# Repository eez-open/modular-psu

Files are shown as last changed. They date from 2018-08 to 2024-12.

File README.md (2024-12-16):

  

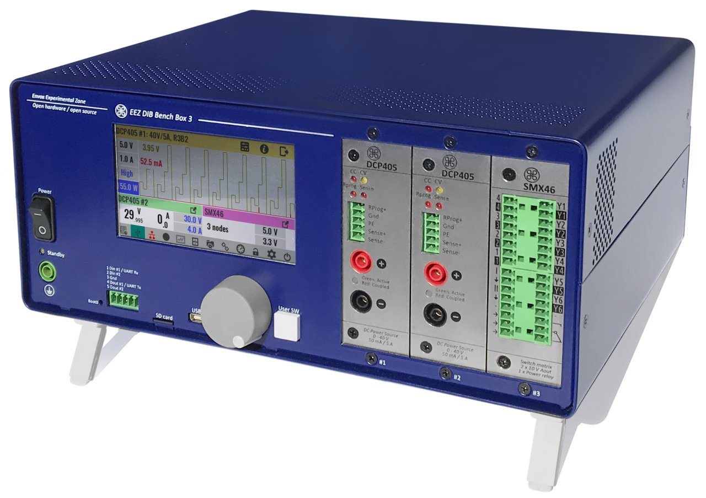
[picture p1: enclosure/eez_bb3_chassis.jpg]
Enclosure 3D model


### Ownership and License
The contributors are listed in CONTRIB.TXT. 

Licenses | OSHWA UID
--|--
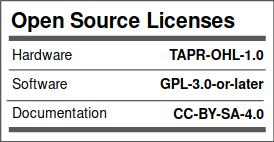
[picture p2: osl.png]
osl
 | OSHW-HR000002 (https://certification.oshwa.org/hr000002.html)

### Introduction

EEZ Bench Box 3 (BB3) represents a new category of *modular* Test and Measurement (T&M) equipment. It provides a complete open-source hardware and software framework that bridges the gap between – and combines the best features of – DIY hobbyist tools and professional benchtop equipment. 
BB3 was inspired by the [EEZ H24005](https://github.com/eez-open/psu-hw) power supply project ([OSHWA UID HR000001](https://certification.oshwa.org/hr000001.html)), which attracted many enthusiasts with its broad feature-set, rich user interface, DIY-friendliness, and fully open-source design. 
It initially comes with two DC power modules (hence the name of repository *modular-psu*) and will be expanded with new T&M modules (e.g. multi-channel power source, 2/4-quadrant power module, multi-channel temperature sensor module, data logger, switch matrix, digital I/O expander, function generator, data acquisition module, etc.). 
BB3 is made up of the following components:

* _[BP3C](https://github.com/eez-open/modular-psu/tree/master/bp3c)_ EEZ DIB backplane with power output coupling capability of first two modules
* _[AUX power supply](https://github.com/eez-open/modular-psu/tree/master/aux-ps)_ board with AC input protection, soft-start/power-up control, DC fan controller and +5 V / +12 V power outputs
* _[MCU](https://github.com/eez-open/modular-psu/tree/master/mcu)_ board based on STM32F769IIT6 32-bit ARM Cortex-M7
* _[DCP405](https://github.com/eez-open/modular-psu/tree/master/dcp405)_, 0 - 40 V / 50 mA / 5 A DC power source module
* _[DCM224](https://github.com/eez-open/dib-dcm224)_, dual sync buck 1 - 24 V / max. 4.9 A module (**retired**)
* _[Metal enclosure](https://github.com/eez-open/modular-psu/tree/master/enclosure)_ for housing up to 3 modules with 4.3" TFT LCD. Dimensions: 290 (W) x 123 (H) x 240 (D) mm

### Supported technologies

* _EEZ Flow_ (Visual programming tool for test and measurement automation)
* SCPI (Reference Guide in [PDF](https://github.com/eez-open/modular-psu-firmware/blob/master/docs/SCPI%20reference%20guide/EEZ%20BB3%20SCPI%20reference%20guide.pdf))
* MicroPython (script [examples](https://github.com/eez-open/modular-psu-firmware/tree/master/scripts), an example [video](https://www.youtube.com/watch?v=I0y6fgv8G00))
* MQTT (an intro [video](https://www.youtube.com/watch?v=THyfLSSAhrI))
* Node-RED integration (an intro [video](https://www.youtube.com/watch?v=0xQ6Xuq53fA))

### Other DIB modules

* [MIO168](https://github.com/eez-open/dib-mio168) Mixed I/O module
* [PREL6](https://github.com/eez-open/dib-prel6) power relays module
* [SMX46](https://github.com/eez-open/dib-smx46) programmable switch matrix module
* [MUX14D](https://github.com/eez-open/dib-mux14d) dual 7:1 reed relay 2-wire multiplexer

### Related topics and links

* EEZ BB3 [firmware](https://github.com/eez-open/modular-psu-firmware)
* [EEZ Studio](https://www.envox.eu/studio/studio-introduction)
* EEZ [DIB v1.2](https://github.com/eez-open/modular-psu/tree/master/DIB) specification
* EEZ DIB peripheral modules [KiCad 8.x project template](https://github.com/eez-open/dib-kicad-template)
* [Discord](https://discord.gg/dhYMnCB) server
* [X](https://x.com/envox) (ex Twitter)
* [YouTube](https://www.youtube.com/c/eezopen) channel
* [EEVblog forum](https://www.eevblog.com/forum/projects/eez-h25005-a-possible-successor-of-eez-h24005-programmable-power-supply/) discussion
* [Crowd Supply](https://www.crowdsupply.com/envox/eez-bb3) crowdfunding landing page
* [EMC certificate](https://www.envox.eu/?smd_process_download=1&download_id=2806), [LVD cerificate](https://www.envox.eu/?smd_process_download=1&download_id=2808)
* [Sigrok](https://sigrok.org/wiki/Envox_EEZ_Bench_Box_3)
* [Liberpay](https://liberapay.com/eez-open/donate) donations 

### Where to buy?

* [EEZ Web store](https://www.envox.eu/store) (out of stock)
* [Mouser](https://www.mouser.com/Search/Refine?Keyword=cs-bb3-) (kit only, excl. EU/UK)
* [Crowd supply](https://www.crowdsupply.com/envox/eez-bb3) (kit only, excl. EU/UK)
---
Please note that some previous board types and revisions that could be still usable in some cases can be found under *[previous design](https://github.com/eez-open/modular-psu/tree/master/previous%20designs)* folder.

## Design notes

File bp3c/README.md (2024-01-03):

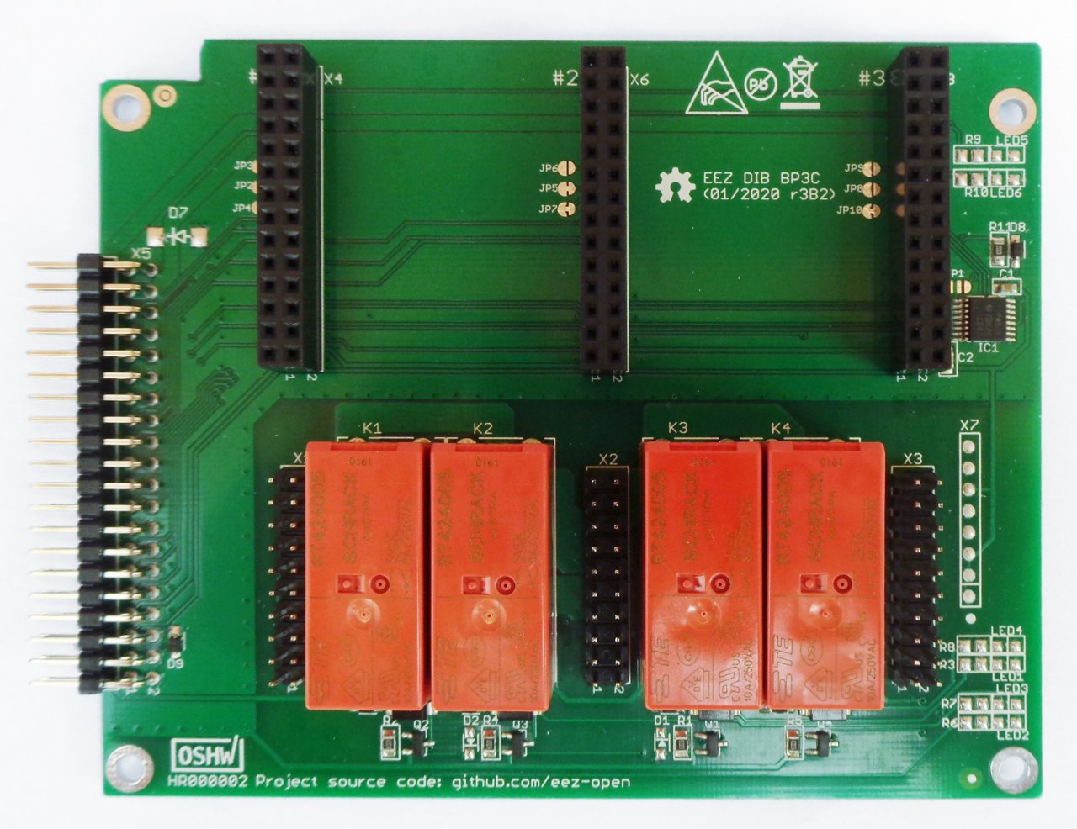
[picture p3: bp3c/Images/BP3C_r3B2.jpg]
module


EEZ DIB BP3C is backplane for connecting up to three EEZ DIB peripheral modules. When power modules (e.g. [DCP405](https://github.com/eez-open/modular-psu/tree/master/dcp405)) are plugged into slot #1 and #2, their outputs can be combined under firmware control in one of the following way:

- Serial coupling to double max. output voltage 
- Parallel coupling to double max. output current
- Ch#1 `Out-` and Ch#2 `Out+` coupling for split rail output

Additionaly, it is possible to couple `Out-` terminals of all installed power modules (common GND).

The BP3C backplane provides dedicated BOOT output for each peripheral module that comes with on-board MCU and which firmware could be uploaded via SPI or UART. Programmable reset output is also featured that firmware upload procedure can be initiated without power recycling.

Dimensions: 110 x 90 mm, 2-layer PCB

### KiCad project (v7 or newer)

* [BP3C r3B3](https://github.com/eez-open/modular-psu/tree/master/bp3c/EDA%20files/KiCad)

All symbols, footprints and 3D models used in the project can be found in the [EEZ-DIB Library](https://github.com/eez-open/eez-kicad-libraries) plugin for KiCad.

### Bill of materials

* [Download](https://github.com/eez-open/modular-psu/blob/master/bp3c/EDA%20files/KiCad/bom/ibom.html) as raw file _Interactive BOM_ (ibom.html) and open it locally in your browser.

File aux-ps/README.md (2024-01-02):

### Overview

_IMPORTANT: A crowdfunded version of the AUX-PS (r3B3) can be found [here](https://github.com/eez-open/modular-psu/tree/master/previous%20designs/aux-ps%20r3B3%20(Crowd%20Supply%20edition))._

AUX Power supply board for powering MCU board and backplane. It includes fan controller and AC power control with softstart (inrush current limiter) for power modules like DCP405 and DCM224.

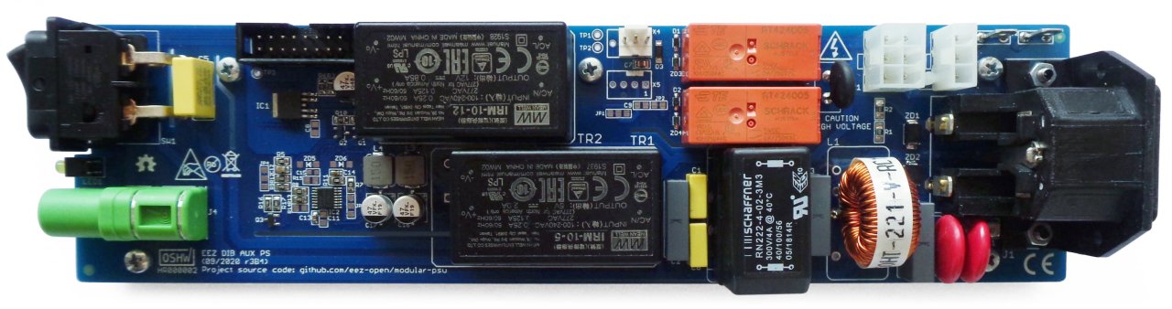
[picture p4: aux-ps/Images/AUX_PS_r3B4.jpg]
module


### Feature list

* On-board IEC C14 AC inlet with dual 20 x 5 mm fuses
* On-board AC power switch
* AC input protection (SAR, MOV)
* AC input filter for EMI compliance
* 3 x AC power outputs
* Soft-start/standby relay control
* +5 V, 10 W (optional 20 W)
* +12 V, 10 W
* I2C DC fan controller with temperature sensor and speed control
* Two 3-wire or 4-wire 12V DC fans (standard PC fan pinout)
* Standby LED indictor
* On-board PE 4 mm terminal
* AC mains frequency detection (optional)
* Dimensions: 230.5 x 60 mm, 2-layer PCB
* **CE certified design**

### KiCad project (v7 or newer)

* [AUX-PS r3B7](https://github.com/eez-open/modular-psu/tree/master/aux-ps/EDA%20files/KiCad)

All symbols, footprints and 3D models used in the project can be found in the [EEZ-DIB Library](https://github.com/eez-open/eez-kicad-libraries) plugin for KiCad.

### Bill of materials

* [Download](https://github.com/eez-open/modular-psu/blob/master/aux-ps/EDA%20files/KiCad/bom/ibom.html) as raw file _Interactive BOM_ (ibom.html) and open it locally in your browser.

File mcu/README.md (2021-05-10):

### Overview

_IMPORTANT: A crowdfunded version of the MCU module (r2B4) can be found [here](https://github.com/eez-open/modular-psu/tree/master/previous%20designs/mcu%20r2B4%20(Crowd%20Supply%20edition))._

STM32F7 MCU board for controlling up to 3 SPI peripheral modules, I2C fan controller, power soft-start/standby, TFT LCD with resistive touch controller, USB OTG, 10/100 Mbit/s Ethernet, SDRAM, EEPROM, rotary encoder, user switch, speaker and 2+2 digital I/O.

### r3B3 prototype

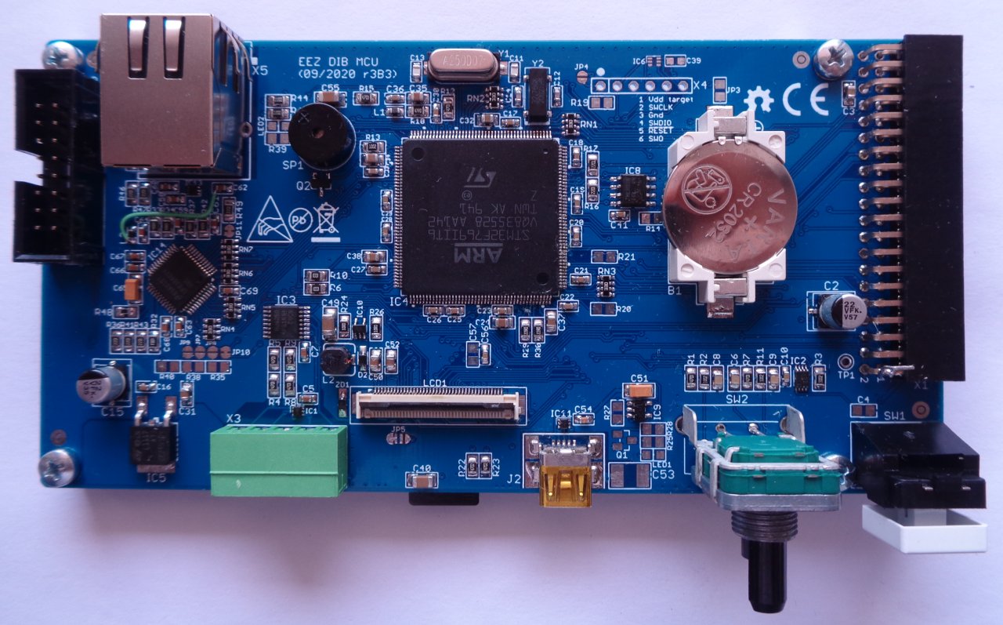
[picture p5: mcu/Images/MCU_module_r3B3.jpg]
module


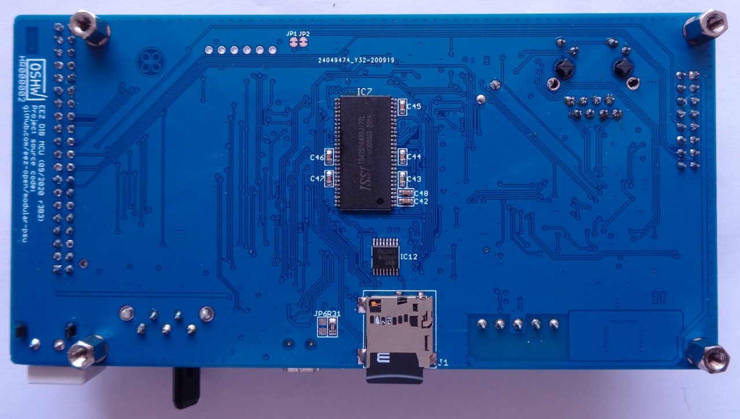
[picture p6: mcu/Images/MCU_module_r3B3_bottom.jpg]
module bottom


### Feature list

* [STM32F769IIT6](https://www.st.com/content/st_com/en/products/microcontrollers-microprocessors/stm32-32-bit-arm-cortex-mcus/stm32-high-performance-mcus/stm32f7-series/stm32f7x9/stm3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) 32-bit ARM Cortex®-M7 MCU, 216 MHz, 2 MiB Flash, 512 KiB SRAM,  LQFP176 package
* Digital I/O: 2 x buffered inputs and 2 x buffered outputs. Alternative functions: UART, 1 x PWM
* Rotary encoder with switch
* 1 x user switch (use as BOOT0 for firmware loader on power up)
* 3 x SPI channels (2 x Chip selects per channel), 40-pin IDC connector (DIB v1.0)
* Battery backup (CR2032 button cell type)
* AC frequency (50/60 Hz) RTC reference (optional)
* External supervisor with watchdog (optional)
* USB FS, OTG
* Micro SD card
* [DP83848C](https://www.ti.com/product/DP83848C) Ethernet PHY (10/100 Mbit/s)
* 32 KiB I2C EEPROM
* SWG/JTAG connector (optional)
* 8 MiB SDRAM (e.g. [IS42S16400J](https://www.tme.eu/en/details/is42s16400j-7tli/dram-memories-integrated-circuits/issi/)) upgradeable to 32 MiB
* 0.5 mm FFC 40-pin connector for 4.3" TFT LCD 480 x 272 px display
* TFT backlight brightness control
* Resistive touch controller (I2C)
* Soft-start/stand-by control lines for [AUX PS board](https://github.com/eez-open/modular-psu/tree/master/aux-ps)
* Small on-board speaker
* Input power: +5 V (+12 V pass-thru to peripheral modules)
* On board +3.3 V LDO
* Dimensions: 139.5 x 70 mm, 4-layer PCB
* **CE certified design**

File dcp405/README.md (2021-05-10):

### Overview

_IMPORTANT: A crowdfunded version of the DCP405 module (r2B11) can be found [here](https://github.com/eez-open/modular-psu/tree/master/previous%20designs/dcp405%20r2B11%20(Crowd%20Supply%20edition))._

The EEZ DIB DCP405 Power module is modified EEZ H24005 [Power board](https://github.com/eez-open/psu-hw/tree/master/Power%20board) that can be housed in EEZ DIB chasis (e.g. _Bench Box 3_). It comes with PNP "pass" element, OVP with triac crowbar, SPI temperature sensor and redesigned down-programmer new power pre-regulator and bias power supply.

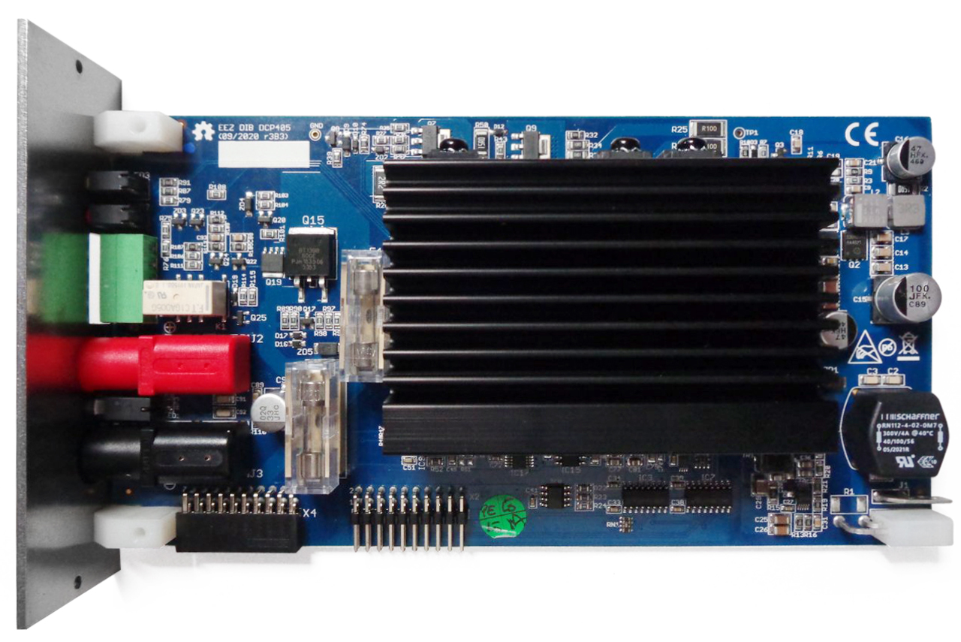
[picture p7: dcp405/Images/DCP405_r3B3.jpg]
module


### Feature list
- Power input: 48 Vdc (e.g. Mean Well LRS-150F-48 or EPP-150-48)
- Max. output power: 155 W (as limited with Mean Well AC/DC module capacity) 
- Voltage regulation (CV), 0 – 40 V. Voltage set resolution (_U_SET_): 16-bit, read resolution (_U_MON_): 15-bit
- Current regulation (CC) with 2-range (50 mA, 5 A). Current set resolution (_I_SET_): 16-bit, Current read resolution (_I_MON_): 15-bit for each range
- On-board low EMI switching power pre-regulator and bias power supply
- On-board OVP with full range dual crowbar (triac/MOSFET) and two fuses
- Down-programmer
- Output enable (OE) circuit with LED indicator combined with coupling indication
- On-board Ø4 mm safety sockets (19 mm/0.75” pitch) 
- Pass-thru connector for power output coupling with other power boards for e.g. doubling output voltage (up to 80 V) or current (up to 10 A)
- Remote voltage sense with LED indicator and inverse polarity protection
- Remote voltage programming with LED indicator (+2.5 V for full range)
- Galvanically isolated SPI bus for communication with [MCU board](https://github.com/eez-open/modular-psu/tree/master/mcu)
- I2C EEPROM for storing board specific configuration and calibration parameters
- SPI Temperature sensor
- Dimensions: 180 x 95 mm, 4-layer PCB
- **CE certified design**

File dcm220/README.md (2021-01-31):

### Overview
---
**RETIRED - Left as a reference for Crowd Supply [campaign](https://www.crowdsupply.com/envox/eez-bb3) backers. For the current version please visit the [DCM224](https://github.com/eez-open/dib-dcm224) repository.**
---
The EEZ DIB DCM220 Power module features dual sync buck converters based on [LT3763](https://www.analog.com/en/products/lt3763.html) with programmable output voltage and current limit.

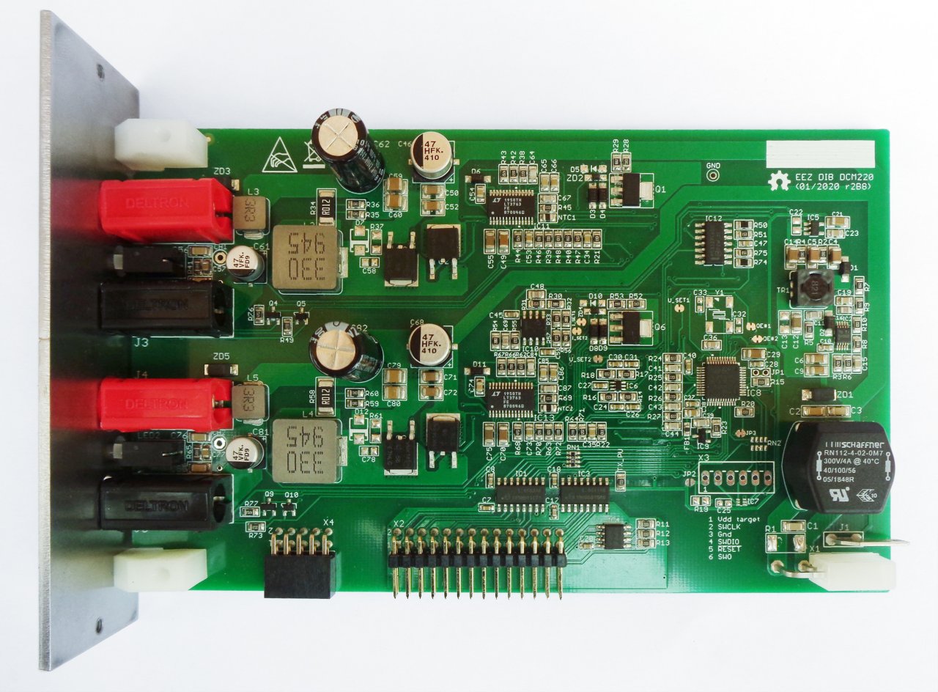
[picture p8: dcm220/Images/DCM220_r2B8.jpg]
module


### Feature list
- On-board STM32F373 MCU
Power input: 48 Vdc (e.g. Mean Well LRS-150F-48)
- Max. output power: up to 2 x 80 W
- Voltage regulation (CV), 1 – 20 V. Voltage set resolution (_U_SET_): 12-bit, read resolution (_U_MON_): 15-bit
- Current regulation (CC), 0.3 – 4 A. Current set resolution (_I_SET_): 12-bit, Current read resolution (_I_MON_): 15-bit
- On-board power pre-regulator and bias power supply
- Output Enable (_OE_) and Constant Current mode (_CC_) LED indications
- Output LC filter for improved ripple and noise
- On-board 4 mm power output terminals with standard (19.05 mm) pitch
- Pass-thru connector for Vout- coupling with other DIB power modules
- Galvanically isolated SPI bus for communication with [MCU board](https://github.com/eez-open/modular-psu/tree/master/mcu)
- I2C EEPROM for storing board specific configuration and calibration parameters
- Dimensions: 155 x 95 mm, 2-layer PCB

### Firmware repository

https://github.com/eez-open/dib-dcm220-fw
The firmware download procedure is described in the User Manual in [Chapter 13](https://github.com/eez-open/modular-psu/blob/master/docs/user%20manual/EEZ%20BB3%20user%20manual.pdf).

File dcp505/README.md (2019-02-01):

### Overview

The core of the EEZ DIB DCP505 Power board still represents adopted Leonid Ivanovitch design that is used in [EEZ H24005 Power board](https://github.com/eez-open/psu-hw/tree/master/Power%20board). The major improvements on this board include new form factor for housing in the EEZ DIB enclosure, 3-range autoranging circuit, OVP with triac and local EEPROM storage. 

### Feature list
- Power input: [EEZ CF-DIC]((https://github.com/eez-open/CF-DIC)_) power pre-regulator and bias power supply
- Power output: 250 W (max. 5 A)
- Voltage regulation (CV), 0 – 50 V. Voltage set (_U_SET_) resolution: 16-bit, read resolution (_U_MON_): 15-bit
- Current regulation (CC) with 3-range (50 mA, 500 mA, 5 A) **on-board auto-ranging circuit**. Current set resolution (_I_SET_): 16-bit, Current read resolution (_I_MON_): 15-bit for each range (i.e. 1.5 uA / 15 uA / 0.15 mA)
- **On-board OVP** with triac and two fuses
- Down-programmer
- Temperature sensor (SPI)
- Output enable (OE) circuit with LED indicator
- Fault/Powergood LED indicator
- On-board output terminals
- Pass-thru connector for serial and parallel coupling with other Power board
- Remote voltage sense with LED indicator and inverse polarity protection
- Remote voltage programming with LED indicator
- External digital trigger (3.3 or 5 V logic level)
- Galvanically isolated SPI bus for communication with [MCU board](https://github.com/eez-open/modular-psu/tree/master/mcu)
- I2C EEPROM for storing board specific configuration and calibration parameters
- Dimensions: 160 x 95 mm, 2-layer PCB

### Spice simulations

- [Current auto-ranging](https://github.com/eez-open/modular-psu/tree/master/dcp505/Spice/Auto-ranging) (LTspice)
- [OVP simulations](https://github.com/eez-open/modular-psu/tree/master/dcp505/Spice/OVP) (LTspice)

### r1B2 prototype (without OVP)

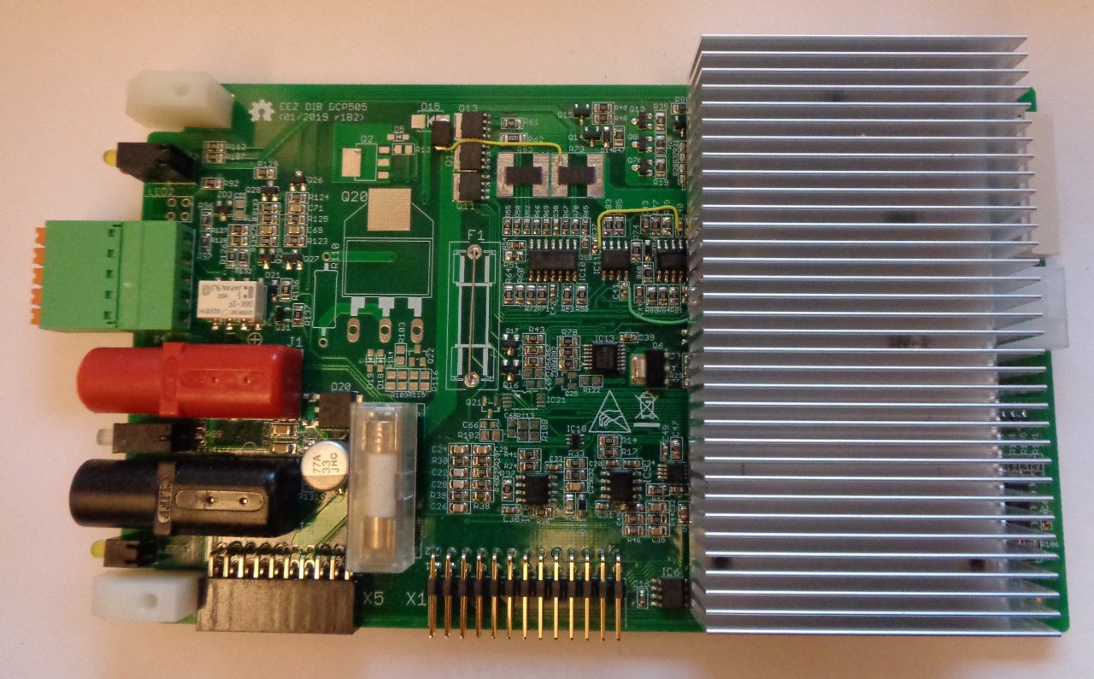
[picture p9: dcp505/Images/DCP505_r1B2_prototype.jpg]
Top side


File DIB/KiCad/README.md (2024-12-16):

Visit [https://github.com/eez-open/dib-kicad-template](https://github.com/eez-open/dib-kicad-template) for the KiCad 8.x EEZ DIB peripheral modules template.

### About KiCad

KiCad is a Cross-Platform free and Open Source Electronics Design Automation Suite. See [KiCad EDA](https://kicad.org/) for more information.

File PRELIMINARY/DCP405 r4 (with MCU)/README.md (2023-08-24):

### Preliminary design

A new version of the [EEZ DIB DCP405](https://www.envox.eu/dc-power-modules/dcp405-power-module/) power module that has its own MCU and improved external/remote programming (now for both CV and CC modes). This is a preliminary design that has been tested, but for which firmware needs to be developed. Once the design is complete, it will be moved to the [main](https://github.com/eez-open/modular-psu/tree/master/dcp405) folder of this module.

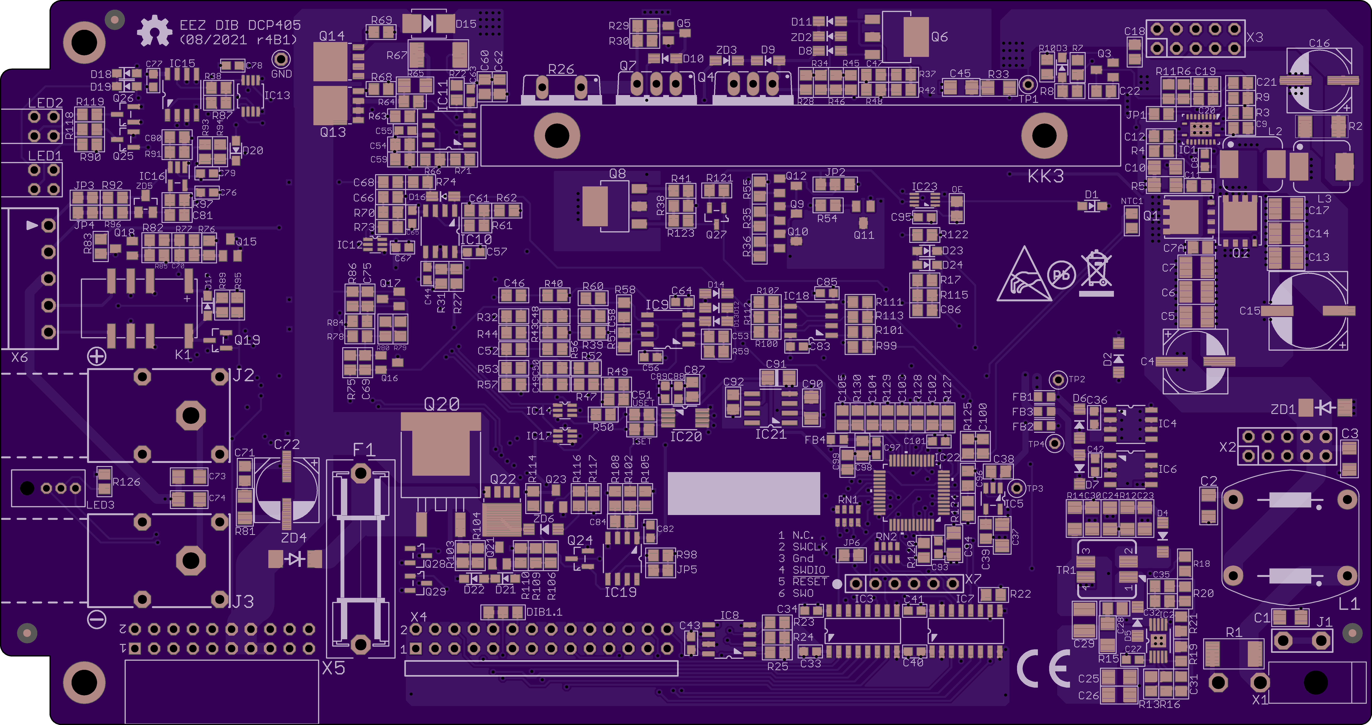
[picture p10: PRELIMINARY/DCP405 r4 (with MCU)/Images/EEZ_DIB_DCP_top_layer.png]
module


### TODO

* BOM list
* Firmware for on-board STM32F373
* Add support into the main (MCU module) firmware
* Front panel layout update (if necessary)

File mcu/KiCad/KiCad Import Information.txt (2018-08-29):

03:12:31: Unsupported Eagle layer 'Measures' (47), converted to Dwgs.User layer
03:12:31: Unsupported Eagle layer 'Measures' (47), converted to Dwgs.User layer
03:12:31: Unsupported Eagle layer 'Measures' (47), converted to Dwgs.User layer
03:12:31: Unsupported Eagle layer 'Measures' (47), converted to Dwgs.User layer
03:12:31: Unsupported Eagle layer 'Measures' (47), converted to Dwgs.User layer
03:12:31: Unsupported Eagle layer 'Measures' (47), converted to Dwgs.User layer
03:12:31: Unsupported Eagle layer 'Measures' (47), converted to Dwgs.User layer
03:12:31: Unsupported Eagle layer 'Measures' (47), converted to Dwgs.User layer
03:12:31: Unsupported Eagle layer 'Measures' (47), converted to Dwgs.User layer
03:12:31: Unsupported Eagle layer 'Measures' (47), converted to Dwgs.User layer
03:12:31: Unsupported Eagle layer 'Measures' (47), converted to Dwgs.User layer
03:12:31: Unsupported Eagle layer 'Measures' (47), converted to Dwgs.User layer
03:12:31: Unsupported Eagle layer 'Measures' (47), converted to Dwgs.User layer
03:12:31: Unsupported Eagle layer 'Measures' (47), converted to Dwgs.User layer
03:12:31: Unsupported Eagle layer 'Measures' (47), converted to Dwgs.User layer
03:12:31: Unsupported Eagle layer 'Measures' (47), converted to Dwgs.User layer
03:12:31: Unsupported Eagle layer 'Measures' (47), converted to Dwgs.User layer
03:12:31: Unsupported Eagle layer 'Measures' (47), converted to Dwgs.User layer
03:12:31: Unsupported Eagle layer 'Measures' (47), converted to Dwgs.User layer
03:12:31: Unsupported Eagle layer 'Measures' (47), converted to Dwgs.User layer
03:12:31: Unsupported Eagle layer 'Measures' (47), converted to Dwgs.User layer
03:12:31: Unsupported Eagle layer 'Measures' (47), converted to Dwgs.User layer
03:12:31: Unsupported Eagle layer 'Measures' (47), converted to Dwgs.User layer
03:12:31: Unsupported Eagle layer 'Measures' (47), converted to Dwgs.User layer
03:12:31: Unsupported Eagle layer 'Unrouted' (19), converted to Dwgs.User layer
03:12:31: Unsupported Eagle layer 'Unrouted' (19), converted to Dwgs.User layer
03:12:31: Unsupported circle on copper layer in package SIGNATURE_5MM.
Moving to Dwgs.User layer.
03:12:31: Line on copper layer in package SIGNATURE_5MM (-1.050000 mm, 0.200000 mm) (-0.250000 mm, 1.000000 mm).
Moving to Dwgs.User layer
03:12:31: Line on copper layer in package SIGNATURE_5MM (0.250000 mm, 1.000000 mm) (1.050000 mm, 0.200000 mm).
Moving to Dwgs.User layer
03:12:31: Line on copper layer in package SIGNATURE_5MM (1.050000 mm, -0.200000 mm) (0.250000 mm, -1.000000 mm).
Moving to Dwgs.User layer
03:12:31: Line on copper layer in package SIGNATURE_5MM (-0.250000 mm, -1.000000 mm) (-1.050000 mm, -0.200000 mm).
Moving to Dwgs.User layer
03:12:31: Line on copper layer in package SIGNATURE_5MM (-0.250000 mm, 1.000000 mm) (-0.250000 mm, -1.000000 mm).
Moving to Dwgs.User layer
03:12:31: Line on copper layer in package SIGNATURE_5MM (0.250000 mm, 1.000000 mm) (0.250000 mm, -1.000000 mm).
Moving to Dwgs.User layer
03:12:31: Line on copper layer in package SIGNATURE_5MM (-1.050000 mm, 0.200000 mm) (1.050000 mm, 0.200000 mm).
Moving to Dwgs.User layer
03:12:31: Line on copper layer in package SIGNATURE_5MM (-1.050000 mm, -0.200000 mm) (1.050000 mm, -0.200000 mm).
Moving to Dwgs.User layer
03:12:31: Unsupported Eagle layer 'tKeepout' (39), converted to Dwgs.User layer
03:12:31: Unsupported Eagle layer 'tKeepout' (39), converted to Dwgs.User layer
03:12:31: Unsupported Eagle layer 'tKeepout' (39), converted to Dwgs.User layer
03:12:31: Unsupported Eagle layer 'tKeepout' (39), converted to Dwgs.User layer
03:12:31: Unsupported Eagle layer 'tKeepout' (39), converted to Dwgs.User layer
03:12:31: Unsupported Eagle layer 'tKeepout' (39), converted to Dwgs.User layer
03:12:31: Unsupported Eagle layer 'tKeepout' (39), converted to Dwgs.User layer
03:12:31: Unsupported Eagle layer 'tKeepout' (39), converted to Dwgs.User layer
03:12:31: Unsupported Eagle layer 'tKeepout' (39), converted to Dwgs.User layer
03:12:31: Unsupported Eagle layer 'tKeepout' (39), converted to Dwgs.User layer
03:12:31: Unsupported Eagle layer 'tKeepout' (39), converted to Dwgs.User layer
03:12:31: Unsupported Eagle layer 'tKeepout' (39), converted to Dwgs.User layer
03:12:31: Unsupported Eagle layer 'tKeepout' (39), converted to Dwgs.User layer
03:12:31: Unsupported Eagle layer 'tKeepout' (39), converted to Dwgs.User layer
03:12:31: Unsupported polygon on copper layer in package JP3-CUT.
Moving to Dwgs.User layer.
03:12:31: Unsupported polygon on copper layer in package JP3-CUT.
Moving to Dwgs.User layer.
03:12:31: Unsupported polygon on copper layer in package JP2-NOCUT.
Moving to Dwgs.User layer.
03:12:31: Unsupported polygon on copper layer in package JP2-NOCUT.
Moving to Dwgs.User layer.
03:12:31: Unsupported polygon on copper layer in package JP2-CUT.
Moving to Dwgs.User layer.
03:12:31: Unsupported polygon on copper layer in package JP2-CUT.
Moving to Dwgs.User layer.
03:12:31: Unsupported Eagle layer 'tKeepout' (39), converted to Dwgs.User layer
03:12:31: Unsupported Eagle layer 'tKeepout' (39), converted to Dwgs.User layer
03:12:31: Unsupported Eagle layer 'tKeepout' (39), converted to Dwgs.User layer
03:12:31: Unsupported Eagle layer 'tKeepout' (39), converted to Dwgs.User layer
03:12:31: Unsupported Eagle layer 'tKeepout' (39), converted to Dwgs.User layer
03:12:31: Unsupported Eagle layer 'tKeepout' (39), converted to Dwgs.User layer
03:12:31: Unsupported Eagle layer 'tKeepout' (39), converted to Dwgs.User layer
03:12:31: Unsupported Eagle layer 'tKeepout' (39), converted to Dwgs.User layer
03:12:31: Unsupported Eagle layer 'tKeepout' (39), converted to Dwgs.User layer
03:12:31: Unsupported Eagle layer 'tKeepout' (39), converted to Dwgs.User layer
03:12:31: Unsupported Eagle layer 'tKeepout' (39), converted to Dwgs.User layer
03:12:31: Unsupported Eagle layer 'tKeepout' (39), converted to Dwgs.User layer
03:12:31: Unsupported Eagle layer 'tKeepout' (39), converted to Dwgs.User layer
03:12:31: Unsupported Eagle layer 'tKeepout' (39), converted to Dwgs.User layer
03:12:31: Unsupported Eagle layer 'tKeepout' (39), converted to Dwgs.User layer
03:12:31: Unsupported Eagle layer 'tKeepout' (39), converted to Dwgs.User layer
03:12:31: Unsupported Eagle layer 'tKeepout' (39), converted to Dwgs.User layer
03:12:31: Unsupported Eagle layer 'tKeepout' (39), converted to Dwgs.User layer
03:12:31: Unsupported Eagle layer 'tKeepout' (39), converted to Dwgs.User layer
03:12:31: Unsupported Eagle layer 'tKeepout' (39), converted to Dwgs.User layer
03:12:31: Unsupported Eagle layer 'tKeepout' (39), converted to Dwgs.User layer
03:12:31: Unsupported Eagle layer 'tKeepout' (39), converted to Dwgs.User layer
03:12:31: Unsupported Eagle layer 'tKeepout' (39), converted to Dwgs.User layer
03:12:31: Unsupported Eagle layer 'tKeepout' (39), converted to Dwgs.User layer
03:12:31: Unsupported Eagle layer 'tKeepout' (39), converted to Dwgs.User layer
03:12:31: Unsupported Eagle layer 'tKeepout' (39), converted to Dwgs.User layer
03:12:31: Unsupported Eagle layer 'tKeepout' (39), converted to Dwgs.User layer
03:12:31: Unsupported Eagle layer 'tKeepout' (39), converted to Dwgs.User layer

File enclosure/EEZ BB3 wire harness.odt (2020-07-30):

# EEZ BB3 wire harness

- Cooling fan cable
- MCU board power cable
- Dual AC/DC power module AC input
- Single AC/DC power module AC input
- Power module DC input
- Power module Protective Earth
- Ethernet patch cable

## Cooling fan cable

Total length | 300 (± 5) mm
Type | 3 wire, already mounted on the cooling fan
Fan: | TME: MF80251V3-1000U-G99 (https://www.tme.eu/hr/en/details/mf80251v3-g99-a/dc12v-fans/sunon/mf80251v3-1000u-g99/) Mouser: N/A

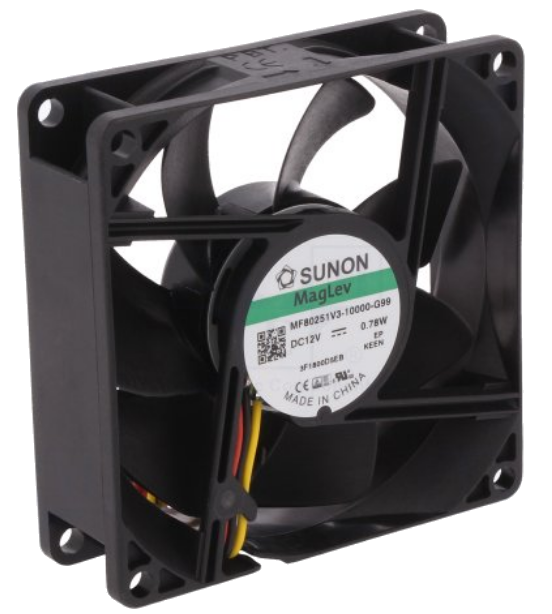
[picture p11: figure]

Connectors
Side A | X4, X5 | Side B | N/A
Housing type | Receptacle, 0.1” | Housing type | N/A
TME | MX-22-01-3037 (https://www.tme.eu/hr/en/details/mx-22-01-3037/raster-signal-connectors-2-54mm/molex/22-01-3037/) | TME | N/A
Mouser | 538-22-01-3037 (https://hr.mouser.com/ProductDetail/Molex/22-01-3037?qs=/ha2pyFadujVoN8fcIRqZmOPBvO4F4R9vpoQ8aL6w9c=) | Mouser | N/A

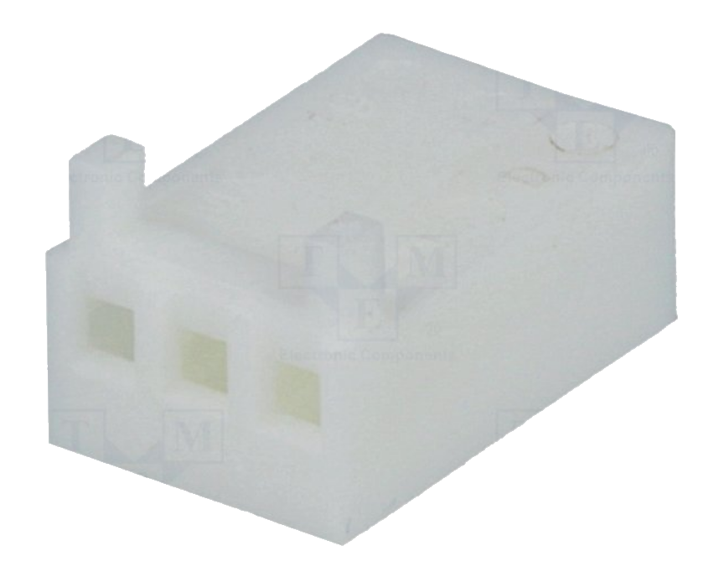
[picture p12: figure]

Pin | Female | Pin | N/A
Pin quantity | 3 | Pin quantity | 0
TME | MX-0850-0114 (http://www.tme.eu/en/details/mx-0850-0114/raster-signal-connectors-254mm/molex/008500114-08-50-0114-2759-p909l/) | TME | N/A
Mouser | 538-08-50-0114 (https://hr.mouser.com/ProductDetail/Molex/08-50-0114?qs=/ha2pyFadugl2J0uCqIVxCumaUM56ck7yQZdnWI8Pos=) | Mouser | N/A

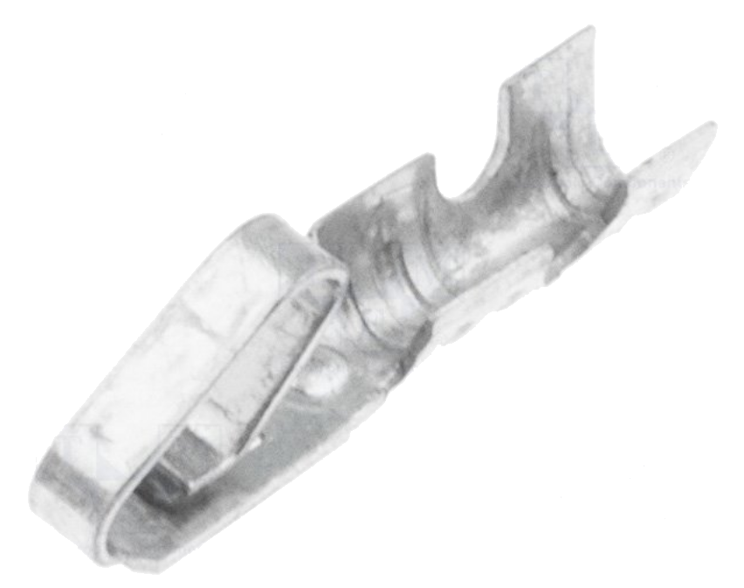
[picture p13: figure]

Additional info
Fan is already equipped with cable. Therefore it only has to be terminated with the connector.

Wiring

Name | Position | Color / description
GND | 1 | Black
+12 Vdc | 2 | Red
Sense | 3 | Yellow

Picture

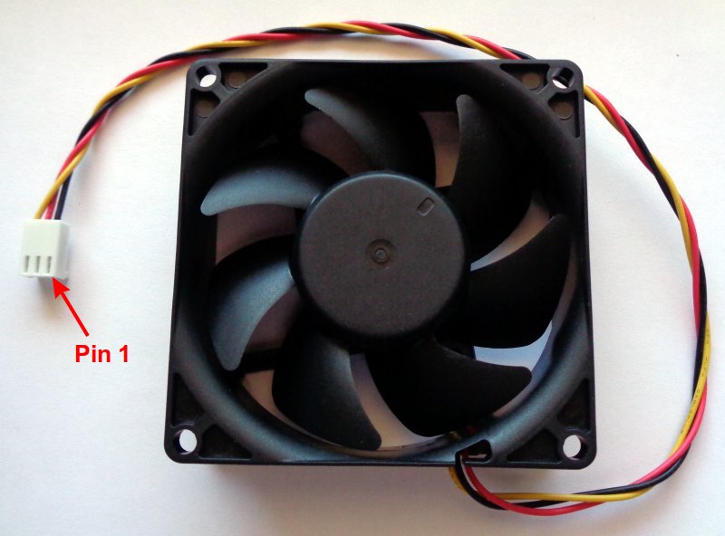
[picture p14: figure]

## (https://www.envox.hr/eez/images/wh_80mm_fan.jpg)MCU board power cable

Length | 75 or 150 mm assembled or 100 mm custom made
Type | Assembled ribbon cable with IDC connectors; 16x28AWG
TME | FC16150-S (https://www.tme.eu/hr/en/details/fc16150-s/ribbon-cables-with-idc-connectors/amphenol/)
Mouser | N/A
Custom made alternative
IDC female plug; 16 pin for ribbon cable | | TME | AWP-16 (https://www.tme.eu/hr/en/details/awp-16/idc-connectors/ninigi/)
Ribbon cable; 1.27mm; stranded; Cu; 16x28AWG; unshielded; PVC; grey | | TME | DS1057-16A282R-30.5 (https://www.tme.eu/hr/en/details/ds1057-16a282r/ribbon-cables-single-color/connfly/ds1057-16a282r-30-5/)
IDC connector crimping tool | | TME | HT-214 (https://www.tme.eu/hr/en/details/ht-214/crimping-tools-others/)

Picture

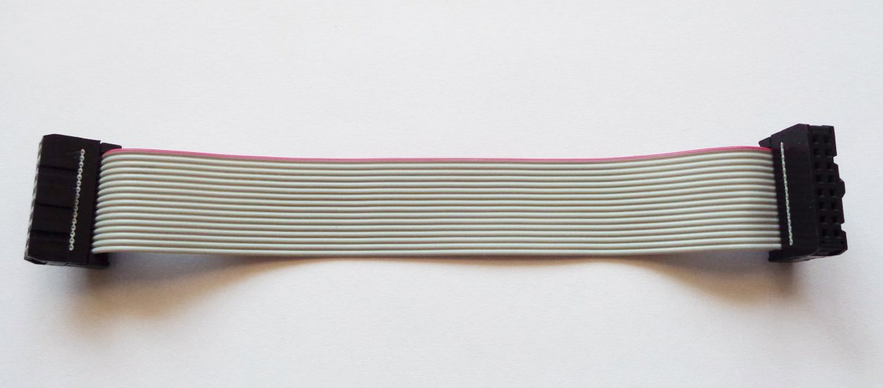
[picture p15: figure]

(https://www.envox.hr/eez/images/wh_16-pin_idc_cable.jpg)

Pinout

Name | Position | Description
PE | 1 | Protective Earth
Reserved | 2
+12 V | 3 | Regulated +12 V output
+12 V | 4 | Regulated +12 V output
+5 V | 5 | Regulated +5 V output
+5 V | 6 | Regulated +5 V output
Gnd | 7
Gnd | 8
Gnd | 9
Reserved | 10 | (+Vaux)
PWR_SSTART | 11 | Triac control (soft-start)
PWR_DIRECT | 12 | Triac control (continuous power)
SSCL | 13 | I2C clock
SSDA | 14 | I2C data
NFAULT | 15 | Fault
+3V3 | 16 | MCU board LDO output

## Dual AC/DC power module AC input

Length | 230 (± 5) mm + 250 (± 5) mm
Type | 0.75 mm² (18 AWG) single wire, stranded, min. 250 VAC
TME | Brown: H05VK075BR (https://www.tme.eu/hr/en/details/h05vk075br/single-core-cable-strand/helukabel/29100/), Blue: H05VK075BL (https://www.tme.eu/hr/en/details/h05vk075bl/single-core-cable-strand/helukabel/29099/), Green-Yellow: H05VK075GN/GE (https://www.tme.eu/hr/en/details/h05vk075gn_ge/single-core-cable-strand/helukabel/29098/)
Mouser | Brown: 602-3055-100-07 (https://hr.mouser.com/ProductDetail/Alpha-Wire/3055-BR005?qs=sGAEpiMZZMtW9UaYX5J1tBS%2BNDU2HbgacAbeBVe4gNs=), Blue: 602-3055-100-06 (https://hr.mouser.com/ProductDetail/Alpha-Wire/3055-BL005?qs=sGAEpiMZZMtW9UaYX5J1tM4kpfBO860LLDhrd7zLkZo=), Green-yellow: 602-3055-100-28 (https://hr.mouser.com/ProductDetail/Alpha-Wire/3055-GY005?qs=sGAEpiMZZMtW9UaYX5J1tM4kpfBO860LzuBrPZdk9B0=)
Connectors
Side A | AUX PS (X1) | Side B | AC/DC module power output
Housing type | Male, Mini-Fit Jr. | Housing type | Ferrule, single wire
TME | MX-39-01-2065 (https://www.tme.eu/hr/en/details/mx-39-01-2065/raster-signal-connectors-4-20mm/molex/39-01-2065/) | TME | H0.75/14D/GY (http://www.tme.eu/en/details/h0.75_14d_gy/bootlace-ferrules/weidmuller/9019040000-h07514d-gr/)
Mouser | 538-39-01-2065 (https://hr.mouser.com/ProductDetail/Molex/39-01-2065?qs=/ha2pyFaduj5y/QTDpr6iAdH6tpQVIZsh/cCCrtYWE0=) | Mouser | 845-FID1806GRM (https://hr.mouser.com/ProductDetail/Altech/FID1806GRM)

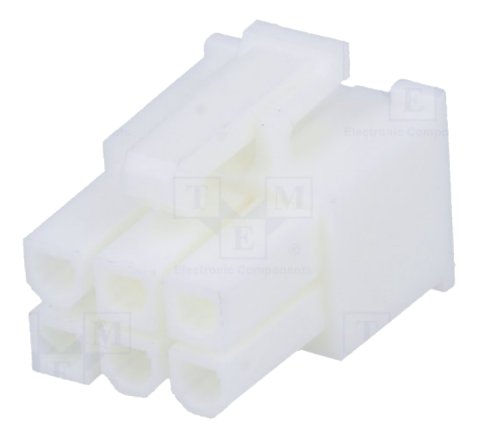
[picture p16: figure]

Pin | Female | Quantity | 6
Pin quantity | 6
TME | MX-5556-T3L (http://www.tme.eu/en/details/mx-5556-t3l/raster-signal-connectors-420mm/molex/039000078-39-00-0078-5556t3l/)
Mouser | 538-39-00-0078 (https://hr.mouser.com/ProductDetail/Molex/39-00-0078)

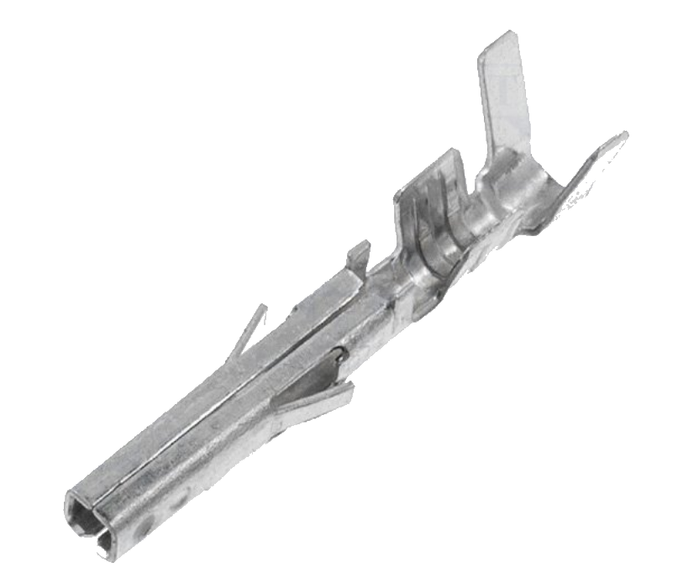
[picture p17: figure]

Picture

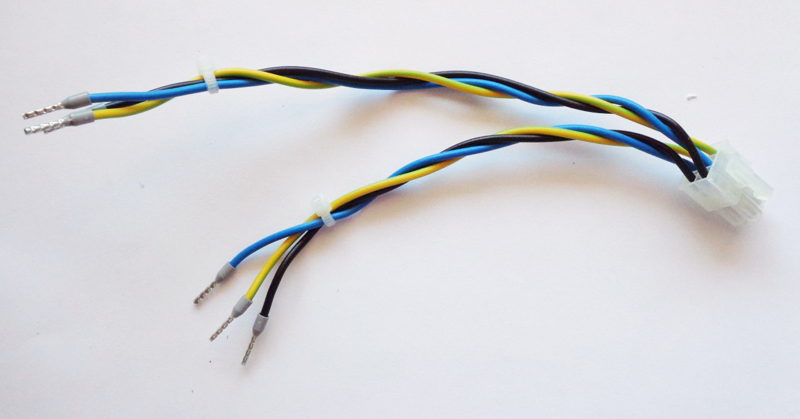
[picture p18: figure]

## (https://www.envox.hr/eez/images/wh_ac_input_dual.jpg)Single AC/DC power module AC input

Length | 250 (± 5) mm
Type | 0.75 mm² (18 AWG) single wire, stranded, min. 250 VAC
TME | Brown: H05VK075BR (https://www.tme.eu/hr/en/details/h05vk075br/single-core-cable-strand/helukabel/29100/), Blue: H05VK075BL (https://www.tme.eu/hr/en/details/h05vk075bl/single-core-cable-strand/helukabel/29099/), Green-Yellow: H05VK075GN/GE (https://www.tme.eu/hr/en/details/h05vk075gn_ge/single-core-cable-strand/helukabel/29098/)
Mouser | Brown: 602-3055-100-07 (https://hr.mouser.com/ProductDetail/Alpha-Wire/3055-BR005?qs=sGAEpiMZZMtW9UaYX5J1tBS%2BNDU2HbgacAbeBVe4gNs=), Blue: 602-3055-100-06 (https://hr.mouser.com/ProductDetail/Alpha-Wire/3055-BL005?qs=sGAEpiMZZMtW9UaYX5J1tM4kpfBO860LLDhrd7zLkZo=), Green-yellow: 602-3055-100-28 (https://hr.mouser.com/ProductDetail/Alpha-Wire/3055-GY005?qs=sGAEpiMZZMtW9UaYX5J1tM4kpfBO860LzuBrPZdk9B0=)
Connectors
Side A | AUX PS (X2) | Side B | AC/DC module power output
Housing type | Male, Mini-Fit Jr. | Housing type | Ferrule, single wire
TME | MX-5557-03R2 (http://www.tme.eu/en/details/mx-5557-03r2/raster-signal-connectors-420mm/molex/039014030-39-01-4030-5557-03r2/) | TME | H0.75/14D/GY (http://www.tme.eu/en/details/h0.75_14d_gy/bootlace-ferrules/weidmuller/9019040000-h07514d-gr/)
Mouser | 538-39-01-4030 (https://hr.mouser.com/ProductDetail/Molex/39-01-4030?qs=/ha2pyFaduioIz0aYpwyJdcWsu0165L4Gmhvd91sG7w=) | Mouser | 845-FID1806GRM (https://hr.mouser.com/ProductDetail/Altech/FID1806GRM)

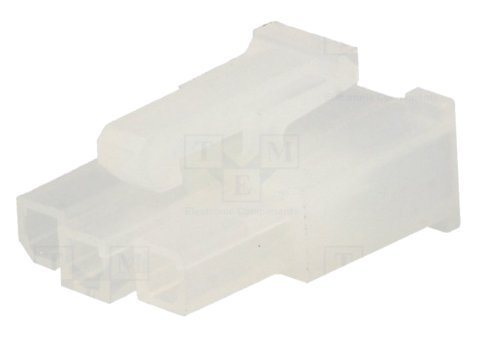
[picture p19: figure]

Pin | Female | Quantity | 3
Pin quantity | 3
TME | MX-5556-T3L (http://www.tme.eu/en/details/mx-5556-t3l/raster-signal-connectors-420mm/molex/039000078-39-00-0078-5556t3l/)
Mouser | 538-39-00-0078 (https://hr.mouser.com/ProductDetail/Molex/39-00-0078)

Picture

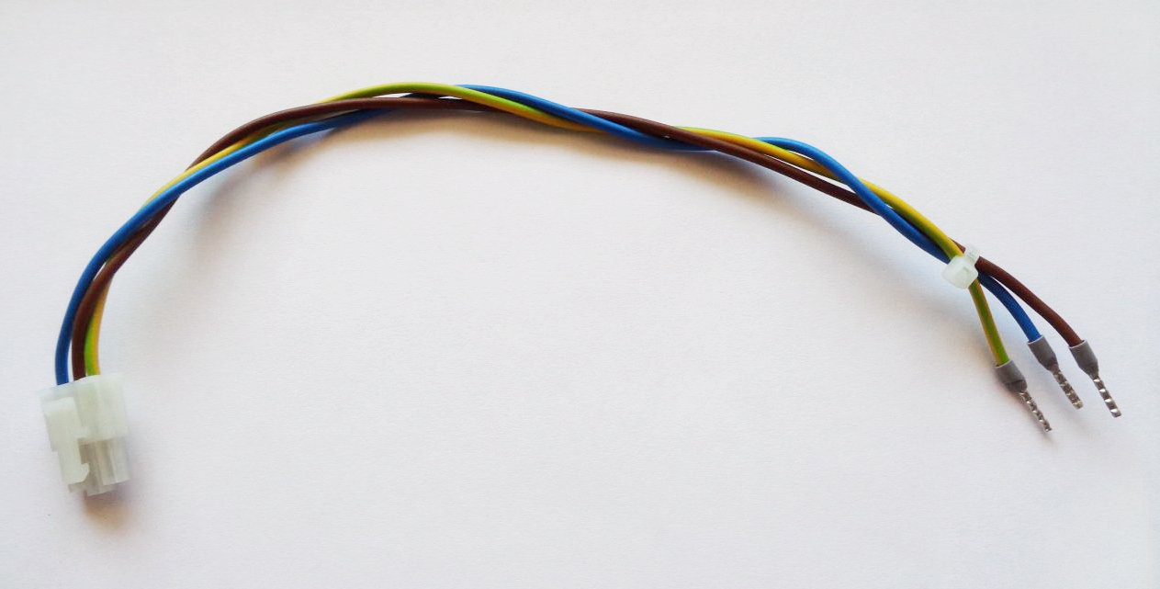
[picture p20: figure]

## (https://www.envox.hr/eez/images/wh_ac_input_single.jpg)Power module DC input

Length | 350 (± 5) mm
Type | 0.75 mm² (18 AWG) single wire, stranded, min. 250 VAC
TME | Red: H05VK075RT (https://www.tme.eu/hr/en/details/h05vk075rt/single-core-cable-strand/helukabel/29101/), Black: H05VK075SW (https://www.tme.eu/hr/en/details/h05vk075sw/single-core-cable-strand/helukabel/29097/)
Mouser | Red: 602-3055-100-03 (https://hr.mouser.com/ProductDetail/Alpha-Wire/3055-RD005?qs=sGAEpiMZZMtW9UaYX5J1tBS%2BNDU2Hbga6NcsU3D3rxE=) , Black: 602-3055-100-02 (https://hr.mouser.com/ProductDetail/Alpha-Wire/3055-BK005?qs=sGAEpiMZZMtW9UaYX5J1tM4kpfBO860LsFLdgiBBgik=)
Connectors
Side A | Power module (X1) | Side B | AC/DC module power output
Housing type | Male, Mini-Fit Jr. | Housing type | Ferrule, single wire
TME | MX-39-01-3022 (https://www.tme.eu/hr/en/details/mx-39-01-3022/raster-signal-connectors-4-20mm/molex/39-01-3022/) | TME | H0.75/14D/GY (http://www.tme.eu/en/details/h0.75_14d_gy/bootlace-ferrules/weidmuller/9019040000-h07514d-gr/)
Mouser | 538-39-01-3022 (https://hr.mouser.com/ProductDetail/Molex/39-01-3022) | Mouser | 845-FID1806GRM (https://hr.mouser.com/ProductDetail/Altech/FID1806GRM)

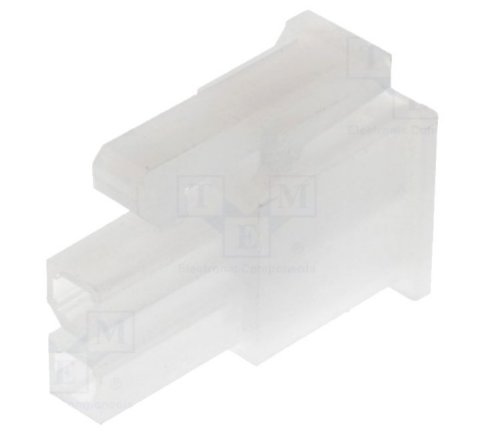
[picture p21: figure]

Pin | Female | Quantity | 2
Pin quantity | 2
TME | MX-5556-T3L (http://www.tme.eu/en/details/mx-5556-t3l/raster-signal-connectors-420mm/molex/039000078-39-00-0078-5556t3l/)
Mouser | 538-39-00-0078 (https://hr.mouser.com/ProductDetail/Molex/39-00-0078)

Picture

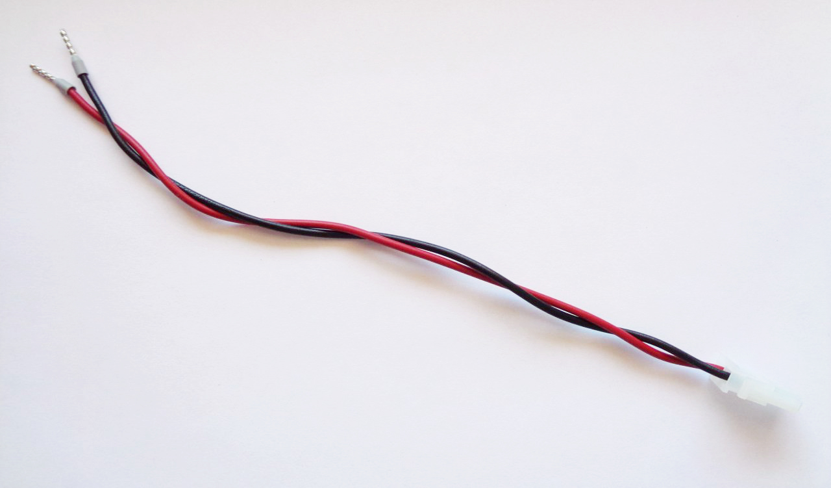
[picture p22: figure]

## (https://www.envox.hr/eez/images/wh_power_module_dc_input.jpg)Power module Protective Earth

Length: | Single: 300 (± 5) mm Dual: 230 + 270 (± 5) mm
Type: | 0.75 mm² (18 AWG) single wire, stranded, min. 250 VAC
TME | Green-Yellow: H05VK075GN/GE (https://www.tme.eu/hr/en/details/h05vk075gn_ge/single-core-cable-strand/helukabel/29098/)
Mouser | Green-yellow: 602-3055-100-28 (https://hr.mouser.com/ProductDetail/Alpha-Wire/3055-GY005?qs=sGAEpiMZZMtW9UaYX5J1tM4kpfBO860LzuBrPZdk9B0=)
Connectors
Side A | AUX-PS J2, J3 or J4 | Side B | Power module PE input (J1)
Housing type | Female quick disconnect | Housing type | Female quick disconnect
TME | ST-004/2 (https://www.tme.eu/hr/en/details/st-004_2/non-insulated-terminals/) or BM01148 (http://www.tme.eu/en/details/bm01148/non-insulated-terminals/bm-group/bm-01148/) | TME | ST-004/2 (https://www.tme.eu/hr/en/details/st-004_2/non-insulated-terminals/) or BM01148 (http://www.tme.eu/en/details/bm01148/non-insulated-terminals/bm-group/bm-01148/)
Mouser | 571-60196-3 (https://hr.mouser.com/ProductDetail/TE-Connectivity-AMP/60196-3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) | Mouser | 571-60196-3 (https://hr.mouser.com/ProductDetail/TE-Connectivity-AMP/60196-3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)

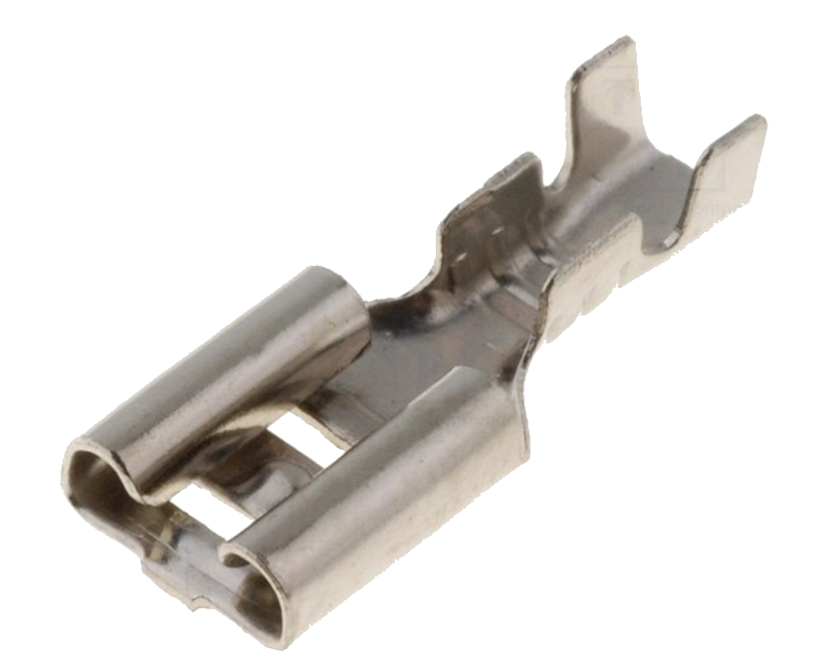
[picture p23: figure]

Picture

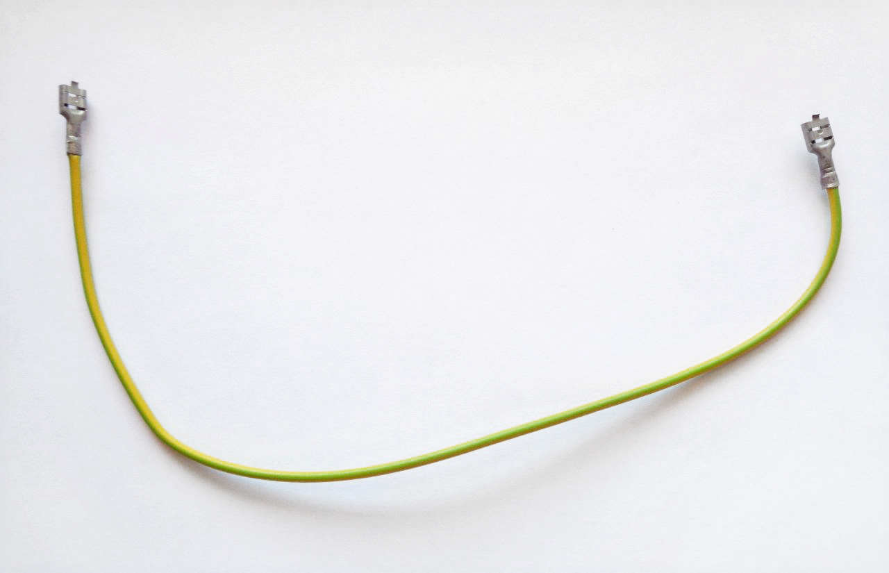
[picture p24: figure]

(https://www.envox.hr/eez/images/wh_power_module_pe.jpg)

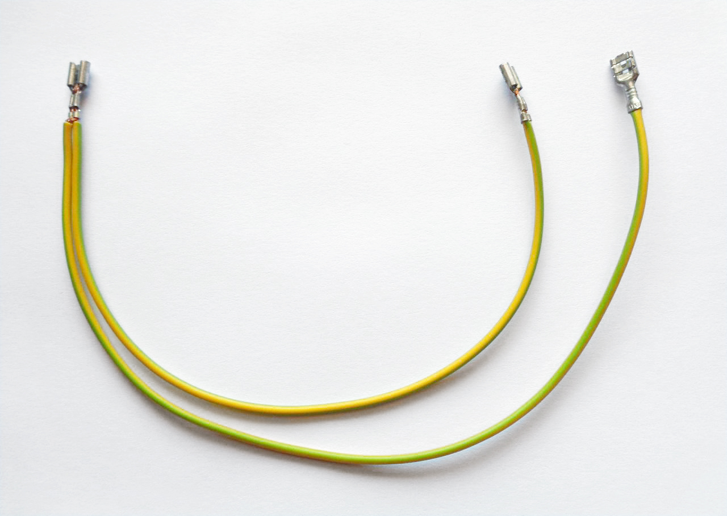
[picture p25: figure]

(https://www.envox.hr/eez/images/wh_power_module_dual_pe.jpg)

## Ethernet patch cable

Length | 300 mm
Type | RJ45 male to 90-degree female panel mount Ethernet extension cable
Alibaba | e.g. https://www.alibaba.com/product-detail/90-degree-right-angle-RJ45-Male_60817134790.html or search for 90 degree right angle RJ45 Male to 90-Degree Female Screw Panel Mount Ethernet LAN Network Extension Cable
TME | N/A
Mouser | N/A

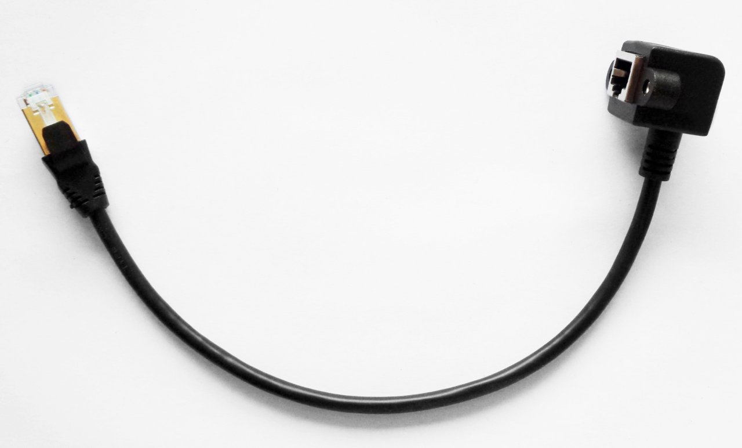
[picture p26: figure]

(https://www.envox.hr/eez/images/wh_ethernet_patch.jpg)

## BOM

The following BOM includes items for connecting three power modules.

Type | Part (Mouser) | Part (TME) | Total
3-pin 0.1” receptacle | 538-22-01-3037 (https://hr.mouser.com/ProductDetail/Molex/22-01-3037?qs=/ha2pyFadujVoN8fcIRqZmOPBvO4F4R9vpoQ8aL6w9c=) | MX-22-01-3037 (https://www.tme.eu/hr/en/details/mx-22-01-3037/raster-signal-connectors-2-54mm/molex/22-01-3037/) | 1


6-pin receptacle Mini-Fit Jr. | 538-39-01-2065 (https://hr.mouser.com/ProductDetail/Molex/39-01-2065?qs=/ha2pyFaduj5y/QTDpr6iAdH6tpQVIZsh/cCCrtYWE0=) | MX-39-01-2065 (https://www.tme.eu/hr/en/details/mx-39-01-2065/raster-signal-connectors-4-20mm/molex/39-01-2065/) | 1


3-pin receptacle Mini-Fit Jr. | 538-39-01-4030 (https://hr.mouser.com/ProductDetail/Molex/39-01-4030?qs=/ha2pyFaduioIz0aYpwyJdcWsu0165L4Gmhvd91sG7w=) | MX-5557-03R2 (http://www.tme.eu/en/details/mx-5557-03r2/raster-signal-connectors-420mm/molex/039014030-39-01-4030-5557-03r2/) | 1


2-pin receptacle Mini-Fit Jr. | 538-39-01-3022 (https://hr.mouser.com/ProductDetail/Molex/39-01-3022) | MX-39-01-3022 (https://www.tme.eu/hr/en/details/mx-39-01-3022/raster-signal-connectors-4-20mm/molex/39-01-3022/) | 3
0.1” pin | 538-08-50-0114 (https://hr.mouser.com/ProductDetail/Molex/08-50-0114?qs=/ha2pyFadugl2J0uCqIVxCumaUM56ck7yQZdnWI8Pos=) | MX-0850-0114 (http://www.tme.eu/en/details/mx-0850-0114/raster-signal-connectors-254mm/molex/008500114-08-50-0114-2759-p909l/) | 3
Mini-Fit Jr. pin | 538-39-00-0078 (https://hr.mouser.com/ProductDetail/Molex/39-00-0078) | MX-5556-T3L (http://www.tme.eu/en/details/mx-5556-t3l/raster-signal-connectors-420mm/molex/039000078-39-00-0078-5556t3l/) | 15
Female quick disconnect | 571-60196-3 (https://hr.mouser.com/ProductDetail/TE-Connectivity-AMP/60196-3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) | ST-004/2 (https://www.tme.eu/hr/en/details/st-004_2/non-insulated-terminals/) or BM01148 (http://www.tme.eu/en/details/bm01148/non-insulated-terminals/bm-group/bm-01148/) | 6
0.75 cm² ferrule | 845-FID1806GRM (https://hr.mouser.com/ProductDetail/Altech/FID1806GRM) | H0.75/14D/GY (http://www.tme.eu/en/details/h0.75_14d_gy/bootlace-ferrules/weidmuller/9019040000-h07514d-gr/) | 15
0.75 cm² cable (Brown) | 602-3055-100-07 (https://hr.mouser.com/ProductDetail/Alpha-Wire/3055-BR005?qs=sGAEpiMZZMtW9UaYX5J1tBS%2BNDU2HbgacAbeBVe4gNs=) | H05VK075BR (https://www.tme.eu/hr/en/details/h05vk075br/single-core-cable-strand/helukabel/29100/) | 0.73 m
0.75 cm² cable (Blue) | 602-3055-100-06 (https://hr.mouser.com/ProductDetail/Alpha-Wire/3055-BL005?qs=sGAEpiMZZMtW9UaYX5J1tM4kpfBO860LLDhrd7zLkZo=) | H05VK075BL (https://www.tme.eu/hr/en/details/h05vk075bl/single-core-cable-strand/helukabel/29099/) | 0.73 m
0.75 cm² cable (Red) | 602-3055-100-03 (https://hr.mouser.com/ProductDetail/Alpha-Wire/3055-RD005?qs=sGAEpiMZZMtW9UaYX5J1tBS%2BNDU2Hbga6NcsU3D3rxE=) | H05VK075RT (https://www.tme.eu/hr/en/details/h05vk075rt/single-core-cable-strand/helukabel/29101/) | 1.05 m
0.75 cm² cable (Black) | 602-3055-100-02 (https://hr.mouser.com/ProductDetail/Alpha-Wire/3055-BK005?qs=sGAEpiMZZMtW9UaYX5J1tM4kpfBO860LsFLdgiBBgik=) | H05VK075SW (https://www.tme.eu/hr/en/details/h05vk075sw/single-core-cable-strand/helukabel/29097/) | 1.05 m
0.75 cm² cable (Yellow-Green) | 602-3055-100-28 (https://hr.mouser.com/ProductDetail/Alpha-Wire/3055-GY005?qs=sGAEpiMZZMtW9UaYX5J1tM4kpfBO860LzuBrPZdk9B0=) | H05VK075GN/GE (https://www.tme.eu/hr/en/details/h05vk075gn_ge/single-core-cable-strand/helukabel/29098/) | 1.49 m
12 Vdc cooling fan | N/A | MF80251V3-1000U-G99 (https://www.tme.eu/hr/en/details/mf80251v3-g99-a/dc12v-fans/sunon/mf80251v3-1000u-g99/) | 1
IDC ribbon cable | N/A | FC16150-S (https://www.tme.eu/hr/en/details/fc16150-s/ribbon-cables-with-idc-connectors/amphenol/) | 0.15 m
Polyamide cable tie; L: 100 mm; W: 2.5 mm | N/A | BMB1025 (https://www.tme.eu/hr/en/details/bmb1025/cable-ties/bm-group/) | 6
Ethernet patch cable | N/A | N/A | 0.3 m

Revision: 1.1 1 (of 9) Last modified: 2020-07-30

DRAFT – EEZ BB3 wire harness

Last modified: 2020-07-30 8 (of 9) Doc. version: 1.1

Revision: 1.1 9 (of 9) Last modified: 2020-07-30

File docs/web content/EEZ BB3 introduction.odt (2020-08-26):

# Introduction


(https://www.envox.hr/eez/images/eez_bb3_enclosure_prototype.jpg)Fig. 1: BB3 prototype with various power modules


(https://certification.oshwa.org/hr000002.html)The EEZ Bench Box 3 (BB3) is the first product based on the EEZ DIB (https://www.envox.hr/eez/eez-dib/introduction.html) concept. Its aim is to provide a complete software and hardware framework for making a new category of modular test and measurement (T&M) equipment positioned between entry-level/hobbyist/DIY and professional solutions combining their best features. The EEZ DIB was inspired by EEZ H24005 (https://www.envox.hr/eez/bench-power-supply/psu-introduction.html) programmable power supply project that already attracted many enthusiasts with its feature set, rich user interface, DIY friendliness and fully open source software (https://github.com/eez-open/psu-firmware) and hardware (https://github.com/eez-open/psu-hw) design. Therefore, the first version of the EEZ BB3 is equipped with modules that provide EEZ H24005 functionalities in the first place and offer increased modularity, capacity and processing powers.

The EEZ BB3 continue the practice of design in a manner that it can be easily build by DIYers/makers with intermediate skills in soldering, assembling, testing and have basic understanding of software and firmware installations and uploading. Although it includes custom made enclosure, builder has a freedom to make his/her own enclosure or adopt some general purpose enclosure of similar dimensions.

Additionally, when custom enclosure is selected, one can choose to increase the number of peripheral modules by extending its backplane to some higher number.

Thanks to modular design, the EEZ BB3 based solution can be build gradually in accordance with ones needs and budget. Peripheral modules can have their own processing resources or can be controlled from master MCU that keeps costs low. The EEZ BB3 can be controlled locally (TFT touchscreen, encoder) or remotely (USB, Ethernet).

## Quick facts

- Fully open source (https://github.com/eez-open/modular-psu)
- Modular design
- Full range autoswitch AC input (115 / 230 Vac)
- Minimalist wire harness for simplified assembling and servicing
- Up to 3 peripheral modules
- STM32F7 ARM 32-bit MCU
- 4.3” TFT touchscreen display
- Front panel AC power switch
- Front panel bootloader switch for main MCU (firmware upload via USB DFU)
- Incremental encoder and user-defined switch
- USB FS and 10/100 Mbit/s Ethernet connectivity
- Four power relays for various power outputs coupling
- Dedicated full-duplex SPI for each module
- Dedicated bootloader control for each module (firmware upload via UART, SPI or I2C)
- Low noise Ø80 mm cooling fan with speed control
- Remotely controlled by 300+ SCPI commands using the EEZ Studio (https://www.envox.hr/eez/studio/studio-introduction.html) of similar SCPI controllers, Node-RED (https://nodered.org/), etc.
- MicroPython (https://micropython.org/) support
- MQTT (https://mqtt.org/) support
- Compact size: 290 (W) x 123 (H) x 240 (D) mm
- Weight (populated with 2 x DCP405 and 1 x DCM220): 4.05 kg

## Building blocks


(https://www.envox.hr/eez/images/eez_bb3_block_diagram.png)Fig. 2: EEZ BB3 block diagram

The EEZ BB3 chassis can accept different type of modules regardless of their functionalities (processing, auxiliary power, programmable power source, backplane, etc.). The number of modules is expecting to grow over time, and the initial version consists of the following modules:

- BP3C backplane (https://www.envox.hr/eez/eez-bench-box-3/eez-dib-bp3c-backplane.html)
- AUX Power supply (https://www.envox.hr/eez/eez-bench-box-3/eez-dib-aux-power-supply.html)
- STM32F7 MCU board (https://www.envox.hr/eez/eez-bench-box-3/eez-dib-stm32f7-mcu-board.html) with 4.3” TFT touchscreen display
- DCP405 (https://www.envox.hr/eez/eez-bench-box-3/eez-dib-dcp405-power-module.html) power module (requires +48 Vdc “off-the-shelf” AC/DC power module)
- DCM220 (https://www.envox.hr/eez/eez-bench-box-3/eez-dib-dcm220-dual-power-module.html) dual output power module (requires +48 Vdc “off-the-shelf” AC/DC power module)

Technical specification of EEZ BB3 that includes above mentioned modules and its comparison with the EEZ H24005 is presented here (https://www.envox.hr/eez/eez-bench-box-3/specification-and-comparison-with-the-eez-h24005.html).

Revision: 1 (of 3) Last modified:

DRAFT – EEZ BB3 introduction

Last modified: 2 (of 3) Doc. version:

Revision: 3 (of 3) Last modified:

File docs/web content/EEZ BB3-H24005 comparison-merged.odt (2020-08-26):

# EEZ BB3 specification and comparison with the EEZ H24005

# | Feature | EEZ BB3 | EEZ H24005

1 | Max. number of modules / power outputs (channels) | 3 / 6 | 2 / 2
2 | MCU module | STM32F7 MCU board (https://www.envox.hr/eez/eez-bench-box-3/eez-dib-stm32f7-mcu-board.html) | Arduino Shield r5B12 (https://www.envox.hr/eez/bench-power-supply/psu-digital-control.html)
3 | Power module | DCP405 power module (https://www.envox.hr/eez/eez-bench-box-3/eez-dib-dcp405-power-module.html) or DCM220 dual power module (https://www.envox.hr/eez/eez-bench-box-3/eez-dib-dcm220-dual-power-module.html) | Power board r5B12 (https://www.envox.hr/eez/bench-power-supply/power-board.html)
4 | Power module topology | Series hybrid (SMPS pre-regulator, linear post-regulator)
5 | Floating (isolated) power outputs | Yes
6 | Max. output power per channel | 155 W
7 | Output voltage | 0 to 40 V / 80 V (coupled in series)
8 | Output current | 0 to 5 A / 10 A (coupled in parallel)
9 | Current ranges | 50 mA / 5 A | 500 mA / 5 A
10 | Voltage programming resolution | 5 mV | | 10 mV
11 | Current programming resolution | 5 μA / 0.5 mA | 1 mA
12 | Voltage readback resolution | 5 mV | | 10 mV
13 | Current readback resolution | 5 μA / 0.5 mA | 1 mA
14 | Current ranges switching | Manual / SW auto-ranging
15 | Remote sensing / relay switchable | Yes / Yes
16 | Remote sensing reverse polarity protection | Yes
17 | Remote programming | Yes
18 | OVP (Over-voltage protection) | HW, fused / SW | SW
19 | OCP (Over-current protection) | SW
20 | OPP (Over-power protection) | SW
21 | OTP (Over-temperature protection) | SW
22 | Reverse power output protection | High power diode, fused | TVS, not fused
23 | No. of power relays for output couplings | 4 (first two modules outputs in series and parallel, split rail, and ground coupling of all modules) | 2 (Outputs in series and parallel)
24 | Coupled outputs programming and readback values adjustment (e.g. display up to 80 V instead of two 40 V separately) | Yes
25 | Load balancing when outputs are coupled in series or parallel | SW
26 | Soft-start/Power-up control | Yes
27 | Down-programmer | Yes
28 | Output capacitor | 33 uF + 470 nF | 22 uF + 18 uF + 470 nF
29 | Digital/Trigger inputs | 2 | 1
30 | Digital outputs | 2 | 1
31 | Relay outputs | No | 1
32 | MCU | STM32F769IIT6 | Arduino Due
31 | Flash memory | 2 MiB | 512 KiB
34 | System EEPROM | Yes
35 | Power module EEPROM | Yes | No
36 | TFT Display | 4.3” (480 x 272) | 3.2” (320 x 240)
37 | Touchscreen controller | Resistive
38 | Rotary encoder | Yes (Ø31 mm knob) | | Yes (Ø19 mm knob)
39 | User defined switch | Yes | No
40 | Power module communication | Dedicated SPI | Shared SPI
41 | Ethernet | 10/100 Mbit/s | 10/100 Mbit/s
42 | USB | FS (full-speed)
43 | USB isolation | No | Yes
44 | RTC with backup | Yes (replaceable coin battery) | Yes (1 F supercap)
45 | Memory card | MicroSD (accessible from front panel) | SD (installed on the TFT display back)
46 | Sound | Yes
47 | PE terminal | Yes
48 | Dedicated Fan controller | Yes, up to 2 fans | No
49 | Fan | Ø80 mm, 3- or 4-wire | Ø60 mm, 3-wire
50 | Open source firmware | Yes
51 | Multi-thread firmware | Yes | No
52 | SCPI support | Yes
53 | Scripting language | Micro Python | No
54 | Programmable output lists | Yes, low jitter | Yes
55 | Synchronized OE | Yes | No
56 | AC input range | Full range (115 / 230 V) | 115 / 230 V (manually switchable)
57 | AC input protection | TVS, MOV, SAR
58 | Dimensions | 290 (W) x 123 (H) x 240 (D) mm | 290 (W) x 84 (H) x 238 (D) mm
59 | Weight | 3.5 kg (with two DCP405 modules) | TBA

Revision: 1 (of 2) Last modified:

DRAFT – EEZ BB3-H24005 comparison-merged

Last modified: 2 (of 2) Doc. version:

Revision: (of 2) Last modified:

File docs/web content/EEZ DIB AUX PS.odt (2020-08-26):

# EEZ DIB AUX Power Supply

Current version | r3B3
Status | Completed, ready for production
PCB manufactured | Yes (r3B3)
PCB assembled | Yes (r3B3)
BOM | Yes (TME, Mouser, Digikey, Farnell, RS)
File repository | https://github.com/eez-open/modular-psu/tree/master/aux-ps (include Eagle, Gerber and BOM files)
License | TAPR v1.0 (http://www.tapr.org/TAPR_Open_Hardware_License_v1.0.txt)
Contributions | C4.1 (Collective Code Construction Contract) (https://rfc.zeromq.org/spec:22/C4/)


(https://www.envox.hr/eez/images/aux_ps_r3b3.jpg)Fig. 1: AUX power supply prototype r3B3

The AUX power supply is used for powering MCU board and peripheral modules inserted into DIB backplane. It consists of the following sections:

- AC IEC C14 (https://en.wikipedia.org/wiki/IEC_60320#C13/C14_coupler) inlet with two 20 x 5 mm fuse
- AC power switch
- AC power input protection (TVS, MOV, SAR)
- Standby LED indicator
- In-rush current (https://en.wikipedia.org/wiki/Inrush_current) limitation and standby circuit for AC/DC power modules,
- DC fan controller with I2C interface
- +5 V, +12 V AC/DC modules
- BOOT0 switch


(https://www.envox.hr/eez/images/aux_ps_r3b3_block.png)Fig. 2: AUX power module block diagram

## AC input and soft-start/standby

The AUX power module has on-board AC power input, AC switch and AC power distribution to reduce wiring and is the only part that is in direct connection with AC mains voltage.

WARNING: special caution is required when this module is operating.

The AC input line protection includes two bidirectional TVS (https://en.wikipedia.org/wiki/Transient-voltage-suppression_diode)es (ZD1, ZD2), two MOV (https://en.wikipedia.org/wiki/Varistor)s (MOV1, MOV2) and a SAR (https://en.wikipedia.org/wiki/Surge_arrester) (see Fig. 3). That improves immunity against various spikes and disturbances that can appear on AC mains input. They are specified for 230 VAC and could be modified for better sensitivity if the EEZ BB3 is connected to 115 VAC. The AC IEC inlet contains two replaceable fuses (for both N and L inputs) against overload that could be caused by activation of a line protection item in the first place. Fuse voltage and current ratings have to be selected in accordance with AC mains voltage and number of installed AC/DC power (Mean Well LRS-150F-48 (https://www.tme.eu/en/details/lrs-150f-48/built-in-power-supplies/mean-well/)) modules for powering peripheral DC power modules (e.g. DCP405, DCM220).


(https://www.envox.hr/eez/images/eez_dib_aux_ps_r3b3_sheet1of2.png)Fig. 3: AC input with soft-start/standby and fan controller

The in-rush current limiter provides soft-start of the AC mains power delivered to up to three AC/DC power modules. It consists of 20 Ω NTC1 that limits in-rush current below 11.5 A for 230 Vac or 5.75 A for 115 Vac when connected in series with load via triac (Q1) controlled from MCU (PWR_SSTART) by opto-triac (OK2). Shortly after the input current settles down, the NTC1 and Q1 are bypassed with another triac (Q2) controlled by PWR_DIRECT signal (via OK1). The load (AC/DC power modules) will stay connected until the EEZ BB3 enters standby mode (initiated by user or fault condition). Therefore, this circuit also provides power-on/standby functionality without need to use the AC mains switch (SW1) on the front panel. The LED1 indicates standby mode.

Note that Q1 and Q2 are controlled with two different type of opto-triac: the OK2 is of a Zero-crossing type and the OK1 is a nonzero-crossing (or random) device. That means that power-up and power-down sequence can only start when the mains voltage is minimal (zero); NTC1 bypassing can happen at any time after the programmed soft-start time passed.

Q1 and Q2 that come in insulated TOP-3 package are mounted on to shared heatsink (KK1) for improved cooling. AC power output has the RC snubber (https://en.wikipedia.org/wiki/Snubber#RC_snubbers) (C1, R7+R8). Connectors X1 (dual) and X2 (single) are used for connecting AC/DC power modules.

## DC fan speed control

The DC fan controller (IC2) is used to drive up to two Ø80 mm 12 V DC fans depending of the number of installed power source boards and accompanied AC/DC power modules. Selected MAX31760 (https://www.maximintegrated.com/en/products/sensors/MAX31760.html) is an I2C controller that features precise fan speed control based on the temperature reading as an index to a 48-byte lookup table (LUT) containing user-programmed PWM values. The flexible LUT-based architecture enables the user to program a smooth nonlinear fan speed vs. temperature transfer function to minimize acoustic fan noise. Two tachometer inputs allow measuring the speeds of two fans independently and is used to notify MCU about failure.

The PWM output requires pull-up (R16) and is further filtered (R18, C8) to provide analog signal that define output voltage of the LDO (IC1) that drives the DC fan or two. The voltage difference between input voltage (12 V) and set voltage has to be dissipated on the IC1, but for lower voltage (required for lower fan speed) selected fan draws little current. Therefore it can be efficiently cooled just with the PCB cooper plate as a heatsink.

Information about peripheral modules temperature that will be used to control fans MCU is collecting via I2C from module's temperature sensors and instruct IC2 about needed fan speed. Since its power consumption is low, it is powered from the MCU board.

## AC/DC power modules

Two “off-the-shelf” AC/DC PCB mounted power converters (TR1, TR2) are used to provide +5 V (10 or 20 W) or +12 V (10 W) for powering MCU module, and peripheral modules inserted into DIB backplane. Additional output filtering (L1, C12, and L2, C13) are added to reduce switching noise.


(https://www.envox.hr/eez/images/eez_dib_aux_ps_r3b3_sheet2of2.png)Fig. 4: AC/DC power converters, Standby and BOOT0

## PCB layout

The auxiliary power module is assembled on the 230.5 x 60 mm two-layer PCB. That board dimension is selected intentionally to be in line with EEZ BB3 chassis depth. Therefore, AC inlet can be directly fixed on the chassis rear panel. On the other side, AC switch, standby LED, and PE terminal (J4), can be exposed on the front panel to reduce required wiring.

There are a few places on the PCB that deserve special mention:

- proper spacing between the opto-triac’s low and high-voltage sections,
- adequate (and sufficiently adequate to be safe!) AC power traces width and spacing
- no trace routed on the top side in the KK1 heatsink area.


(https://www.envox.hr/eez/images/aux-ps_pcb_r3b3_top-bottom.png)Fig. 5: PCB Top (cyan) and bottom (blue) layer

Revision: 1 (of 4) Last modified:

DRAFT – EEZ DIB AUX PS

Last modified: 2 (of 4) Doc. version:

Revision: 3 (of 4) Last modified:

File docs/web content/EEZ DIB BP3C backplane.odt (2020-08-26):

# EEZ DIB BP3C backplane

Current version | r3B3
Status | Completed, ready for production
PCB manufactured | Yes (r3B2)
PCB assembled | Yes (r3B2)
BOM | Yes (TME, Mouser, Digikey, Farnell, RS)
File repository | https://github.com/eez-open/modular-psu/tree/master/bp3c (include Eagle, Gerber and BOM files)
License | TAPR v1.0 (http://www.tapr.org/TAPR_Open_Hardware_License_v1.0.txt)
Contributions | C4.1 (Collective Code Construction Contract) (https://rfc.zeromq.org/spec:22/C4/)


(https://www.envox.hr/eez/images/bp3c_r3b2.jpg)Fig. 1: DIB backplane BP3C r3B2

The BP3C backplane follows the DIB v1.0 specification (https://www.envox.hr/eez/eez-dib/dib-v1-0-specification.html) and accepts up to three DIB peripheral modules that could be of power sourcing types such as DCP405 power module (https://www.envox.hr/eez/eez-bench-box-3/eez-dib-dcp405-power-module.html) hence it also provides 20-pin power sourcing 0.1” pin headers. The MCU board 40-pin connector is located on side for mounting the MCU board horizontally in the same line with the backplane.


(https://www.envox.hr/eez/images/bp3c_r3b2_block.png)Fig. 2: BP3C backplane block diagram

## Power sourcing outputs coupling

Four different types of power sourcing module outputs is possible with this backplane thanks to four on-board power relays that are controlled with I2C 8-port I/O expander (IC1) as shown on Fig. 3. Coupling of power outputs under MCU control has the following benefits:

- External wiring and lousy and inadequate connections are avoided. Therefore additional voltage drop is not introduced and that lowers the chance of damaging the load by wrong wiring.
- Coupling is performed under controlled and safe conditions, i.e. when coupling is initiated, the affected channel outputs are disabled first and set output voltages and currents are reset to zero values.
- When coupling is affecting voltage or current ranges as in case of coupling in series or parallel, control of the coupled boards can be unified to decrease possibility for user mistakes due to output values misreading e.g. single value output voltage of +62.8 V will be displayed instead of two separated +31.4 V values, that one do not need to guess actual value. The same is valid for setting output value (voltage, current or power).
- Power boards which outputs are coupled in series or parallel are utilized equally, e.g. when current is set to 8 A, each channel will be set to 4 A. Likewise when output voltage is set to +70 V, each channel will be set to +35 V. Additionally, balancing algorithm deployed in firmware takes care about output voltage and current when operating mode is changed due to change in load. Check this (https://www.youtube.com/watch?v=Ukn1K1G0pJU) video for more information about coupled outputs balancing.


(https://www.envox.hr/eez/images/eez_dib_bp3c_r3b3_sheet1of2.png)Fig. 3: Power sourcing modules output coupling control

The power sourcing modules outputs can be coupled in one of the following way (see Fig. 4.):

- Coupling in series outputs of the first two channels to double voltage range. The active output become Ch#1. Ch#3 output remains unaffected
- Coupling outputs of the first two channels in parallel to double current range. The active output become Ch#1. Ch#3 output remains unaffected
- Common GND, when all channel Out- terminals are connected together
- Split rails when Ch#1 Out- and Ch#2 Out+ are connected. The Ch#1 Out+ become positive rail, and Ch#2 Out- negative rail.


(https://www.envox.hr/eez/images/bp3c_couplings.png)Fig. 4: Power output coupling types

The MCU 40-pin right angled 0.1” pin header and three peripheral module 28-pin 0.1” receptacles wiring is shown on Fig. 5. All three peripheral modules share the same I2C bus (SSDA, SSCL) and async UART, but have a dedicated SPI buses, together with two device select inputs (CSA, CSB) and interrupt outputs (IRQ).

Note that A0-A2 module identification pull-up inputs are assigned to addresses 1 (001), 2 (010) and 3 (011) respectively by selective grounding (for “zero” value).

NRESET, NFAULT and SYNC signaling are also shared among all peripheral module connectors. The same is true for power inputs: +5V, +12V, +3.3V (low-power, max. 20 mA) and +VAUX.


(https://www.envox.hr/eez/images/eez_dib_bp3c_r3b3_sheet2of2.png)Fig. 5: MCU and peripheral modules connections

## Bootloader control

Peripheral module could comes with on-board MCU. Therefore its firmware has to be uploaded from time to time with new releases and that require some sort of connection (i.e. JTAG, USB, UART) with a programmer. Other possibility is to use master MCU from the MCU board (https://www.envox.hr/eez/eez-bench-box-3/eez-dib-stm32f7-mcu-board.html) to perform firmware upload of the on-board (slave) MCU using one of the buses (UART, I2C or SPI) available on the backplane.

To initiate firmware upload slave MCU could require on startup to enter specific mode of operation when built-in bootloader will be activated and take care about firmware code writing into internal flash memory. The BP3C provides dedicated BOOT signal for each module that master MCU can select which module is going to be programmed. Additionally, since MCU's BOOT input has to be set on the power up or reset, an I/O expander output (PROG_RST) is “OR”-ed (D7, D8) with master reset (MRESET) that master MCU can reset peripheral modules after set BOOT output of the target module without need for input power recycling.

## PCB layout

The BP3C backplane is assembled on the 110 x 90 mm 2-layer PCB. Coupling relays are located between 20-pin power sourcing pin headers with proper distance that their height does not interfere with components on the power sourcing module such as DCP405 or DCM220. Although peripheral module connector's A0-A2 inputs are keyed on the PCB to provide addresses 1, 2 and 3 that default addressing could be changed by modifying PCB jumpers (JP2-JP10).


(https://www.envox.hr/eez/images/bp3c_pcb_r3b2_top-bottom.png)Fig. 6: PCB Top (cyan) and bottom (blue) layer

Revision: 1 (of 5) Last modified:

DRAFT – EEZ DIB BP3C backplane

Last modified: 2 (of 5) Doc. version:

Revision: 3 (of 5) Last modified:

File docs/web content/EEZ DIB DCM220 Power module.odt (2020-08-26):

# EEZ DIB DCM220 Dual output power module

Current version | r2B8
Status | Completed, ready for production
PCB manufactured | Yes (r2B8)
PCB assembled | Yes (r2B8)
BOM | Yes (TME, Mouser, Digikey, Farnell, RS)
File repository | https://github.com/eez-open/modular-psu/tree/master/dcm220 (include Eagle, Gerber and BOM files)
License | TAPR v1.0 (http://www.tapr.org/TAPR_Open_Hardware_License_v1.0.txt)
Contributions | C4.1 (Collective Code Construction Contract) (https://rfc.zeromq.org/spec:22/C4/)


(https://www.envox.hr/eez/images/dcm220_r2b8.jpg)Fig. 1: DCM220 r2B8

Output power terminals coupling capability (require BP3C backplane (https://www.envox.hr/eez/eez-bench-box-3/eez-dib-bp3c-backplane.html)) | Series | Parallel | Split rails | Common ground
| No | No | No | Yes

## Feature list

- Power input: 48 Vdc (e.g. Mean Well LRS-150F-48)
- Max. output power: 80 W per channel
- Voltage regulation (CV), 1 – 20 V. Voltage set resolution (U_SET): 12-bit, read resolution (U_MON): 15-bit
- Current regulation (CC), 0.3 – 4 A. Current set resolution (I_SET): 12-bit, Current read resolution (I_MON): 15-bit. Min. measured current: 100 mA
- Output enable (OE) with LED indicator
- CC mode LED indicator
- On-board power output terminals (Ø4 mm, 19 mm/0.75” pitch)
- 10-pin connector for Vout- coupling with other Power boards
- Galvanically isolated SPI bus for communication with the MCU board (https://www.envox.hr/eez/eez-bench-box-3/eez-dib-stm32f7-mcu-board.html)
- I2C EEPROM for storing board specific configuration and calibration parameters
- On-board STM32F373C8T6 (https://www.st.com/content/st_com/en/products/microcontrollers-microprocessors/stm32-32-bit-arm-cortex-mcus/stm32-mainstream-mcus/stm32f3-series/stm32f373/stm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) 32-bit ARM Cortex®-M4 MCU, 64 KiB Flash, 32 KiB SRAM, LQFP-48 package
- Upgradeable firmware via DIB v1.0 UART lines
- SWG/JTAG connector (optional)
- Two temperature sensors
- Dimensions: 155 x 95 mm, 2-layer PCB


(https://www.envox.hr/eez/images/dcm220_r2b3_block.png)Fig. 2: DCM220 power module block diagram

## Bias power supply

The bias power supply is built around low power buck step-down converter (IC2), and thanks to coupled inductor (TR1) it provides both positive and negative rails of about +8 V for analog section. Digital section is powered with +3.3 V that is derived from LDO (IC5).

The IC2 also provides POWERGOOD signal that indicates MCU what is module's power condition. It is related to UVLO (under-voltage lockout) functionality that is controlled with voltage divider consists of R3, R6. Therefore the step-down converter will cut-off power when input voltage drops below +26.5 V, and starts again when it rises above +27.5 V.

## EEZ DIB interface

The DCP220 module interface with the MCU module is accomplished over the 28-pin 0.1” right angled header (X2). Since its power output has to be isolated (“floated”) all digital control lines has to be isolated. Therefore two digital isolators (IC1, IC3) are used.

Onboard I2C EEPROM (IC4) provides storage for module-specific information such as its ID, calibration data, working hours counters, etc. Please note that it is on the “A-side” of the isolation barrier, because the same I2C bus is shared among all modules (that includes AUX PS module, too). It address is defined by R11, R12 and R13 pull-up resistors and ground connections on the backplane.

The MCU (IC9) on Fig. 6. is a SPI “slave” that communicates with the “master” MCU on the MCU module.

Power channel outputs can be synchronized with power outputs on the other modules thanks to OE_SYNC signal that is also controlled by “master” MCU.


(https://www.envox.hr/eez/images/eez_dcm220_r2b8_sheet1of4.png)Fig. 3: Bias power supply, DIB interface

## Digital control

The DCM220 comes with STM32F373C8T6 (IC8), a mainstream mixed signals MCUs ARM Cortex-M4 core with DSP and FPU with 64 KiB Flash, 72 MHz CPU and MPU. It's also featuring 12-bit DACs and 16-bit Sigma-delta ADCs (with inputs multiplexer). Its pin assignment and clock settings are shown in Fig. 4 and Fig. 5.


(https://www.envox.hr/eez/images/eez_dib_dcm220_mcu_r2b8.png)Fig. 4: MCU pin assignment (CubeMX) for r2B8 version


(https://www.envox.hr/eez/images/eez_dib_dcm220_r2b8_cubemx.png)Fig. 5: STM32F373C8T6 Clock settings

Controlling DCM220 power channels require two DAC channels (one for programming voltage and current) that gives four channels in total. Since selected MCU comes only with three DAC outputs, two are used for set output voltage (U_SET_OUT#1, U_SET_OUT#2) and remaining two required to set output currents are generated using MCU's PWM outputs.

16-bit ADCs are used for monitoring output voltage and current. Power output voltage value is derived with simple voltage dividers (R40, R47 on Fig. 7., and R64, R71 on Fig. 8.) that are set to provide +2.5 V for full scale. ADC voltage reference (+VREF) is provided by IC9.

Power output current value is measured by DC/DC controller (IC11, IC13) and available on its ISMON pin. Since its output range is from zero to only +1.5 V, a gain of x2 is selected in firmware on ADC's current inputs (I_MON#1, I_MON#2).

## Output voltage programming

The output voltage is programmed by affecting FB pin voltage that is set by voltage divider R39, R46 on channel 1 and R63, R70 on channel 2 (the DAC outputs are brought via R48 and R72). The output voltage on the channel 1 can be calculated taking into account the following equations:

| Vout = VFB + IR41 * R41 | (Eq. 1)
| IR41 = IR48 + IR50 | (Eq. 2)
| IR48 = VFB / R48 | (Eq. 3)
| IR50 = (VFB - VDAC) / R50 | (Eq. 4)

The VFB voltage for selected DC/DC controller is 1.2 V, while VDAC voltage range is from 0 to +2.5 V. Substituting Equations 2 through 4 into Equation 1 yields:

| VOUT = VFB * (1 + (R41 / R48)) + (VFB - VDAC) * (R41 / R50) | (Eq. 5)

From Equation 5, it can be seen that the maximum output voltage occurs for the minimum DAC voltage, and vice versa. We can calculate what is a max. output voltage by applying VDAC = 0 V:

| VOUT = 1.2 * (1 + (30 kΩ / 3.9 kΩ)) + (1.2 - 0) * (30 kΩ / 3.6 kΩ) = 20.43 V

## Output current programming

Conversion of PWM to analog signals for current programming is accomplished with DC filtering and additional ripple cancellation (IC6) as proposed by Stephen Woodward (see EDN article Cancel PWM DAC ripple with analog subtraction (https://www.edn.com/design/analog/4459116/Cancel-PWM-DAC-ripple-with-analog-subtraction), November 28, 2017).

The output current programming value comes to CTRL1 input of the DC/DC controller and it has to be in range from 0 to +1.5 V. Therefore an op-amp (IC10B, IC10A) is used to attenuate current programming signal by 0.45 since its range is from 0 to +3.3 V.


(https://www.envox.hr/eez/images/eez_dcm220_r2b8_sheet2of4.png)Fig. 6: Digital control and temperature sensors

Temperature is measured by two NTCs (NTC1, NTC2) that make voltage dividers with R21 and R22. NTC's are positioned near DC-DC controllers (IC11, IC13). Voltage dividers outputs vary with temperature and they are brought to ADC inputs TEMP#1 and TEMP#2.

The MCU firmware could be uploaded by set BOOT0 input to +3.3 V during the power-up or reset and use UART for communication with programmer (that could be “master” MCU on the MCU module). Additionally, for development purposes it is possible to solder X3 connector and used ST-LINK compatible in-circuit debugger/programmer.

If an STlink debugger is to be used, resistor array RN2 (22 – 47 Ω) will also need to be installed.

## Power channels

The DCM220 module comes with two identical power channels based on 60 V high current step-down synchronous LED driver controller (IC11, IC13) as shown on Fig. 7 and Fig. 8. They are sharing the same power input of +48 Vdc and consequently share the same ground.

The LT3763 comes current programming and monitoring that can be used for digital control and can work in CV (Constant Voltage) or CC (Constant Current) mode.

Unfortunately, it does not provides an indication of the mode of operation. Therefore the CC mode indication is accomplished on presumption that it currently does not works in CV mode and that is when voltage on the FB pin is below +1.4 V. Comparators (IC12B, IC12A) are used to check voltage level on the FB1 and FB2 pins that are buffered with IC12C, IC12D to minimize interference with the CV control loop.

Comparator's outputs are brought to MCU's digital inputs CC#1, CC#2 that can be used by firmware to indicate that on the TFT display or by activating red LEDs of bicolor LED1, LED2 (via Q5, Q10). Activation of that LEDs depend also of channel output state, and its disabled by when channel's output is disabled.

Power outputs state are directly controlled by MCU digital outputs OE#1, OE#2 brought to DC/DC controller's EV/ULVO input and that signals are used to drive green LEDs of bicolor LED1, LED2 (Q4, Q9).


(https://www.envox.hr/eez/images/eez_dcm220_r2b8_sheet3of4.png)Fig. 7: Sync buck for power channel #1

The DC/DC converter is equipped with internal regulator with Vin as a power input and provides +5 V on its output that is used for powering internal logic and to some extent external circuit if total consumption does not exceeds 60 mA. Measured internal consumption is about 22 mA that with voltage drop of 43 V requires that almost 1 W is dissipated. It comes in package with thermal pad, but that is not enough if huge underlying PCB cooling plane cannot be provided. That usually asks for at least 4-layer PCB that could increase production costs.

The usage of 4-layer PCB is avoided by adding simple voltage regulator (Q1, Q6) on the Vin pin. It is tracking power output voltage and insure difference of at least +7 V (defined by ZD2, ZD4 and Vgs(th) that is 1.8 V max. for the selected MOSFET) that is required for normal operation. Therefore the internal regulator will be supplied with about +7 to +27 V instead of continuous +48 V that reduces its dissipation significantly, or better to say, move it to the voltage regulator's MOSFET that comes in bigger package and can be cooled down much easier.

When DC/DC converter is disabled, voltage on the Vin rises to the power input value (+48 V). To avoid damage of the MOSFET (Q1, Q6) in that case, diodes D3, D4, and D8, D9 as protection are added.


(https://www.envox.hr/eez/images/eez_dcm220_r2b8_sheet4of4.png)Fig. 8: Sync buck for power channel #2

Power outputs are equipped with LC filters (L3, C61 and L5, C81) to reduce ripple and noise and protected against over-voltage and reverse polarity with TVS diodes ZD3, ZD5.

## PCB layout


(https://www.envox.hr/eez/images/dcm220_pcb_r2b8_top-bottom.png)Fig. 9: PCB Top (cyan) and bottom (blue) layer

Revision: 1 (of 9) Last modified:

DRAFT – EEZ DIB DCM220 Power module

Last modified: 6 (of 9) Doc. version:

Revision: 9 (of 9) Last modified:

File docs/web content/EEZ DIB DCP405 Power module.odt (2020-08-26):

# EEZ DIB DCP405 Power module

Current version | r2B11
Status | Completed, ready for production
PCB manufactured | Yes (r2B11)
PCB assembled | Yes (r2B11)
BOM | Yes (TME, Mouser, Digikey, Farnell, RS)
File repository | https://github.com/eez-open/modular-psu/tree/master/dcp405 (include Eagle, Gerber and BOM files)
License | TAPR v1.0 (http://www.tapr.org/TAPR_Open_Hardware_License_v1.0.txt)
Contributions | C4.1 (Collective Code Construction Contract) (https://rfc.zeromq.org/spec:22/C4/)


(https://www.envox.hr/eez/images/dcp405_r2b11.jpg)Fig. 1: DCP405 r2B11

Output power terminals coupling capability (require BP3C backplane (https://www.envox.hr/eez/eez-bench-box-3/eez-dib-bp3c-backplane.html)) | Series | Parallel | Split rails | Common ground
| Yes | Yes | Yes | Yes

The DCP405 power module is programmable DC source that can deliver up to 40 V and 5 A using the hybrid topology of switching pre-regulator and linear (series) post-regulator. It is upgraded version of the Power board (https://www.envox.hr/eez/bench-power-supply/power-board.html) used in the H24005 project. Couple with another module it is possible to provide up to 80 V (in series) or up to 10 A (in parallel). The coupling is accomplished under firmware control thanks to power relays located on the BP3C (https://www.envox.hr/eez/eez-bench-box-3/eez-dib-bp3c-backplane.html) backplane. Table above shows module's all coupling possibilities. When uncoupled its output is isolated (“floating”).

## Feature list

- Power input: 48 Vdc (e.g. Mean Well LRS-150F-48)
- Max. output power: 200 W (limited to 155 W due to Mean Well AC/DC module)
- Voltage regulation (CV), 0 – 40 V. Voltage set resolution (U_SET): 16-bit, read resolution (U_MON): 15-bit
- Current regulation (CC) with 2-range (50 mA, 5 A) software auto-ranging function. Current set resolution (I_SET): 16-bit, Current read resolution (I_MON): 15-bit for each range
- On-board power pre-regulator and bias power supply
- On-board OVP with triac crowbar and two fuses
- Down-programmer
- Output enable (OE) circuit with LED indicator combined with coupling indication
- On-board Ø4 mm safety sockets (19 mm/0.75” pitch)
- 20-pin pass-thru connector for output terminals coupling with other Power boards
- Remote voltage sense with LED indicator and inverse polarity protection
- Remote voltage programming with LED indicator
- Galvanically isolated SPI bus for communication with the MCU board (https://www.envox.hr/eez/eez-bench-box-3/eez-dib-stm32f7-mcu-board.html)
- I2C EEPROM for storing board specific configuration and calibration parameters
- I2C Temperature sensor
- Dimensions: 185 x 95 mm, 2-layer PCB


(https://www.envox.hr/eez/images/dcp405_r2b11_block.png)Fig. 2: DCP405 power module block diagram

## Power pre-regulator

The power pre-regulator section in essence is the same as one used in H24005 Power board (https://www.envox.hr/eez/bench-power-supply/power-board.html#power_preregulator), but with few details omitted such as synchronization of switching frequency with an external source, reduced ripple mode of operation when pre-regulator is bypassed, and optional AC power input, i.e. only +48 Vdc power input is accepted on 2-pin power connector (X1). The PE (protective earth) connection is provided separately (J1) and ZD1 guards against over-voltage and reverse voltage faults.


(https://www.envox.hr/eez/images/eez_dcp405_r2b11_sheet1of6.png)Fig. 3: Power pre-regulator

## Bias power supply

The bias power supply is built around low power buck step-down converter (IC2), and thanks to coupled inductor (TR1) it provides both positive and negative rails that are further regulated with simple linear regulators (IC5, IC6) to power all analog and digital logic with +/-5 V. For better separation between analog and digital power, +5 V is split with two ferrite beads (FB1, FB2) right on the IC5 output.

The IC2 also provides POWERGOOD signal that indicates MCU what is module's power condition. It is related to UVLO (under-voltage lockout) functionality that is controlled with voltage divider consists of R13, R16. Therefore the step-down converter will cut-off power when input voltage drops below +26.5 V, and starts again when it rises above +27.5 V.


(https://www.envox.hr/eez/images/eez_dcp405_r2b11_sheet2of6.png)Fig. 4: Bias power supply, DIB interface

## EEZ DIB interface

The DCP405 module interface with the MCU module is accomplished over the 28-pin (only 20-pin are used) 0.1” right angled header (X2). Since its power output has to be isolated (“floated”) all digital control lines has to be isolated. Therefore two high speed digital isolators (IC3, IC7) are used. Additionally, 2-to-4-line decoder (IC4) is also deployed because EEZ DIB v1.0 specification (https://www.envox.hr/eez/eez-dib/dib-v1-0-specification.html) offers only two SPI CS (Chip Select) lines while DCP405 comes with four SPI devices.

Onboard I2C EEPROM (IC8) provides storage for module-specific information such as its ID, calibration data, working hours counters, etc. Please note that it is on the A-side of the isolation barrier, because the same I2C bus is shared among all modules (that includes AUX PS module (https://www.envox.hr/eez/eez-bench-box-3/eez-dib-aux-power-supply.html), too).

## Power post-regulator

The post-regulator regulation (“pass”) element is PNP BJT, actually two of them (Q3, Q4) connected in parallel with current balancing power resistors (R25, R26). Their thermal coupling is also good since they are sharing the same heatsink and are mounted close to each other as shown on Fig. 5. The output voltage is controlled by two control loops: constant voltage (by IC9A, IC9B), and constant current (by using IC10A and IC11). In general, only one can be active at a time. Diodes D12 and D13 ensure that the output signal from one of the control loops does not affect the other loop.


(https://www.envox.hr/eez/images/eez_dcp405_heatskink_side.jpg)Fig. 5: Heatsink side view


(https://www.envox.hr/eez/images/eez_dcp405_r2b11_sheet3of6.png)Fig. 6: Post-regulator with down-programmer

The precision +2.5 V voltage reference (IC14, Fig. 7) is used for both control loops in supervising output voltage and current. Therefore, the gain in both control loops must be adjusted so the output range returns a positive value between zero and +2.5 V. That is done by selecting the feedback loop resistors for IC9B and IC11 which are connected as differential ampl (https://en.wikipedia.org/wiki/Differential_amplifier#Operational_amplifier_as_differential_amplifier)ifiers (https://en.wikipedia.org/wiki/Differential_amplifier#Operational_amplifier_as_differential_amplifier). For example, if we’d like to have the output voltage in the range from zero to 40 V, IC9B's gain must be 2.5 / 40 = 0.0625 (in effect, the output signal measurement must be attenuated by a factor of 16).

In practice, due to component tolerances, it is likely the highest values (e.g. 40 V) will not be reached, and a few tens of mV below maximum voltage will be the actual limit when the maximum DAC voltage is applied to the non-inverting input of IC9A.

The same problem can be expected on the other end of the voltage range; the minimum DAC voltage will not get the output voltage down to zero, but to only a few tens of mV above zero. This issue is more important, because it requires a negative DAC voltage – not possible with the DAC chip used (IC16, Fig. 7) without adding an additional operational amplifier. Fortunately such “shrinking of range” can be easily overridden with two simple changes:

- at the high end, we need to change the gain factor, and
- at the low end, move the reference ground potential from zero to, say, +50 mV (applied on IC9B and IC11 non-inverting inputs)

The voltage loop gain (for IC9B) is set to ~0.061 with a combination of 7.5 kΩ (for R41, R50) and 124 kΩ (for R45, R46). For the current loop (IC11), the gain is reduced from an “ideal” of 50 (i.e., 5 A across a 10 mΩ sense resistor gives 50 mV and 2.5 V / 0.05 V = 50) to 47.56 by using combination of 39 kΩ (R58, R64) and 820 Ω (R59, R68).

A new reference ground potential of about +50 mV is derived from a +2.5 V reference (IC14) by using the voltage divider R31, R37, and buffering it via IC10B. The offset on the lower programmed output value must be taken into account in firmware, however.

## Current sensing and ranges

The output current is measured by the voltage drop across a current sense resistor (R61 or R67) for two ranges: LOW (up to 50 mA) and HIGH (up to 5 A). It is important to take into account any heating of the high range current sense resistor, since it decreases accuracy because its resistance is temperature dependent. Choosing a resistor with a low TCR (https://en.wikipedia.org/wiki/Temperature_coefficient#Electrical_resistance) even while keeping dissipation low will be best. Using the 10 mΩ the dissipated power will be 250 mW. The resistor chosen for R67 has a TCR of 20 ppm/oC (declared for 20 to 60 oC).

Selecting the current range is done by switching between two current sense resistors using MOSFETs Q10 and Q11 with low Rds(on) that is important when high range is selected to reduce the heating which might affect measurement precision regardless of the current sense resistor temperature stability (TCR).

## Digital control

The post-regulator is an analog circuit controlled by analog control loops. Any control function done digitally (e.g., via MCU firmware) requires signal conversion. Four SPI devices are added to support this requirement (Fig. 7):

- Dual channel 16-bit Digital to Analog Converter,
- Four channel (multiplexed) 15-bit delta-sigma (https://en.wikipedia.org/wiki/Delta-sigma_modulation) (ΔΣ) Analog to Digital Converter,
- 16-bit I/O expander
- Temperature sensor

## Down-programmer

The down-programmer can be thought of as an internal load across the power supply's output terminals that helps bring the output voltage down quickly. The primary function of the down-programmer is to discharge the output capacitor (C91+C92) but in some cases this feature may be used as a load to the connected device.

It's sinking capability can be calculated using the following equation:

| Isink, max = (VZD2 – Vth[Q5]) / R29.

Therefore for the current setup, and if we use as average Q5's Vth of 3 V it is (9.1 - 3) / 2.2 = 2.78 A. This is a huge current, but it last in milliseconds. Nevertheless that has to be taken into account when repetitive output voltage programming sequence is required with short step duration (i.e. in tens of milliseconds) with step difference of 5 V or more to avoid overheating of Q5 that has to dissipate voltage difference between programmed steps. That is especially important if huge capacitive load (e.g 470 μF and more) is connected to the module power output.


(https://www.envox.hr/eez/images/eez_dcp405_r2b11_sheet4of6.png)Fig. 7: Digital control, temperature sensor, voltage reference and remote programming

## Digital to analog converter (DAC)

The DAC (IC16) is used to control the voltage and current for the power supply. Using a SPI bus, the MCU communicates with the DAC to program a new voltage at the DAC's outputs (U_SET and I_SET). This chip also includes a power-on reset circuit which ensures that the DAC outputs power up at zero, and remains there until an explicit command from the MCU firmware takes place.

The range of voltage the DAC can manage is determined by the voltage at its reference pin (Vref) which is connected to the precision voltage reference of +2.5 V (IC14).

## Analog to digital converter (ADC)

The ADC (IC18) is equipped with a four channel input multiplexer, and can manage up to 2 000 samples per second. It's used to measure voltage and current control loops levels (U_MON, I_MON), but also the DAC outputs (U_SET, I_SET). The ADC used is a 16-bit bipolar device which gives 15-bit resolution (positive half) of the full scale (the negative half is partially used; it monitors to some extent down-programmer sinking).

## 16-bit I/O expander

An SPI I/O expander (IC13) is used to collect various digital signal inputs and to enable/disable various functions as shown in table below.

# | Direction | I/O name | Active | Description

0 | Input | SENSE_ERR | Low | Reverse remote sense polarity detected
1 | Input | CC_ACTIVE | Low | CC (constant current) mode of operation is active
2 | Input | CV_ACTIVE | High | CV (constant voltage) mode of operation is active
3 | Input | PWRGOOD | High | Power good has been received (i.e. bias power is operational)
4 | Input | ADC_DRDY | Low | New A/D conversion data are ready
5 | Input | OVP_FAULT | High | HW OVP circuit is tripped
6 | Output | CURR_50MA | High | Set the low current range resistor
7 | Output | CURR_5A | High | Set the high current range resistor
8 | Output | SET_DP | High | Enable (or disable) the down-programmer circuit
9 | Output | OE | High | Enable or disable power output
10 | Output | RSENSE | High | Voltage remote sensing selection (internal / remote)
11 | Output | AUX_USET_SW | High | Voltage programming source selection (DAC / external)
12 | Output | OVP_EN | High | Enable HW OVP circuit
13 | – | – | – | Not used
14 | Output | OE_GREEN | High | Power output enabled (uncoupled)
15 | Output | OE_RED | High | Power output enabled (coupled)

## Temperature sensor

On-board temperature measurement is used for determining fan speed and for software based OTP (over-temperature protection) and it is achieved using the dedicated SPI temperature sensor (IC15) that is positioned close to heatsink, and for better temperature transfer, its ground pin is coupled with the heatsink. It provides temperature with ±2 °C (max.) accuracy from -40 °C to +85 °C.

## Remote programming

It is already stated that output voltage is regulated with CV control loop that is consists of IC9A and IC9B that is programmed using the DAC's U_SET output. Additionally, the DCP405 offers voltage programming by supplying a positive analog signal (+2.5 V for the full scale) on the push-in terminal input X3-1 (and X3-2 as return). Only one reference signal can be used at a time which is managed with an analog multiplexer/switch (IC17). The default setting is internal (i.e. DAC output). Analog programming is faster, but additional care must be taken to stay within the safe working range even though there is protective TVS diode ZD3.

## Mode of operation detection and indications

When its output is enabled, the DCP405 can work in one of the following operational modes:

- CV (constant voltage): the voltage control loop circuit (IC9) is setting the output voltage, and CV LED is active
- CC (constant current): the current control loop (IC10A, IC11) is setting output voltages, and thereby limiting output current, and CC LED is active,
- UR (unregulated, i.e. not regulated): neither the output voltage nor output current are controlling the DCP405's output, and both LEDs are active. In normal operation this mode is entered for a very short time while regulation is changed from CV to CC mode or vice versa. However, if DCP405 stuck in this mode that is indication that regulation is not possible, i.e. the output cannot be set to programmed voltage or current.

The CC and CV circuits use comparators (IC19A, IC19B) that compare control loop outputs (U_SERVO, I_SERVO) against LOOP_CTRL signal, or simply the voltage difference on diodes D12, D13 that separates CV and CC control outputs. The signals produced are level shifted for TTL inputs (using the R84, R88 and R98, R100 voltage dividers).


(https://www.envox.hr/eez/images/eez_dcp405_r2b11_sheet5of6.png)Fig. 8: CV/CC detection and indication, OVP with triac crowbar

## OVP crowbar

The OVP (over-voltage protection) circuit is added to act as a very fast protection in situations when output voltage erroneously rise above set value. It purpose is to protect DCP405 when e.g. battery or other power source is connected to the output terminals with voltage higher the programmed. It also protects connected load in case that something badly wrong is happened with the post-regulator that it voltage uncontrollably rises. The OVP circuit is consists of two main parts: fast comparator (IC20) and “crowbar” circuit where triac Q13 acts as crowbar driven by Q14. Voltage divider R83, R89 connected to the output voltage sets comparator threshold that is set to about 5 % above set voltage.

Note that in series with triac a high current resistor (R93) and PCB inductor (Fig. 10) are added to smooth possible current rising edge which can be in case of large capacitor discharge very high. For example, a capacitor of 10 000 μF charged to 50 V can provide up to 220 A when it is attenuated with 0.22 Ω and 1.1 μH as shown simulation on Fig. 9. Such current peak is still below ITSM (Non repetitive surge peak on-state current) value of the selected triac, therefore the OVP should survive such type of event.

A triac based OVP can cover voltages of approximately +1.5 V and above. For this reason, a parallel MOSFET based OVP (Q18) was added. However it is not suitable for a higher voltage so its upper activity limit is set with Q19 biased with voltage divider that includes ZD4 (about +5 V).


(https://www.envox.hr/eez/images/eez_dcp405_cap_discharge.jpg)Fig. 9: 10 000 μF capacitor discharge current simulation


(https://www.envox.hr/eez/images/eez_dcp405_pcb_inductor.jpg)Fig. 10: PCB inductor

## Voltage sensing

Output voltage can be “sensed” locally or remotely. In the first case the sense inputs is connected to the power output (OUTF+, POST_OUT-). In the second case, the connection is done via the load’s input terminals using a separate cable connected directly to the load's terminals. The firmware manages this through the signal relay (K1). The remote sensing cable can be shielded, but the cable shield must be connected to an PE terminal (X3-3) only on one end to avoid ground loop (https://en.wikipedia.org/wiki/Ground_loop_(electricity)) problems.


(https://www.envox.hr/eez/images/eez_dcp405_r2b11_sheet6of6.png)Fig. 11: Remote sensing reverse polarity protection, output terminals, remote sense relay

Remote voltage sensing is necessary to insure precise output voltage programming regardless of output current. It is essentially impossible to deliver power to a load with 1 mV precision without remotely sensing the voltage at the load's input terminal, perhaps at the end of a cable just half a meter away from the output terminals. Output currents of a few amperes through insufficiently robust connection cables, or to load terminals with a resistance in miliohms, could easily produce a voltage drop across the cable from a few milivolts to even a few hundred milivolts. When using remote sensing, the output voltage actually supplied to the load is not measured at the power outputs but at the connected load terminals. The CV control loop (IC9B, Fig. 6) can compare that voltage against the programmed one, and all the voltage drops along the cable will have no effect. The technique is generally referred to as “Kelvin sensing”, or 4-wire measurement technique.

## Remote sense reverse polarity detection and protection

Exposing the voltage sensing inputs to some external connection has disadvantages, however. The major one, not always obviously so, is that any or both of the sense cables can be mistakenly connected in a reverse polarity fashion that can ends up with unexpected results for the connected load. Internally, local sensing will be correct because the signal relay (K1) will insure the correct connection to the voltage control circuitry.

When remote inputs are disconnected from the load input power connectors, the DCP405 can still work safely because they will still be properly polarized thanks to R104, R105 and R110, R112. There will be only a small deviation in output voltage because of the addition of about 2 x 1 kΩ to the input voltage divider of IC9B.

However, if a sense wire is connected to the opposite polarity power output, there will be a serious fault condition for the input signal will have no relation to the channel attempting to ensure correct voltage and current to the load. There will be a maximum error bias within the CV control loop; it will try to compensate, and the end result will be the maximum possible voltage on the output (i.e. +40 V). This could easily result in irreparable damage to the connected load, especially if the set output current is high.

To avoid some of these unfortunate events, a reverse polarity detection circuit (Q20, Q22) has been added in parallel with the remote sensing inputs. It has two purposes: first, to immediately decrease output voltage, and to generate a SENSE_ERR signal (Q21) that will notify MCU to immediately disable output.

## Reverse polarity power output protection

Mistakenly connected load such as battery to the power terminals could results with damage of one or more sections. Therefore the TVS (ZD5) is connected to the outputs. Replaceable fuse (F2) connected in series limits stress applied on diode.

## PCB layout


(https://www.envox.hr/eez/images/dcp405_pcb_r2b11_top-bottom.png)Fig. 12: PCB Top (cyan) and bottom (blue) layer

Revision: 1 (of 12) Last modified:

DRAFT – EEZ DIB DCP405 Power module

Last modified: 12 (of 12) Doc. version:

Revision: 11 (of 12) Last modified:

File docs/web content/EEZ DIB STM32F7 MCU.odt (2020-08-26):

# EEZ DIB STM32F7 MCU module

Current version | r2B4
Status | Ready for production
PCB manufactured | Yes (r2B4)
PCB assembled | Yes (r2B4)
BOM | Yes (TME, Mouser, Digikey, Farnell, RS)
File repository | https://github.com/eez-open/modular-psu/tree/master/mcu (include Eagle, Gerber and BOM files)
License | TAPR v1.0 (http://www.tapr.org/TAPR_Open_Hardware_License_v1.0.txt)
Contributions | C4.1 (Collective Code Construction Contract) (https://rfc.zeromq.org/spec:22/C4/)


(https://www.envox.hr/eez/images/eez_dib_mcu_stm3f7_r2b4.jpg)Fig. 1: MCU module r2B4

The MCU board provides main processing powers that can be shared between peripheral modules inserted into DIB backplane. Its also in charge for connectivity with PC using USB FS and 10/100 Mbit/s Ethernet. Finally, it provides HMI that include 4.3” TFT LCD with resistive touchscreen, rotary encoder and an user switch with programmable function.

## Feature list

- STM32F769IIT6 (https://www.st.com/content/st_com/en/products/microcontrollers-microprocessors/stm32-32-bit-arm-cortex-mcus/stm32-high-performance-mcus/stm32f7-series/stm32f7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) 32-bit ARM Cortex®-M7 MCU, 216 MHz, 2 MiB Flash, 512 KiB SRAM, LQFP-176 package
- Digital I/O: 2 x buffered inputs and 2 x buffered outputs (alternative functions: UART, PWM out)
- Rotary encoder with switch
- 1 x user switch
- 3 x SPI channels (2 x Chip selects per channel), 40-pin IDC connector (DIB v1.0)
- Battery backup (CR2032 button cell type)
- USB FS OTG
- Micro SD card
- DP83848C (https://www.ti.com/product/DP83848C) Ethernet PHY (10/100 Mbit/s)
- 32 KiB I2C EEPROM
- SWG/JTAG connector (optional)
- 8 MiB SDRAM (e.g. IS42S16400J (https://www.tme.eu/en/details/is42s16400j-7tli/dram-memories-integrated-circuits/issi/))
- TFT LCD 0.5 mm FFC 40-pin connector (e.g. 4.3” RFE43BH-AIW-DNS (https://www.tme.eu/en/details/rfe43bh-aiw-dns/tft-displays/raystar-optronics/) or RFE430Y-AIW-DNS (https://www.tme.eu/en/details/rfe430y-aiw-dns/tft-displays/raystar-optronics/))
- TFT backlight brightness control
- Resistive touch controller
- Soft-start/stand-by control lines for AUX power supply (https://www.envox.hr/eez/eez-bench-box-3/eez-dib-aux-power-supply.html)
- Small on-board speaker
- Input power: +5 V (+12 V pass-thru to peripheral modules)
- On board +3.3 V LDO
- Bootloader input (BOOT0) and jumper (optional)
- Dimensions: 139 x 70 mm, 4-layer PCB


(https://www.envox.hr/eez/images/mcu_r2b4_block.png)Fig. 2: MCU module block diagram

Selected STM32F769IIT6 is a high performance 32-bit RISC core MCU operating at up to 216 MHz frequency. The Cortex®-M7 core features a floating point unit (FPU) which supports Arm® double-precision and single-precision data-processing instructions and data types. It also implements a full set of DSP instructions and a memory protection unit (MPU) which enhances the application security. It comes in various size and packages, and LQFP176 package is chosen since it offers enough pins for above listed features and it can be soldered manually on the PCB.


(https://www.envox.hr/eez/images/eez_dib_mcu_stm3f7_r2b4.png)Fig. 3: MCU pin assignment (CubeMX) for r2B4 version

The pin assignment is shown on Fig. 3. generated with CubeMX (https://www.st.com/en/development-tools/stm32cubemx.html) tool. The latest revision can be found on the GitHub (https://github.com/eez-open/modular-psu/tree/master/mcu/CubeMX). As it is visible from pin assignment, the MCU directly provides the most of the functionalities mentioned above. The MCU (IC3) wiring is shown on Fig. 4. and only four pins (PI8, PA10, PC10, PD6) and bus for a DSI (https://en.wikipedia.org/wiki/Display_Serial_Interface) type of display left unassigned.


(https://www.envox.hr/eez/images/eez_dib_mcu_r2b4_sheet2of5.png)Fig. 4: STM32F769IIT6 MCU

On-board LDO (IC4) is deployed to step-down from +5 V to its working voltage of +3.3 V. A bank of decoupling capacitors (C16-C21 and C26-C31) are located as close as possible to VDD input pins. The main clock (HSE) frequency is set with 25 MHz XTAL (Y1). Another 32.768 KHz XTAL (Y2) is required for internal RTC (real time clock) so it can remain functional when power is switched off and backup power (coin batter in B1 holder) is used. The MCU clock settings is shown on Fig. 5. Relatively high main clock frequency of 25 MHz is intentionally selected to drive directly Ethernet PHY (IC14 on Fig. 9.) using the MCLK_25 output (PC9 pin). Frequency prescalers are set to provide max. allowed MCU frequency of 216 MHz.


(https://www.envox.hr/eez/images/eez_dib_stm32f7_r2b4_cubemx.png)Fig. 5: STM32F769IIT6 Clock settings

## Connectors, Digital I/O rotary encoder and user switch

The MCU board uses two connectors (see Fig. 6.) in accordance with DIB v1.0 (https://www.envox.hr/eez/eez-dib/dib-v1-0-specification.html) specification: 40-bit angled 0.1” receptacle (X1) is intended for direct connection with the BP3C backplane (https://www.envox.hr/eez/eez-bench-box-3/eez-dib-bp3c-backplane.html), while 16-pin angled IDC (X2) is used for flat cable connection with AUX power supply (https://www.envox.hr/eez/eez-bench-box-3/eez-dib-aux-power-supply.html).

Two protected digital inputs and outputs lines are provided for MCU's communication with external devices. Input lines are protected with resistors (R3+R4, R7+R8) connected in series with digital buffers (IC2), which outputs are additionally dampened with resistors (R5, R9) to reduce possibility of MCU damage. IC2 inputs accept voltages up to +5.5 V. Therefore, it acts as level translator if inputs are driven with TTL levels. Digital outputs are boosted with two pair of buffers wired in parallel to provide higher current capacity. Finally, all inputs and outputs are clamped for additional safety with low capacitance 4-channel ESD-protection device (IC1).

On-board rotary encoder (SW2) is equipped with push-button and is supplemented with tactile switch (SW1) which can be assigned to various functions to provide more flexibility in interactions with user.


(https://www.envox.hr/eez/images/eez_dib_mcu_r2b4_sheet1of5.png)Fig. 6: Connectors, User switch, encoder and digital I/O

## On-board memory and SWD interface

The MCU board has three different memory devices (Fig. 7.):

- SD-RAM (IC6) managed by FMC (Flexible Memory Controller) with 12-bit address bus and 16-bit data bus,
- EEPROM (IC7) connected to shared I2C bus
- Micro SD card inserted into “push-push” card holder (J1) managed by three lines SDMMC (SD Memory Management Controller). Additional input (SD_DETECT) is used for detecting presence of the micro SD card.


(https://www.envox.hr/eez/images/eez_dib_mcu_r2b4_sheet3of5.png)Fig. 7: SDRAM, EEPROM, micro SD card and SWD

Optional SWD interface for programming and debugging purposes is provided by ESD protected (IC5) 6-pin 0.1” pin header (X4). Its pinout is compatible with STlink debugger that can be found on evaluation boards and kits such as Nucleo (https://www.st.com/en/evaluation-tools/stm32-nucleo-boards.html) and Discovery (https://www.st.com/en/evaluation-tools/stm32-discovery-kits.html).

If an STlink debugger is to be used, resistors R19 and R20 (22 – 47 Ω) will also need to be installed.

## TFT display, touchscreen, USB, speaker and BOOT0 switch

The MCU is capable of driving directly a TFT display with RGB interface generating all required signals and pixel data up to 24-bit format. However, only 16-bit RGB interface is used due to pin limitations of selected package and pin demands by other activated features. First two bits of all color channels can be set to 0 (default) or 1 using PCB jumper (JP6). A standard 40-pin 0.5 mm FFC ZIF connector (LCD1) is used for interfacing TFT display and resistive touchscreen. The MCU board is tested with EastRising ER-TFT043-8-3023 and Raystar RFE43BH-AIW-DNS (https://www.tme.eu/en/details/rfe43bh-aiw-dns/tft-displays/raystar-optronics/), 4.3” 480 x 272 pixel displays.

TFT LED backlight requires high voltage (~30 V) power supply with constant current output. TPS61169 (https://www.ti.com/product/TPS61169) (IC9) WLED driver (boost type) serves this purpose. It comes with built-in protection against open circuits to prevent the output voltage from exceeding the absolute maximum voltage ratings of the device. Additionally, a Zener diode (ZD1) is mounted to protect TFT LED array, by keeping the output voltage within safe limit. Output current is programmed with R25 and CTRL input is used for brightness control that is connected to PWM output (TFT_BRIGHTNESS).


(https://www.envox.hr/eez/images/eez_dib_mcu_r2b4_sheet4of5.png)Fig. 8: USB, TFT, Touchscreen, Audio amplifier

Touchscreen functionality is accomplished with TSC2007 (https://www.ti.com/product/TSC2007), a 4-wire controller with I2C interface (IC12) and belongs to one of the few models that comes in package with exposed pads (for simple manual soldering) and is still in production. It includes 12-bit SAR ADC (can be downsized to 8-bit for shorter conversion time) and drivers and the control logic to measure touch pressure. Since TSC2007 has built-in ESD protection, IC11 is not mounted, and marked as optional.

The USB interface is also directly provided by MCU that can be programmed to act as USB device or host with OTG (https://en.wikipedia.org/wiki/USB_On-The-Go) capability over 5-pin USB AB mini socket (J2). USB power distribution (max. 500 mA) in host mode is controlled with IC8 and all data lines that is protected against ESD with IC10. Optional LED (VBUS) indicates USB VBUS voltage.

A sound generated by DAC (DAC_OUT1) is simply buffered with Q2 which drives PCB mounted small 8 Ω loudspeaker (SP1). Speaker power supply can be set with PCB jumper (JP8) to +3.3 V (default) or +5 V.

The BOOT0 switch (SW3) is used to enable MCU's embedded bootloader that is stored in the internal boot ROM memory (system memory) of STM32 devices during the power up. Bootloader main task is to download the application program to the internal Flash memory through one of the available serial peripherals such as USB when DFU (https://en.wikipedia.org/wiki/USB#Device_Firmware_Upgrade) protocol can be used.

## Ethernet PHY

The MCU provides 10/100 Mbit MAC (https://en.wikipedia.org/wiki/Medium_access_control) with dedicated DMA and can work with IEEE 1588v2 (https://en.wikipedia.org/wiki/Precision_Time_Protocol) hardware. Yet, it does not offer physical layer (PHY) interface, thus an external PHY transceiver, DP83848C (https://www.ti.com/product/DP83848C) (IC14) is incorporated. The DP83848 can be interfaced with both MII (https://en.wikipedia.org/wiki/Media-independent_interface) and RMII, and MII is chosen because of lower reference clock frequency (25 MHz for 100 Mbit/s, instead of 50 MHz for RMII) despite the higher pin count. It has Auto MDIX (https://en.wikipedia.org/wiki/Medium-dependent_interface) capability to select MDI or MDIX automatically and supports Auto-Negotiation for selecting the highest performance mode of operation. Connection with Ethernet network infrastructure is accomplished using RJ-45 socket (X5) with integrated magnetics (i.e. impedance/isolation transformers). Its interface lines can be additionally protected with optional IC13.

The Ethernet socket is connected by a short patch cable (https://www.envox.hr/eez/eez-bench-box-3/eez-bb3-wire-harness.html#ethernet_patch) to the enclosure rear panel.

## PCB layout


(https://www.envox.hr/eez/images/eez_dib_mcu_r2b4_sheet5of5.png)Fig. 9: Ethernet PHY

The MCU board is assembled on the 139 x 70 mm 4-layer PCB. The PCB is designed in such a way that all connectors and devices which require interaction with user: i.e. BOOT0 switch, Digital I/O, TFT, MicroSD card socket, USB, rotary encoder and user switch are positioned to the same PCB edge. Therefore, when properly mounted, they can be easily accessed from the EEZ BB3 enclosure’s front panel. Only the TFT display will require additional mounting frame or it can be fixed with the mounting tape.

PCB's top and bottom layers are used for signal routing, while two internal layers are used as ground and voltage planes. A special attention was needed to route SDRAM and Ethernet PHY with MCU. The same is valid for the USB data lines that should be routed as differential pair with matched impedance to 90 Ω.


(https://www.envox.hr/eez/images/mcu_pcb_r2b4_top-bottom.png)Fig. 10: PCB Top (cyan) and bottom (blue) layer


(https://www.envox.hr/eez/images/mcu_pcb_r2b4_l2.png)Fig. 11: PCB L2 layer (ground plane)


(https://www.envox.hr/eez/images/mcu_pcb_r2b4_l3.png)Fig. 12: PCB L3-layer (voltage plane)

Revision: 1 (of 10) Last modified:

DRAFT – EEZ DIB STM32F7 MCU

Last modified: 10 (of 10) Doc. version:

Revision: 9 (of 10) Last modified:

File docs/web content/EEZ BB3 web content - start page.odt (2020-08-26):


| Ver. 1.02 – 08/2020 www.envox.hr – github.com/eez-open

EEZ BB3 web content - start page

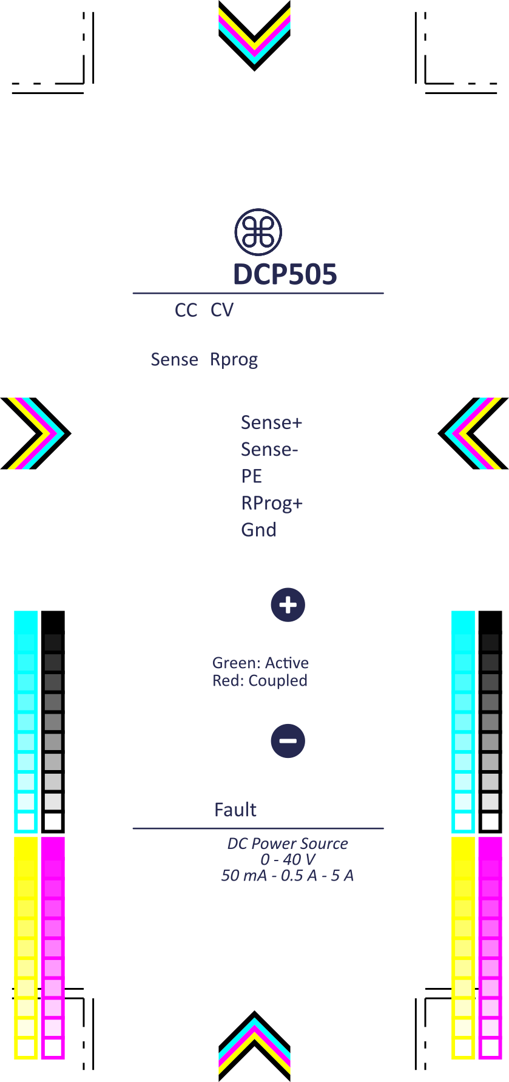
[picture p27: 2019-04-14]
dcp505/Front panel/DIB chassis DCP505 panel.png

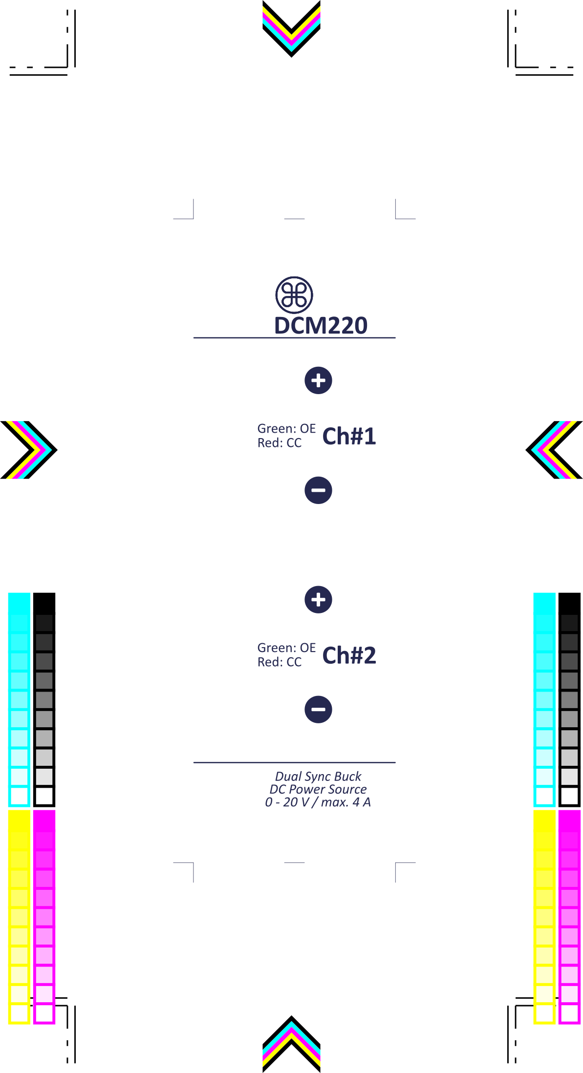
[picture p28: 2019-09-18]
dcm220/Front panel/DIB chassis DCM220 panel.png

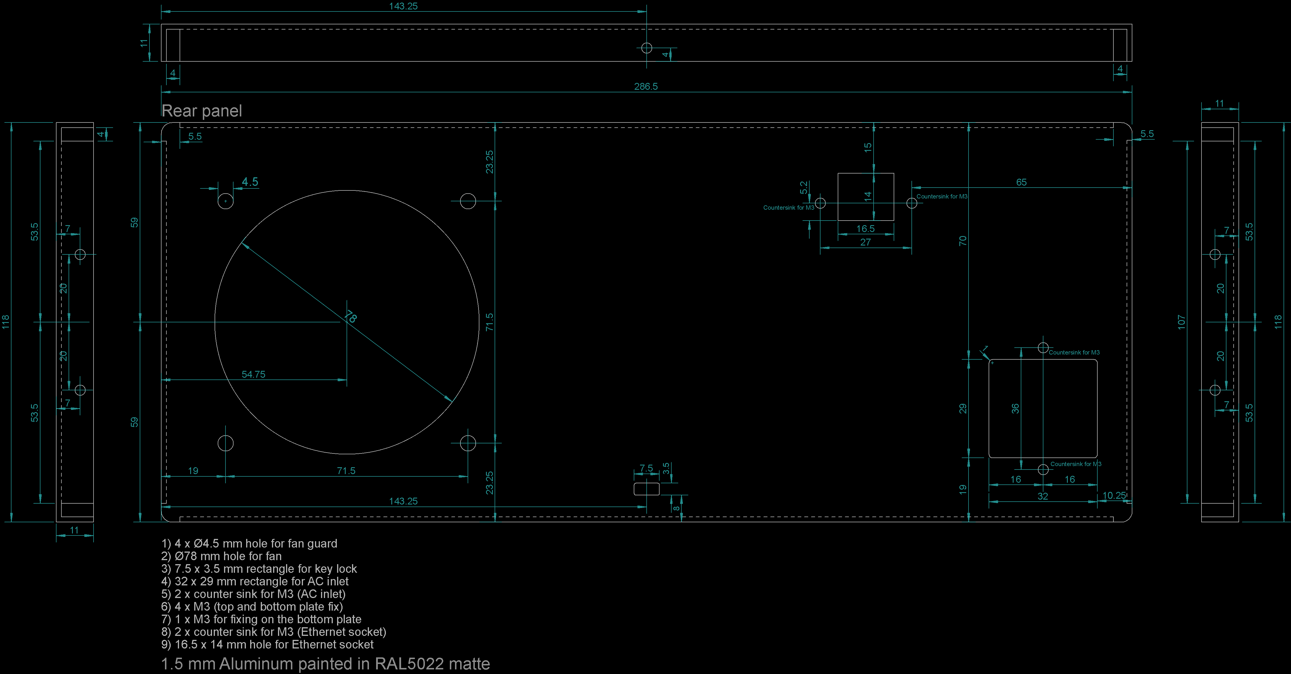
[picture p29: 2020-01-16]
enclosure/EEZ BB3 chassis rear panel.png

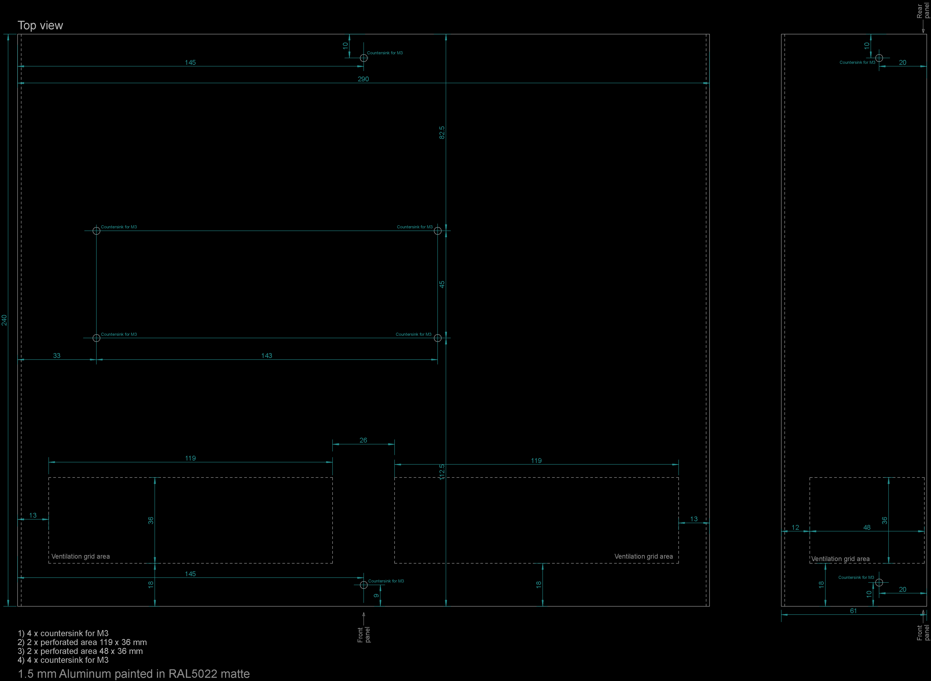
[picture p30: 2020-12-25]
enclosure/EEZ BB3 chassis top plate r2B1.png

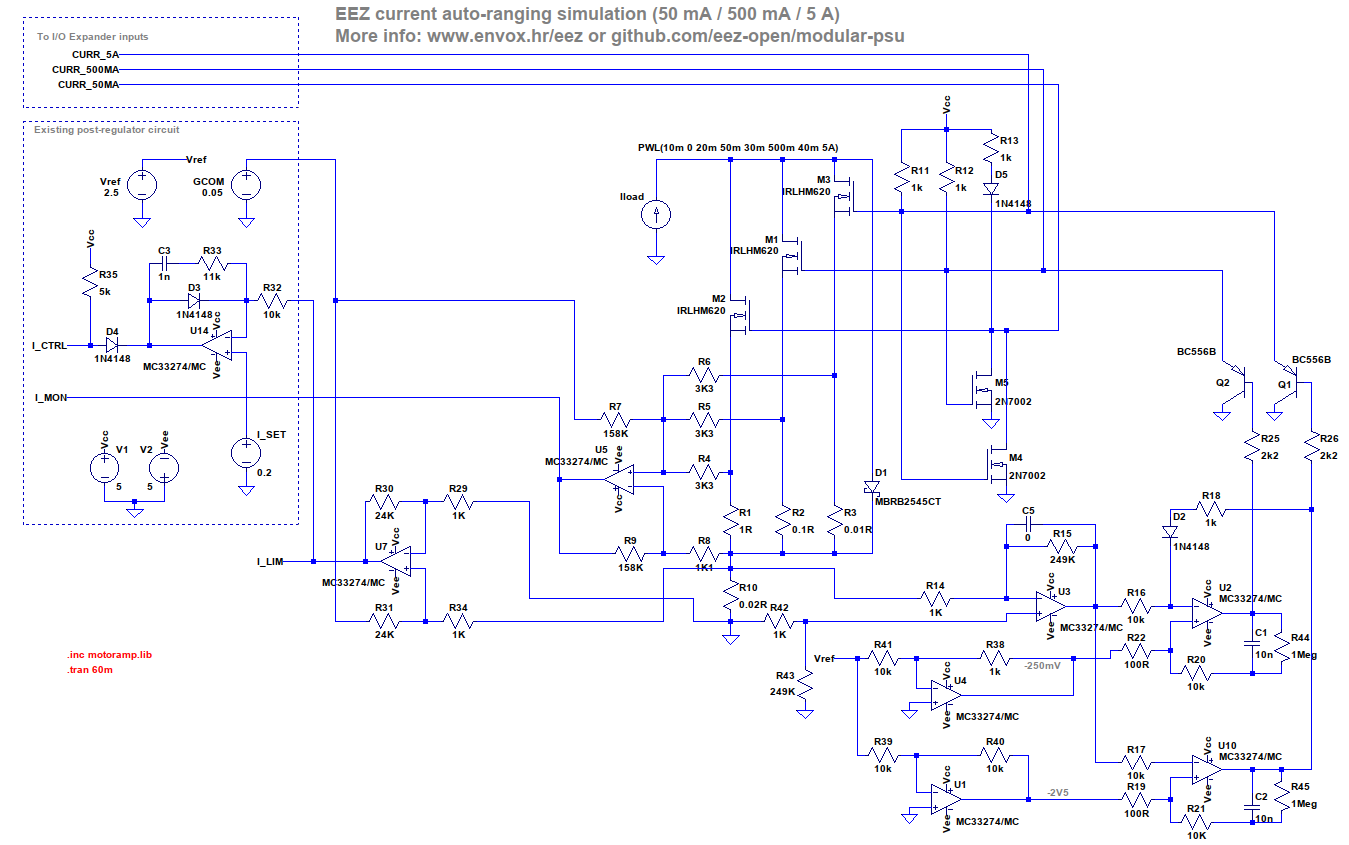
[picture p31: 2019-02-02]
dcp505/Spice/Auto-ranging/EEZ 3-level current auto-ranging schematic.png

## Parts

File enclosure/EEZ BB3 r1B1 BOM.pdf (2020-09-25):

EEZ DIB BB3 wire harness and enclosure (r1B1, 2020-09-25) Project source code at https://github.com/eez-open/modular-psu Mouser
| | | | | | MOQ | | | MOQ | | | MOQ
1 | 1 | 22-01-3037 | 1462838 | 22-01-3037 | 0,175 | 1 | WM2001-ND | 0,170 | 1 | 538-22-01-3037 | 0,166 | 1
2 | 1 | 39-01-2065 | 1697119 | 39-01-2065 | 0,515 | 1 | WM23702-ND | 0,530 | 1 | 538-39-01-2065 | 0,515 | 1
3 | 1 | 39-01-4030 | 9963480 | 39-01-4030 | 0,288 | 1 | WM18434-ND | 0,290 | 1 | 538-39-01-4030 | 0,288 | 1
4 | 3 | 39-01-3022 | 1704304 | 39-01-3022 | 0,288 | 1 | WM1021-ND | 0,280 | 1 | 538-39-01-3022 | 0,279 | 1
5 | 3 | 08-50-0114 | 1462641 | 08-50-0114 | 0,084 100 | WM1114-ND | 0,106 | 25 | 538-08-50-0114 | 0,075 100
6 | 15 | 39-00-0078 | 2725176 | 39-00-0078 | 0,111 50 | WM9154-ND | 0,125 | 25 | 538-39-00-0078 | 0,090 100
7 | 6 | 60196-3 | - | A122464-ND | 0,135 | 10 | 571-60196-3 | 0,135 10
8 | 15 | 9019040000 | - | 281-5091-ND | 0,070 500 | 0,029 25
9 | 0,7 | H05VK075BR | 2290831 | 3055 BR005 | 0,540 31 | A3055N-100-ND | 1,669 | 31 | 602-3055-100-07 | 1,516 31
10 | 0,7 | H05VK075BL | 2290833 | 3055 BL005 | 0,540 31 | 1,669 | 31 | 602-3055-100-06 | 1,586 31
11 | 1,05 H05VK075RT | 2290829 | 3055 RD005 | 0,540 31 | A2064R-100-ND | 2,014 | 31 | 602-3055-100-03 | 1,586 31
12 | 1,05 H05VK075SW | 2290834 | 3055 BK005 | 0,540 31 | 1,669 | 31 | 602-3055-100-02 | 1,586 31
13 | 1,55 H05VK075GN/GE | 2290830 | 3055 GY005 | 0,498 31 | A2064E-100-ND | 2,014 | 31 | 602-3055-100-28 | 1,586 31
14 | 1 | MF80251V3-1000U-G99 80x80x25mm, 12Vdc fan | - | | | | 259-2066-ND | 16,140 | 1 | -
| 0 | | - | | | | - | | | -
15 | 1 | | - | | | | - | | | -
16 | 4 | FSP-2
17 | 1 | FG-08
18 | 13 | M3X4/D7985
19 | 40 | M3X5/D965B
20 | 13 | TFF-M3X6/DR113
21 | 2 | B3/BN117
22 | 4 | B3/BN860
23 | 2 | M3X8/D965B
24 | 6 | 644-S4-18-M | 0,011 100
25 | 2 | A-951-A-0-G-0
1 | BB3-ENC-KIT
Farnell / Element14 | Digi-Key
Qty | Part name | Package / Note | Reference designator | Code | Part Number | Unit price €
Part Number | Unit price
€

Part Number Unit price
€
| | 3-pin 0.1” receptacle 6-pin receptacle Mini-Fit Jr. 3-pin receptacle Mini-Fit Jr. 2-pin receptacle Mini-Fit Jr. 0.1” pin for 22-01-3037 Mini-Fit Jr. pin Female quick disconnect, 4.8mm; 0.8mm
0.75 cm2 Ferrule | 845-
FID1806GRM
| | 0.75 cm2 cable (Brown)
0.75 cm2 cable (Blue) | A30551B-100-
ND
| | 0.75 cm2 cable (Red)
0.75 cm2 cable (Black) | 3055/1BK005-ND
| | 0.75 cm2 cable (Yellow-

Option: EE80251B1-
000U-G99

80x80x25mm, 12Vdc fan, ball bearing
D89116-0131HK-3365/16-D-3

16-pin IDC cable 10 to 15cm

Fastener for fans and
protections
Finger guard; 80x80mm
Screw; M3x4; cheese head;
Phillips

Module's studs mounting
(bottom), AC/DC mounting
frame (top), 3 x AC/DC
modules mounting
Screw; M3x5; countersunk;
Phillips; black finish

Module's studs mounting
(top), front and rear panel fixing, modules mounting on the front panel
Screwed spacer sleeve;
Int.thread: M3; 6mm;
hexagonal

For mounting AUX-PS, MCU
and BP3C to the bottom plate

Nut; hexagonal; M3; H: 2.4mm AC inlet fixing on the rear panel
Nut with flange; hexagonal;
M3

TFT display fixing on the front panel
Screw; M3x8; countersunk;
Phillips; black finish

AC inlet fixing on the rear panel
Cable tie 100mm | Cable tie; L: 100mm; W:
2.5mm; polyamide

For AC, DC and PE cables

Adjustable feet (pack of 2) Altinkaya, Turkey

Custom made components
BB3 enclosure kit (top and bottom plate, front and rear panel, AC/DC module mounting frame, TFT mounting frame)

# Qty Part name | RS Components | TME | Price calculation for 1 set

Code Part Number Unit price MOQ € | Code / Part Number Unit price MOQ € | THT SMD
1 | 1 | 22-01-3037
2 | 1 | 39-01-2065
3 | 1 | 39-01-4030
4 | 3 | 39-01-3022
5 | 3 | 08-50-0114
6 | 15 | 39-00-0078
7 | 6 | 60196-3
8 | 15 | 9019040000
9 | 0,7 | H05VK075BR
10 | 0,7 | H05VK075BL
11 1,05 H05VK075RT
12 1,05 H05VK075SW
13 1,55 H05VK075GN/GE
14 | 1 | MF80251V3-1000U-G99
| 0

15 1

16 | 4 | FSP-2
17 | 1 | FG-08
18 | 13 | M3X4/D7985
19 | 40 | M3X5/D965B
20 | 13 | TFF-M3X6/DR113
21 | 2 | B3/BN117
22 | 4 | B3/BN860
23 | 2 | M3X8/D965B

24 6

25 | 2 | A-951-A-0-G-0
1 | BB3-ENC-KIT

Option: EE80251B1-
000U-G99
D89116-0131HK-3365/16-D-3

Cable tie 100mm

Custom made components

679-5375 22-01-3037 | 0,098 10 | MX-22-01-3037 | 0,080 10 | TME | 0,080 € | 1 | 0,080
679-5773 39-01-2065 | 0,520 | 5 | MX-39-01-2065 | 0,130 10 | TME | 0,130 € | 1 | 0,130
510-9685 39-01-4030 | 0,238 | 5 | MX-5557-03R2 | 0,169 | 5 | TME | 0,169 € | 1 | 0,169
670-4569 39-01-3022 | 0,193 10 | MX-39-01-3022 | 0,143 10 | TME | 0,143 € | 3 | 0,430
172-9178 08-50-0114 | 0,075 100 | MX-0850-0114 | 0,058 10 | TME | 0,058 € | 3 | 0,173
215-5887 39-00-0078 | 0,154 100 | MX-5556-T3L | 0,087 10 | TME | 0,087 € 15 | 1,298
719-6987 60196-3 | 0,098 100 | ST-004/2 | 0,062 20 | TME | 0,062 € | 6 | 0,372
H0.75/14D/GY | 0,024 20 | TME | 0,024 € 15 | 0,357
H05VK075BR | 0,104 100 | TME | 0,104 € | 1 | 0,072
H05VK075BL.D | 0,104 100 | TME | 0,104 € | 1 | 0,072
H05VK075RT | 0,104 100 | TME | 0,104 € | 1 | 0,109
H05VK075SW | 0,104 100 | TME | 0,104 € | 1 | 0,109
H05VK075GN/GE | 0,104 100 | TME | 0,104 € | 2 | 0,160
- | | | | 2,040 | 1 | TME | 2,040 € | 1 | 2,040
- | | | EE80251B1-G99 | 4,500 | 1 | TME | 4,500 € | 0 | 0,000
- | | | FC16150-S | 1,310 | 1 | TME | 1,310 € | 1 | 1,310
| | | FSP-2 | 0,142 | 5 | TME | 0,142 € | 4 | 0,566
| | | FG-08 | 0,524 | 1 | TME | 0,524 € | 1 | 0,524
M3X4/D7985 | 0,012 100 | TME | 0,012 € 13 | 0,152
M3X5/D965B | 0,012 100 | TME | 0,012 € 40 | 0,500
TFF-M3X6/DR11 | 0,110 10 | TME | 0,110 € 13 | 1,434
B3/BN117 | 0,005 100 | TME | 0,005 € | 2 | 0,010
B3/BN860 | 0,017 100 | TME | 0,017 € | 4 | 0,066
M3X8/D965B | 0,015 100 | TME | 0,015 € | 2 | 0,029
BMB1025 | 0,010 100 | TME | 0,010 € | 6 | 0,058
| | | 2,000 € | 2 | 4,000
| | | | | 14,22 €
1 | 0,000

Best
Supplier

Lowest
unit price
€

Order
Qty Line Cost €

MF80251V3-1000U-G99

Altinkaya

Varisom, Portugal

Mouser
MOQ | MOQ | MOQ
Farnell / Element14 | Digi-Key
Qty | Part name | Package / Note | Reference designator | Code | Part Number | Unit price €
Part Number | Unit price
€

Part Number Unit price
€
1 | BB3-CP-MFP
1 | BB3-DCP405-MFP
1 | BB3-DCP405B-MFP
1 | BB3-DCM220-MFP | Empty module front cover plate
| | DCP405 front panel
| | DCP405B front panel
| | DCM220 front panel

All prices are net prices (without VAT)

Please note that BOM does not contain ordering number for parts on reels or that which includes re-reeling fee (e.g. Farnell). Take also into account that total cost is higher because min. quantity (MOQ) for many parts is larger then what is needed for single unit.

# Qty Part name | RS Components | TME | Price calculation for 1 set

Code Part Number Unit price MOQ € | Code / Part Number Unit price MOQ € | THT SMD

1 BB3-CP-MFP
1 | BB3-DCP405-MFP
1 | BB3-DCP405B-MFP
1 | BB3-DCM220-MFP

Best
Supplier

Lowest
unit price
€

Order
Qty | Line Cost €
1 | 0,000
1 | 0,000
1 | 0,000
1 | 0,000
0,00 €

14,22 €

Varisom, Portugal
Varisom, Portugal
Varisom, Portugal

Total

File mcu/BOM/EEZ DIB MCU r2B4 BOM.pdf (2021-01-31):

EEZ DIB MCU BOM (r2B4, 2020-10-27) Project source code at https://github.com/eez-open/modular-psu
| | | | Farnell / Element14 | | | Digi-Key | | | Mouser
Qty | Part name | Package

Reference designator
| | | Code | Part Number | | MOQ | Part Number | | MOQ | Part Number | | MOQ
1 | 1 | B1 | 2115304 | S8401-46 | 2,190 | 1 | 952-1743-1-ND | 1,230 | 1 | 855-S8401-46 | 1,220 | 1
2 | 2 4p7 | 0603, C0G | C10, C12 | 2627469 | 0,329 10 | 311-1740-1-ND | 0,054 | 10 | 0,072 10
3 | 1 EEEFK1V470P | Ø6.3 x 5.8 mm | C13 | 9695850 | EEEFK1V470P | 0,364 | 1 | PCE3842CT-ND | 0,302 | 10 | 0,238 10
4 | 3 4u7/6.3V | 1206, Tant. | 2321209 | T491A475K006AT | 0,421 | 5 | 399-9717-1-ND | 0,259 | 10 | 0,184 10
5 | 5 1u | 2495193 | 885012207078 | 0,139 | 5 | 1276-1066-1-ND | 0,070 | 10 | 0,050 10
6 | 4 10n | 0805 | 2896555 | 0,065 10 | 490-7194-1-ND | 0,017 | 10 | 0,036 10
7 | 3 2u2 | 0805 | C36, C37, C50 | 1828829 | 0,198 | 5 | 1276-2954-1-ND | 0,085 | 10 | 0,078 10
8 | 3 4u7 | 1206 | C39, C47, C53 | 1907356 | 0,282 | 5 | 1276-2970-1-ND | 0,199 | 10 | 0,129 10
9 | 36 100n | 0603 | 2522597 | 0,073 10 | 490-4774-1-ND | 0,090 100 | 0,085 100
10 | 1 10u | 1206, Tant. | C64 | 1457412 | T491A106K006AT | 0,259 | 5 | 399-3683-1-ND | 0,238 | 10 | 0,173 10
11 | 2 18p | 0603, C0G | C9, C11 | 2896373 | 0,016 10 | 1276-1089-1-ND | 0,048 | 10 | 0,023 10
12 | 1 SMBJ5.0A-TR | DO-214AA | D1 | 2353654 | SMBJ5.0ATR | 0,232 | 5 | 497-3144-1-ND | 0,263 | 10 | 511-SMBJ5.0A | 0,306 | 1
13 | 1 RB751V40T1G | D2 | 1459171 | RB751V40T1G | 0,143 | 5 | 0,192 | 10 | 0,146 10
14 | 2 BLM18AG102SH1D | FB1, FB2 | 1669708 | MMZ1608Y102B | 0,072 10 | 490-7809-1-ND | 0,052 | 50 | 0,063 10
15 | 2 TPD4E001DRLR | SOT-5X3 (SOT-563) | IC1, IC10 | 1611469 | TPD4E001DRLR | 0,453 | 5 | 296-21887-1-ND | 0,590 | 1 | | 0,536 | 1
16 | 1 TSC2007IPW | TSSOP-16 | IC12 | 2769429 | TSC2007IPWR | 1,700 | 1 | 296-27124-1-ND | 2,110 | 1 | | 2,040 | 1
17 | 1 DP83848CVV/NOPB | LQFP-48 | IC14 | 1685784 | | 4,850 | 1 | | 4,280 | 1 | | 4,260 | 1
18 | 1 CD74HC4050PWR | TSSOP-16 | IC2 | 1753505 | CD74HC4050PW | 0,436 | 5 | 296-9215-1-ND | 0,400 | 1 | | 0,376 | 1
19 | 1 STM32F769IIT6 | LQFP-176 | IC3 | 2849930 | STM32F769IIT6 | 15,100 | 1 | 497-16649-ND | 14,800 | 1 | | 14,510 | 1

Unit price
€

Unit price
€

Unit price
€

S8401-46 or DS1092-02-
B6P

THT; CR2032 cell battery
holder; vertical
MC0603N4R7C500 CT | 710-885012006049
| 667-EEE-FK1V470P
C15, C22, C49 | 80-T491A475K006A T
| TMK212B7105K G-T
C3, C4, C6, C7 VJ0805Y103JXXP W1BC | 710-885012207122
| 80-C0805C225M4R ECLR
C3216X7R1E475K 160AC | 963-EMK316B7475M L-T
| 80-C0603C104M4R
C68 | 80-T491A106K0067 280
| 80-C0603C180J5G7 867

0805, C48 must be 25 V or
more
C24, C33, C34, C48, C56 | 963-

GRM21BR71C225
KA12L

C5, C14, C16, C17, C18,
C19, C20, C21, C23, C26,
C27, C28, C29, C30, C31,
C32, C35, C40, C41, C42,
C43, C44, C45, C46, C52,
C55, C58, C59, C60, C61,
C62, C63, C65, C66, C67,

C0603C104K4RAC
7081

VJ0603A180JXAC
W1BC

SOD-323, low capacitance
switching diode
RB751V40T1GO SCT-ND | 863-RB751V40T1G
0603 ferrite bead; 60R; 100MHz | | 81-BLM18AG102SH 1D
| | 595-TPD4E001DRLR
| | 595-TSC2007IPWR
| DP83848CVV/ NOPB-ND | 926-DP83848CVV/ NOPB
| | 595-CD74HC4050PW R

DP83848CVV/
NOPB

511-
STM32F769IIT6

# Qty Part name | RS Components | TME | Price calculation for 1 set

Unit price Code Part Number MOQ € | Unit price Code / Part Number MOQ € | THT SMD | | Line Cost €

1 1

2 2 4p7

3 1 EEEFK1V470P

4 3 4u7/6.3V

5 5 1u

6 4 10n

7 3 2u2

8 3 4u7

9 36 100n

10 1 10u

11 2 18p

12 1 SMBJ5.0A-TR
13 1 RB751V40T1G

14 2 BLM18AG102SH1D

15 2 TPD4E001DRLR

16 1 TSC2007IPW

17 1 DP83848CVV/NOPB

18 1 CD74HC4050PWR

19 1 STM32F769IIT6

S8401-46 or DS1092-02-
B6P
161-3709 S8401-46 | 1,454 | 5 | DS1092-02-B6P | 0,224 | 1 | 1 | TME | 0,224 € | 1 | 0,224
298-9315 | 0,024 25 | CL10C4R7CB8NNNC | 0,024 100 | 2 | RS | 0,024 € | 2 | 0,048
537-0657 EEEFK1V470P | 0,394 | 5 | EEEFK1V470P | 0,130 | 5 | 1 | TME | 0,130 € | 1 | 0,130
538-2335 | 0,337 10 | T491A475K006AT | 0,094 10 | 3 | TME | 0,094 € | 3 | 0,281
691-1167 | 0,049 25 | 0,014 100 | 5 | TME | 0,014 € | 5 | 0,072
464-6672 | 0,026 50 | CC0805KRX7R9103 | 0,027 100 | 4 | Digikey | 0,017 € | 4 | 0,068
766-1031 | 0,069 100 | CL21B225KOFNNNG | 0,071 100 | 3 | RS | 0,069 € | 3 | 0,207
691-1221 | 0,232 25 | 0,381 10 | 3 | Mouser | 0,129 € | 3 | 0,387
264-4630 | 0,035 25 | CL10B104KA8NNNC | 0,098 100 | 36 | RS | 0,035 € 36 | 1,260
136-2614 | F930J106MA | 0,182 25 | T491A106K006AT | 0,069 25 | 1 | TME | 0,069 € | 1 | 0,069
147-415 | 0,032 50 | CL10C180JB8NNNC | 0,015 100 | 2 | TME | 0,015 € | 2 | 0,030
714-7210 SMBJ5.0A-TR | 0,268 25 | SMBJ5.0A-TR | 0,114 | 5 | 1 | TME | 0,114 € | 1 | 0,114
690-0022 | RB751V40T1G | 0,137 25 | RB751V40T1G | 0,036 25 | 1 | TME | 0,036 € | 1 | 0,036
839-0803 | 0,043 100 | BLM18AG102SH1D | 0,016 50 | 2 | TME | 0,016 € | 2 | 0,031
709-9066 | 0,552 | 5 | - | | | 2 | Farnell | 0,453 € | 3 | 1,359
661-3545 TSC2007IPW | 2,340 | 1 | - | | 1 | 1 | Farnell | 1,700 € | 1 | 1,700
651-5738 | 4,310 | 1 | DP83848CVV/NOPB | 3,000 | 1 | 1 | TME | 3,000 € | 1 | 3,000
662-7131 | 0,309 10 | - | 1 | RS | 0,309 € | 1 | 0,309
- | STM32F769IIT6 | 13,010 400 | 1 | TME | 13,010 € | 1 | 13,010

Best
Supplier

Lowest
unit price
€

Order
Qty

C0603C479C5G
ACTU

T491A475K006A T

| VJ0805Y105KXXTW1 BC

08055C103KAT 2A

C0805C105K3R
ACTU

CL21B225KAFN
NNF

C1206C475K3R
ACTU

GCM31CR71E475KA5
5L

C0603C104K4R
ACTU

C0603C180J5G
ACTU

BLM18AG102S
H1D

TPD4E001DRLR

DP83848CVV/
NOPB

CD74HC4050P
WR

# Reference designator Code Part Number MOQ Qty Part name Package € | Part Number Unit price MOQ € | Part Number Unit price MOQ Unit price €

| | 511-LD1117ADT33-TR
| IS42S16400J-7TLI | 870-IS42S16400J-7TL
AT24C256C-SSHL-B | AT24C256C-SSHL-B-ND | 556-AT24C256C-SSHL-B
| | 595-TPS2051BDBVR
| | 595-TPS61169DCKR
| WM11190CT-ND | 538-503398-1892
20 | 1 LD1117ADT33TR | TO-252 (DPAK) | IC4 | 2849768 | LD1117ADT33TR | 0,419 | 1 | 497-3455-1-ND | 0,420 | 1 | | 0,408 | 1
21 | 1 IS42S16400J-7TL | TSOP-II | IC6 | - | | | | | 2,050 | 1 | | 1,410 | 1
22 | 1 AT24C256C-SSHL-B | SOIC-8 | IC7 | 1972001 | | 0,685 | 1 | | 0,540 | 1 | | 0,541 | 1
23 | 1 TPS2051BDBVR | SOT-23-5 | IC8 | 2296067 | TPS2051BDBVR | 1,080 | 1 | 296-21265-1-ND | 1,280 | 1 | | 1,220 | 1
24 | 1 TPS61169DCKR | SC-70-5 | IC9 | 2542731 | TPS61169DCKR | 0,661 | 1 | 296-40821-1-ND | 0,790 | 1 | | 0,770 | 1
25 | 1 503398-1892 | Micro SD, push-push, 8-pin | J1 | 2358234 | 503398-1892 | 1,980 | 1 | | 2,160 | 1 | | 1,960 | 1
26 | 1 67803-8020 | USB mini AB, OTG, 5-pin | J2 | 1355761 | 67803-8020 | 1,470 | 1 | WM17148CT-ND | 1,790 | 1 | 538-67803-8020 | 1,790 | 1
27 | 1 DLG-0403-4R7 | 0403 power inductor | L1 | 1827980 | SDR0403-4R7ML | 0,406 | 5 | 0,424 | 10 | 0,272 10
28 | 1 505110-4091 | LCD1 | 2500025 | 505110-4091 | - | WM11292CT-ND | 1,250 | 1 | 1,150 | 1
29 | 1 2N27002 | SOT-23 | Q2 | 1713823 | 2N7002-7-F | 0,118 | 5 | | 0,150 | 1 | | 0,128 | 1
30 | 8 4K7 | 0805 | 2861530 | CRGCQ0805F4K7 | 0,009 10 | 0,090 | 1 | 0,026 10
31 | 1 47R | 0805 | R17 | 2861899 | CRGCQ0805J47R | 0,007 10 | P47.0CCT-ND | 0,069 | 10 | 0,028 10
32 | 5 10K | 0805 | R2, R10, R12, R13, R30 | 9237755 | 0,022 10 | 0,039 | 10 | 0,014 10
33 | 2 47K | 0805 | R21, R22 | 2447664 | 0,010 10 | RHM47KKCT-ND | 0,074 | 10 | 0,026 10
34 | 2 10R | 0805 | R23, R25 | 2447556 | 0,007 10 | 0,064 | 10 | 0,047 10
35 | 2 22R | 0805 | R28, R29 | 2447609 | 0,008 10 | 0,036 | 10 | 0,053 10
36 | 1 1K5 | 0805 | R31 | 2861908 | CRGCQ0805J1K5 | 0,007 10 | 541-4161-1-ND | 0,041 | 10 | 0,085 10
37 | 4 49R9 | 0805 | R32, R33, R36, R41 | 2447669 | 0,009 10 | 0,039 | 10 | 0,026 10
38 | 11 2K2 | 0805 | 9237534 | 0,037 10 | 0,039 | 10 | 0,026 10
39 | 2 220R | 0805 | R43, R44 | 1099795 | WCR0805-220RFI | 0,019 10 | 0,020 | 10 | 0,020 10
40 | 1 4K87 | 0805 | R47 | 1469925 | 0,016 10 | 0,039 | 10 | 0,037 10
41 | 2 1K | 0805 | R5, R9 | 1099800 | WCR0805-1K0FI | 0,019 10 | 0,039 | 10 | 0,015 10
SDR0403-4R7MLCT-ND | 652-SDR0403-4R7ML
SMD; FFC/FPC 40-pin lower side entry | | 538-505110-4091
| 2N7002LT1GOS CT-ND | 863-2N7002LT1G
R1, R3, R4, R6, R7, R8, R11, R14 | 311-4.70KCRCT-ND | 603-RC0805FR-074K7L
| | 279-CRGCQ0805F47 R
RC0805FR-0710KL | 311-10.0KCRCT-ND | 603-RC0805FR-0710KL
| | 603-RC0805FR-0747KL
MCWR08X10R0FT L | 311-10.0CRCT-ND | 71-CRCW080510R0 FKEAC
| 311-22.0CRCT-ND | 71-CRCW080522R0 FKEAC
| | 279-CRGCQ0805F1K 5
| 311-49.9CRCT-ND | 603-RC0805FR-0749R9L
R15, R16, R34, R35, R37, RC0805FR-072K2L R39, R40, R42, R45, R46, R48 | 311-2.20KCRCT-ND | 603-RC0805FR-072K2L
| RMCF0805FT22 0RCT-ND | 603-RC0805FR-13220RL
CRCW08054K87F KEA | 311-4.87KCRCT-ND | 652-CR0805FX-4871ELF

MCWR08X4702FT
L

MCWR08X22R0FT
L

MCWR08X49R9FT
L

RC0805FR-071KL

603-RC0805FR-071KL

# Qty Part name

20 1 LD1117ADT33TR

21 1 IS42S16400J-7TL

22 1 AT24C256C-SSHL-B

23 1 TPS2051BDBVR

24 1 TPS61169DCKR

25 1 503398-1892
26 1 67803-8020
27 1 DLG-0403-4R7

28 1 505110-4091

29 1 2N27002

30 8 4K7

31 1 47R

32 5 10K

33 2 47K

34 2 10R

35 2 22R

36 1 1K5

37 4 49R9

38 11 2K2

39 2 220R

40 1 4K87

41 2 1K

Code Part Number MOQ € | Code / Part Number Unit price MOQ € | THT SMD | Line Cost € Unit price
| LD1117ADT33T R

Best
Supplier

Lowest
unit price
€

Order
Qty
686-9123 | 0,499 10 | LD1117ADT33 | 0,521 | 3 | 1 | Mouser | 0,408 € | 1 | 0,408
811-5125 | 2,565 | 2 | IS42S16400J-7TL | 2,050 | 1 | 1 | Mouser | 1,410 € | 1 | 1,410
738-0041 | 0,488 | 5 | AT24C256C-SSHL-B | 0,470 | 3 | 1 | TME | 0,470 € | 1 | 0,470
662-2384 TPS2051BDBVT | 1,284 | 5 | - | | | 1 | Farnell | 1,080 € | 1 | 1,080
- | | | - | | | 1 | Farnell | 0,661 € | 1 | 0,661
880-1277 503398-1892 | 2,600 | 1 | MX-503398-1892 | 0,860 | 2 | 1 | TME | 0,860 € | 1 | 0,860
720-6618 67803-8020 | 1,540 | 5 | MX-67803-8020 | 0,590 | 1 | 1 | TME | 0,590 € | 1 | 0,590
- | DLG-0403-4R7 | 0,129 10 | 1 | TME | 0,129 € | 1 | 0,129
178-9542 505110-4091 | 1,020 | 5 | - | | | 1 | RS | 1,020 € | 1 | 1,020
545-0012 2N7002LT1G | 0,126 50 | 2N7002LT1G | 0,025 25 | 1 | TME | 0,025 € | 1 | 0,025
223-0528 CRG0805F4K7 | 0,010 50 | SMD0805-4K7-1% | 0,022 100 | 8 | Farnell | 0,009 € | 8 | 0,069
223-0253 CRG0805F47R | 0,016 50 | SMD0805-47R-1% | 0,022 100 | 1 | Farnell | 0,007 € | 1 | 0,007
125-1189 CRG0805F10K | 0,002 100 | RC0805FR-0710K | 0,022 100 | 5 | RS | 0,002 € | 2 | 0,004
679-1434 | 0,046 50 | SMD0805-47K-1% | 0,022 100 | 2 | Farnell | 0,010 € | 2 | 0,019
223-0152 CRG0805F10R | 0,019 50 | 0805S8F100JT5E | 0,015 100 | 2 | Farnell | 0,007 € | 2 | 0,013
223-0203 CRG0805F22R | 0,006 50 | 0805S8F220JT5E | 0,016 100 | 2 | RS | 0,006 € | 2 | 0,012
223-0449 CRG0805F1K5 | 0,036 50 | SMD0805-1K5-1% | 0,022 100 | 1 | Farnell | 0,007 € | 1 | 0,007
679-1462 | 0,036 50 | RC0805FR-0749R9 | 0,035 100 | 4 | Farnell | 0,009 € | 2 | 0,019
679-1207 | 0,039 50 | SMD0805-2K2-1% | 0,022 100 | 11 | TME | 0,022 € | 2 | 0,045
223-0332 CRG0805F220R | 0,018 50 | 0805S8F2200T5E | 0,022 100 | 2 | RS | 0,018 € | 2 | 0,036
- | RC0805FR-074K87 | 0,035 100 | 1 | Farnell | 0,016 € | 1 | 0,016
223-0427 CRG0805F1K0 | 0,017 50 | SMD0805-1K-1% | 0,022 100 | 2 | Mouser | 0,015 € | 2 | 0,030

IS42S16400J-7TLI

AT24C256C-SSHL-B

CRCW080547K
0FKEA

CRCW080549R
9FKEA
CRCW08052K2
0FKEA

# Reference designator Code Part Number MOQ Qty Part name Package € | Part Number Unit price MOQ € | Part Number Unit price MOQ Unit price €

| CAY16-330J4LFCT-ND | 652-CAY16-330J4LF
42 | 4 DR1206-33R-4/8 | 1206; resistor array | RN1, RN2, RN3, RN4 | 1770128 | CAY16-330J4LF | 0,069 10 | 0,090 | 1 | 0,085 | 1
43 | 1 LD-BZEN 0903 | | SP1 | - | | | | - | | | -
44 | 1 PEC16-2215F-S0024 | | SW1 | - | | | | | 1,340 | 1 | | 1,220 | 1
45 | 1 TL1100CF160Q | | SW2 | 2830627 | TL1100CF160Q | 0,474 | 1 | EG1822-ND | 0,380 | 1 | 612-TL1100C | 0,442 | 1
46 | 1 EVQP7A01P | Tactile micro switch | SW3 | 2860916 | EVQP7A01P | 0,268 | 5 | P16763CT-ND | 0,270 | 1 | 667-EVQP7A01P | 0,252 | 1
47 | 1 DS1024-2*20R0 | | X1 | 1805895 | | 4,920 | 1 | SAM11958-ND | 3,060 | 1 | | 3,050 | 1
48 | 1 DS1013-16SSIB1 | | X2 | 2843530 | | 0,220 | 1 | ED10523-ND | 0,350 | 1 | | 0,540 | 1
49 | 1 | 691322110005 | X3 | 2493680 | CTB932HD/5 | 0,373 10 | 732-2772-ND | 1,010 | 1 | 1,000 | 1
50 | 1 | | X5 | - | | | | -
51 | 1 25 MHz | SMD; HC-49/US; XTAL | Y1 | 2832034 | LFXTAL033342 | 0,227 | 1 | 1923-1536-1-ND | 0,360 | 1 | | 0,298 | 1
52 | 1 XTAL016178-85SMX | SMD; 8.7mm x 3.7mm; XTAL Y2 | 1652572 | 0,440 | 1 | 1923-1021-1-ND | 0,520 | 1 | 0,393 | 1
53 | 1 BZX384-B24.115 | SOD-323 | ZD1 | 2844814 | MM3Z24VST1G | 0,130 | 5 | 1727-3645-1-ND | 0,210 | 10 | 0,141 10

Not installed / optional
1 M22-2510246 | BOOT1 | 2289776 | M22-2510205 | 0,096 100 | 952-2280-ND | 0,150 | 1 | 0,148 | 1
5 N.C. | 0603 | C2, C25, C38, C54, C57
1 1n 0805 C8 2896470 VJ0805A102JXAC 0,044 10 W1BC | 732-7858-1-ND 0,055 10 | 710-0,052 10 885012007040
| | 595-TPD4E001DRLR
1 MMBT5551 SOT-23 Q1 1459109 MMBT5551LT1G 0,154 5 | MMBT5551LT1G 0,180 1 OSCT-ND | 863-0,170 1 MMBT5551LT1G
| ND | 603-RC0805FR-0710KL
2 22R 0805 R19, R20 1099795 WCR0805-220RFI 0,019 10 | RMCF0805FT22 0,020 10 R0CT-ND | RC0805FR-0,026 10 07220RL
3 TPD4E001DRLR | SOT-6 | IC5, IC11, IC13 | 1611469 | TPD4E001DRLR | 0,453 | 5 | 296-21887-1-ND | 0,590 | 1 | 0,536 | 1
2 10K | 0805 | R18, R26 | 9237755 | 0,022 10 | 0,039 | 10 | 0,014 10
1 330R | 0805 | R24
1 47K 0805 R27 2447664 MCWR08X4702FT 0,010 10 L | RHM47KKCT-ND 0,074 10 | 603-RC0805FR-0,026 10 0747KL
| RMCF0805FT22 0RCT-ND | 603-RC0805FR-13220RL
1 LTST-C170YKT 0805 LED; Yellow SPEED 2062217 SML-LX0805YC-0,180 5 TR | 160-1175-1-ND 0,229 10 | 859-LTST-0,153 10 C170YKT
1 220R | 0805 | R38 | 1099795 | WCR0805-220RFI | 0,019 10 | 0,020 | 10 | 0,020 10

THT; buzzer Ø9 or Ø12 mm
THT; encoder with switch | PEC16-2215F- S0024-ND

652-PEC16-
2215FS0024
THT; tactile switch, without
cap

THT; 40-pin socket; female; angled 90°

SSW-120-02-T-D-RA

| 200-SSW12002TDRA
THT; 16-pin IDC socket; male MC-254-16-00-ST-DIP | | 710-61201621621
| | 710-691322110005
LMJTAB881243M-L or THT; RJ45 socket with LMJ30288115CNL magnetics and LEDs; shielded | | Non-Stocked, Call for Quote
| | 815-ABLS-25.0M-F-T
XTAL016178-85SMX | | 449-LFXTAL016178R EEL

THT; Pluggable Terminal
Blocks; 3.5mm; 5-pin

771-BZX384-
B24115

THT; Connector Header; 2
position; 2.00mm
| 855-M22-2510246
2 2n2/1kV 0805 C1, C51 1855965 MC1210B222K102 0,496 5 CT | 490-12018-1-ND 0,502 10 | 710-0,121 10 885342208019
RC0805FR-0710KL | 311-10.0KCRCT-

# Qty Part name

42 4 DR1206-33R-4/8

43 1 LD-BZEN 0903
44 1 PEC16-2215F-S0024

45 1 TL1100CF160Q

46 1 EVQP7A01P
47 1 DS1024-2*20R0

48 1 DS1013-16SSIB1

49 | 1 | 691322110005

50 1

51 1 25 MHz

52 1 XTAL016178-85SMX

53 1 BZX384-B24.115

Not installed / optional
1 M22-2510246

2 2n2/1kV

5 N.C.
1 1n

3 TPD4E001DRLR

1 MMBT5551

2 10K

2 22R

1 330R
1 47K

1 220R

1 LTST-C170YKT

LMJTAB881243M-L or
LMJ30288115CNL
Code Part Number MOQ € | Code / Part Number Unit price MOQ € | THT SMD | Line Cost € Unit price

Best
Supplier

Lowest
unit price
€

Order
Qty
522-5670 CAY16-330J4LF | 0,004 50 | DR1206-33R-4/8 | 0,009 100 | 4 | RS | 0,004 € | 4 | 0,016
- | LD-BZEN-0903 | 0,498 | 1 | 1 | TME | 0,498 € | 1 | 0,498
- | - | 1 | Mouser | 1,220 € | 1 | 1,220
- | - | 1 | Digikey | 0,380 € | 1 | 0,380
178-9272 EVQP7A01P | 0,495 20 | EVQP7A01P | 0,143 | 5 | 1 | TME | 0,143 € | 1 | 0,143
154-8342 | 4,320 | 1 | DS1024-2*20R0 | 0,680 | 1 | 1 | TME | 0,680 € | 1 | 0,680
771-8357 61201621621 | 0,540 | 1 | DS1013-16SSIB1 | 0,130 | 5 | 1 | TME | 0,130 € | 1 | 0,130
824-6642 691322110005 | 0,960 | 1 | - | 1 | Farnell | 0,373 € | 1 | 0,373
- | LMJTAB881243M-L | 1,890 | 1 | 1 | TME | 1,890 € | 1 | 1,890
478-9628 | LFXTAL010595 | 0,764 | 1 | 25.00M-SMDHC49R | 0,443 | 2 | 1 | Farnell | 0,227 € | 1 | 0,227
148-4350 | LFXTAL016178 | 0,252 20 | 32.768K-85SMXR | 0,569 | 2 | 1 | RS | 0,252 € | 1 | 0,252
822-2217 BZT52C24S-7-F | 0,067 50 | BZX384-B24.115 | 0,035 20 | 1 | TME | 0,035 € | 1 | 0,035
8 | 129 | 35,11 €
681-3287 M22-2010205 | 0,215 10 | ZL303-02P | 0,012 50 | 1 | TME | 0,012 € | 1 | 0,012
723-6492 | 0,246 25 | 1206B222K102CT | 0,030 50 | 2 | TME | 0,030 € | 2 | 0,059
5 | Farnell | 0,000 € | 5 | 0,000
723-6408 | 0,031 100 | CL21C102JBCNNNC | 0,026 100 | 1 | TME | 0,026 € | 1 | 0,026
709-9066 | 0,552 | 5 | - | 3 | Farnell | 0,453 € | 3 | 1,359
545-0400 | 0,146 10 | MMBT5551 | 0,024 25 | 1 | TME | 0,024 € | 1 | 0,024
125-1189 CRG0805F10K | 0,002 100 | RC0805FR-0710K | 0,022 100 | 2 | RS | 0,002 € | 2 | 0,004
223-0332 CRG0805F220R | 0,024 50 | SMD0805-220R-1% | 0,022 100 | 2 | Farnell | 0,019 € | 2 | 0,038
1 | Farnell | 0,000 € | 3 | 0,000
679-1434 | 0,046 50 | SMD0805-47K-1% | 0,022 100 | 1 | Farnell | 0,010 € | 1 | 0,010
223-0332 CRG0805F220R | 0,018 50 | SMD0805-220R-1% | 0,022 100 | 1 | RS | 0,018 € | 2 | 0,036
692-0925 LTST-C170YKT | 0,206 50 | LTST-C170YKT | 0,055 10 | 1 | TME | 0,055 € | 1 | 0,055

SSW-120-02-F-D-RA

GRM31BR73A2
22KW01L

GRM2195C1H1
02JA01D
TPD4E001DRLR

MMBT5551LT1
G

CRCW080547K
0FKEA

# Reference designator Code Part Number MOQ Qty Part name Package € | Part Number Unit price MOQ € | Part Number Unit price MOQ Unit price €

| | 859-LTST-C170GKT
1 22-23-2061 THT; 6-pin, 0.1” socket; wire-X4 1462922 22-23-2061 0,229 100 board; male | WM4204-ND 0,341 10 | 538-22-23-2061 0,275 10
1 LTST-C170GKT | 0805 LED; Green | VBUS | 2322081 | 150080VS75000 | 0,171 | 5 | 160-1179-1-ND | 0,201 | 10 | 0,136 10

Related parts and accessories
1 4JWHT | SW2 button cap; red | - | - | 612-4J-WH | 0,126 | 1
1 A1031648 | | - | - | -
1 A1101007 | SW1 knob pointer; grey | - | - | -
1
1 15EDGKN-3.5-05P-14-Pluggable terminal block; 1792972 FMC 1,5/ 5-ST-3,5 3,360 1 1000AH 3.5mm; push-in, 5-pin | 277-6248-ND 5,060 1 | 651-1952296 5,060 1
| SQF-MSDM1-4G-21C-ND
1 CR2032 Battery; lithium; 3V; -Ø20x3.2mm | - | -
1 Micro SD card | 4 GB or 8 GB without adapter | - | 8,560 | 1 | 619-32328 | 6,980 | 1

Custom made components
1 | ALLPCB.com (Qty of 5) | -

All prices are net prices (without VAT)

All resistors are 1% 0805 and all capacitors are X7R 0805 if not otherwise specified.

SW1 knob with pointer;
Ø31x16mm; grey

ER-TFT043-8-3023,
resistive touchscreen

Buydisplay.com:
https://www.buydisplay.com/default/low-cost-4-3-inch-480x272-tft-lcd-display-w-optl-capacitive-touch-screen Display option:
RFE43BH-AIW-DNS

TFT LCD 4.3”; 480x272;
resistive

PCB 4-layer 139 x 70
mm

Please note that BOM does not contain ordering number for parts on reels or that which includes re-reeling fee (e.g. Farnell). Take also into account that total cost is higher because min. quantity (MOQ) for many parts is larger then what is needed for single unit.

# Qty Part name

1 LTST-C170GKT

1 22-23-2061

Related parts and accessories 1 4JWHT
1 A1031648

1 A1101007
1

1

1 Micro SD card

1 CR2032

Custom made components
1

ER-TFT043-8-3023,
resistive touchscreen
Display option:
RFE43BH-AIW-DNS
15EDGKN-3.5-05P-14-
1000AH

PCB 4-layer 139 x 70
mm
Code Part Number MOQ € | Code / Part Number Unit price MOQ € | THT SMD | Line Cost € Unit price

Best
Supplier

Lowest
unit price
€

Order
Qty
692-0900 LTST-C170GKT | 0,211 50 | LTST-C170GKT | 0,055 10 | 1 | TME | 0,055 € | 1 | 0,055
679-5593 22-23-2061 | 0,221 10 | MX-22-23-2061 | 0,124 | 5 | 1 | TME | 0,124 € | 1 | 0,124
- | | | - | | | Mouser | 0,126 € | 1 | 0,126
- | | | A1031648 | 1,963 | 1 | TME | 1,963 € | 1 | 1,963
- | | | A1101007 | 0,520 | 1 | TME | 0,520 € | 1 | 0,520
| | | | | | | 13,700 € | 1 | 13,700
- | | | RFE43BH-AIW-DNS | 21,140 | 1 | Farnell | | 0 | 0,000
176-1456 1952296 | 5,056 | 1 | | 1,271 | 1 | TME | 1,271 € | 1 | 1,271
124-1042 MS-C6-8G | 12,350 | 1 | M400-0080R11 | 3,810 | 1 | TME | 3,810 € | 1 | 3,810
186-3376 97384022 | 0,680 | 1 | BAT-CR2032/EG-B1 | 0,680 | 1 | RS | 0,680 € | 1 | 0,680
| | | | | | | | | 22,07 €
ALLPCB | 12,800 € | 1 | 12,800
| | | 12,80 €
| | Total | 69,98 €

Buydispla
y.com

15EDGKN-3.5-05P-14-
1000AH

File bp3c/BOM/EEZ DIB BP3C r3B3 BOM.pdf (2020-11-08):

EEZ DIB BP3C BOM (r3B3, 2020-11-08)
Project source code at https://github.com/eez-open/modular-psu
Farnell / Element14 # Qty Part name Package Reference designator Code Part Number Unit price MOQ € | Digi-Key Part Number Unit price MOQ € | Mouser Part Number Unit price MOQ €
| | 80-C0603C104M4R
VJ0805A102JXAC W1BC | | 710-885012007040
1 | 1 100n | 0603 | C1 | 2522597 | 0,073 10 | 490-4774-1-ND | 0,090 100 | 0,085 100
2 | 1 1n | 0805 | C2 | 2896470 | 0,044 10 | 732-7858-1-ND | 0,055 | 10 | 0,052 10
3 | 6 BAS316 | SOD-323 | D1, D2, D5, D6, D7, D8 | 8734275 | BAS316,115 | 0,193 | 5 | 1727-7370-1-ND | 0,120 | 1 | 771-BAS316-T/R | 0,179 | 1
4 | 1 TCA9534PWR | TSSOP-16 | IC1 | - | 296-40574-1-ND | 1,150 | 1 | 0,934 10
5 | 4 RT424005 | | K1, K2, K3, K4 | 1629052 | RT424005 | 2,640 | 1 | PB1998-ND | 3,620 | 1 | 655-RT424005 | 2,820 | 1
6 | 4 2N7002 | SOT-23 | Q1, Q2, Q3, Q4 | 1713825 | 2N7002K-7 | 0,148 | 5 | 0,126 | 10 | 0,113 10
7 | 4 100K | 0805 | R2, R4, R6, R8 | 2447551 | 0,010 10 | 0,024 | 10 | 0,040 10
8 | 1 10K | 0805 | R9 | 9237755 | 0,022 10 | 0,039 | 10 | 0,014 10
9 | 3 DS1021-2*10SF11 | X1, X2, X3 | - | 0,534 10
10 | 1 DS1022-2*20RF11 | X4 | - | 1,180 10
11 | 3 DS1023-2*14S21 | X5, X6, X7 | - | S7082-ND | 1,520 | 1 | SSQ-114-01-T-D | 1,960 10
12 | 4 MM3Z18VT1G | SOD-323 | ZD1, ZD2, ZD3, ZD4 | 1431193 | MM3Z18VT1G | 0,109 10 | 0,103 | 10 | 0,108 10
4 | 0805 | LED1, LED2, LED3, LED4
1 | 0805 | LED5
1 Red LED | 0805 | LED6
2 BAS316 | SOD-323 | D3, D4
1 N.C. | DO-214AA | D9
4 330R | 0805 | R1, R3, R5, R7
1 470R | 0805 | R10
1 1K5 | 0805 | R11
1 | -

C0603C104K4RAC
7081

595-
TCA9534PWR
THT; 8A relay
| T2N7002AKLMC T-ND | 757-T2N7002AKLM
| RMCF0805FT10 0KCT-ND | 71-CRCW0805100K FKEAC
RC0805FR-0710KL | 311-10.0KCRCT-ND | 603-RC0805FR-0710KL
| | 20LF
THT; 2x20-pin 0.1” header, right angled | | 649-68020-140HLF

MCWR08X1003FT
L
THT; 2x10-pin 0.1” header | 649-77313-802-

THT; 2x14-pin 0.1” receptacle
MM3Z18VT1GO
SCT-ND

863-
MM3Z18VT1G

Not installed
Green LED
Yellow LED

Custom made components
PCB 2-layer 110 x 90
mm

ALLPCB.com

All prices are net prices (without VAT)

Please note that BOM does not contain ordering number for parts on reels or that which includes re-reeling fee (e.g. Farnell). Take also into account that total cost is higher because min. quantity (MOQ) for many parts is larger then what is needed for single unit.

All resistors are 1% 0805 and all capacitors are X7R 0805 if not otherwise specified.

# Qty Part name | RS Components | TME | Price calculation for 1 set

Code Part Number Unit price MOQ € | Code / Part Number Unit price MOQ € | THT SMD

1 1 100n

2 1 1n

3 6 BAS316
4 1 TCA9534PWR

5 4 RT424005
6 4 2N7002

7 4 100K

8 1 10K

9 3 DS1021-2*10SF11

10 1 DS1022-2*20RF11

11 3 DS1023-2*14S21
12 4 MM3Z18VT1G

4
1
1 Red LED
2 BAS316
1 N.C.
4 330R
1 470R
1 1K5

1

Not installed
Green LED
Yellow LED

Custom made components
PCB 2-layer 110 x 90
mm
264-4630 | 0,035 25 | CL10B104KA8NNNC | 0,098 100 | 1 | RS | 0,035 € | 1 | 0,035
723-6408 | 0,031 100 | CL21C102JBCNNNC | 0,026 100 | 1 | TME | 0,026 € | 1 | 0,026
397-2914 BAS316,115 | 0,122 50 | BAS316,115 | 0,026 25 | 6 | TME | 0,026 € | 6 | 0,159
814-3997 TCA9535PWR | 1,071 10 | - | 1 | Mouser | 0,934 € | 1 | 0,934
- | RT424005 | 1,150 | 5 | 4 | TME | 1,150 € | 4 | 4,600
671-0312 2N7002 | 1,250 20 | 2N7002LT1G | 0,019 25 | 4 | TME | 0,019 € | 4 | 0,077
223-0691 CRG0805F100K | 0,028 50 | SMD0805-100K-1% | 0,015 100 | 4 | Farnell | 0,010 € | 4 | 0,039
125-1189 CRG0805F10K | 0,006 100 | RC0805FR-0710K | 0,022 100 | 1 | RS | 0,006 € | 1 | 0,006
- | DS1021-2*10SF11 | 0,165 10 | 3 | TME | 0,165 € | 3 | 0,494
- | DS1022-2*20RF11 | 0,282 | 2 | 1 | TME | 0,282 € | 1 | 0,282
- | DS1023-2*14S21 | 0,295 | 2 | 3 | TME | 0,295 € | 3 | 0,885
802-4574 MM3Z18VT1G | 0,038 200 | MM3Z18VT1G | 0,025 25 | 4 | TME | 0,025 € | 4 | 0,101
11 | 22 | 7,64 €
4 | Farnell | 0,000 € | 4 | 0,000
1 | Farnell | 0,000 € | 1 | 0,000
1 | Farnell | 0,000 € | 1 | 0,000
2 | Farnell | 0,000 € | 2 | 0,000
| Farnell | 0,000 € | 1 | 0,000
4 | Farnell | 0,000 € | 4 | 0,000
1 | Farnell | 0,000 € | 1 | 0,000
1 | Farnell | 0,000 € | 1 | 0,000
ALLPCB | 5,600 € | 1 | 5,600
| | | 5,60 €

13,24 €

Best
Supplier

Lowest
unit price
€

Order
Qty Line Cost €

C0603C104K4R
ACTU
GRM2195C1H1
02JA01D

Total

Mouser
MOQ | MOQ | MOQ
Farnell / Element14 | Digi-Key
Qty | Part name | Package | Reference designator | Code | Part Number | Unit price €
Part Number | Unit price
€

Part Number Unit price
€

# Qty Part name | RS Components | TME | Price calculation for 1 set

Code Part Number Unit price MOQ € | Code / Part Number Unit price MOQ € | THT SMD

Best
Supplier

Lowest
unit price
€

Order
Qty Line Cost €

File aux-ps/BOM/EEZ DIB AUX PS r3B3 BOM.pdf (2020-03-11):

EEZ DIB AUX-PS BOM (r3B3, 2020-03-11) Project source code at https://github.com/eez-open/modular-psu
Farnell / Element14 # Unit price Qty Part name Package Reference designator Code Part Number MOQ € | Digi-Key Unit price Part Number MOQ € | Mouser Unit price Part Number MOQ €
| | B32921C3473K
VJ0805Y105KXXT W1BC | | 603-CC805MKX7R7B B105
| | 667-EEE-FK1V470P
C0603C104K4RAC 7081 | | 80-C0603C104M4R
| | 841-PMEG4010EGW X
| BD00FC0WFP-E2CT-ND | 755-BD00FC0WFP-E2
| MAX31760AEE+-ND | 700-MAX31760AEE+

THT; AC inlet

1 | 2 47n/400V (X2) | C1, C2 | 2728564 | B32921C3473K000 | 0.452 | 1 | 399-11478-ND | 0.319 | 10 | 0.264 10
2 | 3 1u | 0805 | C3, C7, C8 | 2896566 | 0.084 | 5 | 587-1283-1-ND | 0.090 | 10 | 0.062 10
3 | 3 EEEFK1V470P | C6, C12, C13 | 9695850 | EEEFK1V470P | 0.344 | 1 | PCE3842CT-ND | 0.312 | 10 | 0.238 10
4 | 2 100n | 0603 | C9, C10 | 2522597 | 0.011 10 | 490-4774-1-ND | 0.029 100 | 0.007 100
5 | 1 SKL14 | SOD-123 | D1 | 2760412 | PMEG4010EGWX | 0.204 | 5 | 1727-7335-1-ND | 0.243 | 10 | 0.188 10
6 | 1 BD00FC0WFP-E2 | TO-252-5 | IC1 | 3010961 | BD00FC0WFP-E2 | 0.736 | 1 | 0.830 | 1 | 0.786 | 1
7 | 1 MAX31760AEE+ | QSOP-16 | IC2 | 2528719 | MAX31760AEE+ | 1.210 | 1 | 2.400 | 1 | 1.210 | 1
8 | 1 PF0030/PC | J1 | 428784 | PF0030/PC | 3.700 | 1 | 708-1914-ND | 5.730 | 1 | 161-PF0030/PC | 6.050 | 1
9 | 2 1-726388-2 | J2, J3 | 2308760 | 1-726388-2 | 0.167 100 | A121493-ND | 0.178 | 10 | 571-726388-2 | 0.133 10
10 | 1 SWEB 8094 AU/GN | J4 | - | - | -
11 | 2 VLS6045AF-3R3N | 6.7x6.7x2.8mm | L1, L2 | 1741325 | 1.940 | 5 | 0.510 | 1 | 0.510 | 1
12 | 1 OSY5LU3E34X-3F1A | LED1 | - | - | -
13 | 1 B57236S0200M | NTC1 | 9751890 | B57236S0200M | 0.872 | 1 | 495-3047-ND | 0.780 | 1 | 0.757 | 1
14 | 1 MOC3052 | SMD; SDIP-6 | OK1 | 2453236 | MOC3052SM | 0.668 | 1 | MOC3052SM-ND | 1.030 | 1 | 0.774 | 1
15 | 1 MOC3062 | SMD; SDIP-6 | OK2 | 2322554 | MOC3062SR2VM | 0.900 | 1 | MOC3062SM-ND | 1.270 | 1 | 0.944 | 1
16 | 2 BTA26-600 | Q1, Q2 | 1057286 | BTA26-600BRG | 3.000 | 1 | 497-2427-5-ND | 3.370 | 1 | 511-BTA26-600B | 3.360 | 1
17 | 3 2N7002 | SOT-23 | Q3, Q4, Q5 | 1713823 | 2N7002-7-F | 0.118 | 5 | 0.150 | 1 | 0.128 | 1
18 | 2 39K | 0805 | R11, R23 | 2447646 | 0.010 10 | 0.024 | 10 | 0.017 10
19 | 2 3K3 | 0805 | R12, R13 | 2447651 | 0.010 10 | A129755CT-ND | 0.045 | 10
20 | 5 1K | 0805 | R1, R3, R14, R15, R18 | 1099800 | WCR0805-1K0FI | 0.019 10 | 0.039 | 10 | 0.015 10
21 | 1 10R | 0805 | R17 | 9236643 | 0.050 10 | 0.071 | 10 | 0.034 10
22 | 2 270R | 0805 | R2, R9 | 2073716 | MCMR08X271 JTL | 0.009 10 | 0.025 | 10 | 0.013 10
23 | 1 470R | 0805 | R22 | 1099798 | WCR0805-470RFI | 0.019 10 | 0.039 | 10 | 0.041 10
24 | 4 330R/2W | 2512 | R4, R6, R7, R8 | 1265196 | 3520330RJT | 0.105 10 | 0.227 | 10 | 279-3520330RJT | 0.073 10
25 | 4 4K7 | 0805 | R5, R10, R16, R19 | 2861530 | CRGCQ0805F4K7 | 0.009 10 | 0.090 | 1 | 0.026 10
THT; 13x5mm; RM10 | 871-

THT; PCB terminal; 4.8mm
THT; 4mm PE connector
| 445-180834-1-ND | 810-VLS6045AF-3R3N

THT; LED 3mm; yellow

| | B57236S200M
| | 512-MOC3052SM
| | 512-MOC3062SM

THT; triac 26 A, 600 V
| 2N7002LT1GOS CT-ND | 863-2N7002LT1G
MCWR08X3902FT L | RMCF0805FT39 K0CT-ND | 652-CR0805FX-3902ELF

IHLP2020CZER3R
3M11
THT; NTC; 11.5 X 6 mm | 871-

MCWR08X3301FT
L
RC0805FR-071KL | 603-RC0805FR-071KL
311-10.0CRCT-ND | 603-RC1206FR-0710RL
RMCF0805FT27 0RCT-ND | 652-CR0805FX-2700ELF
311-470CRCT-ND | 71-CRCW0805470R FKEB

RMCF2512JT330 RCT-ND

RC1206FR-0710RL

311-4.70KCRCT-ND

603-RC0805FR-074K7L

# Qty Part name | RS Components | TME | Price calculation for 1 set

Unit price Code Part Number MOQ € | Unit price Code / Part Number MOQ € | THT SMD | | Line Cost €

1 2 47n/400V (X2)

2 3 1u

3 3 EEEFK1V470P

4 2 100n

5 1 SKL14

6 1 BD00FC0WFP-E2

7 1 MAX31760AEE+

8 1 PF0030/PC
9 2 1-726388-2
10 1 SWEB 8094 AU/GN
11 2 VLS6045AF-3R3N

12 1 OSY5LU3E34X-3F1A
13 1 B57236S0200M

14 1 MOC3052

15 1 MOC3062

16 2 BTA26-600
17 3 2N7002

18 2 39K

19 2 3K3

20 5 1K

21 1 10R

22 2 270R

23 1 470R

24 4 330R/2W

25 4 4K7

882-9483 | 0.272 25 | MKP-X2-47NR10/310 | 0.077 10 | 2 | TME | 0.077 € | 2 | 0.154
451-5770 | 0.028 25 | CL21B105KOFNNNE | 0.010 100 | 3 | TME | 0.010 € | 3 | 0.031
537-0657 EEEFK1V470P | 0.394 | 5 | EEEFK1V470P | 0.130 | 5 | 3 | TME | 0.130 € | 3 | 0.390
393-6952 | 0.069 25 | CL10B104KA8NNNC | 0.098 100 | 2 | Mouser | 0.007 € | 2 | 0.014
153-0632 | 0.078 100 | SKL14-DIO | 0.053 10 | 1 | TME | 0.053 € | 1 | 0.053
184-7499 | 0.876 10 | - | 1 | Farnell | 0.736 € | 1 | 0.736
- | | | - | | | 1 | Farnell | 1.210 € | 1 | 1.210
261-5834 PF0030/PC | 3.700 | 1 | PF0030/PC | 2.360 | 1 | 1 | TME | 2.360 € | 1 | 2.360
680-5772 1-726388-2 | 0.055 100 | 61-3162-11/0030 | 0.033 50 | 2 | TME | 0.033 € | 2 | 0.066
- | | | SWEB 8094 AU/GN | 2.130 | 1 | 1 | TME | 2.130 € | 1 | 2.130
- | | | HPI0630-3R3 | 0.335 | 1 | 2 | TME | 0.335 € | 2 | 0.670
- | | | OSY5LU3E34X-3F1A | 0.115 | 5 | 1 | TME | 0.115 € | 1 | 0.115
- | | | B57236S0200 | 0.370 | 5 | 1 | TME | 0.370 € | 1 | 0.370
761-3690 MOC3052SM | 1.030 | 5 | MOC3052S | 0.288 | 2 | 1 | TME | 0.288 € | 1 | 0.288
806-6064 MOC3062SM | 0.786 10 | MOC3062XSM | 0.500 | 1 | 1 | TME | 0.500 € | 1 | 0.500
714-0515 BTA26-600BRG | 3.710 | 1 | BTA26-600BRG | 1.290 | 1 | 2 | TME | 1.290 € | 2 | 2.580
545-0012 2N7002LT1G | 0.126 50 | 2N7002LT1G | 0.025 25 | 3 | TME | 0.025 € | 3 | 0.074
679-1336 | 0.038 50 | 0805S8J0393T5E | 0.013 100 | 2 | Farnell | 0.010 € | 2 | 0.019
223-0499 CRG0805F3K3 | 0.027 50 | 805S8F3301T5E | 0.015 100 | 2 | Farnell | 0.010 € | 2 | 0.019
223-0427 CRG0805F1K0 | 0.017 50 | RC0805FR-071K | 0.022 100 | 5 | Mouser | 0.015 € | 5 | 0.075
740-9085 | 0.036 50 | 0.031 100 | 1 | TME | 0.031 € | 1 | 0.031
223-0348 CRG0805F270R | 0.025 50 | 0805S8F2700T5E | 0.023 100 | 2 | Farnell | 0.009 € | 2 | 0.018
223-0376 CRG0805F470R | 0.021 50 | RC0805FR-07470R | 0.022 100 | 1 | Farnell | 0.019 € | 2 | 0.038
755-1224 3521330RFT | 0.281 10 | WF25P-330R-5% | 0.072 50 | 4 | TME | 0.072 € | 4 | 0.286
223-0528 CRG0805F4K7 | 0.010 50 | 0805S8F4701T5E | 0.022 100 | 4 | Farnell | 0.009 € | 4 | 0.034

Best
Supplier

Lowest
unit price
€

Order
Qty

B32921C3473M
000
C0805C105K4R
ACTU

VJ0603Y104KXJ
AT
PMEG4010EGW
X

BD00FC0WFP-E2

CRCW080539K
0FKEA

CR1206-FX-10R0ELF

CRCW120610R0FKTA
BC

# Qty Part name Package Reference designator Code Part Number MOQ € | Part Number Unit price MOQ € | Part Number Unit price MOQ Unit price €

THT; Surge arrester

| | DF62J12S2AHQ A

IRM-10-5 THT; AC/DC Power Module IRM-10-5 5V/2A 20W; 85-264Vin

26 | 1 CG2-470L | SAR1 | 1846854 | 2027-47-BLF | 1.110 | 1 | 2027-47-BLF-ND | 1.200 | 1 | 652-2027-47-BLF | 1.160 | 1
27 | 1 DF62J12S2AHQA | SW1 | 2435277 | DF62J12S2AHQA | 4.680 | 1 | CKN2062-ND | 4.520 | 1 | | 5.310 | 1
28 | 1 | TR1 | 2815498 | | 8.440 | 1 | 1866-3032-ND | 8.220 | 1 | 709-IRM10-5 | 8.520 | 1
29 | 1 IRM-10-12 | TR2 | 2815494 | IRM-10-12 | 8.440 | 1 | 1866-3028-ND | 8.220 | 1 | 709-IRM10-12 | 8.520 | 1
30 | 2 | VAR1, VAR2 | 2291831 | ERZE11A431 | 0.678 | 1 | P16688-ND | 0.460 | 1 | | 0.468 | 1
31 | 1 39-28-1063 | X1 | 9732101 | 39-28-1063 | 0.688 | 1 | WM3802-ND | 0.860 | 1 | 538-39-28-1063 | 0.760 | 1
32 | 1 39-30-1039 | X2 | 1829076 | 39-30-1039 | 0.585 | 1 | WM18442-ND | 0.570 | 1 | 538-39-30-1039 | 0.430 | 1
33 | 1 | X3 | 2843530 | | 0.220 | 1 | ED10523-ND | 0.350 | 1 | | 0.540 | 1
34 | 1 22-27-2031 | X4; fan connector | 9731156 | 22-27-2031 | 0.212 100 | WM4112-ND | 0.330 | 1 | 538-22-27-2031 | 0.323 | 1
35 | 2 1.5KE400CA | THT; TVS bidirectional | ZD1, ZD2 | 2341650 | 1.5KE400CARL | 0.722 | 1 | 0.550 | 1 | 0.536 | 1

Not installed
1 N.C. | 0805 | C4, C5
1 N.C. | 0603 | C11
2 N.C. | 0805 | R20, R21
3 Test points | TP1 | -
1 22-27-2031 | X5; fan connector | 9731156 | 22-27-2031 | 0.212 100 | WM4112-ND | 0.330 | 1 | 538-22-27-2031 | 0.323 | 1
2 N.C. | SOD-123 | ZD3, ZD4
1 3248.1001 | Enclosure handle

Related parts and accessories
1 FC16150-S | 16-pin IDC cable 15cm | - | 1.170 | 1 | -

4 FSP-2

1 FG-08 | Finger guard; 80x80mm
1 HS-142-25 | THT; SK129-PAD | KK1 | 1319810 | SK 129 25,4 STS | 2.460 | 1 | - | -
1 22-01-3037 | 3-pin receptacle for X4 | 1462838 | 22-01-3037 | 0.093 100 | WM2001-ND | 0.170 | 1 | 538-22-01-3037 | 0.166 | 1
3 08-50-0114 | Pins for X4 | 1462641 | 08-50-0114 | 0.073 100 | WM1114-ND | 0.141 | 10 | 538-08-50-0114 | 0.100 10
1 39-01-4030 | Receptacle for X2 | 9963480 | 39-01-4030 | 0.204 10 | WM18434-ND | 0.260 | 1 | 538-39-01-4030 | 0.272 | 1
1 39-01-2060 | Receptacle for X1 | 151868 | 39-01-2060 | 0.277 100 | WM3702-ND | 0.330 | 1 | 538-39-01-2060 | 0.340 | 1
9 39-00-0078 | Pins for X1, X2 | 9732675 | 39-00-0078 | 0.094 100 | WM9154-ND | 0.137 | 10 | 538-39-00-0078 | 0.112 10
3 ST-003/2 | - | A122464-ND | 0.131 | 10 | 571-60196-3 | 0.132 10
THT; PCB AC switch | 611-

THT; AC/DC Power Module
12V/0.85A 10W; 85-264Vin
ERZE14A431 or
V275LA20AP
THT; Varistor RM7.5 | 667-ERZ- E11A431

THT; Mini-Fit Jr.; 4.2mm, 6-pin
THT; Mini-Fit Jr.; 4.2mm, 3-pin
| 710-61201621621

THT; 3-pin 0.1”

DS1013-16SSIB1 | THT; 16-pin IDC socket; male | MC-254-16-00-ST- DIP

1.5KE400CA-TPMSCT-ND

833-
1.5KE400CA-TP

THT; 3-pin 0.1”

H3CCS-1606G-ND

1 MF80251V3-1000U-G99 80x80x25mm, 12Vdc fan

Fastener for fans and
protections

4.8mm terminal; flat for J2, J3, J4

# Qty Part name

26 1 CG2-470L

27 1 DF62J12S2AHQA

28 1

29 1 IRM-10-12

30 2

31 1 39-28-1063
32 1 39-30-1039
33 1

34 1 22-27-2031
35 2 1.5KE400CA

Not installed
1 N.C.
1 N.C.
2 N.C.
3 Test points
1 22-27-2031
2 N.C.
1 3248.1001

Related parts and accessories 1 FC16150-S

1 MF80251V3-1000U-G99

4 FSP-2

1 FG-08
1 HS-142-25

1 22-01-3037
3 08-50-0114
1 39-01-4030
1 39-01-2060
9 39-00-0078
3 ST-003/2

IRM-10-5

ERZE14A431 or
V275LA20AP

DS1013-16SSIB1

Code Part Number MOQ € | Code / Part Number Unit price MOQ € | THT SMD | Line Cost € Unit price

Best
Supplier

Lowest
unit price
€

Order
Qty
878-3652 CG2-470L | 1.943 10 | CG2-470L | 1.480 | 1 | 1 | Farnell | 1.110 € | 1 | 1.110
154-3601 | 4.920 | 1 | DF62J12S2AHQA | 3.869 | 1 | 1 | TME | 3.869 € | 1 | 3.869
135-8929 | 8.440 | 1 | | 6.100 | 1 | 1 | TME | 6.100 € | 1 | 6.100
135-8930 IRM-10-12 | 8.440 | 1 | IRM-10-12 | 6.100 | 1 | 1 | TME | 6.100 € | 1 | 6.100
785-8904 ERZE11A431 | 0.251 25 | V275LA20AP | 0.201 | 5 | 2 | TME | 0.201 € | 2 | 0.402
484-1906 39-28-1063 | 0.696 | 1 | MX-5566-06A | 0.272 | 2 | 1 | TME | 0.272 € | 1 | 0.272
670-5751 39-30-1039 | 0.584 | 5 | MX-5566-03A3 | 0.548 | 1 | 1 | Mouser | 0.430 € | 1 | 0.430
771-8357 61201621621 | 0.540 | 1 | DS1013-16SSIB | 0.130 | 5 | 1 | TME | 0.130 € | 1 | 0.130
483-8477 22-27-2031 | 0.226 10 | MX-6410-03A | 0.112 13 | 1 | TME | 0.112 € | 1 | 0.112
486-4381 1.5KE400CA | 0.932 | 5 | 1.5KE400CA | 0.316 | 3 | 2 | TME | 0.316 € | 2 | 0.632
22 | 39 | 31.42 €
1 | Farnell | 0.000 € | 1 | 0.000
1 | Farnell | 0.000 € | 1 | 0.000
2 | Farnell | 0.000 € | 2 | 0.000
| | TEST-5 | 0.082 10 | 3 | TME | 0.082 € | 3 | 0.246
483-8477 22-27-2031 | 0.226 10 | MX-6410-03A | 0.112 13 | 1 | TME | 0.112 € | 1 | 0.112
2 | Farnell | 0.000 € | 2 | 0.000
MR-3248.1001 | 4.350 | 1 | TME | 4.350 € | 1 | 4.350
- | | | FC16150-S | 1.310 | 1 | Digikey | 1.170 € | 1 | 1.170
| | | | 2.040 | 1 | TME | 2.040 € | 1 | 2.040
| | | FSP-2 | 0.142 | 5 | TME | 0.142 € | 4 | 0.566
| | | FG-08 | 0.524 | 1 | TME | 0.524 € | 1 | 0.524
189-8139 | 2.820 | 1 | HS-142-25 | 1.350 | 1 | TME | 1.350 € | 1 | 1.350
679-5375 22-01-3037 | 0.086 10 | MX-22-01-3037 | 0.080 10 | TME | 0.080 € | 1 | 0.080
172-9178 08-50-0114 | 0.075 100 | MX-0850-0114 | 0.058 10 | TME | 0.058 € | 3 | 0.173
510-9685 39-01-4030 | | 5 | MX-5557-03R2 | 0.159 | 5 | TME | 0.159 € | 1 | 0.159
484-1760 39-01-2060 | 0.280 | 5 | MX-5557-06R | 0.104 | 5 | TME | 0.104 € | 1 | 0.104
215-5887 39-00-0078 | 0.154 100 | MX-5556-T3L | 0.082 10 | TME | 0.082 € | 9 | 0.735
719-6987 60196-3 | 0.096 100 | ST-003/2 | 0.030 20 | TME | 0.030 € | 3 | 0.089

DF62J12S2AHQ
A
IRM-10-5 | IRM-10-5

MF80251V3-1000U-G99

SK129-25,4-
STS-220

Qty | Part name | Package | Reference designator | Code | Part Number | MOQ | Part Number | MOQ | Part Number | MOQ Unit price
€

Unit price
€

Unit price
€
1 M3X8/D7985B | - | - | -
1 B3/BN789 | - | - | -
1 B3/BN117 | Nut; hexagonal; M3; H: 2.4mm

Custom made components
1 | ALLPCB.com | -

All prices are net prices (without VAT)

All resistors are 1% 0805 and all capacitors are X7R 0805 if not otherwise specified.

Screw; M3x8; cheese head;
black; Phillips for heatsink Washer; externally serrated; M3; D=6mm; h=0.4mm

PCB 2-layer 230.5 x 60
mm

Please note that BOM does not contain ordering number for parts on reels or that which includes re-reeling fee (e.g. Farnell). Take also into account that total cost is higher because min. quantity (MOQ) for many parts is larger then what is needed for single unit.

# Qty Part name

1 M3X8/D7985B

1 B3/BN789

1 B3/BN117

Custom made components
1 PCB 2-layer 230.5 x 60
mm
Code Part Number MOQ € | Code / Part Number Unit price MOQ € | THT SMD | Line Cost € Unit price

Best
Supplier

Lowest
unit price
€

Order
Qty
- | M3X8/D7985B | 0.018 100 | TME | 0.018 € | 1 | 0.018
- | B3/BN789 | 0.010 100 | TME | 0.010 € | 1 | 0.010
| B3/BN117 | 0.005 100 | TME | 0.005 € | 1 | 0.005
| | | | | | 7.02 €
ALLPCB | 6.200 € | 1 | 6.200
| | | 6.20 €
| | Total | 44.64 €

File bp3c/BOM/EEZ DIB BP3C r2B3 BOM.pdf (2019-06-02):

EEZ DIB BP3C BOM (r2B3, 2019-06-02)
Project source code at https://github.com/eez-open/modular-psu
Farnell / Element14 # Qty Part name Package Reference designator Code Part Number Unit price MOQ € | Digi-Key Part Number Unit price MOQ € | Mouser Part Number Unit price MOQ €
| | 80-C0603C104M4R
1 | 1 100n | C0603 | C1 | 2522597 | 0,073 10 | 490-4774-1-ND | 0,090 100 | 0,085 100
2 | 4 BAS316 | SOD-323 | D1, D2, D5, D6 | 8734275 | BAS316,115 | 0,193 | 5 | 1727-7370-1-ND | 0,120 | 1 | 771-BAS316-T/R | 0,179 | 1
3 | 1 PCA9536D | SOIC-8 | IC1 | 2776152 | PCA9536D,118 | 0,946 | 1 | 568-1835-1-ND | 1,010 | 1 | | 0,952 | 1
4 | 4 RT424005 | | | 1629052 | RT424005 | 2,640 | 1 | PB1998-ND | 3,620 | 1 | 655-RT424005 | 2,820 | 1
5 | 4 2N7002 | SOT-23 | Q1, Q2, Q3, Q4 | 1713825 | 2N7002K-7 | 0,148 | 5 | 0,126 | 10 | 0,113 10
6 | 4 100K | 0805 | R2, R4, R6, R8 | 2447551 | 0,010 10 | 0,024 | 10 | 0,040 10
7 | 3 ZL202-20G | | X1, X2, X3
8 | 1 ZL212-40KG | | X4
9 | 3 TSW-113-07-F-D | | X5, X6, X7
10 | 4 SMAJ18A | DO-214AC | ZD1, ZD2, ZD3, ZD4 | 2677644 | SMAJ18A | 0,108 | 5 | | 0,350 | 1 | 652-SMAJ18A-Q | 0,384 | 1
6 LED | 0805
2 BAS316 | SOD-323 | D4, D5
3 330R | 0805 | R1, R3, R5
2 470R | 0805 | R7
3 1K5 | 0805 | R8
1 | -

C0603C104K4RAC
7081
| 771-PCA9536D-T

THT; 8A relay K_COMM, K_PAR, K_SER, K_SPLIT

| T2N7002AKLMC T-ND | 757-T2N7002AKLM
MCWR08X1003FT L | RMCF0805FT10 0KCT-ND | 71-CRCW0805100K FKEAC

THT; 2x10-pin 0.1” header
THT; 2x20-pin 0.1” header, angled
THT; 2x13-pin 0.1” receptacle

SMAJ18A-FDICT-ND

Not installed
+5V, +12V, PAR, SER,
COMM, SPLIT

Custom made components
PCB 2-layer 110 x 85
mm

ALLPCB.com

All prices are net prices (without VAT)

Please note that BOM does not contain ordering number for parts on reels or that which includes re-reeling fee (e.g. Farnell). Take also into account that total cost is higher because min. quantity (MOQ) for many parts is larger then what is needed for single unit.

All resistors are 1% 0805 and all capacitors are X7R 0805 if not otherwise specified.

EEZ DIB BP3C BOM (r2B3, 2019-06-02)
Project source code at https://github.com/eez-open/modular-psu
# Qty Part name | RS Components | TME | Price calculation for 1 set

Code Part Number Unit price MOQ € | Code / Part Number Unit price MOQ € | THT SMD

1 1 100n

2 4 BAS316

3 1 PCA9536D

4 4 RT424005

5 4 2N7002

6 4 100K

7 3 ZL202-20G
8 1 ZL212-40KG

9 3 TSW-113-07-F-D

10 4 SMAJ18A

6 LED

2 BAS316
3 330R
2 470R
3 1K5

1

Not installed
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

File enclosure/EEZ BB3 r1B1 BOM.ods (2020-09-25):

 |  |  |  |  | Farnell / Element14 |  |  |  | Digi-Key |  |  | Mouser |  |  | RS Components |  |  |  | TME |  |  |  |  | Price calculation for 1 set
# | Qty | Part name | Package / Note | Reference designator | Code | Part Number | Unit price € | MOQ | Part Number | Unit price € | MOQ | Part Number | Unit price € | MOQ | Code | Part Number | Unit price € | MOQ | Code / Part Number | Unit price € | MOQ | THT | SMD | Best Supplier | Lowest unit price € | Order Qty | Line Cost €
1 | 1 | 22-01-3037 | 3-pin 0.1” receptacle |  | 1462838 | 22-01-3037 | 0,175 | 1 | WM2001-ND | 0,170 | 1 | 538-22-01-3037 | 0,166 | 1 | 679-5375 | 22-01-3037 | 0,098 | 10 | MX-22-01-3037 | 0,080 | 10 |  |  | TME | 0,080 € | 1 | 0,080
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

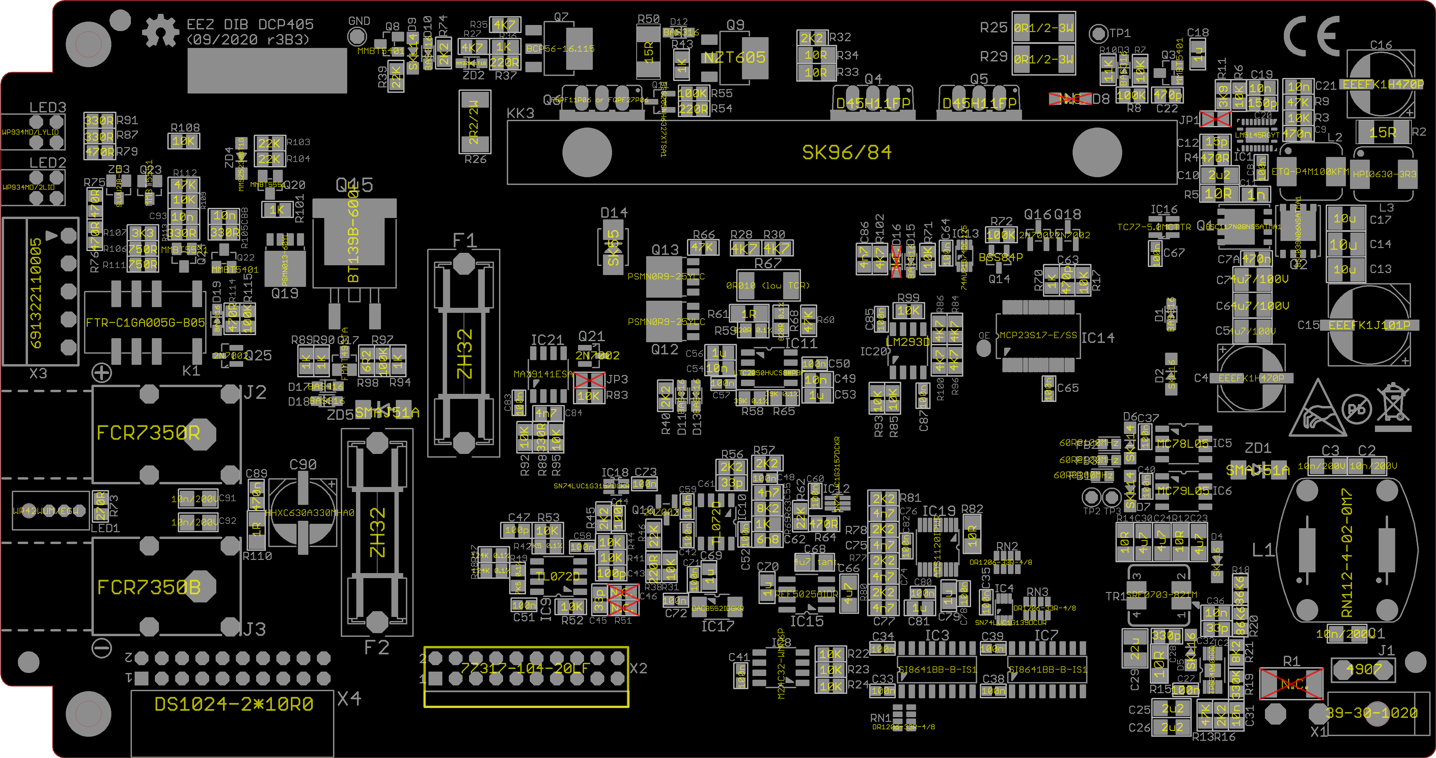
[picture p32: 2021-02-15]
dcp405/Images/EEZ_DIB_DCP405_PCB_parts.png

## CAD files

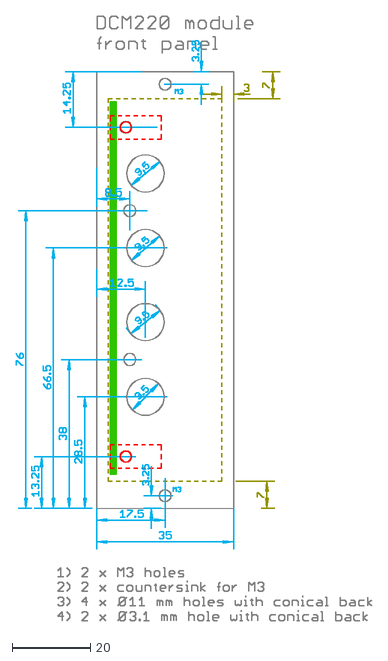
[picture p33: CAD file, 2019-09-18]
dcm220/Front panel/DIB chassis DCM220 panel.dxf
90.8 x 154.2

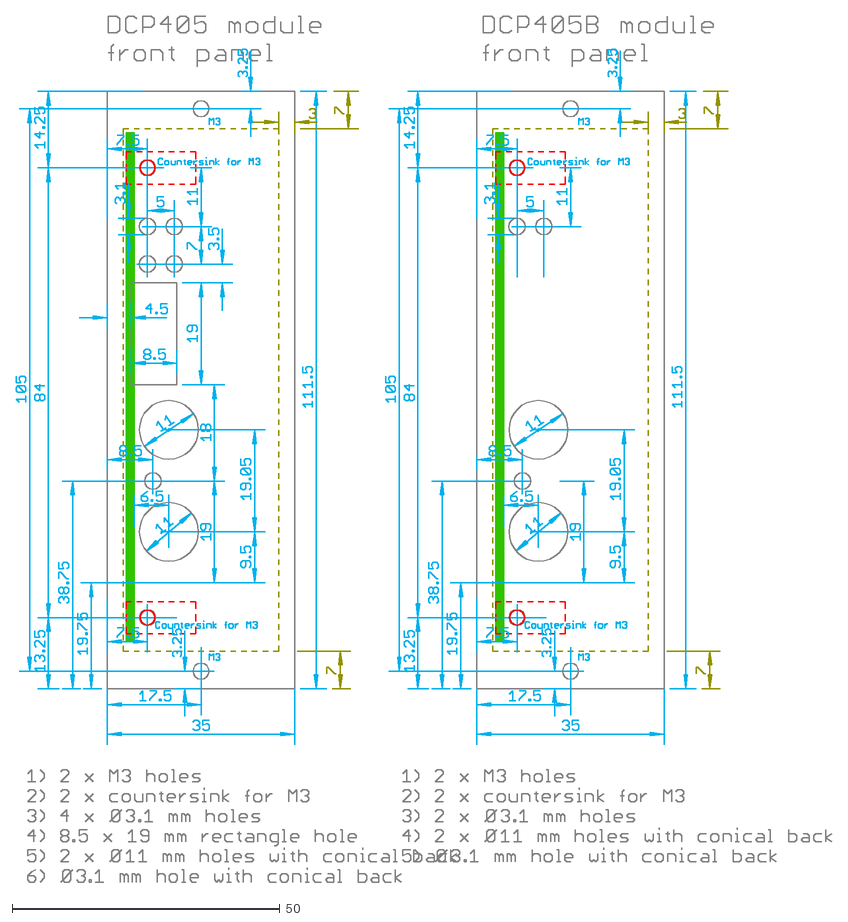
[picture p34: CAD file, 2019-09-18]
dcp405/Front panel/DCP405(B) front panel.dxf
152.3 x 161.7

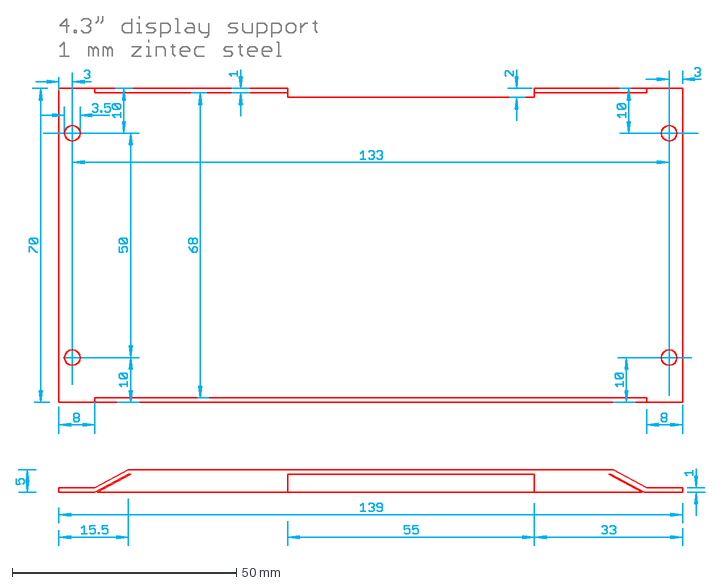
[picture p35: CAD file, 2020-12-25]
enclosure/EEZ BB3 chassis display support r2B1.dxf
153.6 x 118.0 mm

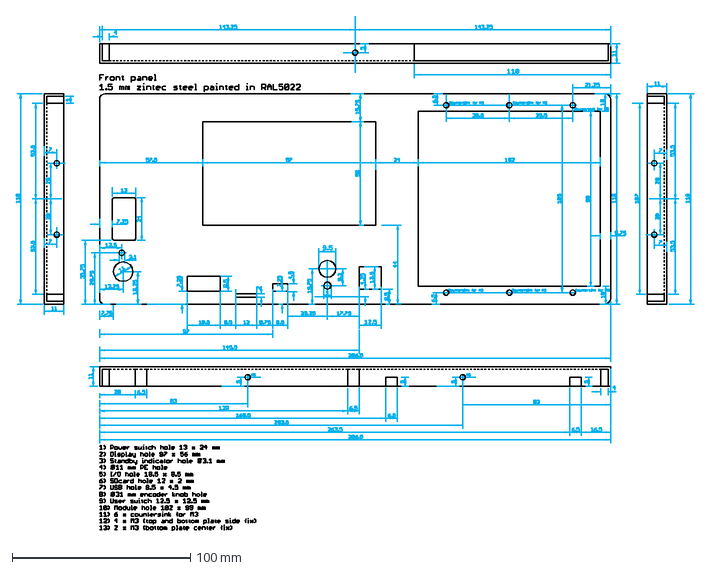
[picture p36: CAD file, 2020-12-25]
enclosure/EEZ BB3 chassis front panel r2B1.dxf
380.0 x 288.6 mm

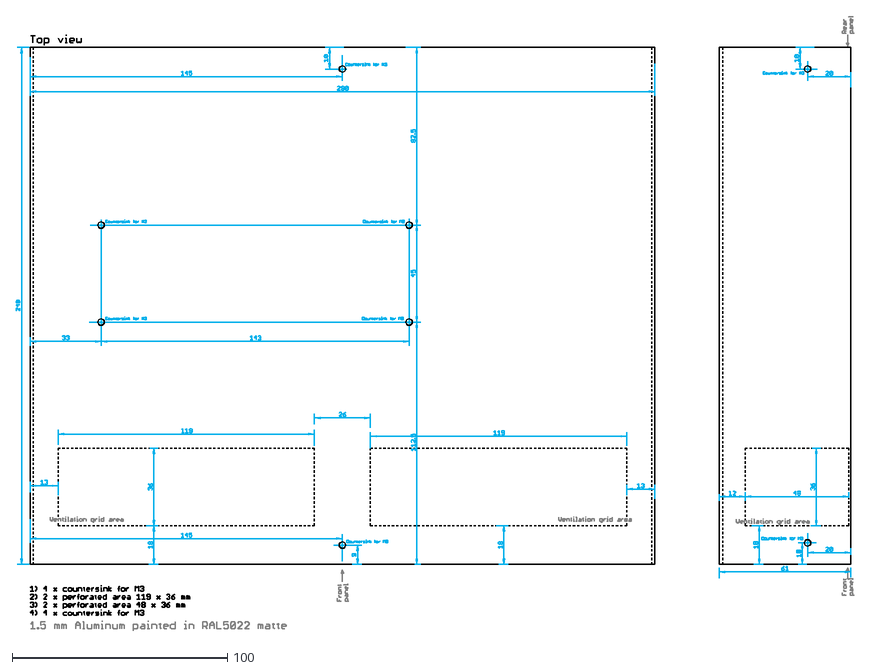
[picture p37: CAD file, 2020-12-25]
enclosure/EEZ BB3 chassis top plate r2B1.dxf
389.1 x 285.4

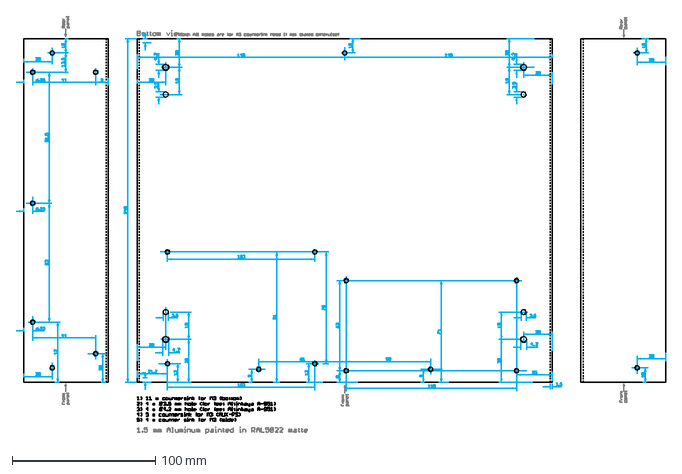
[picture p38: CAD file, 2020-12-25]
enclosure/EEZ BB3 chassis bottom plate r2B1.dxf
453.7 x 291.4 mm

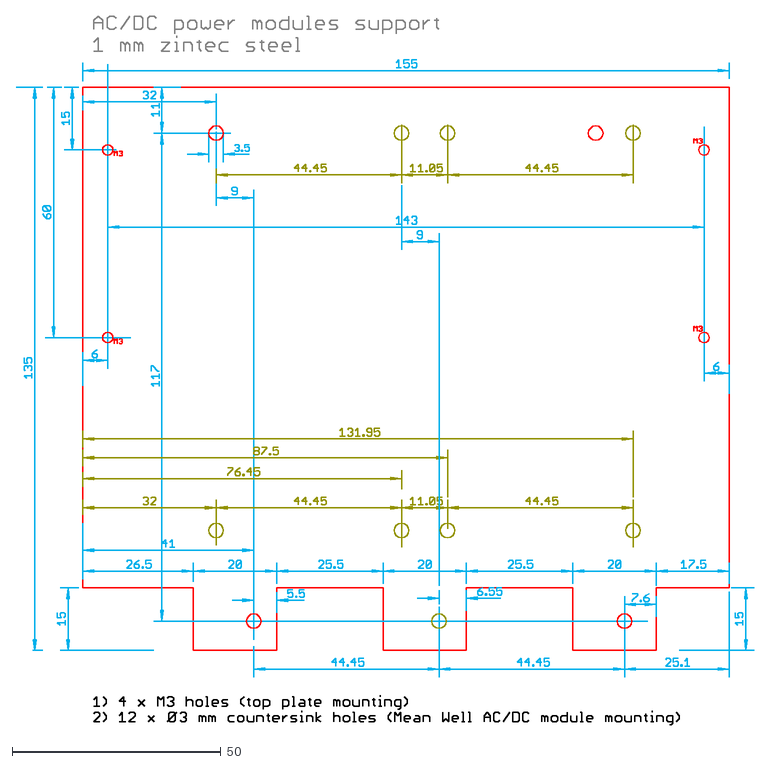
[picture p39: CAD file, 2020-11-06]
enclosure/BB3 chassis Mean Well support 2.0.dxf
176.9 x 169.9

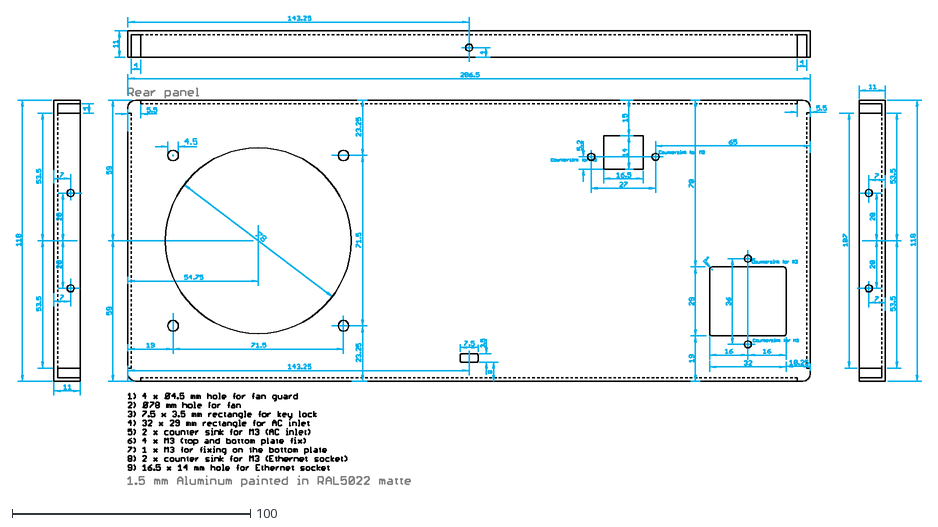
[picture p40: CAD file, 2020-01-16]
enclosure/EEZ BB3 chassis rear panel.dxf
380.0 x 197.7

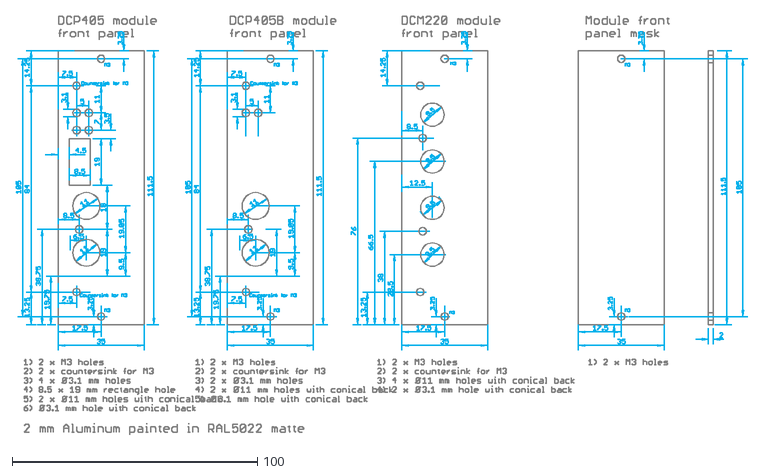
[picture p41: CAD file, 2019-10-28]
enclosure/EEZ BB3 chassis module panels.dxf
298.0 x 170.4

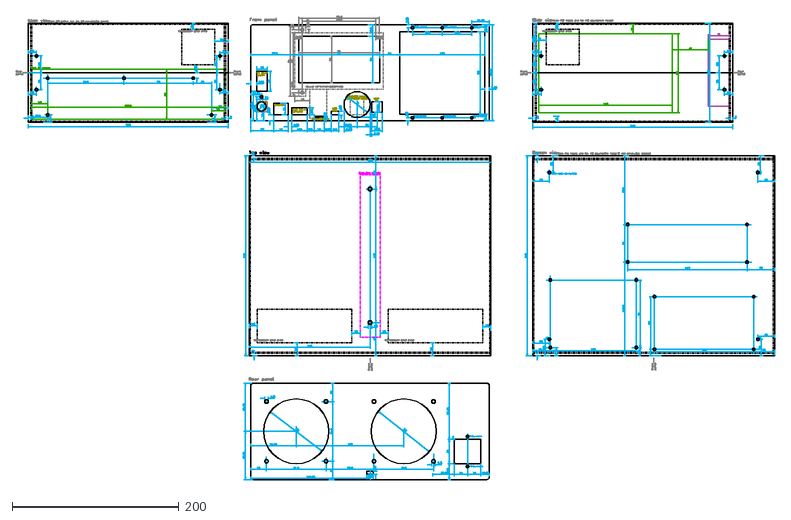
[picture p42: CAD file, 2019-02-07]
enclosure/DIB chassis r1B1.dxf
908.9 x 556.3

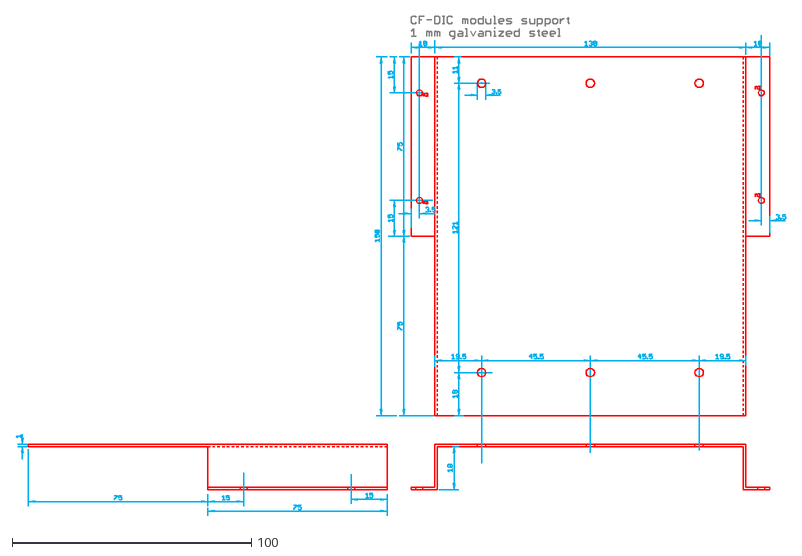
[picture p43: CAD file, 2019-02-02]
enclosure/DIB chassis CF-DIC modules support r1B1.dxf
321.7 x 209.0

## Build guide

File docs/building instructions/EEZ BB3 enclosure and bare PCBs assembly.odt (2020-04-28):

# “BB3 Enclosure & Bare Boards” kit assembly instructions

## Introduction

Instructions presented in this document are related to “BB3 Enclosure & Bare Boards” kit offered through a crowdfunding campaign (https://www.crowdsupply.com/envox/eez-bb3).

This kit is not an end-user product. As such, it has not been subjected to any conformance testing, and it may not comply with some or any technical or legal requirement that are applicable to finished products including, without limitation, directives regarding electromagnetic compatibility and recycling for instance (WEEE, FCC, CE or UL). Assembling requires intermediate or advanced soldering skills and basic understanding of electronic circuits and computer programming skills.

If you need assistance, please contact us using contact form (http://envox.hr/eez/contact-us.html) or join us on our Discord server (invitation (https://discord.gg/dhYMnCB)) or post your problem on the EEVblog forum here (https://www.eevblog.com/forum/projects/eez-h25005-a-possible-successor-of-eez-h24005-programmable-power-supply/). Or, feel free to open a New issue on GitHub here (https://github.com/eez-open/modular-psu/issues), but please check first to see whether a similar issue already exists).

The only tool required for the kit mechanical assembly is a medium Phillips head screwdriver. Of course, a multimeter for checking the wiring and voltage at a few points during assembly is recommended.

## Kit assembly steps

- Package content
- Plastic bags content
- PCB assembly
- Firmware downloading and module initialization

### Package content

The BB3 kit consists of the following parts, as shown in Fig. 1:

Item | Description
1 | Pre-drilled enclosure top cover
2 | Pre-drilled enclosure bottom plate
3 | Enclosure front panel with mounted 4.3” TFT touch-screen color display
4 | Enclosure rear panel
6 | Plastic bag with wire harness and miscellaneous mounting parts
10 | Plastic bag with cooling fan and AC/DC converter mounting frame
11 | Set of 6 bare PCBs

The part numbers in Fig. 1 (as well as on Fig. 2 and 3) are in line with those mentioned in the EEZ BB3 two channel kit assembly instructions (https://www.envox.hr/eez/eez-bench-box-3/eez-bb3-building-instructions/bb3-kit-assembly-instructions.html), which contains the assembly instructions to be followed after the modules are soldered and tested. For this reason, certain numbers were skipped to preserve the unique marking.

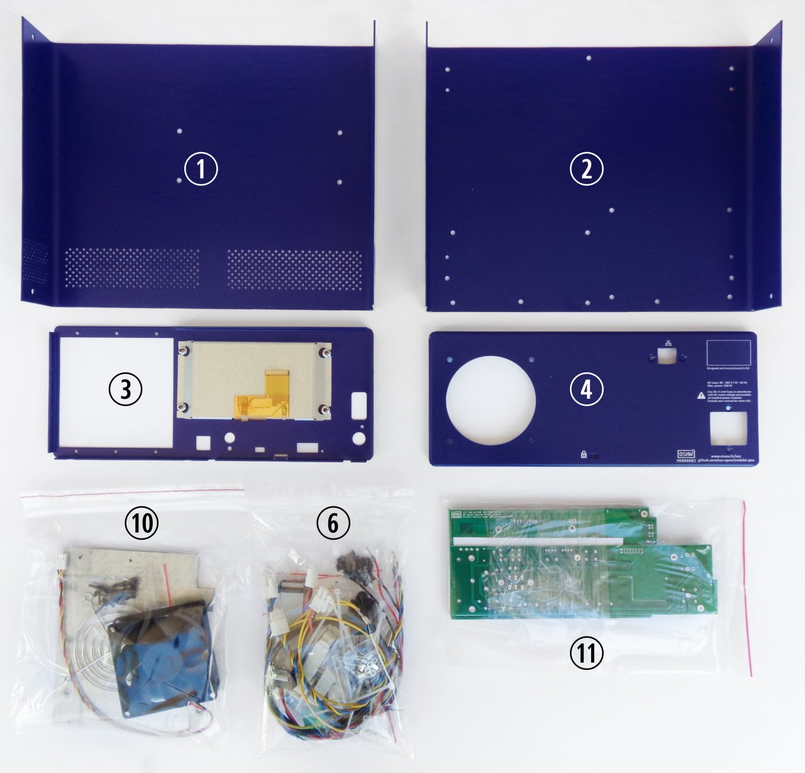
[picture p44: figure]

(https://www.envox.hr/eez/images/bb3_bare_parts.jpg)Fig. 1: “BB3 Enclosure & Bare Boards” kit content

### Plastic bag contents

Please take some time to check that the contents of the plastic bags (item 5 and 6) include everything listed below.

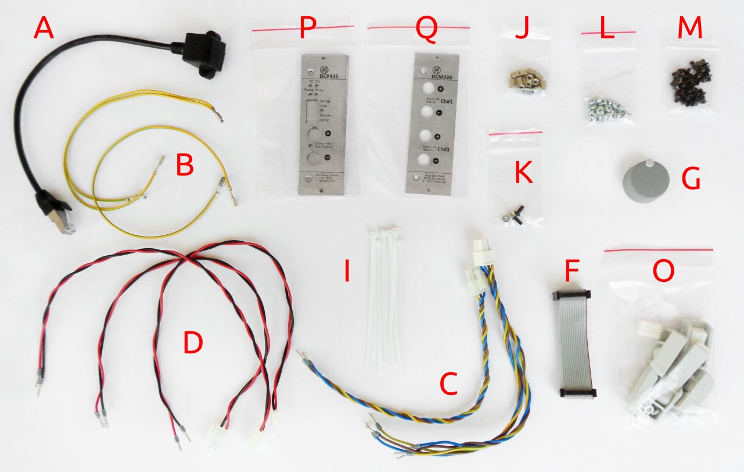
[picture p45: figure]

(https://www.envox.hr/eez/images/bb3_bare_bag1.jpg)Fig. 2: Plastic bag content

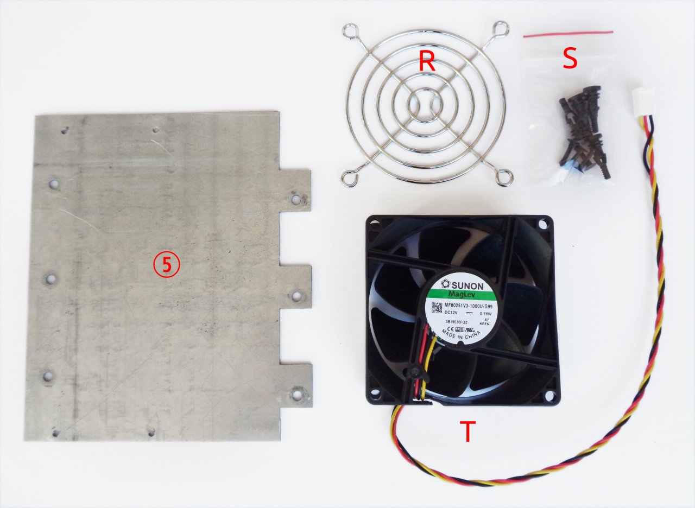
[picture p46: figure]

(https://www.envox.hr/eez/images/bb3_bare_bag2.jpg)Fig. 3: Plastic bag content (cont.)

Item | Description
A | Ethernet patch cable
B | Dual power module PE (Protective Earth) cable
C | Dual AC/DC power module AC input cable
D | Power module DC input cable
F | 16-pin IDC flat cable
G | Encoder knob
I | Cable ties ×6
J | Hexagonal M3×6 mm metal spacers ×13
K | Mounting set for AC power inlet
L | M3×4 mm screws ×13
M | M3×5 mm countersunk screws ×40
O | Enclosure feet kit
5 | Mean Well AC/DC converter mounting frame
P | DCP405 module front panel ×2
Q | DCM220 module front panel
R | Finger guard
S | Cooling fan mounting parts
T | 12 VDC cooling fan

### PCB assembly

The BB3 kit comes with six printed circuit boards (PCBs). Both SMD and THT parts were used on the PCBs. The SMD parts have been selected to be easily installable using hand soldering, but will greatly benefit from the assistance of an illuminated magnifying glass. In general, a magnification of x8 should be more than appropriate. Almost all passive SMD components are 0805 size, but never smaller then 0603. Few ICs comes in very small packages (e.g. IC1, IC10 on the MCU module (https://www.envox.hr/eez/eez-bench-box-3/eez-dib-stm32f7-mcu-board.html)) so they will need extra care when soldering.

The same goes for buck controllers on power modules (IC1, IC2 on DCP405 (https://www.envox.hr/eez/eez-bench-box-3/eez-dib-dcp405-power-module.html) and IC2, IC11 and IC13 on DCM220 (https://www.envox.hr/eez/eez-bench-box-3/eez-dib-dcm220-dual-power-module.html) module) since they have exposed thermal pads. For this reason, it will be simplest to solder them using a hot air soldering station. Since the PCB has a solder mask cut outs on the bottom side, it is also possible to apply the method shown in Dave's video EEVblog #434 (https://www.youtube.com/watch?v=588iV07nEdM).

Required tools and accessories

- A soldering iron with a conical tip example1 (https://www.tme.eu/en/details/plato-ew-301/soldering-tips/plato/ew-301/), example2 (https://www.tme.eu/en/details/plato-ew-303/soldering-tips/plato/ew-303/)
- A hot air soldering station example (http://www.tme.eu/en/details/at850d/hot-air-stations/atten/) (more than ordinary skill with a soldering iron may make this optional)
- Solder wire (0.25 mm diameter example (http://www.tme.eu/en/details/sn99c-0.25_0.1/solders-wires/cynel/), and 0.7 mm example (https://www.tme.eu/en/details/eco1-07_01h/solder-wires-lead-free/broquetas/eco1-b2-1-0-7mm-100g/)).
- Some solder wick / desoldering braid example (http://www.tme.eu/en/details/d-ls20/desoldering-wicks/donau/)
- Some solder flux. This is often used, via an applicator (resembling a syringe) or a very small brush. Example (http://www.tme.eu/en/details/flux-tk_50/fluxes/ag-termopasty/tk-83/)
- A magnifying glass with light example (https://www.tme.eu/en/details/lamp-5d-n1/desktop-magnifiers-with-backlight/newbrand/)
- A pair of self-locking tweezers example (http://www.tme.eu/en/details/brn-5-058/precision-tweezers/bernstein/5-058/)
- A pair of sharp non-locking tweezers example1 (https://www.tme.eu/en/details/nb-esd10/esd-tweezers/newbrand/), example2 (https://www.tme.eu/en/details/nb-esd15/esd-tweezers/newbrand/)
- Isopropyl alcohol
- Heat transfer glue for fixing DCP405 pre-regulator heatsink example (https://www.tme.eu/en/details/termoglue-10/glues/ag-termopasty/art-agt-116/)
- A PCB holder example (http://www.tme.eu/en/details/sp-holder-1/soldering-devices-others/solder-peak/)
- Medium Phillips head screwdriver

The basic tool needed for measurements is an oscilloscope. But, if assembly is performed carefully so that there are no mistakes (e.g., the wrong part value, or the right part installed in the wrong place, or inadvertent solder fragment shorts between parts or PCB traces, etc.) a multimeter (DMM) will be enough to check basic functionality.

During testing and taking measurements, please note that a power module channel’s negative output (OUT-) is NOT at ground potential with regard to the mains earth potential in the AC wiring. If you are using a multichannel oscilloscope which does not have isolated channels (the default!) you cannot simultaneously connect the test probe ground of one channel to a GND point and another channel to an OUT- point. This will interfere with normal operation of the current control loop because the current sense resistor will be bypassed.

The zip file below contains subfolders with module names. For each module there are schematics, BOM and parts placement picture. As example a parts placement picture for the MCU module is shown in the Fig. 4.

{jd_file file==26}

All non-soldering parts are marked N.C. Furthermore, there are a number of jumpers on all PCBs. For normal functioning, you will not need to change any of the jumpers.

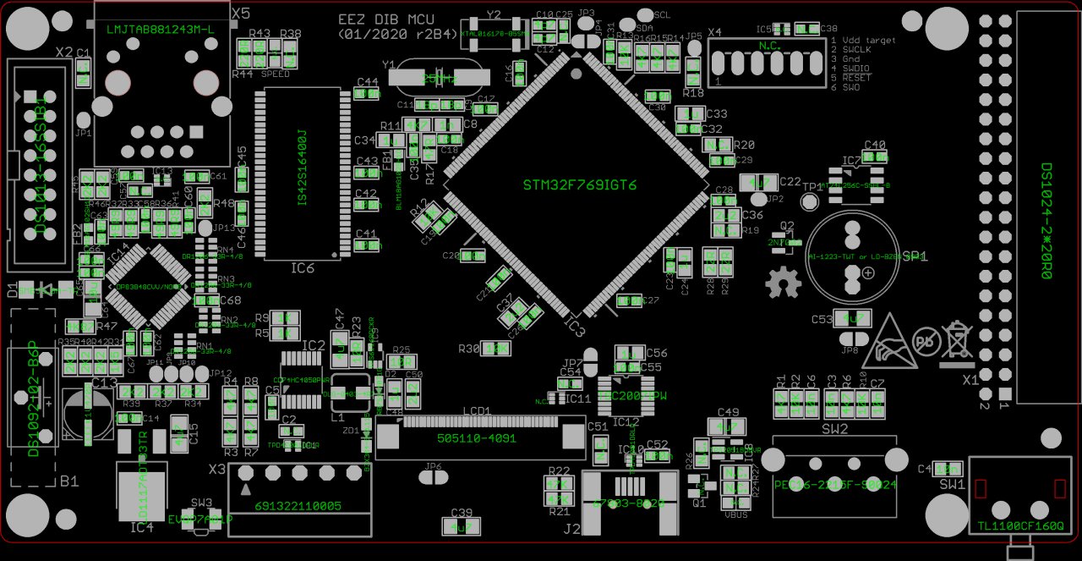
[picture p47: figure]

(https://www.envox.hr/eez/images/bb3_bare_parts_placement.jpg)Fig. 4: Parts placement picture for the MCU module

You can assemble the modules in the order you want. The BP3C backplane is the simplest so it can be a good place to start. In general, when assembling, the SMD parts should be mounted first and then the THT parts are followed.

The next module by complexity is the AUX-PS module. The two components on it require special attention. These are triacs (Q1, Q2) that should first be mounted on a heat sink (KK1) and then soldered (see Fig. 5).

For the MCU module, besides the ICs (IC1, IC11) already mentioned in the small package there is nothing special to say. With the exception of the micro SD card socket (J1), all components are mounted on the top side of the PCB. The MCU (IC3) comes in a large package and should be mounted as usual for a package that has pins on all four sides: first solder one pin on opposite sides and then carefully proceed to solder all remaining pins. The same goes for IC14.

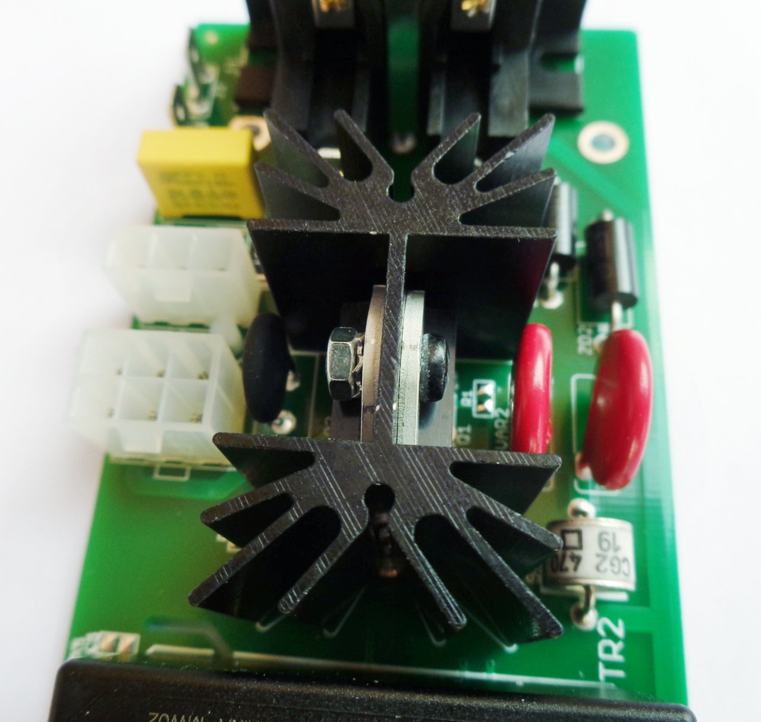
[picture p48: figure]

(https://www.envox.hr/eez/images/bb3_bare_triacs.jpg)Fig. 5: Triacs mounted on heatsink

Do not insert the battery before the assembly of all modules is complete and ready for mounting in the BB3 enclosure.

Power modules have the largest number of components and will take the most time to assemble. Since there are two DCP405 PCBs it is possible to mount components simultaneously which can save some time. When assembling the DCP405 module, you can first complete the bias power supply section around the buck controller (IC2) and check that it outputs about 8-9 V (positive and negative rail). If that's right you can complete that section by adding IC5 and IC6 which should give +5V and -5V at their outputs. You can now continue to fill the PCB with the rest of the components.

The DCP405 requires the installation of two heatsinks. The larger heatsink serves to radiate heat from Q3, Q4 and Q5 and is fastened with M3x8 screws (not part of this kit). The smaller cooler will need to be pasted using heat transfer glue (listed under Required tools and accessories). However, the installation of the heatsinks can be done later if DCP405 module is not going to be tested with load that can draw more than 100 mA. When applying a glue for a small heatsink, allow it to dry for a few hours.

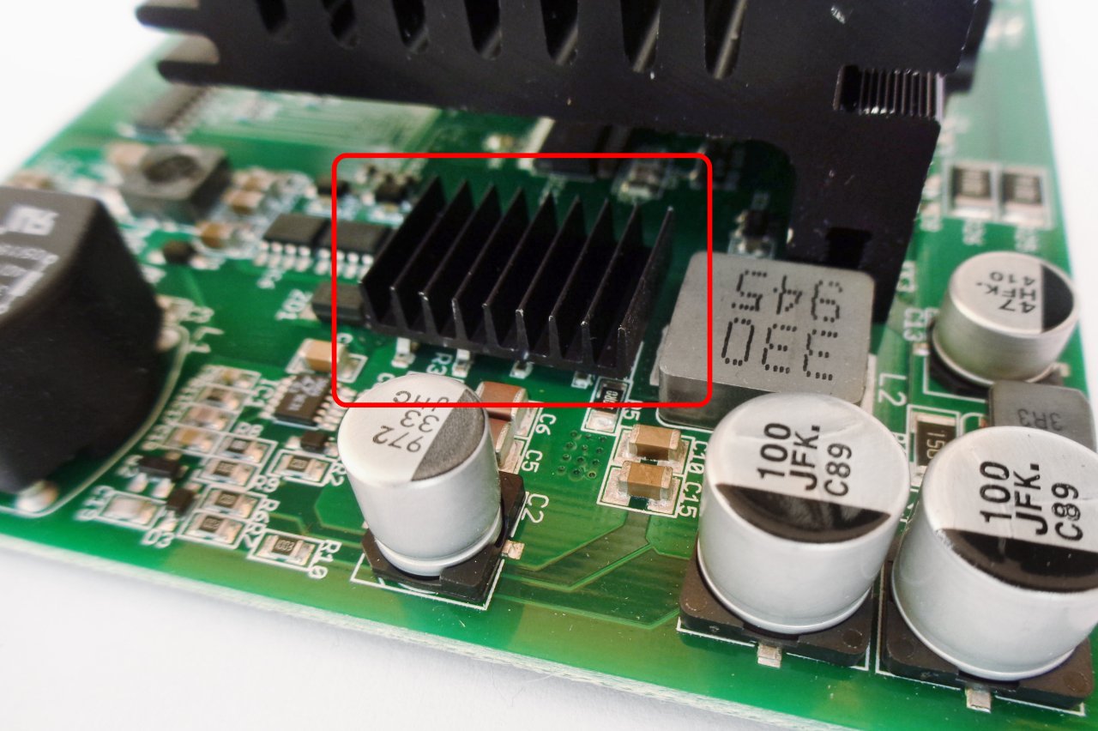
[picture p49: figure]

(https://www.envox.hr/eez/images/bb3_bare_buck_heatsink.jpg)Fig. 6: DCP405 buck pre-regulator heatsink

While the pre-regulator could easily withstand loads up to 3 A without heatsink, this is not the case with the post-regulator. Its Q3, Q4 transistors without being mounted on heatsink could instantly damaged at higher currents.

When assembling a DCM220 module, you can apply the same principle as in DCP405: first assemble the bias power supply (IC2), check that the outputs are about 7-8 V, add LDO (IC5), and if it gives +3.3 V, continue adding all other parts.

Before proceeding with mounting the power module in enclosure (see EEZ BB3 two channel kit assembly instructions (https://www.envox.hr/eez/eez-bench-box-3/eez-bb3-building-instructions/bb3-kit-assembly-instructions.html)), fix the front panels (item P and Q, Fig. 2). You will need six M3x5 screws (two per module, not part of this kit).

Since in this kit the cooling fan does not come mounted on the rear panel you will need to do it yourself. This will require the contents of a item S and a finger guard (item R). First mount the four rubber holders as shown in Fig. 8.

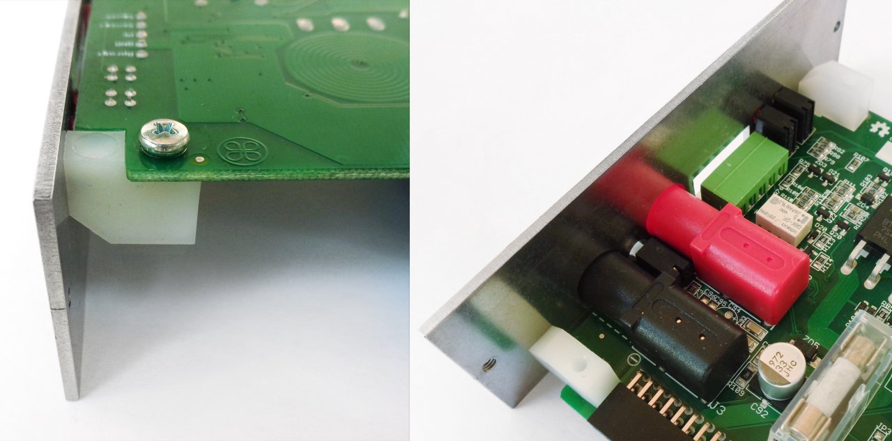
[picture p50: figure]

(https://www.envox.hr/eez/images/bb3_bare_module_front.jpg)Fig. 7: Module front panel installed

Then carefully attach the fan and finally mount the finger guard and secure it with four plastic fasteners (Fig. 9).

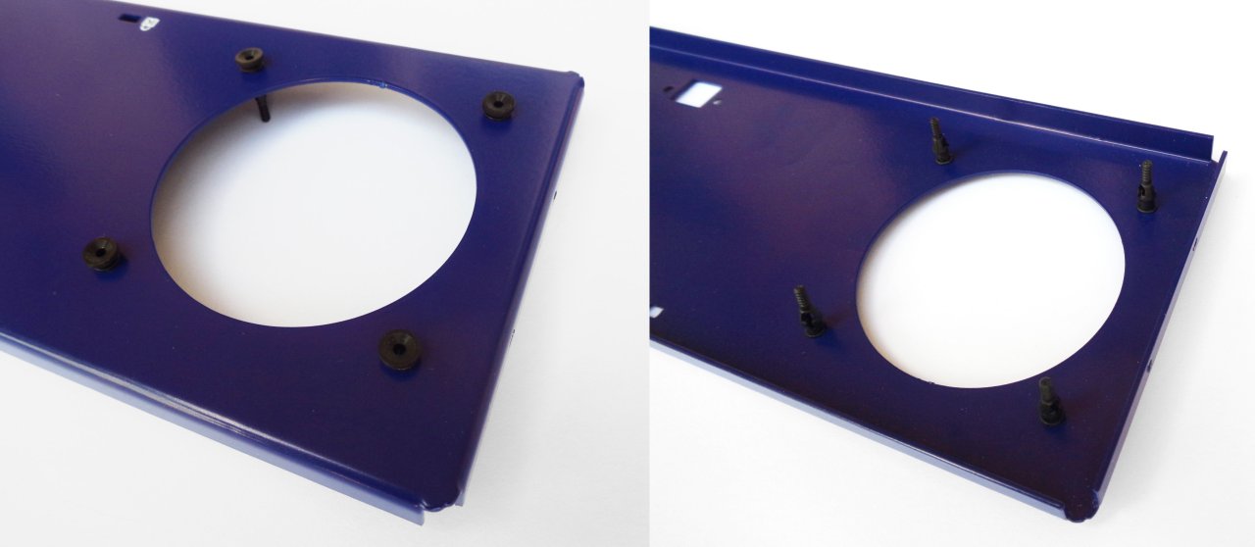
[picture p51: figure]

(https://www.envox.hr/eez/images/bb3_bare_fan_holders.jpg)Fig. 8: Rear panel with fan holders

### Firmware downloading and module initialization

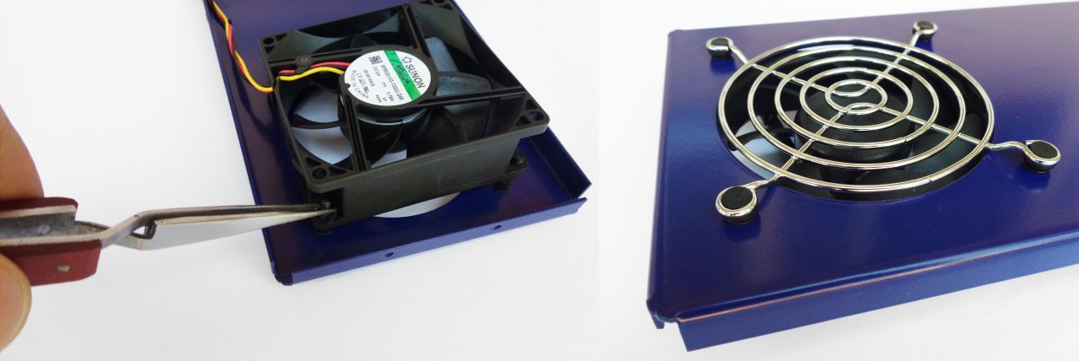
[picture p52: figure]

(https://www.envox.hr/eez/images/bb3_bare_fan_mounting.jpg)Fig. 9: Mounting fan and finger guard

When all modules are assembled, we can proceed with their mounting into the BB3 enclosure. Before that, it will be necessary to put two fuses in the AC inlet (see recommendations in the User manual Section 2.8 (https://www.envox.hr/eez/eez-bench-box-3/bb3-user-manual/2-key-features.html)) and check that the AUX-PS outputs have +5 V and +12 V. If the required voltages are present, turn off the power and connect the MCU and AUX-PS module using a 16-pin IDC flat cable (item F, Fig. 2). Follow the procedure in the User manual Firmware upgrade section (https://www.envox.hr/eez/eez-bench-box-3/bb3-user-manual/13-firmware-upgrade.html).

If the MCU module is correctly assembled, after downloading the firmware, assuming you have connected the display, a start page will appear on it and some errors may occur if, for example, you have not connected the cooling fan connector, or inserted a micro SD card or connected the BP3C backplane with the MCU module. Ignore these errors for a moment, turn off the power and continue assembly so you can insert power modules as well.

IMPORTANT: modules that are installed for the first time must be initialized. Therefore, you should not be surprised that even though you have put everything together correctly, the firmware will not recognize them at the next power up.

Initialization requires running the Module initialization script, which you can download here (https://www.envox.hr/eez/eez-bench-box-3/firmware.html). You will need both .py and .res files. These files will need to be transferred to the micro SD card of the MCU module, the easiest way to do this is to use EEZ Studio. The procedure is the same as described in the User manual 13.2 Peripheral module firmware upgrade (https://www.envox.hr/eez/eez-bench-box-3/bb3-user-manual/13-firmware-upgrade.html) section with the destination folder being Scripts instead of Updates. Familiarize yourself with this procedure, as you will later need to download the firmware in the DCM220 after it has been initialized and successfully recognized by the master firmware.

After transferring both files, go to File manager (https://www.envox.hr/eez/eez-bench-box-3/bb3-user-manual/9-system-functions.html) and run the Module initialization script in the Scripts section. Fig. 10 shows the settings for initializing all three modules at once: two DCP405 on the first two slots and DCM220 on the third slot. When you have set the module parameters, select the Restart option.

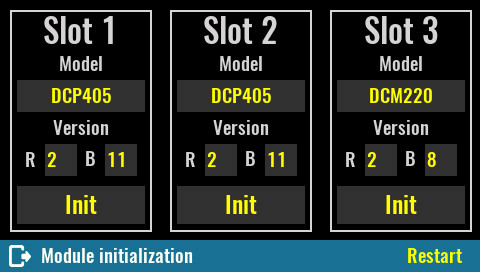
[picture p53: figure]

(https://www.envox.hr/eez/images/bb3_bare_module_init.jpg)Fig. : Module initialization script

Power modules will also need to be calibrated. Follow the procedure in the User manual 12. Power modules calibration (https://www.envox.hr/eez/eez-bench-box-3/bb3-user-manual/12-power-modules-calibration.html) section.

“BB3 Enclosure & Bare Boards” kit assembly instructions

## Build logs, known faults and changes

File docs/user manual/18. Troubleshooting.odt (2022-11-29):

# Troubleshooting

## Wrong master MCU firmware revision selected

The EEZ BB3 comes with two different versions of MCU modules that also require slightly different firmware versions. As stated in Section 8.16. (https://www.envox.eu/eez-bench-box-3/bb3-user-manual/8-system-settings/#bb3_man_system_info) on the System Information page it is possible to check which version of the MCU module is selected. The version of the MCU module is also allowed to be changed on the same page. For example, if the r2B4 version is currently selected and you want to change it, a warning message will appear:

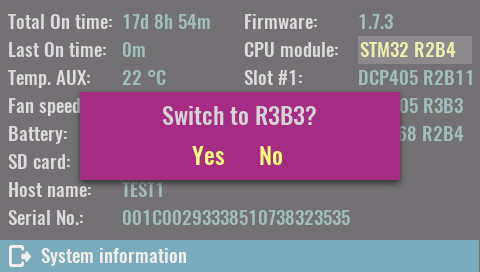
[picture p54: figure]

Of course you shouldn’t change the version, however if you did it unknowingly, EEZ BB3 will restart and you can expect a black screen. Fortunately, this will not cause any damage, except that they will no longer be able to see anything on the screen, and not be able to go to the System information page to select the correct version.

This can be corrected by connecting to the EEZ Studio via a USB or LAN interface and executing the DEBUG 33 command in the Terminal. When the command is executed, the EEZ BB3 will restart and the MCU module version selection will appear on the screen.

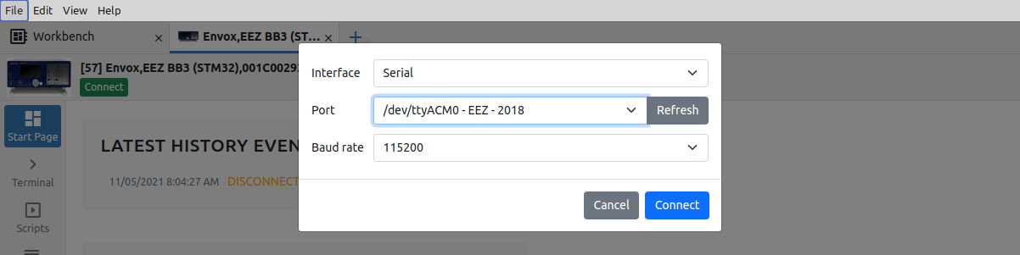
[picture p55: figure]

(https://www.envox.eu/wp-content/uploads/bb3_man_wrong_version2.png)

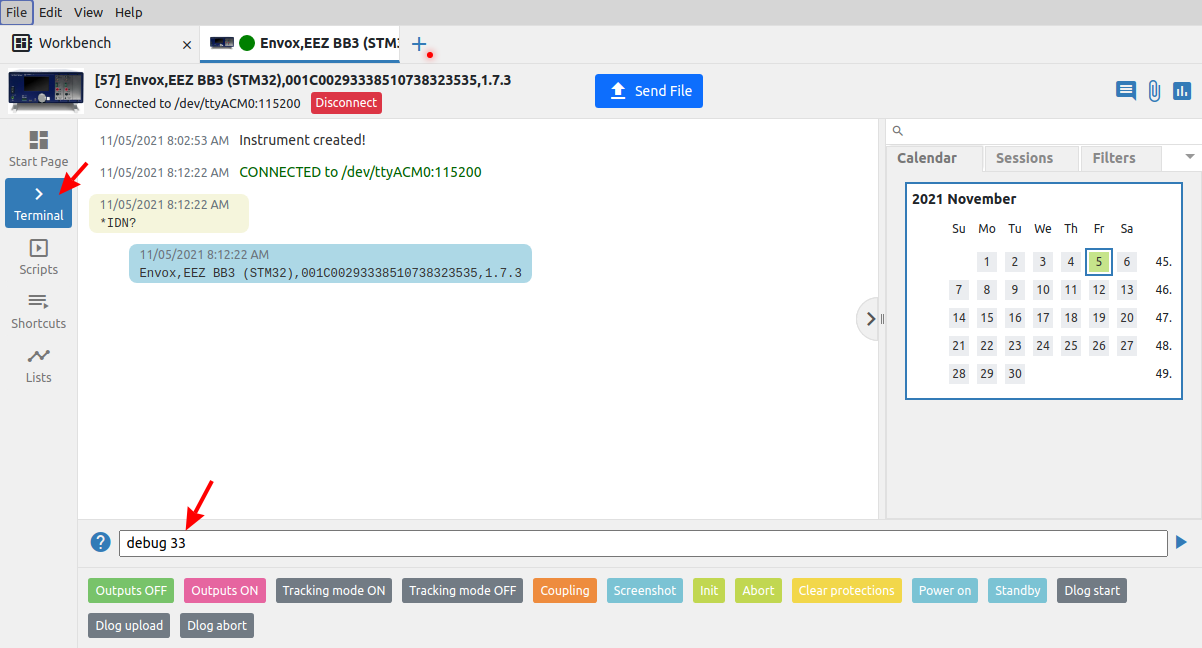
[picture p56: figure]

(https://www.envox.eu/wp-content/uploads/bb3_man_wrong_version3.png)

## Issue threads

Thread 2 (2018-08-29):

SDRam trace length match

LJJS, 2018-08-29:
The length of the bus for the SDRam chip should have all the same length.
The bus operates at 143MHz, so the total trace length should be all equal.

Also, the length of each trace at each layer should have the same length!

prasimix, 2018-08-29:
Thanks for that. This is a first prototype and we'll see how it's going to work. I do believe that for keeping all traces of equal length is not ask for introducing 6-layer PCB.

LJJS, 2018-08-29:
I have done some testing with the length matching. Just an example how it can be done:

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

Sure, this is not the final solution, but I think it shows with some effort it is possible to tune the traces to very similar lengths.
The board right now have differences in length to a maximum of 10mm, with a typical trace length of about 35mm. With some work it should be possible to match the length of the trace with a maximum difference of 1mm, even with a 4-layer PCB.

But also said, I think it will work just fine with these lengths at these frequencies, but it would be a nice detail in engineering.

prasimix, 2018-08-29:
Thanks for effort. Actually I tried to use meandering but the results was pathetic at least in v.7.4. I'm going to commit a fix for #3 and such changes should be applied in that revision.

Rerouter, 2018-09-08:
Most of the top layer can be matched without meandering, I have done it in kicad, but would probably be a pain to recreate in eagle.
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

The bottom layer needs a bit more agressive length matching, currently i have matched within 10mm,
I approached it by shortening the longest traces first, leaving almost nothing to be added to the top layers,

But the control lines, some of them have 30mm differences, that took some manual creativity,

Rerouter, 2018-09-08:
LJJS, the timing specifications only require a +-10mm matching, Attached is my current effort to that 10mm margin, but if you want to continue down to under 1mm, be my guest.

If you want to go the whole hog, the RX/TX buses on the ethernet controller are also out of skew by up to 30mm,

[EEZ DIB MCU r1B1.zip](https://github.com/eez-open/modular-psu/files/2363171/EEZ.DIB.MCU.r1B1.zip)

Current lengths,
Address Group:
A0-A5 - 45.0
A6-A11 - 45.5

Command Group:
SDNRAS - 45.0
SDNCAS - 53.7
SDNWE - 45.0

Control Group:
SDBA1 - 50.0
SDBA0 - 49.5
SDNBL0 - 50.0
SDBLN1 - 54.4
SDCKE0 - 45.0
SDNE0 - 47.0

Data Group:
D0-D1 - 45.0
D2 - 48.4
D3 - 48.4
D4-D12 - 45.0
D13-D15 - 50.5

Clock:
SDCLK - 55.0

prasimix, 2018-09-08:
Thanks, I believe there is no need to go down to +/-1mm. First, we have to see what will happen when I tried to run existing PCB (that should be in a week or two).
Should I just add that changes into my next commit or you are going to initiate a new pull request?

Rerouter, 2018-09-08:
I'll Initiate, As I have also wrapped up Kicad-ising the schematic, and generating a netlist.

Rerouter, 2018-09-08:
https://github.com/eez-open/modular-psu/pull/5

Pull request made.

prasimix, 2018-09-09:
I managed to open KiCad file today. Unfortunately it seems that it doesn't include bug reported and fixed in Eagle under #3. Any chance to include that change?

Rerouter, 2018-09-09:
https://github.com/eez-open/modular-psu/pull/6

All kicad files are now brought up to eagle master.

Rerouter, 2018-09-09:
https://github.com/eez-open/modular-psu/pull/8

Missed an unconnected count,

prasimix, 2019-03-13:
Prototype works predictably, can be reopened if some issue arise.

Closed 2019-03-13.

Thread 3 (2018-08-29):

USB connector mismatch

prasimix, 2018-08-29:
USB B-type connector cannot be used for OTG that required 5-pins (with ID). It has to be replaced with Mini AB. Currently ID instead of GND is connected to the pin 4.

prasimix, 2018-08-29:
Fixed

Closed 2018-08-29.

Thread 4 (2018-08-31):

LCD backlight LED power input

prasimix, 2018-08-31:
Use +5V instead of +3V3as power input for LCD backlight LED boost converter.

prasimix, 2018-08-31:
Fixed

Closed 2018-08-31.

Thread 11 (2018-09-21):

X4 debug connector

prasimix, 2018-09-21:
Make existing X4 20-pin JTAG connector optional or remove it completely and add 0.1" header for SWD/SWIM connection. Rearrange usage of IC6 and IC7 inputs.

prasimix, 2018-10-19:
Fixed

Closed 2018-10-19.

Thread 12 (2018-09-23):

JP4 default position

prasimix, 2018-09-23:
For chosen TFT display (RFE43BH-AIW-DNS) JP4 default position should be changed from RESET to GND.

prasimix, 2018-10-09:
Fixed

Closed 2018-10-09.

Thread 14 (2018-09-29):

Add protection for USB VBUS

prasimix, 2018-09-29:
Use remaining IC12 input to protect VBUS line.

prasimix, 2018-09-29:
Not really necessary since used IC2 (TPD4E001) has protective diode between Vcc and Gnd.

Closed 2018-09-29.

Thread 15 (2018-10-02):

MCU EEPROM changes

prasimix, 2018-10-02:
* IC2 lines for MCU EEPROM (i.e. SDA and SCL) are wrongly connected.
* Replace with 2K SOIC8 (e.g. AT24C02D-SSHM-T)
* WP (Write protect) pin move from 3V3 to Gnd.

prasimix, 2018-10-18:
Fixed

Closed 2018-10-18.

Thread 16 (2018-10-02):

"Mirrored" encoder pinout

prasimix, 2018-10-02:
It seems that encoder's pinout is mirrored (i.e. A and C pins are swapped). Has to be checked and eventually rectified in Eagle library.

prasimix, 2018-10-18:
Fixed

Closed 2018-10-18.

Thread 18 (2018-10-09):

Wrong backup battery polarity

prasimix, 2018-10-09:

prasimix, 2018-10-18:
Fixed

Closed 2018-10-18.

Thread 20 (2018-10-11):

Pull-up on fan controller's THERM pin

prasimix, 2018-10-11:
Add place on the AUX-PS PCB for 2K2 pull-up on fan controller's THERM pin.

prasimix, 2018-10-20:
Fixed

Closed 2018-10-20.

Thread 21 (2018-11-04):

Add ferrite beads

prasimix, 2018-11-04:
Add ferrite beads on +5 V power input and USB power (IC9).

prasimix, 2019-03-13:
Not fixed

Closed 2019-03-13.

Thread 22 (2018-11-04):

Input power selection for audio amp

prasimix, 2018-11-04:
Add on the MCU board selection of input power for audio amplifier (IC12). Default is +3V3.

prasimix, 2018-11-18:
Fixed together with #25

Closed 2018-11-18.

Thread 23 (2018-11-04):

Split power and signal GND

prasimix, 2018-11-04:
Split power and signal GND on the AUX PS board. Also trace dedicated GND for fan.

prasimix, 2018-11-05:
Fixed

Closed 2018-11-05.

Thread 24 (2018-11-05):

Add elco over fan terminals

prasimix, 2018-11-05:
Add 470u elco over fan terminals to improve EMI. Change fan supply input filter capacitor from 10u to 1u and remove 100n.

prasimix, 2018-11-05:
Fixed

Closed 2018-11-05.

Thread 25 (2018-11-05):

Replace resistive touch-screen controller

prasimix, 2018-11-05:
Currently used [AR1021](https://www.microchip.com/wwwproducts/en/AR1021) is recently marked as "Not recommended for new designs". Therefore it has to be replaced with something else that comes in convenient package (not QFN, BGA, etc.), e.g. [TSC2007](http://www.ti.com/product/tsc2007) or [TSC2003](http://www.ti.com/product/tsc2003).

prasimix, 2018-11-18:
Fixed

Closed 2018-11-18.

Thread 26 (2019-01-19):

DCP505 IC12 power inputs are swapped

prasimix, 2019-01-19:
IC12 power inputs are wrongly connected (i.e. V+ to pin 11 instead of 4 and vice versa).

prasimix, 2019-01-21:
Fixed

Closed 2019-01-21.

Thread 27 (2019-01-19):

Rotate coupling relays for 90 degrees

prasimix, 2019-01-19:
Both coupling relays on the BP3C PCB have to be rotated since module in slot #2 cannot be inserted

prasimix, 2019-01-31:
Fixed

Closed 2019-01-31.

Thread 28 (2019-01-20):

Auto-ranging switching improvements

prasimix, 2019-01-20:
the following changes have to be implemented to improve switching between two ranges:
1. Connect D15 cathode between 0R010 current sense resistors
2. Add 100n capacitor in parallel with R59
3. Add hysteresis resistors (1 Meg) over IC12B and IC12C

All mentioned new added parts values have to be further optimized for as fast as possible switching (without introducing stability issues).

Closed 2019-06-18.

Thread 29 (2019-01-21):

Invert OVP_FAULT output

prasimix, 2019-01-21:
OVP circuit as currently wired cannot provide 4 V or more as OVP_FAULT signal for the I/O expander. Therefore that signal has to be inverted with adding one MOSFET with optionally pull-up on its drain (if internal I/O expander pull-in is not going to be used).

prasimix, 2019-01-21:
Fixed

Closed 2019-01-21.

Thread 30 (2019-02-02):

Add support for second fan

prasimix, 2019-02-02:
Replace existing fan controller with one that has two tacho inputs (e.g. MAX31760).

prasimix, 2019-02-07:
Fixed

Closed 2019-02-27.

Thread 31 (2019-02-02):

Fan connector improvement

prasimix, 2019-02-02:
The current fan connector pinout is not in line with PC standard (power lines are swapped). Also use 4-pin connector (has to be Molex 47053-1000) that can accept both 3- and 4-wire fan connectors.

prasimix, 2019-02-07:
Fixed

Closed 2019-02-07.

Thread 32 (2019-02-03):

Fan filtering improvement

prasimix, 2019-02-03:
Modify fan filtering and driver to improve EMI by decreasing current peaks caused by charging capacitor connected in parallel with fan power lines (added to clean up EMI generated by fan itself).

prasimix, 2019-02-07:
Fixed

Closed 2019-02-07.

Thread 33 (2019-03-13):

Change MAX31760 I2C address

prasimix, 2019-03-13:
The MAX31760 I2C address is set to 0xA0 that is already assigned to the EEPROM on the MCU board. Change it to the 0xAE to be over all EEPROM addresses (on MCU and peripheral modules).

prasimix, 2019-03-15:
Fixed

Closed 2019-03-15.

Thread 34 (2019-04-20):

I2C address keys for module #2 and #3 are inverted

prasimix, 2019-04-20:
I2C address keys on the BP3C is wrong and has to be fixed. Use PCB jumpers to offer more flexibility for defining module IC2 address.

prasimix, 2019-04-20:
Fixed

Closed 2019-04-20.

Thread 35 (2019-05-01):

Add LSE xtal for STM32

prasimix, 2019-05-01:
Additional xtal is required for RTC otherwise it is going to stop counting while power is switched off and battery is used.

LSE xtal pins are already occupied with DOUT1 and DOUT2. Move that functions to other unassigned pins if available. If no pins are available unassign OUT_SER and OUT_PAR and introduce an I2C I/O expander on BP3C board.

prasimix, 2019-05-05:
Fixed

Closed 2019-05-05.

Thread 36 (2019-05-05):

I/O expander for SERial and PARalell coupling control

prasimix, 2019-05-05:
Since adding of LSE xtal (#35) consumed two additional MCU pins, SER_OUT and PAR_OUT cannot be driven directly from MCU anymore. An I/O expander (I2C) has to be introduced on the BP3C to provide SERial and PARalell coupling control.

prasimix, 2019-05-05:
Fixed

Closed 2019-05-05.

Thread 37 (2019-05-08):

Add BOOT0 jumper

prasimix, 2019-05-08:
Replace PCB jumper with real one for BOOT0 input for easier selection of MCU bootloader when USB DFU is used for firmware upgrade.

prasimix, 2019-05-08:
Fixed

prasimix, 2019-06-11:
Move BOOT switch position to AUX PS (below PE 4 mm terminal)

prasimix, 2019-06-18:
Fixed

Closed 2019-06-18.

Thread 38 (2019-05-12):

Connection of Out- terminals

prasimix, 2019-05-12:
Add third relay that is also controlled via I2C I/O Expander to connect together Out- terminals of all three modules

prasimix, 2019-05-12:
Fixed

Closed 2019-05-12.

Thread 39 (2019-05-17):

Coupling for split rail solution

prasimix, 2019-05-17:
Include additional relay that can under firmware control connect Ch#1 Out- and Ch#2 Out+ for making split rail output without external wiring.

prasimix, 2019-05-17:
Fixed

Closed 2019-05-17.

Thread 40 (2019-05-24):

Connecting MCU Battery with +VAUX

prasimix, 2019-05-24:
Add PCB jumper (open) that MCU battery on the MCU board could be used to provide +VAUX for the DIB backplane.

prasimix, 2019-05-24:
Fixed

Closed 2019-05-24.

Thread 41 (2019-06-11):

On-board firmware programming (BOOT and RESET control)

prasimix, 2019-06-11:
Provide dedicated BOOT output for each BP3C slot that can be used for firmware programming of on-board MCU. That will require the following modifications:
* Expand 26-pin DIB periperal module connector to 28-pin to carry UART lines (RX, TX)
* Assign BOOT input on one of the existing GND pin
* Replace 4-pin I2C I/O expander with 8-bit version for dedicated BOOT outputs and programmable RESET output
* "OR-wire" I/O expander peripheral reset output with master RESET (with diodes)

prasimix, 2019-06-18:
Fixed

Closed 2019-06-18.

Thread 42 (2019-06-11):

Expose UART on 40-pin DIB backplane connector

prasimix, 2019-06-11:
UART interface is required for programming firmware of peripheral module MCUs (see also #41). Reassign DIN, DOUT and SD_DETECT pins that new UART_TX and UART_RX can be used. Use two currently unassigned pins on the 40-pin DIB backplane connector.

prasimix, 2019-06-18:
Fixed

Closed 2019-06-18.

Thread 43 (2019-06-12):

HW OVP trip detection

prasimix, 2019-06-12:
Currently is not possible for MCU to find out if HW OVP is tripped or not. Therefore bring existing OVP_FAULT signal to one of available I/O Exp input.

prasimix, 2019-08-28:
Fixed

Closed 2019-08-28.

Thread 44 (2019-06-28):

Replace audio amp and loudspeaker with simple buzzer

prasimix, 2019-06-28:
Currently used audio amp and PCB loudspeaker is too costly and cannot offer audible enough sound. Therefore, move back to simple buzzer with driver as in case of H24005. For buzzer combine PCB holes for both 9 mm and 12 mm buzzer (e.g. AI-1223-TWT-5V-5-R).

prasimix, 2019-06-29:
Fixed

Closed 2019-06-29.

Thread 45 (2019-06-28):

Modify Digital I/O stage

prasimix, 2019-06-28:
Replace existing digital I/O drivers/buffers with 74HC4050 (use 2 for input and 2 x 2 for outputs).

prasimix, 2019-06-29:
Fixed

Closed 2019-06-29.

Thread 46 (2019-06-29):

MCU board X2 connector changes

prasimix, 2019-06-29:
Replace X2 16-pin IDC connector from right angled to vertical and move it to the PCB's left edge.

prasimix, 2019-06-29:
Fixed

Closed 2019-06-29.

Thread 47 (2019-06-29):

AUX PS board X3 connector changes

prasimix, 2019-06-29:
Rotate X3 16-pin IDC connector for 180 deg and swap its position with TR1 if possible.

Closed 2019-08-28.

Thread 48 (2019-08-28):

Reduce Vin on LT3763 for lower dissipation

prasimix, 2019-08-28:
The L3763 power dissipation is considerable on 2-layer PCB with 48 Vdc applied on its Vin input. Reduce Vin by introducing simple Vout tracking with MOSFET that Vin is always about +7 V above Vout

prasimix, 2019-09-18:
Fixed

Closed 2019-09-18.

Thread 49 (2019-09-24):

Add RC filters on DAC outputs to slow down rise/settling time

prasimix, 2019-09-24:

prasimix, 2019-09-24:
Fixed

Closed 2019-09-24.

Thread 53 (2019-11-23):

UART lines are swapped before digital isolator

prasimix, 2019-11-23:
DCM220's UART lines are swapped before instead of _after_ digital isolator.

prasimix, 2019-12-07:
Fixed

Closed 2019-12-07.

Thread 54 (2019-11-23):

Proposal switch from STM32F7 to STM32H7 Dual Core

bvernoux, 2019-11-23:
I have seen selected MCU is an STM32F769IGT (LQFP176) which is very good anyway I think for future and to manage even more things it will be a must have to switch to pin compatible STM32H7 CPU with the big advantage to have Dual Core 1x CortexM4F @ 240MHz and 1x CortexM7@480MHz tons of FLASH/RAM peripherals ... that will allow to add special hard real-time monitoring / tasks... in one core and doing other things in an other core ...
It seems STM32H757IITx LQFP176 is full pin compatible (more check to be done to be sure) marketing status is active but it seems hard to find so far (maybe contacting ST directly will help)

bvernoux, 2020-02-04:
Just an update as now some STM32H757IIT6 are available at mouser EU (https://eu.mouser.com)

prasimix, 2020-06-23:
I invested some time to check out the H757. Unfortunately it is not a pin compatible with the F769 and needs a lot of changes. Furthermore, I failed to configure in CubeMX to have Ethernet, SDRAM and TFT display (RGB) at the same time. However, it could be relatively easy to migrate to H743.

bvernoux, 2020-06-23:
Thanks for update main interest in STM32H7 was mainly dual core (H7 vs F7 are better but less interesting I think) but yes it seems not easy ...
Other idea to keep Dual Core features is to check STM32H745I / STM32H747I or STM32H755I (with LQFP176) maybe they are "more pin compatible" to actual STM32F769IGT and can be configured with Ethernet, SDRAM and TFT display (RGB) at the same time...

prasimix, 2020-06-23:
I think that 176 pin package is simply too small to assign concurently what I'd like to have, and that is:

1. Ethernet MII or RMII
1. SDRAM min. 12 address lines
1. TFT RGB 16-bit
1. USB OTG/VBUS detection
1. SD card 4-bit data bus

bvernoux, 2020-06-24:
Maybe it will be required to switch to the "big" version TFBGA240 to have all possible features, I think it will be a very nice evolution for future (and mainly features/extension which requires hard real-time).

prasimix, 2020-06-26:
I would rather try to do something with the LQFP208. I have never designed a PCB with BGA before, and I am not equipped to assemble PCB with such a package. In the meantime I could spend some time trying to migrate to single core H7 like already mentioned H743 since it offers more speed for lower price then F769.

chenpeng198877, 2020-07-20:
Can stm32f769bit6 be used?

prasimix, 2020-07-20:
> Can stm32f769bit6 be used?

It is not possible with the current PCB revision, and the idea discussed here is to move to the MCU from the H7 family (preferably dual core).

prasimix, 2020-07-20:
BTW, I managed to layout a new PCB revision based on the STM32H743IIT6 (LQFP-176) which is still single core but offers higher speed for less money. Of course, we should make a prototype and support it in the firmware.

bvernoux, 2020-07-24:
Yes it is already a good step/compromise as dual core (is much more expensive/complex..) and requires lot of more works maybe for a future update ...

prasimix, 2023-11-20:
If we go with a new MCU, according to the latest research, it could be the H745 (dual-core).

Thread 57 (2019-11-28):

Make PCB/Gerbers for all power modules

prasimix, 2019-11-28:

prasimix, 2019-11-28:
Today is possible to make high quality and precisely drilled PCB with any silkmask in many different colors (incl. blue and black). Therefore module's front panels can be made as PCB that is 2 mm thick.

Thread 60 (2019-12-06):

OVP crowbar is not fused

prasimix, 2019-12-06:
The OVP crowbar is connected to OUTF+ instead of POST_OUTF+

prasimix, 2019-12-06:
Fixed

Closed 2019-12-06.

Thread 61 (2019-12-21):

Gerber files cleanup breaks Kitspace pages

kasbah, 2019-12-21:
Hey, 5093d6baf4961f45936e4f982cc5a77d7abef9c0 breaks the [Kitspace](https://kitspace.org) pages because we currently need the Gerber files in Git (not in zips). The pages are still up but won't update any more. The options to fix it:

1. Unzip the zip files
2. Wait for https://github.com/kitspace/kitspace/pull/216 and Kitspace will plot the Gerbers for you from the KiCad files

Which option would you prefer?

prasimix, 2019-12-21:
I'll unzip files, sorry that latest "clean up" actually made such a mess :)

prasimix, 2019-12-21:
Fixed

Closed 2019-12-21.

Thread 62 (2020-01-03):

Move BOOT0 Switch

prasimix, 2020-01-03:
Suggested by JBB: https://www.eevblog.com/forum/projects/eez-h25005-a-possible-successor-of-eez-h24005-programmable-power-supply/msg2854548/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

Move BOOT0 switch from AUX-PS to MCU module

prasimix, 2020-01-12:
Fixed

Closed 2020-01-12.

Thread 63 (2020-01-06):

mcu KiCad files are obsolete

bvernoux, 2020-01-06:
mcu KiCad files are obsolete they use EEZ DIB MCU r1B2 when official latest version (Eagle files) is EEZ DIB MCU r1B6

It will be great add details in each directory that official design are done only on Eagle to avoid confusion and mistake if someone want to use/work with latest validated design files.

A must for a fully open source hardware (especially certified oshwa https://certification.oshwa.org/hr000002.html) will be to have all latest design files converted to fre/open source software and here especially the amazing KiCad

goran-mahovlic, 2020-01-06:
Maybe we can try to convert latest version with https://github.com/lachlanA/eagle-to-kicad
I am also not Eagle fan!

goran-mahovlic, 2020-01-06:
@bvernoux for test I have converted bp3c board so you can check, and tell if you have any suggestions - I will convert rest of them on my repository ...
https://github.com/goran-mahovlic/modular-psu/tree/master/bp3c/KicadFiles

goran-mahovlic, 2020-01-06:
Seams that new kicad knows to do conversion without scripts, so I will try that way

bvernoux, 2020-01-06:
Yes it is advised to do it directly with latest KiCad 5.1.5 (but anyway it often requires some manual fixes)

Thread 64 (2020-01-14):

DCM220 UART Tx control

prasimix, 2020-01-14:
UART Tx signal goes to MCU Din/UART Tx via digital isolator. That isolator output has to be controlled by module BOOT0 signal to avoid DCM220 interference to Din when UART is not used (firmware download procedure).

prasimix, 2020-01-14:
Fixed

Closed 2020-01-14.

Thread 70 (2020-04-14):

Move BOOT0 to USER SW

prasimix, 2020-04-14:
Instead of using dedicated BOOT0 switch, that function can be assigned to the USER SW in the first few seconds after the powerup/restart (i.e. hard reset). That would require e.g. one flip-flop and GPIO line.

prasimix, 2020-05-02:
Proposal (requires D-FF only):

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

prasimix, 2021-02-15:
Fixed

Closed 2021-02-15.

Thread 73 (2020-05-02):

Replace vertical with horizonal battery holder

prasimix, 2020-05-02:
Move speaker and EEPROM down below and put horizontal SMD battery holder as replacement for existing vertical THT battery holder.

prasimix, 2021-02-15:
Fixed

Closed 2021-02-15.

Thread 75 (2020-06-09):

Assign SPI CSA outputs to NSS "hardware" pins if possible

prasimix, 2020-06-09:
For SPI communication chip select (NSS) could be "software" or "hardware" controlled. Try to assign SPI CSA output for all three SPI channels (SPI2, SPI4 and SPI5) to correspond with "hardware" NSS selectable via CubeMX.

prasimix, 2021-02-15:
Fixed

Closed 2021-02-15.

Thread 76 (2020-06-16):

Optional connector for capacitive touch controller

prasimix, 2020-06-16:
Check if support for capacitive touch controller could be added in parallel with existing resistive touch. It seems that some display models offers I2C connection to capacitive touch controller using separate connector. In that case one could upgrade existing resistive to capacitive by replacing display and soldering extra connector. Of course, we need to add support for capacitive touch in firmware.

prasimix, 2021-01-24:
Capacitive touch has connector on "wrong" side and will interfere with existing 5-pin 3.5" terminal connector.

Closed 2021-01-24.

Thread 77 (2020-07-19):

why current and voltage control outputs are connected together

sfmth, 2020-07-19:
The output of current and voltage control poop are connected together and they go to the base of the main power transistors
How does a single wire control both current and voltage. The two control loops will just fight each other

prasimix, 2020-07-20:
Take into account D12 and D13. In normal operation (i.e. most of the time) only one control loop has control over pass transistors. They are programmed separately with U_SET_OUT and I_SET signals that comes from DAC (IC16).

sfmth, 2020-07-20:
Oh yeah right,
Thanks

Closed 2020-07-20.

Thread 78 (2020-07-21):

dcp405 cc/cv switch mechanism

sfmth, 2020-07-21:
How do you control the cc/cv mode. I mean does the mcu decide which to enable or do they switch on their own

prasimix, 2020-07-21:
Connected load and set output voltage and current defined mode of operation. MCU role is only to set output params. For example if U_SET is 10 V and I_SET is 1 A, in accordance with Ohm's law, load with resistance of 10 Ohms or more sets CV mode, and for lower resistance it will switch to CC mode since it cannot deliver more then 1 A.

sfmth, 2020-07-21:
When the output voltage is 10v and current set for 1A, we connect a 20 ohm load. How is it that the current comtrol loop doesn't try to drive the main control transistors to get a 1A feedback

prasimix, 2020-07-21:
> When the output voltage is 10v and current set for 1A, we connect a 20 ohm load. How is it that the current comtrol loop doesn't try to drive the main control transistors to get a 1A feedback

Because output of DCP405 as any other available power source is not an ideal current source. It is not ideal voltage source either. Ideal current source has infinite open loop voltage. Therefore, if you set its output to 1 A it can provide it with any load, and for 20 Ohm it will deliver 20 V, and not 10 V as in our example.

sfmth, 2020-07-21:
U_set is 10v, I_set is 1A  , load is 20 ohms.
Current control loop will try to provide 1A and would set the output voltage to 20v. But the  voltage control loop is set to 10v and tries to drive the output down to 10v rather than 20v . Now we will have a fight between The voltage regulating and current regulating OpAmps.
How did you prevent this in your design

prasimix, 2020-07-21:
There is no fight as can be proven with measurements. You have to take into account initial state and finite time to reach any of set values, and that CC loop is by design slower then CV loop. Therefore set voltage always takes precedence over set current. In our example if voltage is set to 10 V that is a max. final value under normal condition. Only in error condition, e.g. major fault or externally applied voltage source with more then 10 V and enough current capability may lead to an increase in voltage. In that case software or hardware OVP will trip and turn off DCP405 output (if they are enabled).

sfmth, 2020-07-21:
Oh, so that's why LTC2050HV has a bandwidth around 1kHz rather than 10kHz on TL072

sfmth, 2020-07-21:
Oh, so that's why LTC2050HV has a bandwidth around 1kHz rather than 10kHz on TL072

Closed 2020-07-23.

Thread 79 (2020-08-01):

any comments on my project?

sfmth, 2020-08-01:
https://github.com/sfmth/heirs-cheap-diy-bench-power-supply

Im working on a cheap purely linear bench power supply I would be glad to hear your professional opinion on my project.

The readme.md was a readme at first but turned into a design idea diary

I don't have a power supply and they are kinda expensive in my country so i decided to make one

prasimix, 2020-08-02:
You have made the first good step, and it is the specification that will lead you to the desired goal. The real job is just waiting for you in a few years (or sooner) with enough effort and time you will probably get what is on the list. I wish you great success.
I guess you have some kind of oscilloscope on hand because it is an unavoidable tool in the more advanced stage of development and testing. Of course, it would be very useful to have some lab bench power supply, but yes, you just have to put it together :)

sfmth, 2020-08-03:
Thanks, unfortunately I don't have an oscilloscope, all I have is a 5$ multimeter. I'm gonna go with it, maybe make an oscilloscope when I needed one :)

Closed 2020-08-04.

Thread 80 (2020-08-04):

IC9B gain tolerance effect on the adc reading

sfmth, 2020-08-04:
IC9B has a variable gain and thus the V_MON can vary to 10 mV. And it would affect the readings of a 16-bit adc. How do you compensate for that

prasimix, 2020-08-04:
Variable gain, in which domain DC or AC? U_MON can vary even more up to 50 mV but for less then 50 us as measured with transient load tester (i.e. AC domain). That will not affect U_MON reading using ADC (which is effectively only 15-bit in best case) since its sampling rate is very slow (2 KSPS max.).

sfmth, 2020-08-05:
No, I mean the inaccuracies due to component tolerances  in the gain of the IC9B. Just 0.1 percent tolerance in the resistors can cause a variation of 10 mV between different products. Not in microseconds, the resistor values can't change that fast. Just between different products. And the U_MON can have 10mV tolarance, so when you multiply the readings of the adc by a preset value in software the readings wouldn't be accurate as the gain has tolerances and we are using a preset multiplier in software which can't compensate for the tolerance of the gain. I guess this would require calibration of each device but I didn't see that mentioned anywhere. Without calibration this would bring the accuracy down whilst the adc can do much better

prasimix, 2020-08-05:
Parts tolerances are not an issue if you can count on calibration. TCR is more important. This is especially evident on the Hi current range Rsense (R67) and this resistor is specially selected.

prasimix, 2020-08-05:
BB3 section in User manual about calibration: https://www.envox.hr/eez/eez-bench-box-3/bb3-user-manual/12-power-modules-calibration.html

sfmth, 2020-08-11:
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
Got my first oscilloscope today for 35$, you can't find a scope like this for less than 200$ here , this guy was kind and sold it for cheap to me. He has a electronics shop in the town

prasimix, 2020-08-11:
Great, that is a good step in right direction.

sfmth, 2020-08-15:
How did you filter the switching noise going to the regulator? I tried some filters but didn't remove it that well

prasimix, 2020-08-17:
Switching noise is not as simple to measure as it is advertised. You have to be well equipped (scope, probes, termination). Moving probe for just one millimeter could make huge difference. [Here](https://www.envox.hr/eez/eez-bench-box-3/eez-bb3-measurements/dcp405-power-module.html#dcp405_pard) you can find used measurement setup for power output PARD, and the same is applicable for measuring switcher power output.
Filtering is required on both input and output side of the switcher and you can count on considerable attenuation with simple filters (e.g. output LC filter). Measurement has to be done on more or less finalized design i.e. soldered and wisely placed components on the PCB (forget about breadboards/protoboards).
Even if you made reasonably silent switcher that is still not a guarantee at all that such design will pass EMI radiated emission testing (if you even came into position to certify your end product). On current power modules (DCP405 and DCM220) you can see input filters (against noisy Mean Well) and output LC filters.

sfmth, 2020-08-17:
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
Well this is the noise I'm trying to eliminate, I managed to get it 10 dB down with an active RC filter.
It has a big amplitude at 500khz, I don't think there would be that much of common mode noise, I'm running 2meters of wire from a fixed switching supply to my breadboard.
I'm trying hard not to use an inductor for the best transient response, how would I get a better filter without an inductor?

prasimix, 2020-08-18:
At what point was this measured? Switcher output after RC filter? Please explain "active" RC filter. Does it include op-amp or similar additional circuits?
If you are using switcher as power pre-regulator, good transient response doesn't mean a lot, because final stage (linear post-regulator) will be in charge of good transient response.

sfmth, 2020-08-18:
This was measured at the tip of the cable going to the breadboard. It's a switching powersupply. I just want to make my design compatible with high input noise.
Here's the files
https://github.com/sfmth/heirs-cheap-diy-bench-power-supply/tree/master/Experiments/switching%20noise%20rejection%201.0

prasimix, 2020-08-19:
Forget for a while features of power source for your linear post-regulator stage. Make one step at the time: if you want to build post-regulator first, then make sure that it is powered from decently regulated source and make sure that it behaves correctly. First you have to achieve stability in all mode of operations, then you can start to dream about PSRR and other things.
When you got good post-regulator stage in next step you can start to think about your own pre-regulator, and if it is going to be a switcher, and want to make it silent enough you have to design it on the PCB. Think about 4-layer but you can start with 2-layer and difference could be significant.

sfmth, 2020-08-19:
Oh thanks a lot, I actually ordered some parts for the post regulator, I decided to work on this until they arrive. So I would focus on the post regulator and when finished I'm gonna go over other stuff. I actually wanted to make a separate switching pre regulator on a separate board and just make the pre regulator optional. Without the pre regulator the consumer gets less noise and less price.

prasimix, 2020-08-20:
Less noise? If you continue, you will quickly find out that there are a number of other problems and that the output noise will not be a priority. Beware, there is a lot of talk about low output noise, it's nice to dream of noise below e.g. 1 mVpp but that in itself doesn't mean much because the devices in this class come with a number of other hard-to-achieve features (long term precision and stability, fast response, lots of protections, etc.).
I believe you are aware that some kind of pre-regulation should exist and that it is not a fancy supplement but an inevitable thing (e.g. "entry level" pre-regulation is multi-tap transformer with relays). Therefore, I do not know what it would mean to offer a solution _with_ or _without_ pre-regulation. I would also recommend that you concentrate on a solution that will first satisfy all of your requirements that you will be able to prove to yourself over a period of time, and then possibly think about “customers”. If you set out to do this just for the sake of income/profit, there are other (and faster!) ways to do that. One of them would be to clone or organize the production of, say, EEZ H24005 :)
Don’t forget LTspice or similar simulators. They can significantly speed up wandering and finding an acceptable path before you spend a cent on buying components.

prasimix, 2020-08-24:
Use LTspice and it can give you many answers without wiring a single part on your breadboard.

sfmth, 2020-08-30:
Sorry if I answer this late, I was busy migrating to Arch Linux and doing a freelance job. Yes I know there should be at least transformer taps, I just wanted to make the switching buck converter pre-regulator optional. I'm planning on designing a novel & seamless analog switching system that switches between the taps. In the [PSL-3604](https://www.eevblog.com/forum/projects/diy-bench-power-supply-psl-3604/) there was a '4-level supply' used for switching between taps, in my calculations that system dissipates more power than a normal relay controlled tap switching system, whilst he claims that it provides less dissipation. I'm doing this project to go through the different processes of designing a product and gain experience. I used LTspice and it was great, you can follow my project in my [repository](https://github.com/sfmth/heirs-cheap-diy-bench-power-supply).

prasimix, 2020-08-30:
> I'm planning on designing a novel & seamless analog switching system that switches between the taps. In the [PSL-3604](https://www.eevblog.com/forum/projects/diy-bench-power-supply-psl-3604/) there was a '4-level supply' used for switching between taps, in my calculations that system dissipates more power than a normal relay controlled tap switching system, whilst he claims that it provides less dissipation.

Then it is possible that your calculation is wrong or you're started with false assumptions. Leonid's design offers reduced or equal dissipation compared with relay switched pre-regulation but also excellent dynamic that you can simply cannot achieve even with the fastest mechanical relays. For example, try to program output from e.g. +5 V that belongs to "level-1" or lowest secondary and then switch it to +20 V that requires level-2 or higher secondary. And try to do switch that up and down with 50 ms cycle, add e.g. load that draws few amps and check what will happened with relays :).
From other side Leonid's design has higher dissipation most of the time comparing with switching pre-regulator.

sfmth, 2020-08-30:
Well in his design all the main mosfets have the same Vgs so they can only pass the same current, as each one is connected to a tap and they are in series, only the highest tap would be  supplying the current. If other taps supply any current the current wouldn't be the same on all mosfets

sfmth, 2020-09-01:
I ran a [simulation](https://github.com/sfmth/heirs-cheap-diy-bench-power-supply/tree/master/Experiments/Tap%20switching%20topology) in LTspice, and it doesn't work. can you take a look and see what's wrong?

prasimix, 2020-09-01:
I would recommend you to ask things like this on the EEVblog [forum](https://www.eevblog.com/forum/beginners/). For BB3 related stuff you can open new issues in GitHub.

Closed 2020-09-01.

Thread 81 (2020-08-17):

Replace OVP triac with SMD version

prasimix, 2020-08-17:
Check if possible to replace existing BTA26 in TOP3 package with similar device in e.g. D2PAK package.

prasimix, 2021-02-15:
Fixed

Closed 2021-02-15.

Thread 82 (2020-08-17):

DCM220 module upgrade to DCM224

prasimix, 2020-08-17:
As part of the CE certification testing upgrade DCM220 module to include the following changes:

- Move from 2-layer to 4-layer PCB and redesign switching loop
- Increase output voltage to 24 V
- Increase output current up to 4.9 A (calibrated)
- MCU controlled switching frequency. Use two dedicated outputs to generate counterphase switching frequencies (with or without dithering) for LT3763 controller
- Use two dedicated PWM outputs for power output PWM control (dimming) on the LT3763 controller
- Use external MCU xtal (for accurate switching frequency)

prasimix, 2021-02-07:
Fixed, a new repository for [DCM224](https://github.com/eez-open/dib-dcm224) is created.

Closed 2021-02-07.

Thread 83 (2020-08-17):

AUX-PS module modifications for CE testing

prasimix, 2020-08-17:
- Due to extensive conductive emission noise generated by combination of Mean Well IRM and LRS modules, a filter to suppress both DM and CM noise should be added to the AC input.
- Replace triacs with relays (the same model used on the BP3C module).
- Remove RC snubber
- Replace THT SAR with SMD package version
- Remove TVS protection
- Add the third MOV (L to N)

prasimix, 2021-02-15:
Fixed

Closed 2021-02-15.

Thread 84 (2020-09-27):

RTC calibration with mains frequency

prasimix, 2020-09-27:
STM32 MCU allows RTC calibration using mains frequency (50/60 Hz). It can keep RTC more accurate then 32.768 kHz XTAL if NTP/Ethernet connection is not available. In that case opto-isolated mains detection has to be added on the AUX-PS module, and few pins on the MCU side has to be swapped in order to bring mains frequency signal to RTC calibration input (PB15).

prasimix, 2020-10-02:
We need to test how RTC behave when MCU is turned off when `__HAL_RCC_LSEDRIVE_CONFIG(RCC_LSEDRIVE_HIGH);` is changed to high which is set by default to low.

prasimix, 2021-02-15:
Fixed

Closed 2021-02-15.

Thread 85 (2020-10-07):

Disable VBUS switch in bootloader mode

prasimix, 2020-10-07:
When MCU enters bootloader mode VBUS switch (TPS2051BDBVR) enable input is not defined. Therefore when MCU power is removed it continue to conduct and supply a whole MCU module. External pull-down (e.g. 10K) has to be added on that input to avoid such behaviour.

prasimix, 2021-02-15:
Fixed

Closed 2021-02-15.

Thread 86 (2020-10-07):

Add voltage divider on the VBUS sense input

prasimix, 2020-10-07:
The USB_OTG_FS_VBUS input is currently directly connected to the VBUS. According to discussion in this [thread](https://community.st.com/s/article/FAQ-Management-of-VBUS-sensing-for-USB-device-design) it shouldn't be exposed to voltage higher then +4 V. Therefore a voltage divider is required.

prasimix, 2021-02-15:
Fixed

Closed 2021-02-15.

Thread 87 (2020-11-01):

Allow external current programming?

madscientist159, 2020-11-01:
Is there a way, using the existing hardware, to allow for external current programming using the same input as would normally be used for external voltage programming?  This would be useful to integrate the BB3 into certain types of automatic test systems.

Thanks!

prasimix, 2020-11-01:
Currently that is not possible, but it can be added in the future revisions in the same way as with external voltage programming by adding another SN74LVC1G3157 and using one output pin on the I/O expander (we have one spare). Since there is not more space available on the module front panel, external voltage and current programming should share the same terminals. Therefore only one of them could be active in any moment, what shouldn't be a problem.

madscientist159, 2020-11-01:
I have a spare module and some time to play with this...I assume there are also firmware changes needed?  If I just wanted to hack a module into current only mode, would I need to add the IC or could I just reroute a wire or two?

electrokean, 2020-11-02:
@madscientist159 If you are happy to hack the board, then you could add a physical SPDT switch for this.  Look at the schematic page 4.  There is a jumper labelled "I_SET" (just "I" on the PCB) next to IC16 which you could cut.  The add the switch to select between shorting the jumper or injecting an external signal into I_SET.  You could/should reuse the RProg+ input and protection components for the injected signal.  Of couse it would be better to add another SN74LVC1G3157 controlled by GPB5, but that will  require firmware changes.

electrokean, 2020-11-02:
Oh, one word of caution - the I_SET signal is also sampled by the ADC.
I'm not sure if the firmware will get upset if it sees an unexpected value due to the injected signal.
You can probably find this out pretty quickly by just trying it, or with a bit of time spent reviewing the code.

prasimix, 2020-11-02:
I'm not sure that any kind of hack would be possible without intervention in firmware, e.g. if you want to use existing switch (IC17) for current, you'll lost control of set voltage, it will be zero, and in that case externally programmed current does not make any effect.

electrokean, 2020-11-02:
@prasimix I wasn't suggesting removal of IC17, just a similar set up to control I_SET from the external input.

U_SET control can of course bypass IC17 via JP2 - hey, I can use that on my board missing that part until the replacement arrives.

My area of concern was what does the firmware use AIN1 (monitoring of I_SET) for?
Does a wildly different value from the DAC set value cause a fault trigger?

prasimix, 2020-11-02:
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

Yes, that's right you can bypass IC17, but just wanted to say if you want to cheat existing firmware to control switch for current instead of voltage that won't work.

> My area of concern was what does the firmware use AIN1 (monitoring of I_SET) for?
> Does a wildly different value from the DAC set value cause a fault trigger?

I think that is not a case now, it is used for calibration only, but it could be used for undercurrent detection when output is in CC mode.

fietser28, 2021-01-27:
This enhancement is included in proposed design in #94.

Closed 2025-02-16.

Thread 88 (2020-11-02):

MCU: nRST should have cap to GND (not Vdd)

pigrew, 2020-11-02:
Schematics r2B4 show a capacitor C8 from nRST of the MCU to Vdd. This capacitor should be to GND (per dm00164549 hardware guide), to keep MCU in reset as the power rail is established.

(This is very minor, feel free to close this issue. I'm not sure if the design is finalized or not)

prasimix, 2021-07-19:
Fixed

Closed 2021-07-19.

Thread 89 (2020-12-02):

MCU board: STM32F769IGT6 or STM32F769IIT6?

MartinD-CZ, 2020-12-02:
When going thru the files I noticed that the main page readme states that the MCU board uses the IGT6, while the /mcu readme states that IIT6 is used (this is also in BOM). They differ only in flash size AFAIK, so can either be used or only the IIT6 with it's larger flash?

(this is pretty minor, but still, it might confuse someone).
Otherwise, excellent project with great documentation, thanks a lot.

prasimix, 2020-12-02:
Fixed

Closed 2020-12-02.

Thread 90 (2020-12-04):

Add reset/watchdog supervisor

prasimix, 2020-12-04:
Add supervisor IC such as STM6824 with "heartbeat" (WDI pin) generated by MCU.
Take care about start of "heartbeat" generation if USB OTG mode is selected (it could cause slight delay if nothing is connected to USB and supervisor will generate hard reset).

prasimix, 2021-02-15:
Fixed

Closed 2021-02-15.

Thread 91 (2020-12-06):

DCP405 BOM - R4 & R49 wrong footprint

MartinD-CZ, 2020-12-06:
These two resistors (item number 81 in the BOM) have their footprint specified as 1206, but their ordering numbers point to 2010 resistors. Also, their dissipation is specified at 0.75 W, which would be a lot for 1206. This applies to both the PDF and ODS versions of BOM.
So it's probably just typo and 2010 is supposed to be there.

prasimix, 2020-12-06:
Fixed

Closed 2020-12-06.

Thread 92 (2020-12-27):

DCP405: BOM vs schematic difference

MartinD-CZ, 2020-12-27:
The BOM specifies that R44 and R53 should be 16k, but the schematic specifies the same resistors as 10k.
What is the correct value? It's probably just a typo.

Thanks.

prasimix, 2020-12-27:
Fixed

Closed 2020-12-27.

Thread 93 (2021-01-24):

Decouple Rprog setting from internal GND of DCP405

fietser28, 2021-01-24:
In the current implementation of the DCP405 Rprog setting is done relative to the internal GND of the DCP405. This makes it impossible to connect a AWG with GND to protective earth (PE) AND also connect a scope (with PE to GND) to the - terminal fo the DCP405 due to the voltage difference between the GND and - output of the DCP405.

Attached schematic solves this use case: Both Rprog and the negative potential of the Load can be connected to PE.

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

- I did not test or design this for cases where PE is connected to the + side of the load (e.q. use the DCP405 to provide negative voltage).
- It looks like there is an 50mV offset in Rprog programming. This probably can be solved with the remark in the schematic. I did not test this.

This issue can be combined with #87?

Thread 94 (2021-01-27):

Rrpog output is limited to set voltage or current on DCP405

fietser28, 2021-01-27:
Make the rprog (voltage or current) donor the Vset/Iset limits.

In normal operation I always set things low to avoid magic smoke. With prog currently the voltage limit is completely off now. Looking into the schematics it doen't look hard to implement.

Attached is my proposed hardware change. It implements:
- #93
- #87
- limits the output voltage or current to the current set current (given by the DAC). The limit is set in software and enforced in hardware (for speed).

Except for the #93 part: It's a design only! I did not test this in hardware!

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

Explanation of the schematic:
- The TL072 with combined resistors implements #93
- The lower half if the schematics adds current setting thru Rprog (implementing #87). I used a free pin (pin 6 of IC13) to turn Rprog for current on/of. This is analog to the voltage setting circuit.
- The comparators LM293/LM393 compare the Rprog input voltage agains the output (Vset/Iset) voltages from the DAC. If the Rprog voltage is lower the analog switch will switch (thru AND gate) to the DAC output (where the limit should be set).

Impact on BOM:
- TL072, LM293, 2N7002 and SN74LVC1G3157 are already use so more of the same components. Parts with annotated numbers are already present in the current DCP405.
- New component is 74LVC1G08 (AND gate). I used a discrete logic gate to make sure the switching is fast (see the issue below).
- I did not check the C and R component but they are very common values.

Needed software changes:
- Addition menu to select current instead of voltage Rprog.
- Turning on/off Rprog for current should make pin 6 @IC13 (GPB5) high/low.
- During Rprog the set voltage or current should be send to DAC to set the upper limit (before turning Rprog on)

Possible issues.
There is a small race condition in this design: If Rprog steps above Vset/Iset, the signal will probably propagate thru the analog switch before it switches to the Vset/Iset limit due to the delay of the comparator, AND gate and switch. This is probably a very short period but is should be tested in the implementation if it is visible or problematic on the output (with or without load). E.q. will a step of Rprog above Vset/Iset cause an overshoot on the output of the DCP405?

prasimix, 2021-03-26:
Discussion opened on EEVBlog forum: https://www.eevblog.com/forum/projects/eez-h25005-a-possible-successor-of-eez-h24005-programmable-power-supply/msg3530232/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

prasimix, 2021-04-01:
This is a new proposal for Remote programming presented in #498.
Input op amp is changed to MCP6001 powered from single rail. LED driver is also changed, and 2G08 instead of 2 x 1G08 is used. I also added 10K on all comparator inputs.

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

prasimix, 2021-04-01:
New proposal with corrections suggested by Kleinstein [here](https://www.eevblog.com/forum/projects/eez-h25005-a-possible-successor-of-eez-h24005-programmable-power-supply/msg3539714/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):

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

prasimix, 2021-06-04:
The tiny PCB for testing latest schematics has arrived, just need to find time to fill it up and test it.

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

fietser28, 2021-06-04:
Nice, I have a EEZ-Flow to test most of it, but it's SCPI is written for a silgent AWG. It figures out (calibrates) the scaling and offset factor of the RPOG interface (and circuits in between), also if you are using scaling resistors in front of the circuit.
It also has a sweep to test the error (linearity) of the calibration over the whole range. Measurement and 'calibration' use the measured values from the DCP405 not an external DDM, I didn't need that kind of accuracy.

If you want to I can rewrite this so it can run with only a BB3 using:
- 1:  DCP405 using its rprog as input with this device connected (=DUT)
- 2: DCP405 to program the rprog (I'm not sure if the DCP405 is precise enough, but with some scaling resistors this can be fixed).
- 3: DCP405/DCM floating 5V for board power (if you connect the tiny board to the DCP405 internal V-/V+/GND you won't need this.

Just let me know, I just have to find 1-3 evenings to rewrite the EEZ-flow. It will be Voltage only, I can't risk losing my precious DCP405's, I use them. But once it does voltage, it will be easy to change to current.

Let me know.

prasimix, 2021-06-04:
I think that DCP could be precise enough, if not I can rearrange flow to use e.g. AOUT on MIO module. Anyway, no need to rush since I'll not be in position to assemble this PCB before end of next week. I have to prepare the latest AFE2 prototype first and will be busy with v1.7 testing, too.

fietser28, 2021-06-05:
Here is the flow to test rprog function. I ran this with the latest studio version from GitHub:
[RProgTester.eez-project.zip](https://github.com/eez-open/modular-psu/files/6603292/RProgTester.eez-project.zip)

It uses 2 DCP405 modules:
- channel 1 = module that is programmed via rprog (including modification or external opamp circuit)
- channel 2 = setting the input voltage for rprog testing.

The flow remembers the BB3 and the calibration data.

Using the flow:
1. Setup the hardware: output of module 2 should go to the rprog. Depending on the configuration you might have to connect the - output of module 1 and module 2 (when using the new circuit) OR NOT (direct connection on current DCP405 modules). Load is not really needed.
2. Setup BB3 settings: set module 1 in RPROG mode, for safety i usually set low current limits. Also set the OVP of module 1 to 40V.
3 Run the flow:
4 You have to select the BB3 and connect to it.
5. First time you run the flow you need to run the calibration (=button). This routine measures a low output and slowly increases the high output until 90%. After that is calculates the scaling and offset values (offset is usually equal to GCOM).
6. After calibration you can enter a desired output value, the flow will calculate the required voltage for channel 2 and set it.
7. After calibration you can run the 'errors check' routine. This is on a separate page and when you press start there it will sweep and show the % error between the output of channel 2 and channel 1 with respect to the calibration values.

The flow script honours the OVP setting of channel 1 and will not set higher values and the sweep will also be limited to it. Calibration DOESN'T honour OVP it goes to the max range for most accuracy.

If you put scaling resistors in front of the module, the script will still work. Just run a calibration and everything is adjusted.

I'm interested if setting the jumper to GCOM instead of GND will bring the offset to 0V instead of the 53mV.

And a screenshot:
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

The DCP405 is precise enough, although 5mV creates some noticeable steps, I worked around this by always comparing the measured values (with my AWG I only have set values).

prasimix, 2021-06-06:
Excellent job! I tried flow and everything works. Of course, some things could be polished a little more, for example:
1. Put channels in default at the start (* RST command) to know the initial state. For me, for example, the channels were coupled and in tracking mode, so I had to cancel it manually.
2. The `OVP set` always generates a beep even though the OVP is set successfully. This is confusing, but maybe this is a firmware bug. We need to investigate this.
3. I managed to get at the beginning that my control DCP (in slot 2) voltage rises over 2.5 V all the way to I think 39 V even though the channel output was in off state. I don't know how to repeat this again, but there will probably need to be added some additional check.
4. the `Set offset/DC` button should be enabled or disabled depending on whether controlled DCP (in slot 1) is in RProg mode or not. The same goes for `Error Check` and `Calibrate` buttons.
5. Of course pasting some comment here and there into the flow would be helpful :)

We also need better support for graphs in upcoming versions of EEZ Flow, for example to see labels on the X and Y axes. My graph currently looks like this:

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

Anyway, feel free to commit this flow at https://github.com/eez-open/studio/tree/master/docs/tutorial

prasimix, 2021-06-06:
> 2. The `OVP set` always generates a beep even though the OVP is set successfully. This is confusing, but maybe this is a firmware bug. We need to investigate this.

I found in BB3 Terminal lots of errors that were not visible during flow execution.  Some of them may be related to setting up an OVP trip. The situation should improve when EEZ Flow gets a debugger, or we will need to somehow display such errors during runtime to make it easier to modify the flow. Some of them may be related to setting up the OVP trip level:

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

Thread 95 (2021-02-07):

Dout2 power-up "glitch"

prasimix, 2021-02-07:
The Dout2 output will go high for a short time (600 to 1300 ms) after the power up. This does not happen during a software-generated restart. Further investigation is needed to determine source of this issue (is it hardware and/or software related).

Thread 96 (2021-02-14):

Replace power switching pre-regulator to pass EMC tests

prasimix, 2021-02-14:
DCP405 r2B11 cannot pass EMC tests on full load because power pre-regulator is too noisy. Build new pre-regulator based on silent switching controller such as [LM5145](https://www.ti.com/product/LM5145). Also use 4-layer PCB to improve cooling of that section.

prasimix, 2021-02-15:
Fixed

Closed 2021-02-15.

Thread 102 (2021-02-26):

Soft reset with MQTT enabled

NeuralSpaz, 2021-02-26:
Soft resets occurred with channel #1 DCP405 set for 14.1V and 900mA, fan was in manual 100% and MQTT period was 101ms.

I _suspect_ a slow mqtt publisher or server to be the cause that leads to a run away message queue and ultimately a out of memory error and the soft reset.

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

[profile.txt](https://github.com/eez-open/modular-psu/files/6048763/profile.txt)

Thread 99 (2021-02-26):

Time-based standby or disable all outputs

anmcn, 2021-02-26:
It would be handy to be able to set a system timer to set all outputs off, or enter standby mode (maybe set from system protections).

While similar "channel off" functionality can be achieved with a channel trigger list, it is a bit finicky to set up.

Some use cases might be an experiment that should not be left unsupervised (maybe interaction with BB3 would reset timer?), or just the desire to run some process for a limited time (battery charge? electrolysis? electroplating?) - per channel _might_ be useful, and it could be implemented as a channel protection, although that menu is already rather busy.

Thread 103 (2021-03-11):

AUX-PS module r3B5 is missing one mounting hole

prasimix, 2021-03-11:
Mounting hole where PE supposed to be connected disappeared in r3B5 version.

prasimix, 2021-03-13:
Fixed

Closed 2021-03-13.

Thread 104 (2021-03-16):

Add explicit power output to digital I/O port on BB3 chassis

fietser28, 2021-03-16:
To power small auxiliary extension that are connected to the BB3 it is usefull to have an additional port or make explicit which port power can be drawn from. These hardware extensions (sensors, switches) are very powerful in combination with the micropython capabilities of the BB3.

(As a workaround) it is now possible to use Dout2 (making it high) to power very small circuits.

Power can be low: e.q. 3.3V/25mA and might nog even require a hardware change, just labeling and documentation and maybe an explicit software feature instead of 'output high'.

A bigger change would be to add an additional power only pin, but this is not backwards compatible with current systems.

prasimix, 2021-03-16:
We could also add switch that could reroute VBUS controlled by IC11 (TPS2051) to Dout2 terminal.

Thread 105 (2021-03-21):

SDcard socket footprint improvement

prasimix, 2021-03-21:
Update SDcard socket footprint in accordance with PCBA contractor recommendations.

prasimix, 2021-03-26:
Fixed

Closed 2021-03-26.

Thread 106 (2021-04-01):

Oscillation between CC and CV while charing batteries

willg, 2021-04-01:
This was discussed on the EEVblog [here](https://www.eevblog.com/forum/projects/eez-h25005-a-possible-successor-of-eez-h24005-programmable-power-supply/msg3411354/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), and Discord [here](https://discord.com/channels/511131497801973761/511133610556784640/824318110218977370) but the BB3 will oscillate between CC and CV modes while charging a battery when the battery voltage gets within ~10% of the CV set point.  This occurs because Q27 is turned on when CC becomes active, and the CV set point drops with the addition of R118.  When charging a battery, this voltage drop the causes the battery charge current to drop below the CC set point, Q27 turns off, the voltage set point rises and the supply oscillates.

I've used a variety of other supplies in this exact same way and I haven't observed oscillations like this.

prasimix, 2021-04-04:
This issue require firmware change as reported in [#177](https://github.com/eez-open/modular-psu-firmware/issues/177) and removing of Q27 in r2B11 version or Q10 in r3B3 version of the DCP module. That MOSFET was added against power up overshot on lower set output voltage. For example without MOSFET when output voltage is set to 2 V, output voltage without load look like this:

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

If small ramp is applied (2 ms) this issue vanished:

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

willg, 2021-04-06:
Removing Q27 and adding the 2ms ramp looks like a nice solution to me.

I'm happy to modify one of my DCP405s and help test out the change once [issue #177](https://github.com/eez-open/modular-psu-firmware/issues/177) is implemented.  Thanks again for taking the time to work on this!

prasimix, 2021-04-11:
Ramp is needed on both power up and OE on if set current is below 170 mA.

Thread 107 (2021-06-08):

DP405.r2B11: Inductive spike on output may damage Q8

gregdavill, 2021-06-08:
I'm not sure this is something that actually needs to be actioned, but thought I'd open an issue to get your thoughts, and have it available here on github.
(This is a summary of a twitter thread: https://twitter.com/GregDavill/status/1400034208580390915)

## What happened ##

I was powering a very cheap 25W LED panel with an inline controller, the controller only has ESR ceramic caps on it's voltage input.
The power supply was set to 12V and was supplying the LED panel with ~2A of current.
It was connected to the power supply with alligator clips, these came loose, and the light went off, so I simply re-attached it.
There was a decent, and audible, spark when I reconnected the alligator clip.
The light was back on, and I continued my work.

A minute or two after I noticed a slight burning smell, and another pop. That's when I noticed that the power supply was showing 13V, instead of 12V...

When I disconnected the LEDs the power supply wasn't regulating correctly and outputting the full ~40V.
As a result, not the original fault, the load resistor, `R29`, in the down-programmer had literally popped.

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

I went through the circuit to work out why the `Q3`/`Q4` were basically being left on, when diode checking Q8 I noticed it's collector basically shorted to it's emitter. So I ordered a replacement.
I also noticed some residue on `R49` so I also replaced it, but that may have been fine.

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

With these parts replaced the module is working again.
Thanks! The fact that the design is open-source meant I could quickly fix it myself. :)

## Why it happened ##

I'm not 100% sure here, but I suppose that the combination of low ESR capacitors in the LED controller, and inductive cables running to the alligator clips created a >100V spike which simply passed through `Q4`/`Q3`, `R35`/`R34` and still had enough energy to damage `Q8`. The datasheet for `Q8` lists it's breakdown voltage at 140V,100uA.

If I'd had OVP enabled `R29` likely wouldn't have be damaged. But I'm unsure if `Q8` would have been saved, inductive spikes are very rapid.

## Potential fix ##

If this is the cause of the failure, a TVS diode with a 50-100V rating on the input would help absorb energy from inductive spikes before it makes it back to more sensitive components?

Another option is adding some bulk capacitance to the output. I've seen this employed on some other PSU designs. But that may have unintended consequences.

prasimix, 2021-06-08:
> If this is the cause of the failure, a TVS diode with a 50-100V rating on the input would help absorb energy from inductive spikes before it makes it back to more sensitive components?

The thing is that we have a 51V TVS on the power output (ZD5, see sheet 6/6), the question is still what is really happened. We definitely need to spend some time trying to reproduce this issue.

gregdavill, 2021-06-09:
> The thing is that we have a 51V TVS on the power output (ZD5, see sheet 6/6), the question is still what is really happened. We definitely need to spend some time trying to reproduce this issue.

Oh! You're right. Then I have no idea how this happened. :confused:

prasimix, 2021-06-25:
We still cannot reproduce this issue. However, there is some indication that this issue could be related to #108. If that is true then DP (down-programmer) should starts to overheat even when fast [list](https://www.envox.eu/eez-bench-box-3/bb3-user-manual/11-special-channel-functions/#bb3_man_ch_list) is executing. One can check that and keep eye if DP resistor will starts to overheat i.e. start to smoke. If that happen, then adding X2 cap on any of Mean Well's AC inputs could make a real difference.

prasimix, 2021-07-01:
Two additional protection mechanisms have been added for the DCP405 module ([#195](https://github.com/eez-open/modular-psu-firmware/issues/195), [#202](https://github.com/eez-open/modular-psu-firmware/issues/202)) in firmware v1.7.

gregdavill, 2021-07-02:
Thanks!

gregdavill, 2022-06-16:
I'm really not having much luck with this module. :sweat:
I'll just add this here, because it's on the same module, so might be related to the original issue?
I thought I'd fixed the original fault, but after using this module for over a year at this point the channel stopped working again.

One thing I'd noticed, when it was working, even when the channel was off the CV/CC lights would toggle occasionally, which I thought was odd, because the other module doesn't do that. But it seemed to work when enabled so I just ignored it.

Currently the OVP kicks in every time I attempt to turn the channel on.
If I disable the OVP, the output just remains at ~40.5V.

I opened up the unit, and took the module out, seems like there was a fault with the fuse holder? Maybe a loose contact point. The top contact got hot enough to melt the plastic cover, along with _slightly_ charring the plastic base. The metal is very discolored.

I've not yet gone down the debugging rabbit hole. But have you seen this before in your testing?

Here are some photos:
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

prasimix, 2022-06-16:
No, damaged fuse holder is an indication that HW OVP tripped (as expected), i.e. triac is switched on and max. power is sourced from the power pre-regulator due to fact that post-regulator voltage control loop failed, hence you can measure more the 40 V on the output. You have to check Q8, R49 and Q9 at first place. If R49 even looks as it is undamaged, be sure that its resistance is within tolerance.

gregdavill, 2022-06-16:
Thanks for insight into the design. I suspect this end of holder got hot because it wasn't making perfect contact with the fuse, leading to an added resistance, especially considering the other end doesn't have the same damage.

I've removed the fuse, and pinched the wings on each end closer together. It's now holding the fuse much tighter.
I'll try to pick up a replacement soon, since in it's state it's likely not making the best low-resistance connection.

I've replaced Q8, R49 and Q9. Already had parts on hand. It has fixed the OVP issue, and the board seems to be regulating correctly again.

Could a loose fuse connection have caused the original issue a few years ago? Which seems to have happened again, damage to the post-regulator front end. (Ignoring the OVP induced damage, since that seems like a consequence, not a cause)

gregdavill, 2022-06-16:
Understood.

Unfortunately I don't seem to have any photos when the original fault occurred that show the fuse holder, so it's not easy to check to see if it was a potential issue back there. I notice that the unit does report an OVP error, and disables the channel if I jostle the fuse enough to the point it briefly disconnects. So that is reassuring.

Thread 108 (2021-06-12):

R4 overheats on the AUX-PS r3B3 module (green PCB)

prasimix, 2021-06-12:
**IMPORTANT: Only some BB3 kit version with 2 Mean Well LRS modules seems to be affected by this issue!**

R4 is located on the AUX-PS module r3B3 that looks like this (i.e. green PCB version):

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

---
_Possible remedy (**updated**): install RC snubber 1 uF (X2 / 300 Vac) + 47 R (3-5 W). Use e.g. heat shrink tube to properly insulate capacitor and resistor terminals. Capacitor's terminal pitch could be from 15 to 27.5 mm._

---

R4 which limits the opto-triac current in the soft-start circuit overheats if BB3 is switched on continuously for several days.

An indication that you may have this problem is over-temperature protection (OTP) tripping for the AUX temperature sensor (inside IC2 which is near R4).

The soft-start (inrush current) limiter circuit was not new to the AUX-PS module: it was literally copied from the H24005 PSU in which it has been running properly for years. However, the H24005 does not use the Mean well LRS F-model (full range or autoswitch) but one that has manual input voltage selection (115/230 Vac). So basically it's another model! Soft start uses two triacs that are controlled via the opto-triacs OK1 and OK2. It turns out that the Mean Well F-model in some way affects the operation of the opto-triac even when there is no load. In the long run, i.e. if your BB3 is turned on continuously for a week or more, the power resistor that should limit the current of the opto-triac overheats so much that it eventually burns out.
Why haven't I been able to notice this so far? For two reasons: I have BB3 active for at least 10 hours a day every day, and when I did continuous testing (which lasts for several days) then I did it with BB3 which had one modification on Mean well's which was one of the attempts to passes the current harmonics test. So I had 4u7/X2 capacitors connected in parallel at their inputs! Here are some pictures.
The resistor that looks good to me but not to @goran-mahovlic is the R4 which is under increased stress from Mean Well's F-model:

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

R4 temperature if two F-models are connected without added capacitors at their AC inputs (230 Vac):

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

... and it increases further.
If I connect a purely resistive load (230 Vac, 46 W halogen lamp) R4 temperature is just fine:

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

The same is true if I have capacitors added:

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

Detail of the connected capacitor on one of the Mean well's:

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

prasimix, 2021-06-12:
I can't test 115 Vac and 60 Hz here, I only have 50 Hz, but it seems that the situation is even more alarming. Fortunately, capacitors help in this case as well. Without capacitors (115 Vac / 50Hz):

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

... with added capacitors:

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

prasimix, 2021-06-12:
What will happen if R4 burns out? Soon after the power up DCP and DCM modules will report an error as they will get DC at their inputs only for a short time (as long as the soft-start sequence lasts when another triac will be used).
In short, no further damage should be expected.

goran-mahovlic, 2021-06-12:
https://youtu.be/KNH0OdQx7IY

johnsonm, 2021-06-12:
In the picture with the capacitor, do you also have another small component? Resistor or diode? At least on my screen, I can't tell...

goran-mahovlic, 2021-06-12:
@johnsonm I have asked the same - it is nothing important just resistor for quicker capacitors discharge after power down

prasimix, 2021-06-13:
The capacitor used is 4u7, X2 Kemet [R46KR447050P1M](https://hr.mouser.com/ProductDetail/80-R46KR447040P1M). A bleeder resistor can be connected in parallel (470K to 1Meg):

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

prasimix, 2021-06-13:
It seems that only one capacitor is needed, even if three Mean well's are used:

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

goran-mahovlic, 2021-06-26:
I could only find 0.47uF on some old power supply

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

After adding it many problems just dispersed:

Resistor R4 is not overheating any more!
With function generator I could repeatably get smoke out of DCP405 with setting voltage to 3.3V and current to 100mA with this capacitor it is working normally!
AUX OTP tripped after long usage is gone
I could not use function generator if OVP HW is set - it was activated in first few seconds, now it does not
Current showing on channel without load was much more noisy

I have two channel BB3 with two mean wells.

ochococo, 2021-07-01:
I have two DCP405. Powered up for months now (usually around 15W per channel, rarely higher). Zero issues.
Today I've added two `1uF WIMA MKS4 10% 400V` just to sleep better 🙂

Thanks everyone for sharing and @prasimix for transparency!

gregdavill, 2021-07-04:
I'd not known about this issue. But just today after having my unit powered for 10 minutes I bumped the table and I get a CH1-Ch2 Error message. I'm in Australia so running at 230V,50Hz.

Opening my unit I saw this.
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

And I can confirm that it's R4. It appears to gotten hot enough to melt the solder, and then after a slight bump it simply fell off.
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

I could do some tests later with a thermal camera this week if you want some more data from systems running at 230/240V.

xlfe, 2021-07-04:
Weird - I'm in Australia, and after 10/15 minutes not seeing any significant heat on R4[
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
](url)

gregdavill, 2021-07-04:
I must just have the worst luck with my unit then. :laughing:

I've gone ahead and installed 2x 1uF X2 caps.
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

While it helps... the resistor still reached ~88.0C after 5m of idle operation. (Measured with a kapton insulated thermocouple.)

I also took a short video with a thermal camera.
https://youtu.be/8bMoKZcSGj8

Unfortunately I don't own a radiometric unit, so I can't read off exact temperatures, only the thermal flux. The modified version I took a reading with the thermocouple right after capturing this video, which read 88.0C.

You can see the modified version does a _bit_ better than unmodified.

My local electronics store didn't have 4.7uF X2 caps. But I can order some with my next Digikey/Mouser order. Any other ideas about why this is happening? Or things I should try.

xlfe, 2021-07-04:
Hmm yeah that's strange. Not sure if it's relevant but my unit has three meanwell LRS-150-48s instead of two. I have a few R46KW447000M1K on the way. Happy to post one to you when they've arrived

prasimix, 2021-07-04:
@gregdavill this is really strange since @goran-mahovlic reported that only single 0.47uF rectify this problem for him. I tested it on my side with 4.7uF as already reported. I still don't know why combination of two Mean Well's makes this problem. For the test could you please try to disconnect one Mean well and make thermo measurement once again? Thank you very much for your patience.

prasimix, 2021-07-04:
I tried right now two new Mean Well randomly selected from piles and another AUX-PS "green" version. Not the slightest change in temperature can be measured on R4. See pictures (I used a wooden stick to make it easier to see on the thermal image where the R4 is). Still don't know why is that.

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
PyroDevil, 2021-07-04:
Right, its not about the MCU board version. The green Crowdsupply AUX PS is R3B3, and the blue CE certificed AUX PS board is R3B4.

thomasrussellmurphy, 2021-07-04:
> Thanks Thomas for all your valuable suggestions. It seems that some more detailed investigation is needed. At the moment I think we have a good solution that does not require any intervention on the AUX-PS module which is already retired and will no longer be offered. Also in the future Mean Well LRS will be replaced with EPP model.

Very good. The dual relay implementation in the current version of the AUX-PS will very definitely skip the troubles with triacs!

gillham, 2021-11-10:
Is the two channel Crowd Supply unit safe to purchase at this point?  Mouser shows 26 “CS-BB3-04” (two channel full) in stock.  They show 39 of the DCM220 module (CS-BB3-05) also but list it as End of Life.

Are the in stock units with Crowd Supply / Mouser known good or are they still selling known bad units?

I would like to get a BB3 but the current state of this issue and overall manufacturing has me somewhat concerned. I don’t really want to shell out nearly $1000 USD on something that includes numerous obsolete modules and known issues.

On the other hand the fix looks fairly straightforward (though it isn’t completely clear from all the comments this is the full final fix).

The availability of the newer units (with CE certification, EPP power instead of MeanWell etc) is vague enough at this point I’m wondering if I should just buy the in stock units from Crowd Supply and plan of modding them or using the End of Life DCM220 to avoid the issue?

I think some clarity on the current situation would help or those units are likely to be in stock forever as few people are likely to want a unit with a known failure out of the box for that price.

prasimix, 2021-11-10:
The Mouser / CS inventory is unfortunately anything but clear (at least for me). For example, at the beginning of the year, 65 sets of new BB3 - Starter kit (CS-BB3-03) were delivered, which have CE certified modules (this includes a new version of the AUX-PS module). They haven’t appeared on stock so far (and small chances have sold them out instantly). They also received over 70 pcs of DCM224 (CS-BB3-08) which are not in stock: unless they are the DCM220 you mention.
Maybe those two-channel BB3s on stock are actually Starter kits (CS-BB3-03) and DCP405 modules (CS-BB3-06), most of which should also be new (blue PCBs).

Related to the problem reported here with the old AUX-PS module: yes, adding a larger RC snubber has been proven to solve the problem.

electrokean, 2021-11-20:
Not sure when they were added, but I see 57 pcs of CS-BB3-08 now in stock at Mouser.  If those are DCM224 (no datasheet or info listed) then the price seems a little high at USD $250 vs EUR €177 (~USD $200).  But they are out of stock at Envox store, and if they had 70 then people are buying them.

prasimix, 2021-11-20:
Yes, CS-BB3-08 is DCM224.

gillham, 2021-11-20:
I attempted to contact Crowd Supply about this using their contact form on November 10th and never got a response other than the initial email telling me a ticket was opened.
Perhaps CS-BB3-08 being suddenly in stock is related to my ticket, perhaps not.

Considering all of the other things I've ordered from them, you would think they would be more interested in trying to sell me a CS-BB3-03.  Especially if they have 65 sets laying around in inventory somewhere.  :)

jeremyherbert, 2022-02-04:
@prasimix could you please confirm my understanding of the solution below (hopefully it can serve as a summary for others).

1. Buy a suitable 1uF safety capacitor, [example here](https://au.mouser.com/ProductDetail/KEMET/R463R410040M1M?qs=xHpv68zP4qc9WCi2Ex39gA%3D%3D)
2. Buy a 5W axial 47 ohm resistor, [example here](https://au.mouser.com/ProductDetail/TE-Connectivity-Holsworthy/EP5WS47RJ?qs=Odivq8ja526Qnei8GovsRw%3D%3D)
3. Connect hot/live/active (brown wire) to resistor, then to capacitor. Connect the other capacitor lead directly to neutral (blue wire). Heatshrink as appropriate.

Note: only one RC snubber is needed, even if there are three separate power supplies.

prasimix, 2022-02-11:
Yes, that's right.

vtegroup, 2022-03-29:
Any recommendations for a 120V 60Hz grid. Capacitor and resistor value to use.

jeremyherbert, 2022-03-29:
I think the parts listed above should work fine, they are rated for well over 120V

vtegroup, 2022-03-29:
Just think out load, I am not concerned with the rated voltage of the capacitor, but more with the values of the capacitor and the bleeder resistor for all users 230/120v. Why not use a  RC in combination with MOV as it is possibly due to transient/peak voltage.

Closed 2024-12-28.

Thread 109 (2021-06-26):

DCP module faults after running on function generator

fietser28, 2021-06-26:
Running FW 1.7-RC1.

Running the function generator on Channel 1 (DCP405) I get a module fault. I tried this a couple of times it happens between a few seconds after starting and 2-3 minutes. The BB3 and other modules keep working. A software restart solves the issue:
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

The offending function generator setting:
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

The output of the module looks like (nothing strange is happening):
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

No load (except for scope probes) was attached. Down programmer was on, current range was best.
Trying this with a 100ms period I couldn't reproduce the cash within 15 minutes.
Ethernet connection was active.
DCP405 is a R2B11.

prasimix, 2021-06-26:
Ok, that is a clearly result of newly introduced protection [#202](https://github.com/eez-open/modular-psu-firmware/issues/202). You don't have enabled neither SW or HW OVP.
What is the connected load?

prasimix, 2021-06-26:
Hm, if load not connected, and you didn't move probes that somehow ~3% overvoltage is detected. But signal on the scope looks fine. Please try to move lower level above 1 V, and see what will happen.

prasimix, 2021-06-26:
I managed to reproduce this on my side. It seems like a bug in #202.

fietser28, 2021-06-27:
I tried several variations: increasing/decreasing the lower limit, increasing/decreasing the amplitude, adding a capacitor and or resistor as load, but I can't find a consistent pattern when it happens more frequently. To really find it requires repeating (and writing down) but that might take some time. All without OVP.

On the scope the timing of the fault (output going to zero) always has the same timing pattern: around 5 ms after falling edge.

Looking at the code introduced in #202 I'm wondering if noise plays a role here: A single sample might be off and at lower voltages this is larger in % and more likely to trigger (at 1V, 3% equals 30mV)?

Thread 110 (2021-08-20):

Problem in dcm220/BOM/1-click-bom.csv

kasbah, 2021-08-20:
Hey, in [dcm220/BOM/1-click-bom.csv lines 55-56](https://github.com/eez-open/modular-psu/blob/master/dcm220/BOM/1-click-bom.csv#L55) the MPN columns seem to shift the distributor columns over.

Closed 2025-02-16.

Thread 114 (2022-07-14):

OVP PCB Inductor in DCP405 up in smoke

xlfe, 2022-07-14:
Made the mistake of connecting a battery thinking I could charge it, noticed some smoke and disconnected everything.

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

Can't see any other damage. The module passes power on checks, but doesn't seem to provide any output - I tried a simple 10v 10ma into a multi-meter and it reads 10v 10uA but no the multi-meter shows no voltage.

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

Any tips on next steps? should I clean up the PCB Inductor traces and do a more thorough test of individual components?

prasimix, 2022-07-15:
Could you please let me know what exactly you tried to do with battery.
As a first step, check if fuse F1 is OK.

xlfe, 2022-07-15:
Battery voltage was about 26v and I connected it to the main output on the module (+ve to +ve, -ve to -ve), set the module output to 28v and 1A and then turned the output on. OVP tripped immediately. after a few seconds I noticed the smoke, and disconnected the battery.

Just checked - Fuse 1 is fine, Fuse 2 is blown.
Also checked R93 next to Q13, and getting less than 0.5 ohms resistance

prasimix, 2022-07-15:
Ok, replace F2 and check if you can get set voltage output. You did something that is not allowed and I have to add a notice about that in the User manual: Never change output enable to ON when battery is connected and HW OVP is enabled!
What is happened: The voltage on the output was 26 V, you turned on the output that started from about 0 V. HW OVP detected huge difference in output voltage and immediately tripped. Battery is obviously still charged enough that triac drawn tens of amps but F1 was too slow to protect PCB inductor. Sorry for that, feel free to replace existing F1 and F2 with fast acting 5 A fuses.

prasimix, 2022-07-15:
>  Also checked R93 next to Q13, and getting less than 0.5 ohms resistance

That's fine, you can try to somehow bypass damaged PCB inductor.

xlfe, 2022-07-15:
ok thanks. Yes as soon as it happened I realized I should have thought more carefully about what I was trying to do!

What is the PCB inductor used for? Ie what's the effect of bypassing it?

prasimix, 2022-07-15:
> What is the PCB inductor used for? Ie what's the effect of bypassing it?

It is intended to limit max. current to preserve triac. We're talking here about a couple of hundreds of amps in microseconds. In most of the cases it should works just fine with inductor shorted.

prasimix, 2022-07-15:
The following warning has been added to the User manual ([Chapter 10.2](https://www.envox.eu/eez-bench-box-3/bb3-user-manual/10-channel-protections/)):

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

xlfe, 2022-07-17:
Thanks - bodge wire that replaces the PCB inductor seems to have brought it back to life! Phew. Thanks!

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

prasimix, 2022-10-06:
Remedy for this is suggested by @brianbienvenu in [#255](https://github.com/eez-open/modular-psu-firmware/issues/255) that is actually similar to [#9](https://github.com/eez-open/modular-psu-firmware/issues/9) which is changed now to P1 priority.

Closed 2022-07-17.

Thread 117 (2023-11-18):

Replace battery with supercap

prasimix, 2023-11-18:

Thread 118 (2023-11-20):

Replace mini-USB with USB-C socket on MCU module

prasimix, 2023-11-20:

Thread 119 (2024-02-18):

Consider reversing the air-flow of the BB3 enclosure.

fietser28, 2024-02-18:
Currently the fan of the BB3 pushes the air from the back to the front/top/side air vents.

If modules produce heat (for example an electronic load) and have vents on the front panel then warm or even hot air will blow in the direction of the user. This will be uncomfortable for hands during operation of the BB3.

I assume reversing is a matter of reversing the physical mounting of the fan and has no downsides to the rest of the system, but it should be tested.

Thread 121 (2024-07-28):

[BP3C] the BOM for r3B2 is missing / the two BOMs for r3B3 are inconsistent

loglow, 2024-07-28:
The BP3C board I received from the Crowd Supply campaign is **r3B2**. In fact, it's exactly the same as the board pictured [here](https://github.com/eez-open/modular-psu/blob/master/bp3c/Images/BP3C_r3B2.jpg). However, all of the BOMs in this repo appear to be for **r3B3**, which has some notable differences. I think it would make sense to continue to maintain an r3B2 BOM since a) this was the bare board shipped as part of the crowdfunding campaign, and b) this is the revision of the board pictured. Furthermore, the discrepancies between the two different r3B3 BOM files should probably be corrected.

### The 100k resistors are numbered differently

The r3B3 BOM [here](https://github.com/eez-open/modular-psu/blob/master/bp3c/EDA%20files/KiCad/bom/1-click-bom.csv) lists these resistors as R1, R2, R3, R4.

However, the r3B3 BOM [here](https://github.com/eez-open/modular-psu/blob/master/bp3c/EDA%20files/Eagle%20(obsolete)/EEZ%20DIB%20BP3C%20r3B3%20BOM.pdf) lists these resistors as R2, R4, R6, R8.

I don't know which BOM is correct for r3B3, but the r3B2 board differs from both. For r3B2, these resistors should be R1, R2, R4, R5. You can see this in the [photo of the assembled board](https://github.com/eez-open/modular-psu/blob/master/bp3c/Images/BP3C_r3B2.jpg).

### The 18V zener diodes are too small

The r3B3 BOM [here](https://github.com/eez-open/modular-psu/blob/master/bp3c/EDA%20files/KiCad/bom/1-click-bom.csv) lists 1 zener diode (ZD1) as an [onsemi MM3Z18VT1G](https://www.digikey.com/en/products/detail/onsemi/MM3Z18VT1G/921069) that comes in a SOD323 package.

However, the r3B3 BOM [here](https://github.com/eez-open/modular-psu/blob/master/bp3c/EDA%20files/Eagle%20(obsolete)/EEZ%20DIB%20BP3C%20r3B3%20BOM.pdf) lists 4 zener diodes (ZD1, ZD2, ZD3, ZD4) with the same part number.

Once again, I don't know which BOM is correct for r3B3, but the r3B2 board differs from both. For r3B2, these zener diodes are ZD1, ZD2, ZD3, ZD4 but their land patterns require a larger SOD123 part. I believe a [Diodes Incorporated BZT52C18-7-F](https://www.digikey.com/en/products/detail/diodes-incorporated/BZT52C18-7-F/815012) would be a suitable alternate; please let me know if this part substitution would be appropriate.

loglow, 2024-07-28:
Small update.

I did find the deleted r3B2 BOM file in the repo history [here](https://github.com/eez-open/modular-psu/blob/f18a5fb8516f9b534a6ef8a9ff22bf536067fc99/bp3c/BOM/EEZ%20DIB%20BP3C%20r3B2%20BOM.pdf).

The listed part for ZD1, ZD2, ZD3, ZD4 is an [SMAJ18A](https://www.digikey.com/en/products/detail/diodes-incorporated/SMAJ18A-13-F/814796).

Also, the resistor numbers in that BOM are correct (R1, R2, R4, R5).

I suppose it would have saved me some time if the Crowd Supply board revision hadn't been deleted.

Closed 2024-07-28.

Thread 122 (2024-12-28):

Where are the AUX-PS r3B4 module resources?

pierantoniomerlino, 2024-12-28:
I recently bought the AUX-PS PCB module. It is the r3B4 (09/2020) version and I discovered that the layout and schematics is quite different from the r3B7.
I search in the github repo (tags, branches and history) but I didn't found any info regarding that version. The r3B3 and r3B5 are available.

Where I can found the resoures for the r3B4 version?

prasimix, 2024-12-28:
You can find the requested information in the attached zip file...

[AUX-PS r3B4 (09_2020).zip](https://github.com/user-attachments/files/18265875/AUX-PS.r3B4.09_2020.zip)

pierantoniomerlino, 2025-01-17:
I apologize to bother you again...
I've also the MCU board r3B3 (09/2020) and I see some discrepancies between the components names in the board and the schematics I got from the repo.
For example, it seems that the C3 in the schematic is C4 on the board... Could you please point me to the correct resources?

Thanks.

prasimix, 2025-01-17:
You can find the requested information in the attached zip file...

[MCU r3B3 (09_2020).zip](https://github.com/user-attachments/files/18459640/MCU.r3B3.09_2020.zip)

Closed 2024-12-28.

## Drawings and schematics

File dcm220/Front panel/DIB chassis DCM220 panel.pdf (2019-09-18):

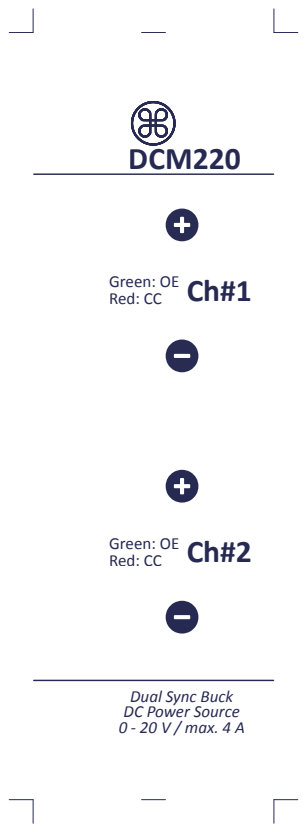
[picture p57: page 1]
Green: OE Red: CC; DCM220

Dual Sync Buck
DC Power Source
0 - 20 V / max. 4 A

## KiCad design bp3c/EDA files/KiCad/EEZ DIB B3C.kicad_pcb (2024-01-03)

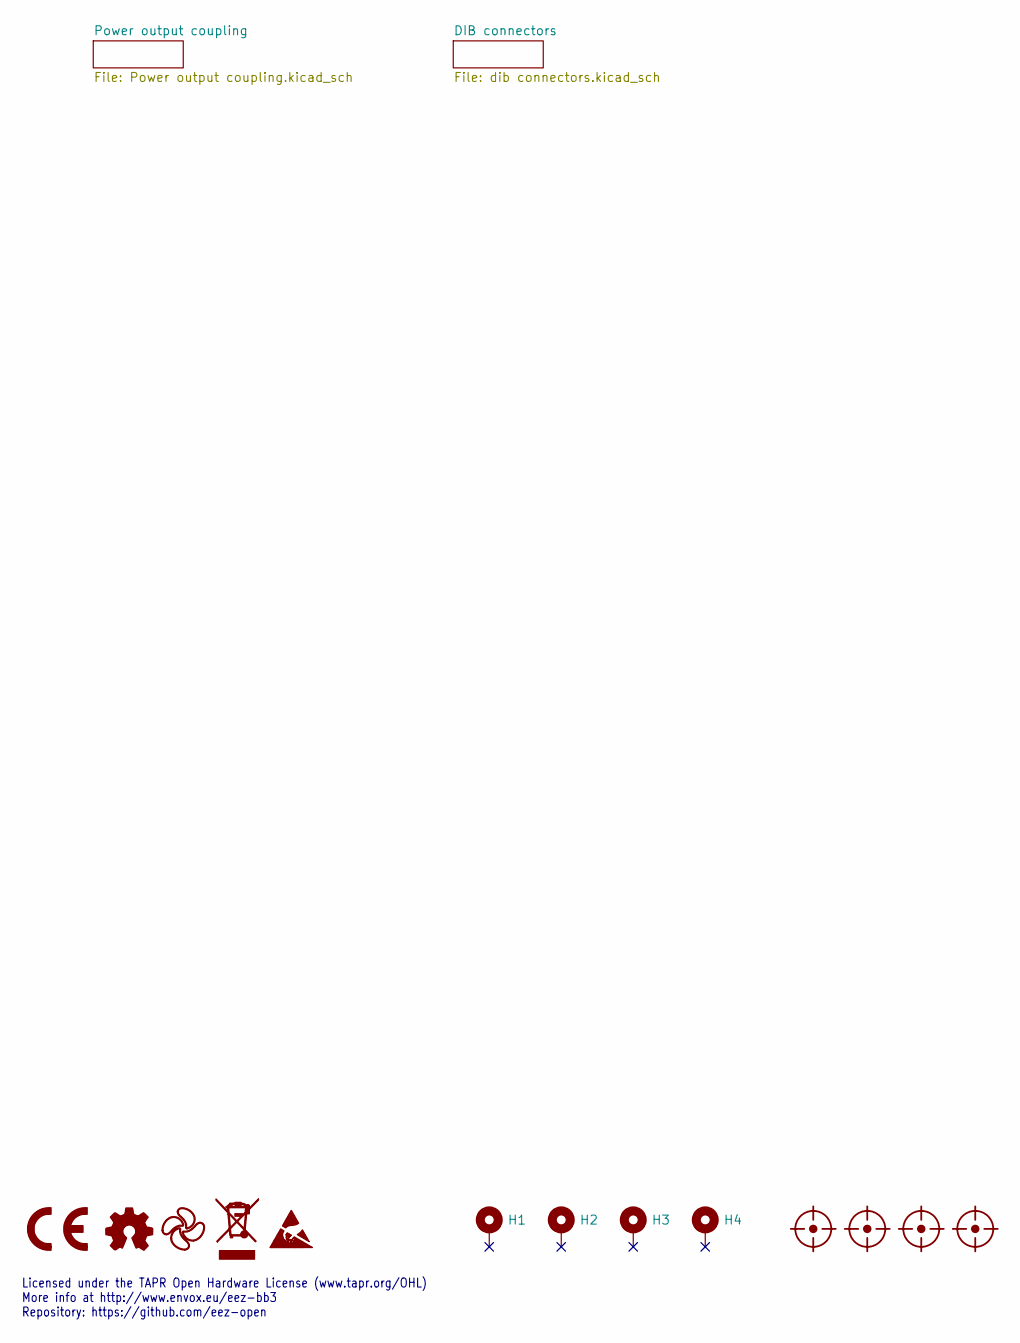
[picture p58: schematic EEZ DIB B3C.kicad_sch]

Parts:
FM1, FM2, FM3, FM4: FIDUCIAL; Fiducial
H1, H2, H3, H4: Mounting_hole 3.2_5.5mm
LOGO1: CR logo; CE logo
LOGO2: Open HW logo
LOGO3: EEZ logo; EEZ logo (outline 6mm)
LOGO4: WEEE logo
LOGO5: ESD logo

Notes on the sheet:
Licensed under the TAPR Open Hardware License (www.tapr.org/OHL) More info at http://www.envox.eu/eez-bb3 Repository: https://github.com/eez-open

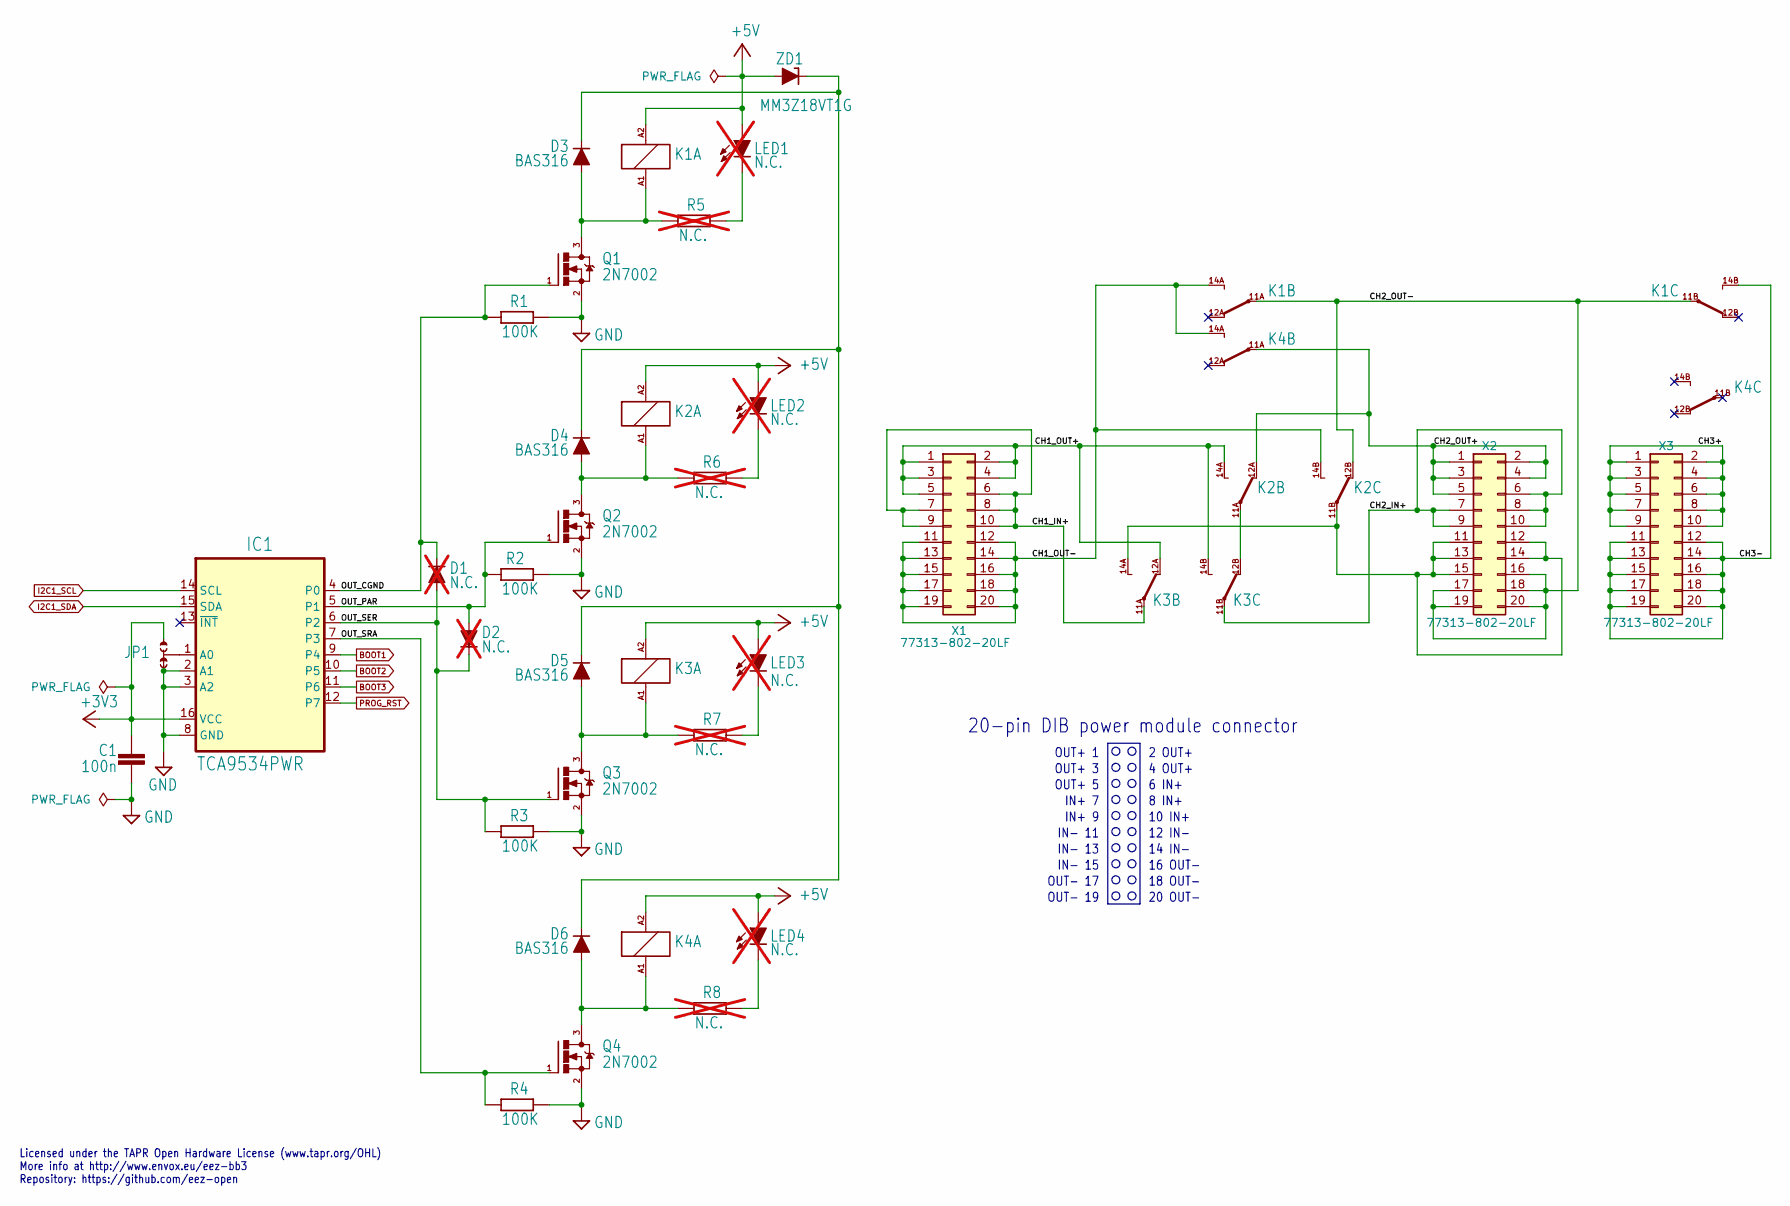
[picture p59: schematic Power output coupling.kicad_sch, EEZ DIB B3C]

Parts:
C1: 100n; C_0603_1608Metric; DigiKey 1276-1005-2-ND
D1, D2: N.C.; SOD-323_1P8X1P35_ONS-M; not fitted
D3, D4, D5, D6: BAS316; SOD-323_1P8X1P35_ONS-M; DigiKey 1727-7370-1-ND
IC1: TCA9534PWR; PW(R-PDSO-G16); DigiKey 296-40574-1-ND
JP1: JP3-CUT; JP3 shorted
K1, K2, K3, K4: RT424005; DigiKey PB1998-ND
LED1, LED2, LED3, LED4: N.C.; LED_LTST-C170KGKT_LTO-L; DigiKey 160-1414-2-ND; not fitted
Q1, Q2, Q3, Q4: 2N7002; SOT103P240X110-3N; DigiKey T2N7002AKLMCT-ND
R1, R2, R3, R4: 100K; R_0805_2012Metric; DigiKey RMCF0805FT100KCT-ND
R5, R6, R7, R8: N.C.; R_0805_2012Metric; not fitted
X1, X2, X3: 77313-802-20LF; DigiKey 609-77313-802-20LF-ND
ZD1: MM3Z18VT1G; SOD-323_1P8X1P35_ONS-M; DigiKey MM3Z18VT1GOSCT-ND

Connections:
+3V3: C1.1, IC1.16 (VCC), JP1.NO; also elsewhere on the board
+5V: K1.A2 (C1), K2.A2 (C1), K3.A2 (C1), K4.A2 (C1), LED1.A, LED2.A, LED3.A, LED4.A, ZD1.A; also elsewhere on the board
/Power output coupling/CH1_IN+: K3.11A, X1.6, X1.7, X1.8, X1.9, X1.10
/Power output coupling/CH1_OUT+: K2.14A (O), K3.12A (S), K3.14B (O), X1.1, X1.2, X1.3, X1.4, X1.5
/Power output coupling/CH1_OUT-: K1.14A (O), K2.14B (O), K4.14A (O), X1.11, X1.12, X1.13, X1.14, X1.15, X1.16, X1.17, X1.18, X1.19, X1.20
/Power output coupling/CH2_IN+: K3.11B, X2.6, X2.7, X2.8, X2.9, X2.10
/Power output coupling/CH2_OUT+: K2.12A (S), K4.11A, X2.1, X2.2, X2.3, X2.4, X2.5
/Power output coupling/CH2_OUT-: K1.11A, K1.11B, K2.12B (S), X2.16, X2.17, X2.18, X2.19, X2.20
/Power output coupling/CH3+: X3.1, X3.2, X3.3, X3.4, X3.5, X3.6, X3.7, X3.8, X3.9, X3.10
/Power output coupling/CH3-: K1.14B (O), X3.11, X3.12, X3.13, X3.14, X3.15, X3.16, X3.17, X3.18, X3.19, X3.20
/Power output coupling/OUT_CGND: D1.C, IC1.4 (P0), Q1.1 (G), R1.2
/Power output coupling/OUT_PAR: D2.A, IC1.5 (P1), Q2.1 (G), R2.2
/Power output coupling/OUT_SER: D1.A, D2.C, IC1.6 (P2), Q3.1 (G), R3.2
/Power output coupling/OUT_SRA: IC1.7 (P3), Q4.1 (G), R4.2
BOOT1: IC1.9 (P4); also elsewhere on the board
BOOT2: IC1.10 (P5); also elsewhere on the board
BOOT3: IC1.11 (P6); also elsewhere on the board
GND: C1.2, IC1.2 (A1), IC1.3 (A2), IC1.8 (GND), JP1.NC, Q1.2 (S), Q2.2 (S), Q3.2 (S), Q4.2 (S), R1.1, R2.1, R3.1, R4.1; also elsewhere on the board
I2C1_SCL: IC1.14 (SCL); also elsewhere on the board
I2C1_SDA: IC1.15 (SDA); also elsewhere on the board
unnamed: D3.C, D4.C, D5.C, D6.C, ZD1.C
unnamed: IC1.1 (A0), JP1.COM
unnamed: D3.A, K1.A1 (C2), Q1.3 (D), R5.2
unnamed: D4.A, K2.A1 (C2), Q2.3 (D), R6.2
unnamed: K2.11A, K3.12B (S)
unnamed: K2.11B, K3.14A (O), X2.11, X2.12, X2.13, X2.14, X2.15
unnamed: D5.A, K3.A1 (C2), Q3.3 (D), R7.2
unnamed: D6.A, K4.A1 (C2), Q4.3 (D), R8.2
unnamed: LED1.C, R5.1
unnamed: LED2.C, R6.1
unnamed: LED3.C, R7.1
unnamed: LED4.C, R8.1
PROG_RST: IC1.12 (P7); also elsewhere on the board

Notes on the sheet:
14 IN-
Licensed under the TAPR Open Hardware License (www.tapr.org/OHL) More info at http://www.envox.eu/eez-bb3 Repository: https://github.com/eez-open
OUT+ 5
6 IN+
12 IN-
IN- 15
IN- 13
IN+ 9
IN+ 7
IN- 11
16 OUT-
20-pin DIB power module connector
OUT- 17
OUT- 19
10 IN+
OUT+ 3
18 OUT-
OUT+ 1
2 OUT+
4 OUT+
8 IN+
20 OUT-

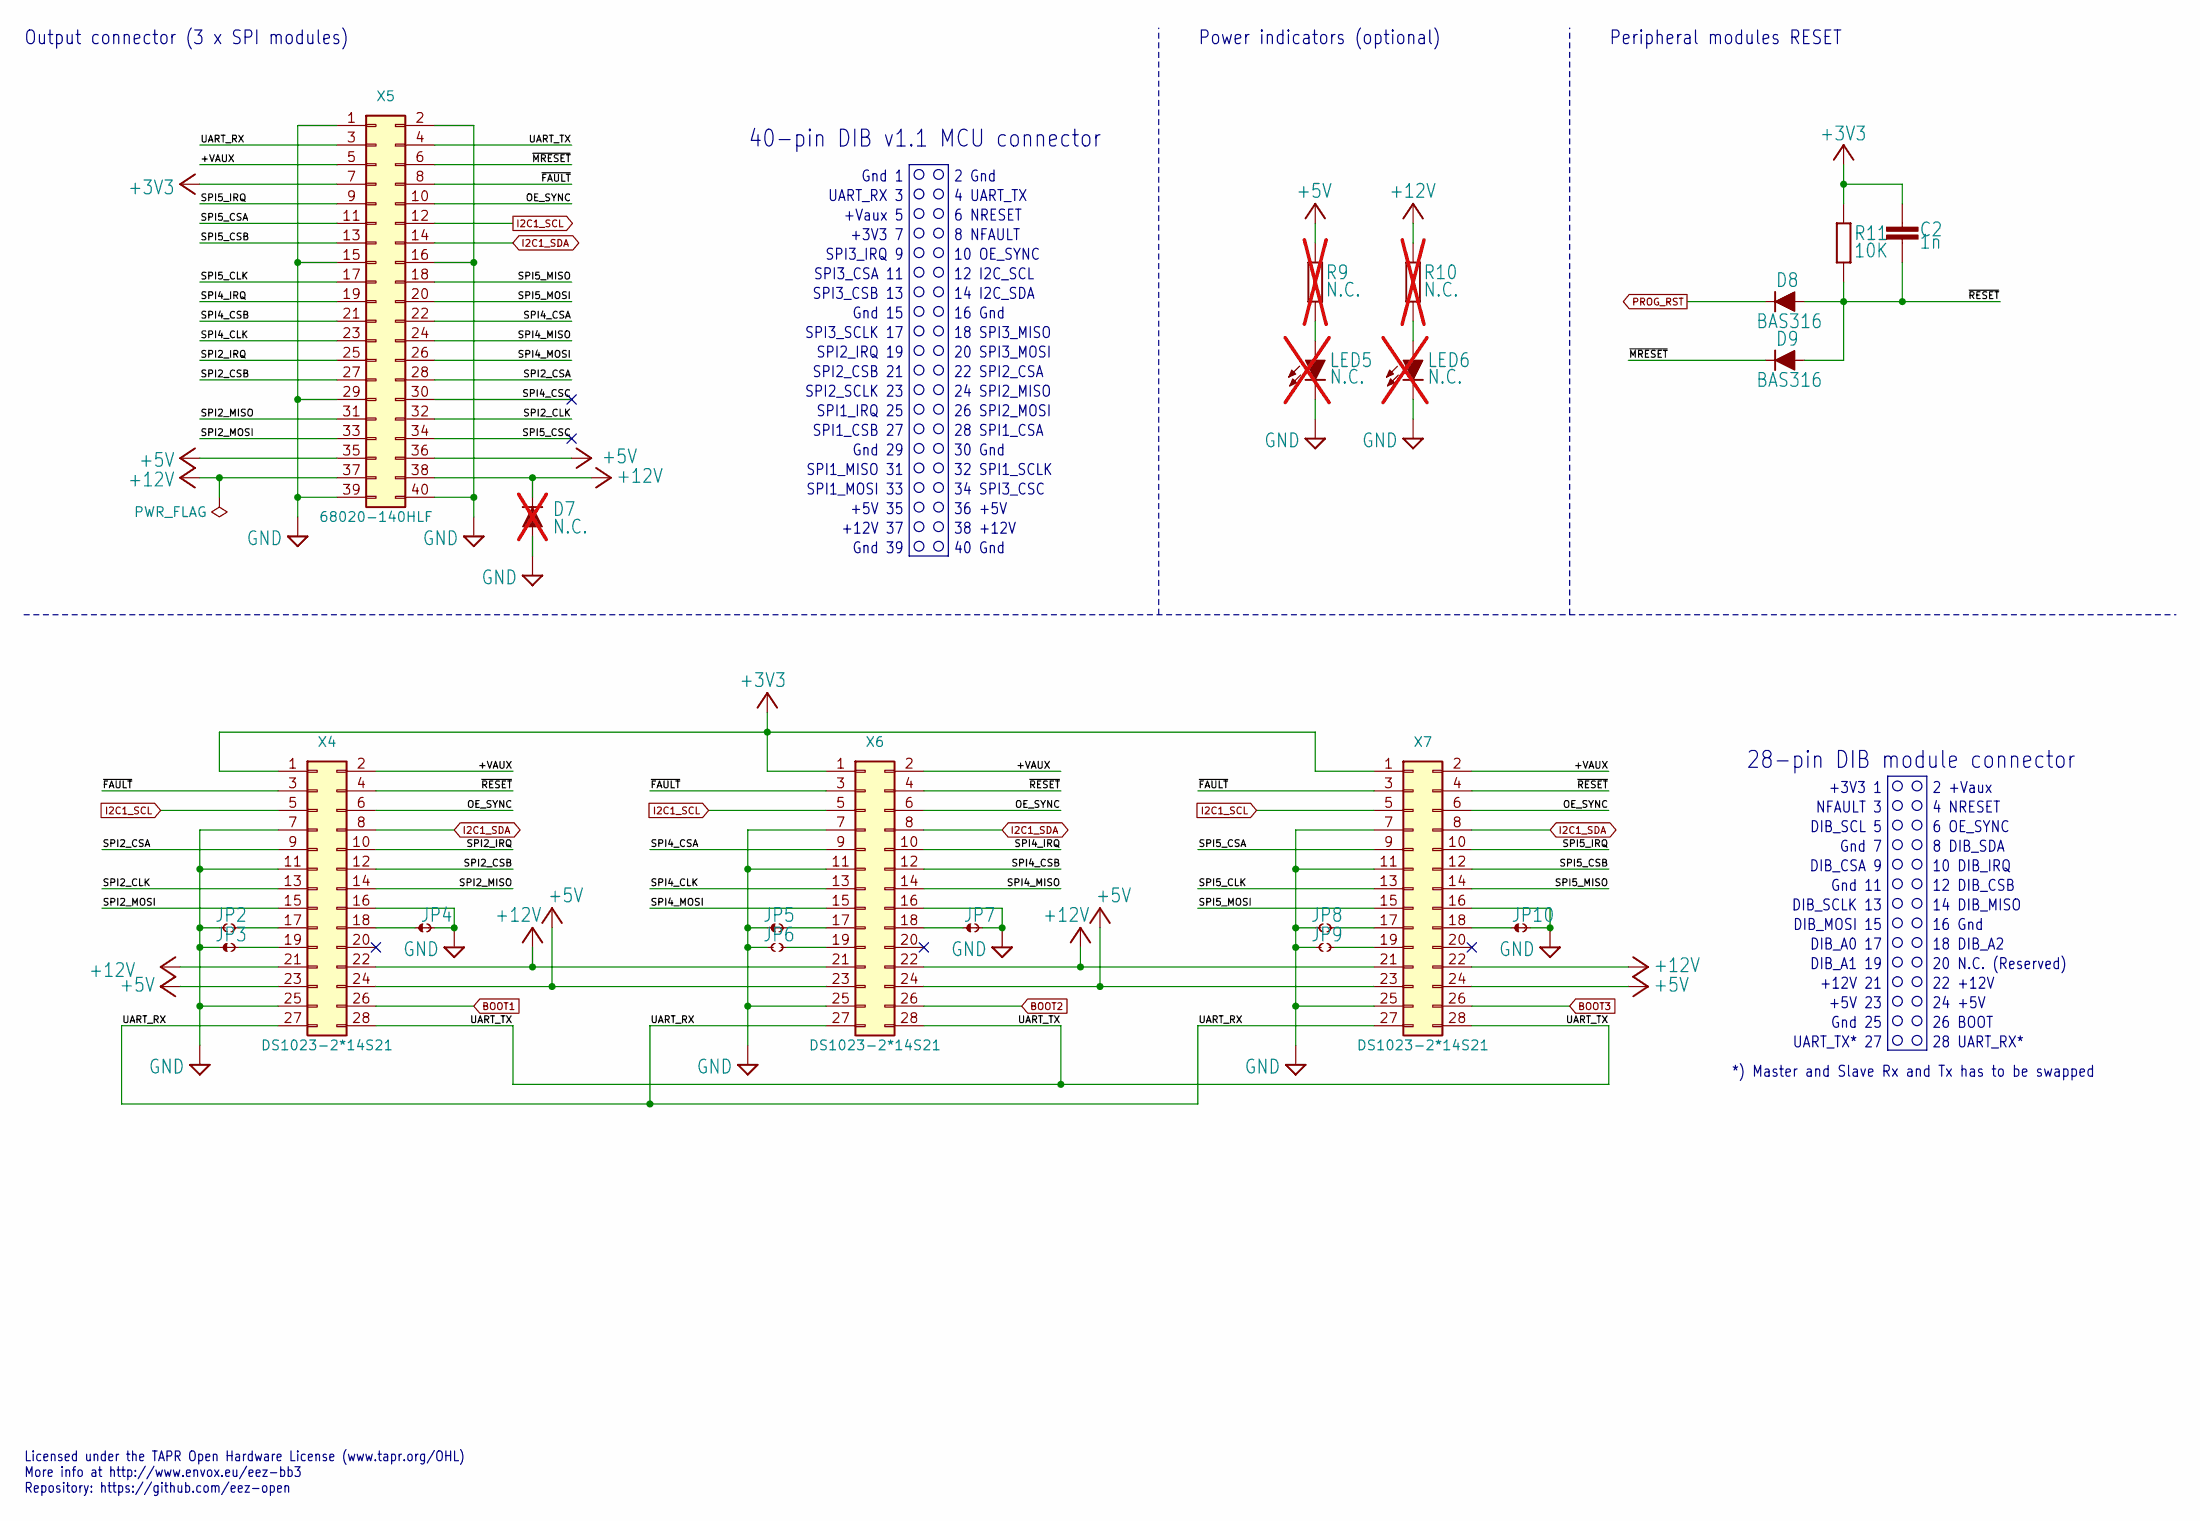
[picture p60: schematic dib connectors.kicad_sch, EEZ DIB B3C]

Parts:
C2: 1n; C_0805_2012Metric; DigiKey 732-7858-1-ND
D7: N.C.; DO214AA; not fitted
D8, D9: BAS316; SOD-323_1P8X1P35_ONS-M; DigiKey 1727-7370-1-ND
JP2, JP6, JP8, JP9: JP2-CUT; JP2 open
JP3, JP4, JP5, JP7, JP10: JP2-NOCUT; JP2 shorted
LED5, LED6: N.C.; LED_LTST-C170KGKT_LTO-L; DigiKey 160-1414-2-ND; not fitted
R9, R10: N.C.; R_0805_2012Metric; not fitted
R11: 10K; R_0805_2012Metric; DigiKey 311-10.0KCRCT-ND
X4, X6, X7: DS1023-2*14S21; TSW-114-07-F-D; DigiKey S7082-ND
X5: 68020-140HLF; DigiKey 68020-140HLF-ND

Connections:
+3V3: C2.2, R11.1, X4.1, X5.7, X6.1, X7.1; also elsewhere on the board
+5V: R9.1, X4.23, X4.24, X5.35, X5.36, X6.23, X6.24, X7.23, X7.24; also elsewhere on the board
+12V: D7.C, R10.1, X4.21, X4.22, X5.37, X5.38, X6.21, X6.22, X7.21, X7.22
/DIB connectors/+VAUX: X4.2, X5.5, X6.2, X7.2
/DIB connectors/OE_SYNC: X4.6, X5.10, X6.6, X7.6
/DIB connectors/SPI2_CLK: X4.13, X5.32
/DIB connectors/SPI2_CSA: X4.9, X5.28
/DIB connectors/SPI2_CSB: X4.12, X5.27
/DIB connectors/SPI2_IRQ: X4.10, X5.25
/DIB connectors/SPI2_MISO: X4.14, X5.31
/DIB connectors/SPI2_MOSI: X4.15, X5.33
/DIB connectors/SPI4_CLK: X5.23, X6.13
/DIB connectors/SPI4_CSA: X5.22, X6.9
/DIB connectors/SPI4_CSB: X5.21, X6.12
/DIB connectors/SPI4_CSC: X5.30
/DIB connectors/SPI4_IRQ: X5.19, X6.10
/DIB connectors/SPI4_MISO: X5.24, X6.14
/DIB connectors/SPI4_MOSI: X5.26, X6.15
/DIB connectors/SPI5_CLK: X5.17, X7.13
/DIB connectors/SPI5_CSA: X5.11, X7.9
/DIB connectors/SPI5_CSB: X5.13, X7.12
/DIB connectors/SPI5_CSC: X5.34
/DIB connectors/SPI5_IRQ: X5.9, X7.10
/DIB connectors/SPI5_MISO: X5.18, X7.14
/DIB connectors/SPI5_MOSI: X5.20, X7.15
/DIB connectors/UART_RX: X4.27, X5.3, X6.27, X7.27
/DIB connectors/UART_TX: X4.28, X5.4, X6.28, X7.28
/DIB connectors/~FAULT: X4.3, X5.8, X6.3, X7.3
/DIB connectors/~MRESET: D9.C, X5.6
/DIB connectors/~RESET: C2.1, D8.A, D9.A, R11.2, X4.4, X6.4, X7.4
BOOT1: X4.26; also elsewhere on the board
BOOT2: X6.26; also elsewhere on the board
BOOT3: X7.26; also elsewhere on the board
GND: D7.A, JP2.1, JP3.1, JP4.2, JP5.1, JP6.1, JP7.2, JP8.1, JP9.1, JP10.2, LED5.C, LED6.C, X4.7, X4.11, X4.16, X4.25, X5.1, X5.2, X5.15, X5.16, X5.29, X5.39, X5.40, X6.7, X6.11, X6.16, X6.25, X7.7, X7.11, X7.16, X7.25; also elsewhere on the board
I2C1_SCL: X4.5, X5.12, X6.5, X7.5; also elsewhere on the board
I2C1_SDA: X4.8, X5.14, X6.8, X7.8; also elsewhere on the board
unnamed: LED5.A, R9.2
unnamed: LED6.A, R10.2
unnamed: JP2.2, X4.17
unnamed: JP4.1, X4.18
unnamed: JP3.2, X4.19
unnamed: JP5.2, X6.17
unnamed: JP7.1, X6.18
unnamed: JP6.2, X6.19
unnamed: JP8.2, X7.17
unnamed: JP10.1, X7.18
unnamed: JP9.2, X7.19
PROG_RST: D8.C; also elsewhere on the board

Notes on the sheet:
Gnd 11
SPI2_SCLK 23
8 NFAULT
Gnd 25
UART_TX* 27
4 NRESET
Peripheral modules RESET
26 BOOT
18 SPI3_MISO
24 +5V
6 NRESET
SPI1_CSB 27
28 UART_RX*
28 SPI1_CSA
38 +12V
22 SPI2_CSA
Gnd 15
Output connector (3 x SPI modules)
SPI1_IRQ 25
DIB_SCLK 13
8 DIB_SDA
Gnd 1
+5V 23
40-pin DIB v1.1 MCU connector
+12V 37
DIB_SCL 5
SPI2_IRQ 19
14 DIB_MISO
2 Gnd
+5V 35
18 DIB_A2
12 I2C_SCL
2 +Vaux
SPI3_CSB 13
10 DIB_IRQ
16 Gnd
SPI1_MOSI 33
DIB_MOSI 15
*) Master and Slave Rx and Tx has to be swapped
SPI3_CSA 11

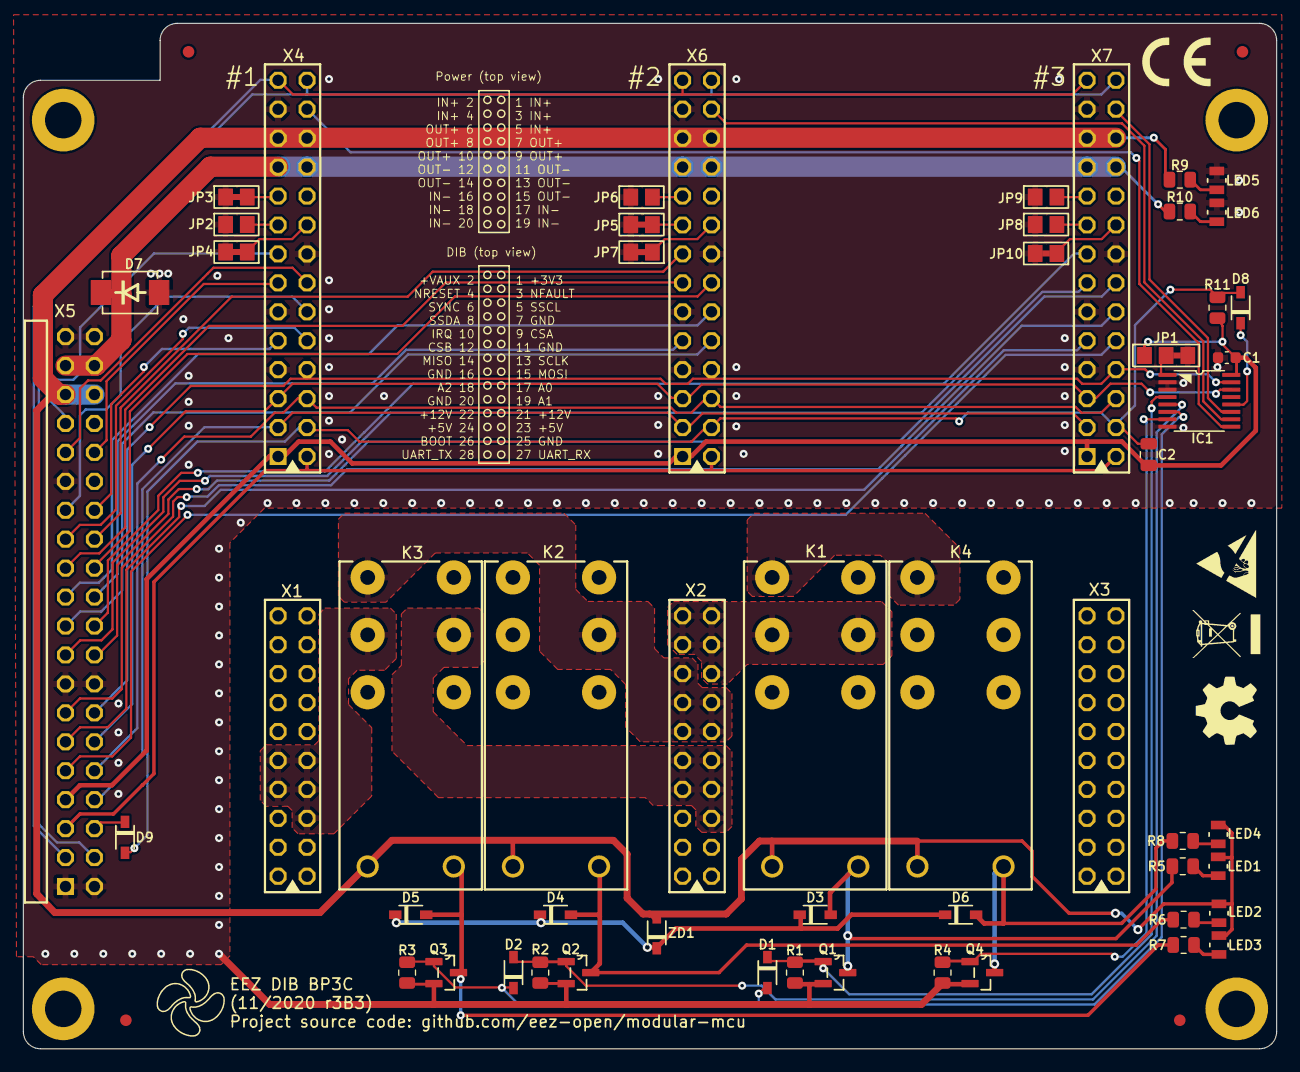
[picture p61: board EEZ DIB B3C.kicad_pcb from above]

Board: 2 copper layers, 110.0 x 90.0 mm, 68 parts (0 on the bottom side), 70 nets.

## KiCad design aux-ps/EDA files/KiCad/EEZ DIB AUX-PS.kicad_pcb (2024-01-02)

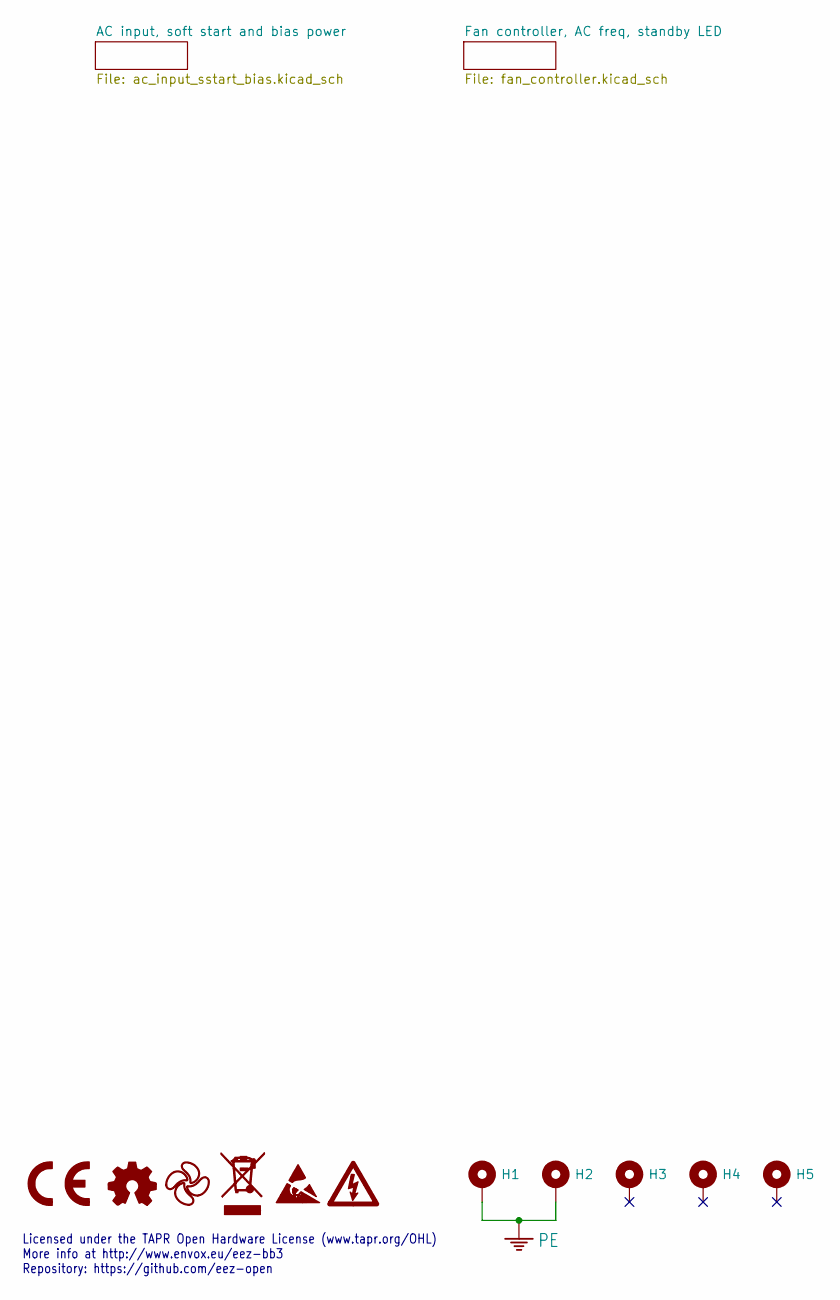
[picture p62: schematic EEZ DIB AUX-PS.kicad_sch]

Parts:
H1, H2, H3, H4, H5: Mounting_hole 3.2_5.5mm
LOGO1: CR logo; CE logo
LOGO2: Open HW logo
LOGO3: EEZ logo; EEZ logo (outline 6mm)
LOGO4: WEEE logo
LOGO5: ESD logo
LOGO6: Hi voltage logo

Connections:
PE: H1.1, H2.1; also elsewhere on the board

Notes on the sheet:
Licensed under the TAPR Open Hardware License (www.tapr.org/OHL) More info at http://www.envox.eu/eez-bb3 Repository: https://github.com/eez-open

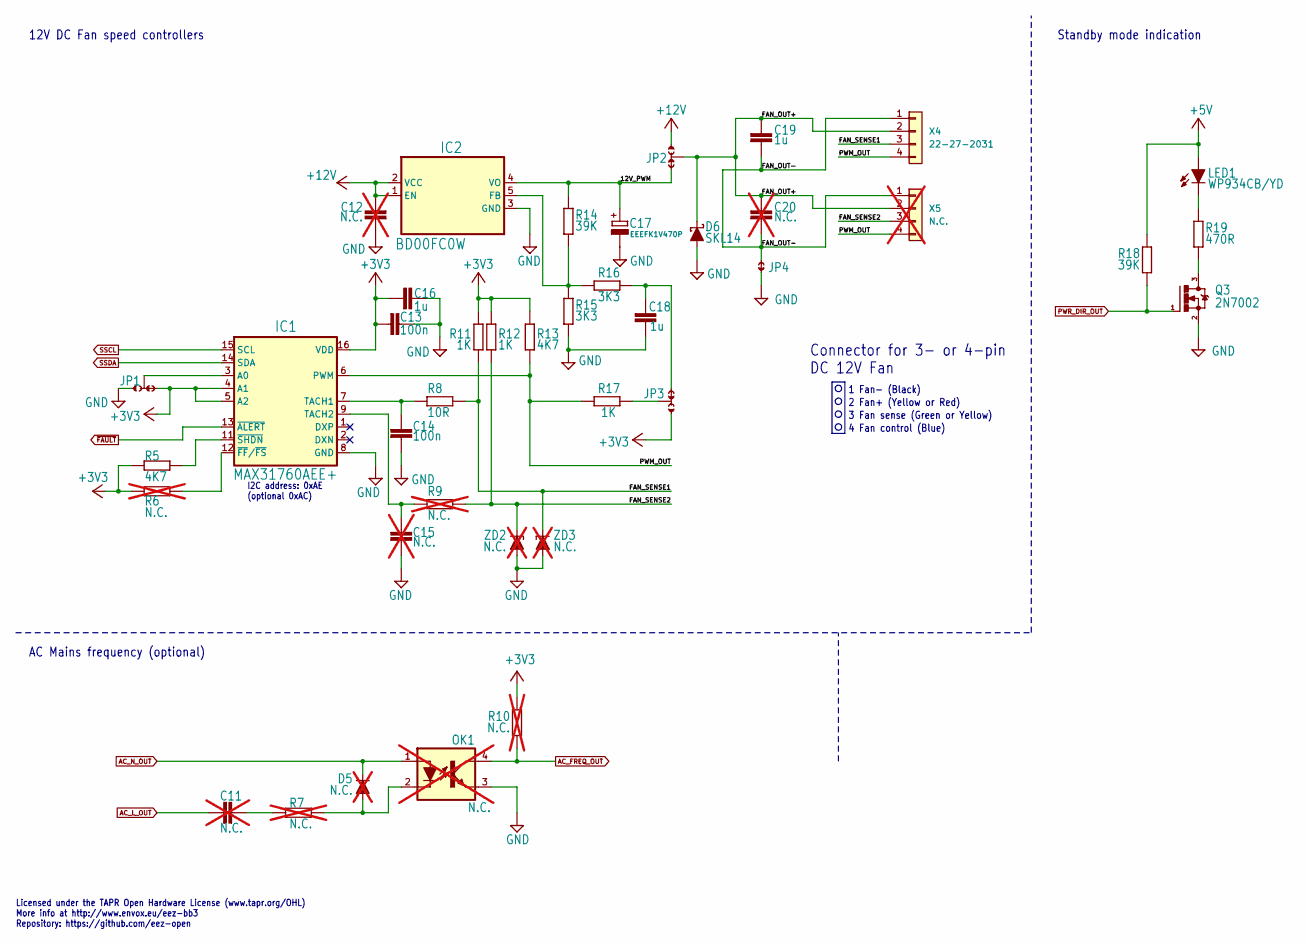
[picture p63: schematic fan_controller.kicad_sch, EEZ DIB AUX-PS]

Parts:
C11: N.C.; C102-054X133; not fitted
C12, C20: N.C.; C_0805_2012Metric; not fitted
C13, C14: 100n; C_0603_1608Metric; DigiKey 1276-1005-2-ND
C15: N.C.; C_0603_1608Metric; not fitted
C16, C18, C19: 1u; C_0805_2012Metric; DigiKey 490-10494-2-ND
C17: EEEFK1V470P; CAPAE660X610N; DigiKey PCE3842CT-ND
D5: N.C.; SOD-323_1P8X1P35_ONS-M; not fitted
D6: SKL14; SOD123; DigiKey 1727-7335-1-ND
IC1: MAX31760AEE+; DBQ16; DigiKey MAX31760AEE+-ND
IC2: BD00FC0W; TO-252-5; DigiKey BD00FC0WFP-E2TR-ND
JP1, JP2, JP3: JP3-CUT-0805-ROTATED; JP3 shorted
JP4: JP2-NOCUT-0805; JP2 shorted
LED1: WP934CB/YD; WP934CB_YD; DigiKey 754-1300-ND
OK1: N.C.; SOIC127P700X210-4N; DigiKey TLP291(GBSE-ND; not fitted
Q3: 2N7002; SOT103P240X110-3N; DigiKey T2N7002AKLMCT-ND
R5, R13: 4K7; R_0805_2012Metric; DigiKey 311-4.70KCRCT-ND
R6, R7, R9, R10: N.C.; R_0805_2012Metric; not fitted
R8: 10R; R_0805_2012Metric; DigiKey 311-10.0CRTR-ND
R11, R12, R17: 1K; R_0805_2012Metric; DigiKey 311-1.00KCRTR-ND
R14, R18: 39K; R_0805_2012Metric; DigiKey RMCF0805FT39K0CT-ND
R15, R16: 3K3; R_0805_2012Metric; DigiKey A129755CT-ND
R19: 470R; R_0805_2012Metric; DigiKey 311-470CRCT-ND
X4: 22-27-2031; 22-27-2041 (3-pin only); DigiKey WM4112-ND
X5: N.C.; 22-27-2041 (3-pin only); not fitted
ZD2, ZD3: N.C.; SOD123; not fitted

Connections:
+3V3: C13.2, C16.2, IC1.4 (A1), IC1.5 (A2), IC1.16 (VDD), JP1.NC, JP3.NO, R5.2, R6.2, R10.1, R11.2, R12.2, R13.2; also elsewhere on the board
+5V: LED1.A, R18.1; also elsewhere on the board
+12V: C12.1, IC2.1 (EN), IC2.2 (VCC), JP2.NO; also elsewhere on the board
/Fan controller, AC freq, standby LED/12V_PWM: C17.+, IC2.4 (VO), JP2.NC, R14.1
/Fan controller, AC freq, standby LED/FAN_OUT+: C19.1, C20.1, D6.C, JP2.COM, X4.2, X5.2
/Fan controller, AC freq, standby LED/FAN_OUT-: C19.2, C20.2, JP4.2, X4.1, X5.1
/Fan controller, AC freq, standby LED/FAN_SENSE1: R8.2, R11.1, X4.3, ZD3.C
/Fan controller, AC freq, standby LED/FAN_SENSE2: R9.2, R12.1, X5.3, ZD2.C
/Fan controller, AC freq, standby LED/PWM_OUT: IC1.6 (PWM), R13.1, R17.2, X4.4, X5.4
AC_FREQ_OUT: OK1.4 (COL), R10.2; also elsewhere on the board
AC_L_OUT: C11.1; also elsewhere on the board
AC_N_OUT: D5.C, OK1.1 (A); also elsewhere on the board
GND: C12.2, C13.1, C14.2, C15.2, C16.1, C17.-, C18.2, D6.A, IC1.8 (GND), IC2.3 (GND), JP1.NO, JP4.1, OK1.3 (EMIT), Q3.2 (S), R15.2, ZD2.A, ZD3.A; also elsewhere on the board
unnamed: C11.2, R7.1
unnamed: C18.1, JP3.NC, R16.2
unnamed: IC1.3 (A0), JP1.COM
unnamed: C14.1, IC1.7 (TACH1), R8.1
unnamed: C15.1, IC1.9 (TACH2), R9.1
unnamed: IC1.12 (~FF/~FS), R6.1
unnamed: IC1.11 (~SHDN), R5.1
unnamed: IC2.5 (FB), R14.2, R15.1, R16.1
unnamed: JP3.COM, R17.1
unnamed: LED1.C, R19.1
unnamed: D5.A, OK1.2 (C), R7.2
unnamed: Q3.3 (D), R19.2
PWR_DIR_OUT: Q3.1 (G), R18.2; also elsewhere on the board
SSCL: IC1.15 (SCL); also elsewhere on the board
SSDA: IC1.14 (SDA); also elsewhere on the board
~FAULT: IC1.13 (~ALERT); also elsewhere on the board

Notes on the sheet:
12V DC Fan speed controllers
AC Mains frequency (optional)
Standby mode indication
1 Fan- (Black)
4 Fan control (Blue)
3 Fan sense (Green or Yellow)
I2C address: 0xAE (optional 0xAC)
Connector for 3- or 4-pin DC 12V Fan
Licensed under the TAPR Open Hardware License (www.tapr.org/OHL) More info at http://www.envox.eu/eez-bb3 Repository: https://github.com/eez-open
2 Fan+ (Yellow or Red)

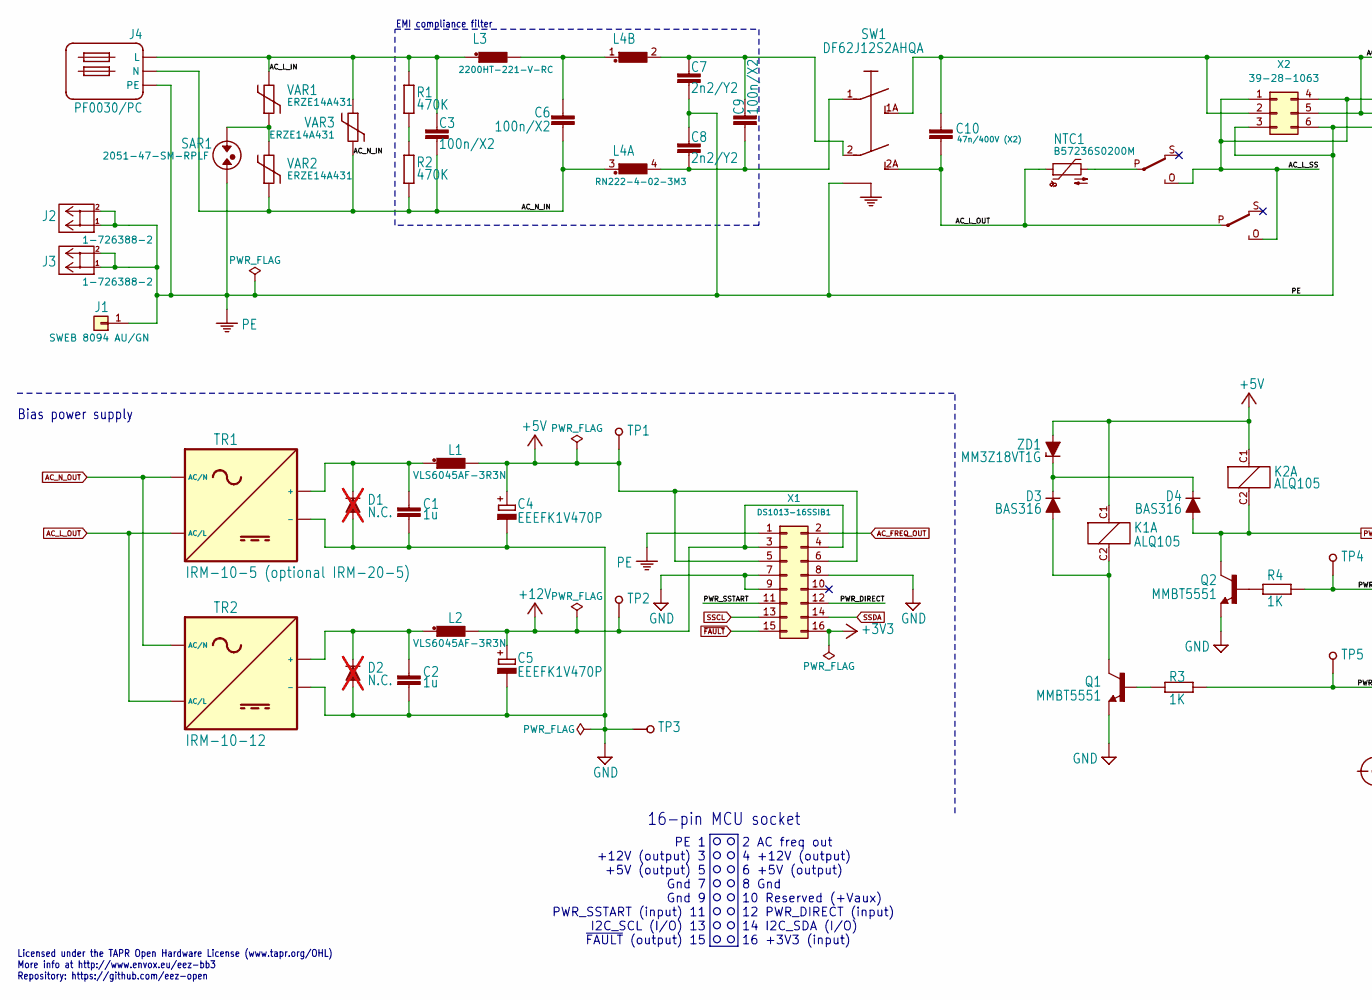
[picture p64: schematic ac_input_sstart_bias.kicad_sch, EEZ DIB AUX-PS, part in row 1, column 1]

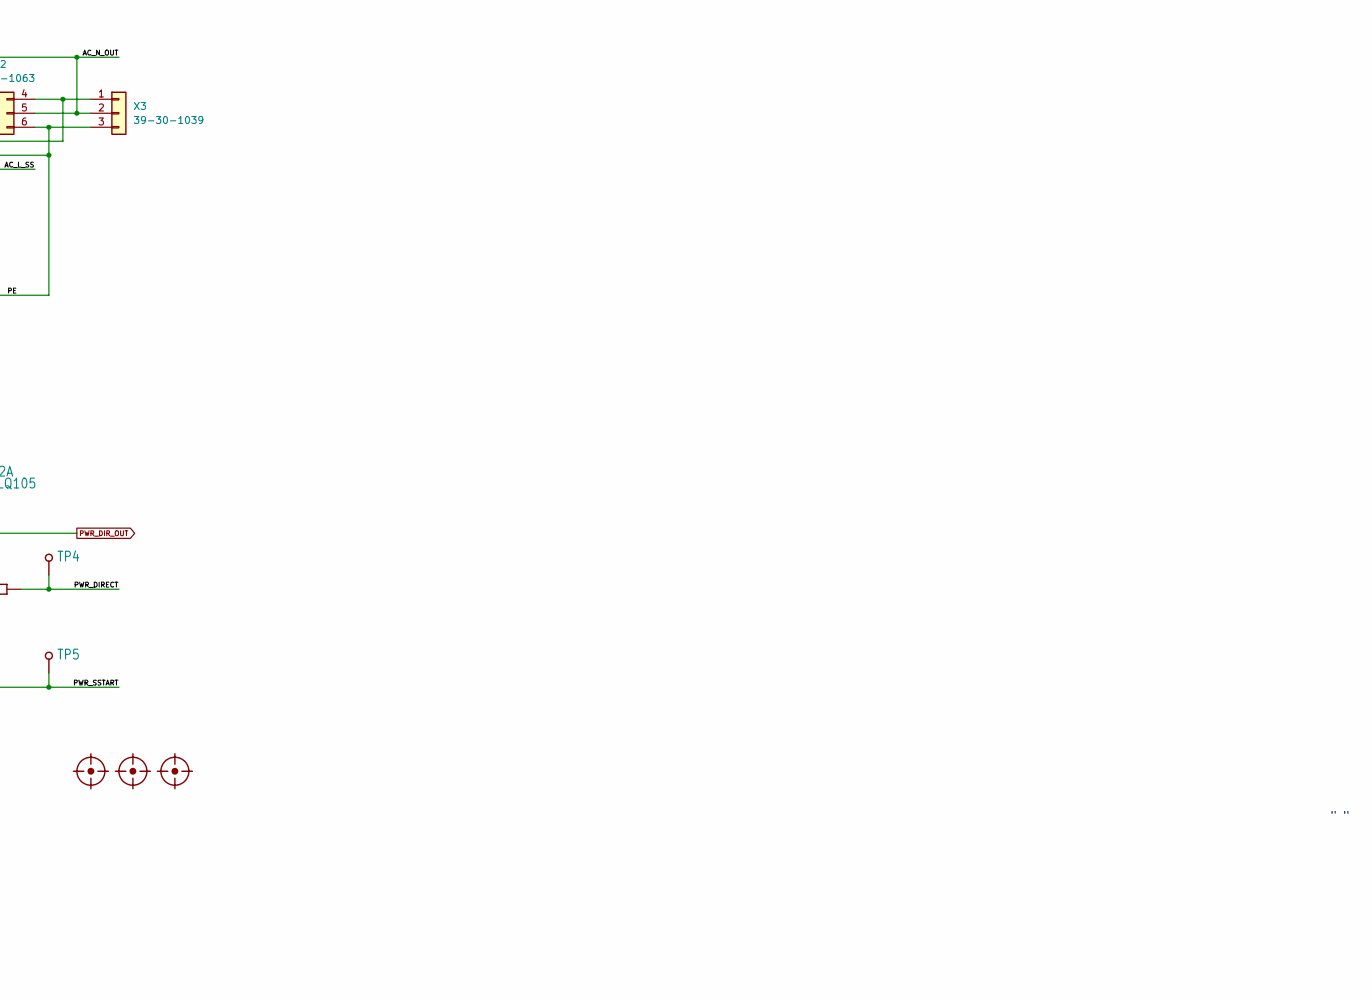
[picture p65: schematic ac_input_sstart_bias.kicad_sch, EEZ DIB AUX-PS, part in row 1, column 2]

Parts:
C1, C2: 1u; C_0805_2012Metric; DigiKey 490-10494-2-ND
C3, C6, C9: 100n/X2; C150-054X183; DigiKey 399-6806-ND
C4, C5: EEEFK1V470P; CAPAE660X610N; DigiKey PCE3842CT-ND
C7, C8: 2n2/Y2; C075-042X103; DigiKey 495-4874-1-ND
C10: 47n/400V (X2); C102-054X133; DigiKey 399-11478-ND
D1, D2: N.C.; DO214AA; not fitted
D3, D4: BAS316; SOD-323_1P8X1P35_ONS-M; DigiKey 1727-7370-1-ND
FM1, FM2, FM3: FIDUCIAL; Fiducial
J1: SWEB 8094 AU/GN; SWEB 8094_AU_GN
J2, J3: 1-726388-2; DigiKey 1-726388-2-ND
J4: PF0030/PC; PF0030_PC; DigiKey 708-1914-ND
K1, K2: ALQ105; PAN_ALQ1XX; DigiKey 255-3565-ND
L1, L2: VLS6045AF-3R3N; COILCRAFT_HPI0630; DigiKey 445-180834-1-ND
L3: 2200HT-221-V-RC; BOURNS_2200; DigiKey 2200HT-221-V-RC-ND
L4: RN222-4-02-3M3; BOURNS_7100_COMBO; DigiKey 817-2100-ND
NTC1: B57236S0200M; NTC_11.5X6_RM5; DigiKey 495-3047-ND
Q1, Q2: MMBT5551; SOT23-BEC; DigiKey 4878-MMBT5551CT-ND
R1, R2: 470K; R_0805_2012Metric; DigiKey A126370CT-ND
R3, R4: 1K; R_0805_2012Metric; DigiKey 311-1.00KCRTR-ND
SAR1: 2051-47-SM-RPLF; SAR_4.5MM; DigiKey 2051-47-SM-RPLFCT-ND
SW1: DF62J12S2AHQA; DF62J12S2; DigiKey CKN2062-ND
TP1, TP2, TP3, TP4, TP5: PCB_TEST_TABSHIELD; Testhole 24_50mils
TR1: IRM-10-5 (optional IRM-20-5); IRM-10_20_COMBO; DigiKey 1866-3032-ND
TR2: IRM-10-12; IRM-10; DigiKey 1866-3028-ND
VAR1, VAR2, VAR3: ERZE14A431; VARISTOR_14MM_RM7.5MM; DigiKey P16688-ND
X1: DS1013-16SSIB1; ZL231-16PG; DigiKey ED10523-ND
X2: 39-28-1063; MINIFIT_5566-06A_CRE; DigiKey WM3802-ND
X3: 39-30-1039; MINIFIT_39301039_CRE; DigiKey WM18442-ND
ZD1: MM3Z18VT1G; SOD-323_1P8X1P35_ONS-M; DigiKey MM3Z18VT1GOSCT-ND

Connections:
+3V3: X1.16; also elsewhere on the board
+5V: C4.+, K1.C1, K2.C1, L1.2, TP1.1, X1.5, X1.6, ZD1.A; also elsewhere on the board
+12V: C5.+, L2.2, TP2.1, X1.3, X1.4; also elsewhere on the board
/AC input, soft start and bias power/AC_L_IN: C3.1, J4.L, L3.1, R1.2, VAR1.2, VAR3.1
/AC input, soft start and bias power/AC_L_SS: K1.O, K2.O, X2.1, X2.4, X3.1
/AC input, soft start and bias power/AC_N_IN: C3.2, C6.2, J4.N, L4.3 (1), R2.1, VAR2.1, VAR3.2
/AC input, soft start and bias power/PWR_DIRECT: R4.2, TP4.1, X1.12
/AC input, soft start and bias power/PWR_SSTART: R3.2, TP5.1, X1.11
AC_FREQ_OUT: X1.2; also elsewhere on the board
AC_L_OUT: C10.2, K2.P, NTC1.1, SW1.2A (S1), TR1.ACL (AC/L), TR2.ACL (AC/L); also elsewhere on the board
AC_N_OUT: C10.1, SW1.1A (S), TR1.ACN (AC/N), TR2.ACN (AC/N), X2.2, X2.5, X3.2; also elsewhere on the board
GND: C1.2, C2.2, C4.-, C5.-, D1.A, D2.A, Q1.E, Q2.E, TP3.1, TR1.V- (-), TR2.V- (-), X1.7, X1.8, X1.9; also elsewhere on the board
unnamed: C6.1, L3.2, L4.1
unnamed: D3.A, K1.C2, Q1.C
unnamed: D3.C, D4.C, ZD1.C
unnamed: K1.P, NTC1.2
unnamed: C8.2, C9.1, L4.4 (2), SW1.1
unnamed: Q1.B, R3.1
unnamed: Q2.B, R4.1
unnamed: R1.1, R2.2
unnamed: SAR1.1, VAR1.1, VAR2.2
unnamed: C7.1, C9.2, L4.2, SW1.2 (P1)
unnamed: C1.1, D1.C, L1.1, TR1.V+ (+)
unnamed: C2.1, D2.C, L2.1, TR2.V+ (+)
PE: C7.2, C8.1, J1.1, J2.1, J2.2, J3.1, J3.2, J4.PE, SAR1.2, SW1.PE, X1.1, X2.3, X2.6, X3.3; also elsewhere on the board
PWR_DIR_OUT: D4.A, K2.C2, Q2.C; also elsewhere on the board
SSCL: X1.13; also elsewhere on the board
SSDA: X1.14; also elsewhere on the board
~FAULT: X1.15; also elsewhere on the board

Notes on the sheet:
2 AC freq out 4 +12V (output) 6 +5V (output) 8 Gnd 10 Reserved (+Vaux) 12 PWR_DIRECT (input) 14 I2C_SDA (I/O) 16 +3V3 (input)
PE 1 +12V (output) 3 +5V (output) 5 Gnd 7 Gnd 9 PWR_SSTART (input) 11 I2C_SCL (I/O) 13 ~{FAULT} (output) 15
EMI compliance filter
" "
Bias power supply
16-pin MCU socket
Licensed under the TAPR Open Hardware License (www.tapr.org/OHL) More info at http://www.envox.eu/eez-bb3 Repository: https://github.com/eez-open

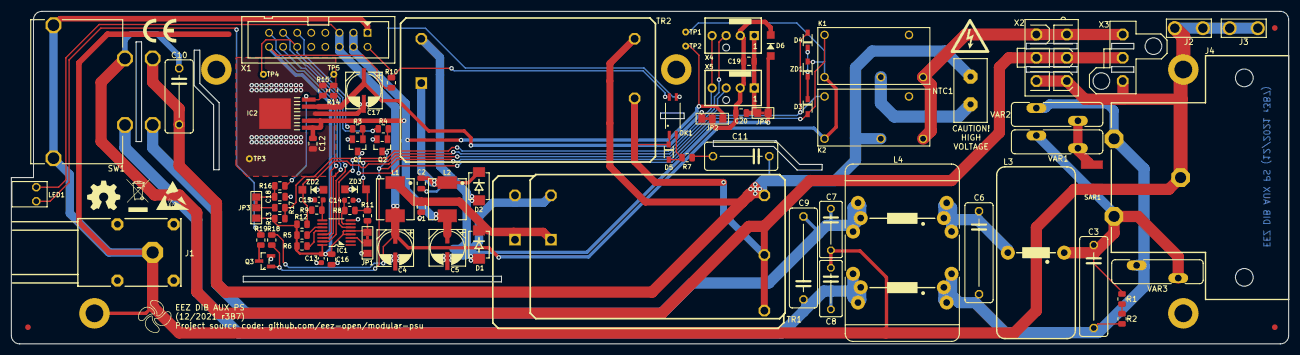
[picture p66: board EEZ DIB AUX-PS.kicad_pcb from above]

Board: 2 copper layers, 230.5 x 60.0 mm, 101 parts (0 on the bottom side), 47 nets.

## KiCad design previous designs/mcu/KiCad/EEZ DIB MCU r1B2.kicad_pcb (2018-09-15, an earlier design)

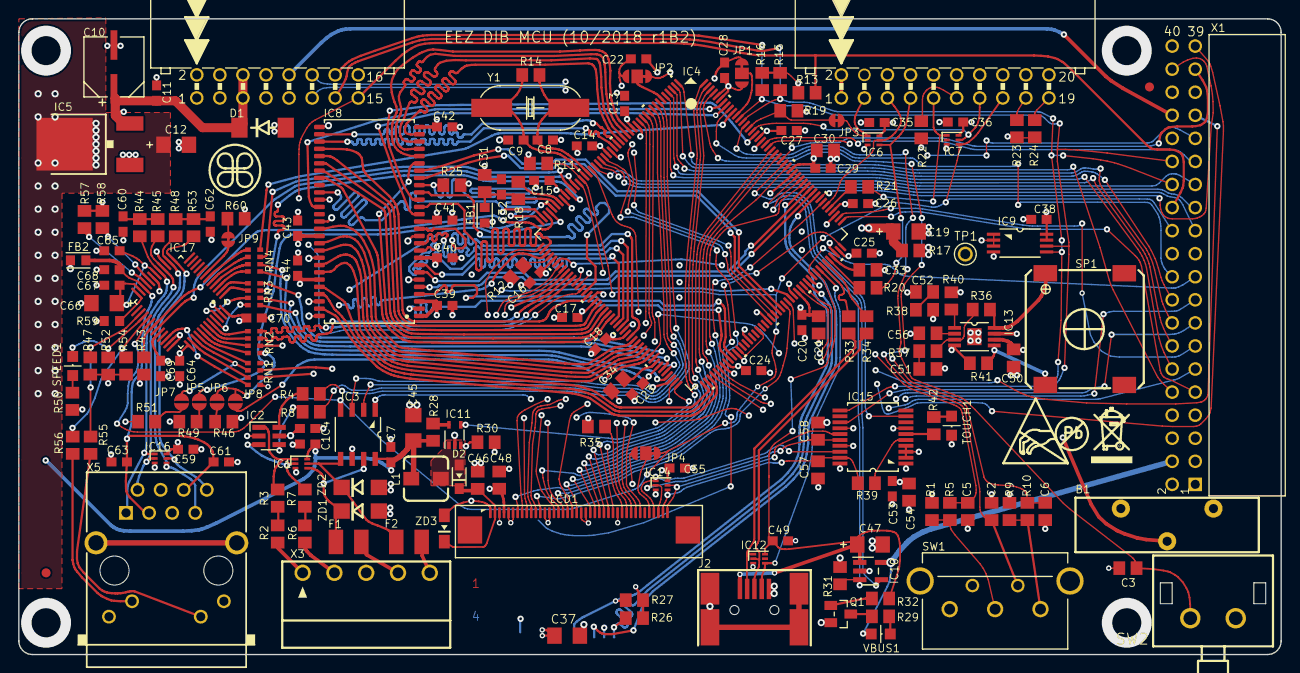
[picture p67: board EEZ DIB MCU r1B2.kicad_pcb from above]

Board: 4 copper layers, 139.0 x 70.0 mm, 194 parts (0 on the bottom side), 233 nets.

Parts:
B1: DS1092-16-B6P
C1, C4, C7, C11, C13, C14, C15, C16, C17, C18, C20, C23, C24, C25, C26, C27, C28, C29, C32, C35, C36, C38, C39, C40, C41, C42, C43, C44, C49, C53, C55, C59, C60, C61, C62, C63, C64, C65, C67, C68, C69, C70: 100n; C0603
C2, C3, C5, C6, C57, C58: 10n; C0805
C8, C9: 18p; C0603
C10: EEEFK1V470P; CAPAE660X610N
C12, C19, C47: 4u7; EC1206
C21, C30, C31, C46, C50, C54: 1u; C0805
C22: N.C.; C0603
C33, C34, C48: 2u2; C0805
C37, C45: 4u7; C1206
C51, C52, C56: 470n; C0805
C66: 10u; EC1206
D1: SMBJ5.0A-TR; DO214AA
D2: RB751V40T1G or NSR0240; SOD323-R
EEZ_SIGNATURE: SIGNATURESMALL; SIGNATURE_5MM
F1, F2: 50mA; F1210
FB1, FB2: LCBA-600; BEAD0603
FM1, FM2: FIDUCIAL
IC1, IC6, IC7, IC12, IC14, IC16: TPD4E001DRLR; DRL6
IC2: SN74LVC2G34DBVR; DBV6
IC3: BTS3408G; SOIC127P600X173-8N
IC4: STM32F769IGT6; LQFP-176_24X24MM
IC5: LD1117ADT33TR; DPACK
IC8: IS42S16400J; TSOPII-54
IC9: BR24G64FVT-3AGE2; PW8_TSSOP8
IC10: TPS2051BDBVR; DBV5
IC11: TPS61169DCKR; DCK5
IC13: TPA6205A1DGN; SOP65P490X110-9N
IC15: AR1021-I/SS; SOP65P780X200-20N
IC17: DP83848CVV_NOPB; PT48
J1: 503398-1892; 5033981892
J2: 67803-8020; 678038020
JP1, JP2, JP4: JP3-CUT
JP3, JP9: JP2-NOCUT
JP5, JP6, JP7, JP8: JP2-CUT
L1: DLG-0403-4R7; DE0403
LCD1: PCA-6-LA-40-HL-3; FPC_40
Q1: MMBT5551; SOT23-BEC
R1, R2, R3, R6, R7, R9, R13, R15, R16, R42: 4K7; R0805
R4, R8: 1K; R0805
R5, R10, R11, R12, R22, R23, R24, R25, R35, R37, R38: 10K; R0805
R14: 1M; R0805
R17: 0R; R0805
R18: 47R; R0805
R19, R26, R27, R29, R31, R32, R40: 47K; R0805
R20, R21, R33, R34: 22R; R0805
R28, R30: 10R; R0805
R36, R39, R41: 20K; R0805
R43: 1K5; R0805
R44, R45, R48, R53: 49R9; R0805
R46, R47, R49, R51, R52, R54, R57, R58, R60: 2K2; R0805
R50, R55, R56: 220R; R0805
R59: 4K87; R0603
RN1, RN2, RN3, RN4: DR1206-33R-4/8; CAY16
SP1: LD-BZEL-M1313
SPEED1: LTST-C170YKT; LED_0805
SW1: PEC16-2215F-S0024; PEC16-2215F
SW2: TL1100CF160Q; TL1100C
TOUCH1: HSMY-C170; LED_0805
TP1: PCB_TEST_TABSHIELD; PCB_SHIELD_TAB
U$1: RECYCLE_BIN1_8
U$5: PB_SMALL
U$6: ESD_SYMBOL
VBUS1: HSMG-C170; LED_0805
X1: ZL263-40DG
X2: ZL231-16KG; ML16L
X3: 1844249; MC1,5_5-G-3,5
X4: ZL231-20KG; ML20L
X5: LMJTAB881243M-L; RJ45-TRAFO-LED
Y1: 10MHz; HC-49_4H
ZD1, ZD2: SMAJ18A; DO214AC
ZD3: BZX384-B30.115; SOD323-W

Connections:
+3V3: C4.1, C12.+, C35.1, C36.1, C37.1, C38.2, C39.1, C40.1, C41.1, C42.1, C43.1, C44.1, C48.1, C50.2, C53.2, C54.2, C55.2, C59.1, C69.1, C70.1, FB2.P$1, IC2.5, IC5.4, IC6.6, IC7.6, IC8.1, IC8.3, IC8.9, IC8.14, IC8.27, IC8.43, IC8.49, IC9.1, IC9.2, IC9.3, IC9.7, IC9.8, IC13.6, IC14.6, IC15.1, IC16.6, IC17.32, IC17.48, J1.4, LCD1.4, R1.1, R9.1, R13.1, R15.1, R16.1, R17.1, R19.1, R25.1, R26.1, R27.1, R31.2, R35.2, R40.2, R43.2, R47.1, R50.1, R51.1, R52.1, R54.1, R57.1, R58.1, R60.1, X1.32, X2.16, X4.1, X4.2, X5.9, X5.12
+3V3(A): C61.2, C63.2, C68.1, FB2.P$2, IC17.22, X5.3, X5.6
+5V: C1.1, C7.2, C10.1, C11.1, C45.1, D1.C, IC1.6, IC3.8, IC5.3, IC10.5, L1.1, R28.1, VBUS1.A, X1.3, X1.4, X2.5, X2.6
+12V: X1.5, X1.6, X2.3, X2.4
/Ethernet PHY/ETH_COL: IC4.47, RN2.2
/Ethernet PHY/ETH_CRS: IC4.40, JP5.1, RN1.4
/Ethernet PHY/ETH_MDC: IC4.33, IC17.31
/Ethernet PHY/ETH_MDIO: IC4.42, IC17.30, R43.1
/Ethernet PHY/ETH_RX+: IC16.4, IC17.14, R48.2, X5.7
/Ethernet PHY/ETH_RX-: IC16.5, IC17.13, R53.1, X5.8
/Ethernet PHY/ETH_RXD0: IC4.54, RN2.3
/Ethernet PHY/ETH_RXD1: IC4.55, RN2.4
/Ethernet PHY/ETH_RXD2: IC4.83, RN3.1
/Ethernet PHY/ETH_RXD3: IC4.84, RN3.2
/Ethernet PHY/ETH_RX_CLK: IC4.41, RN1.2
/Ethernet PHY/ETH_RX_DV: IC4.53, RN1.3
/Ethernet PHY/ETH_TX+: IC16.1, IC17.17, R44.2, X5.1
/Ethernet PHY/ETH_TX-: IC16.2, IC17.16, R45.1, X5.2
/Ethernet PHY/ETH_TXD0: IC4.85, RN4.1
/Ethernet PHY/ETH_TXD1: IC4.86, RN4.2
/Ethernet PHY/ETH_TXD2: IC4.34, RN4.3
/Ethernet PHY/ETH_TXD3: IC4.167, RN4.4
/Ethernet PHY/ETH_TX_CLK: IC4.35, RN3.3
/Ethernet PHY/ETH_TX_EN: IC4.80, RN3.4
/Ethernet PHY/LED_ACT: IC17.26, R47.2, R55.2
/Ethernet PHY/LED_LINK: IC17.28, R54.2, R56.2
/Ethernet PHY/LED_SPEED: IC17.27, R52.2, SPEED1.C
/Ethernet PHY/MCLK_25: IC4.122, RN1.1
/I/O connectors, encoders, user SW/+VAUX: X1.34, X2.10
/I/O connectors, encoders, user SW/ENC_A: C5.2, IC4.119, R5.1
/I/O connectors, encoders, user SW/ENC_B: C6.1, IC4.120, R10.1
/I/O connectors, encoders, user SW/ENC_SW: C2.2, IC4.173, SW1.E
/I/O connectors, encoders, user SW/USER_SW: C3.2, IC4.163, SW2.1
/SDRAM, JTAG, SD card, EEPROM/DBGACK: R24.1, X4.19
/SDRAM, JTAG, SD card, EEPROM/DBGRQ: R23.1, X4.17
/SDRAM, JTAG, SD card, EEPROM/FMC_A0: IC4.16, IC8.23
/SDRAM, JTAG, SD card, EEPROM/FMC_A1: IC4.17, IC8.24
/SDRAM, JTAG, SD card, EEPROM/FMC_A2: IC4.18, IC8.25
/SDRAM, JTAG, SD card, EEPROM/FMC_A3: IC4.19, IC8.26
/SDRAM, JTAG, SD card, EEPROM/FMC_A4: IC4.20, IC8.29
/SDRAM, JTAG, SD card, EEPROM/FMC_A5: IC4.21, IC8.30
/SDRAM, JTAG, SD card, EEPROM/FMC_A6: IC4.60, IC8.31
/SDRAM, JTAG, SD card, EEPROM/FMC_A7: IC4.63, IC8.32
/SDRAM, JTAG, SD card, EEPROM/FMC_A8: IC4.64, IC8.33
/SDRAM, JTAG, SD card, EEPROM/FMC_A9: IC4.65, IC8.34
/SDRAM, JTAG, SD card, EEPROM/FMC_A10: IC4.66, IC8.22
/SDRAM, JTAG, SD card, EEPROM/FMC_A11: IC4.67, IC8.35
/SDRAM, JTAG, SD card, EEPROM/FMC_BA0: IC4.112, IC8.20
/SDRAM, JTAG, SD card, EEPROM/FMC_BA1: IC4.113, IC8.21
/SDRAM, JTAG, SD card, EEPROM/FMC_D0: IC4.97, IC8.2
/SDRAM, JTAG, SD card, EEPROM/FMC_D1: IC4.98, IC8.4
/SDRAM, JTAG, SD card, EEPROM/FMC_D2: IC4.142, IC8.5
/SDRAM, JTAG, SD card, EEPROM/FMC_D3: IC4.143, IC8.7
/SDRAM, JTAG, SD card, EEPROM/FMC_D4: IC4.68, IC8.8
/SDRAM, JTAG, SD card, EEPROM/FMC_D5: IC4.69, IC8.10
/SDRAM, JTAG, SD card, EEPROM/FMC_D6: IC4.70, IC8.11
/SDRAM, JTAG, SD card, EEPROM/FMC_D7: IC4.73, IC8.13
/SDRAM, JTAG, SD card, EEPROM/FMC_D8: IC4.74, IC8.42
/SDRAM, JTAG, SD card, EEPROM/FMC_D9: IC4.75, IC8.44
/SDRAM, JTAG, SD card, EEPROM/FMC_D10: IC4.76, IC8.45
/SDRAM, JTAG, SD card, EEPROM/FMC_D11: IC4.77, IC8.47
/SDRAM, JTAG, SD card, EEPROM/FMC_D12: IC4.78, IC8.48
/SDRAM, JTAG, SD card, EEPROM/FMC_D13: IC4.89, IC8.50
/SDRAM, JTAG, SD card, EEPROM/FMC_D14: IC4.90, IC8.51
/SDRAM, JTAG, SD card, EEPROM/FMC_D15: IC4.91, IC8.53
/SDRAM, JTAG, SD card, EEPROM/FMC_NBL0: IC4.169, IC8.15
/SDRAM, JTAG, SD card, EEPROM/FMC_NBL1: IC4.170, IC8.39
/SDRAM, JTAG, SD card, EEPROM/FMC_SDCKE0: IC4.43, IC8.37
/SDRAM, JTAG, SD card, EEPROM/FMC_SDCLK: IC4.116, IC8.38
/SDRAM, JTAG, SD card, EEPROM/FMC_SDNCAS: IC4.160, IC8.17
/SDRAM, JTAG, SD card, EEPROM/FMC_SDNE0: IC4.44, IC8.19, R25.2
/SDRAM, JTAG, SD card, EEPROM/FMC_SDNRAS: IC4.59, IC8.18
/SDRAM, JTAG, SD card, EEPROM/FMC_SDNWE: IC4.46, IC8.16
/SDRAM, JTAG, SD card, EEPROM/RTCK: R22.1, X4.11
/SDRAM, JTAG, SD card, EEPROM/SDMMC1_CK: IC4.141, J1.5
/SDRAM, JTAG, SD card, EEPROM/SDMMC1_CMD: IC4.144, J1.3, R27.2
/SDRAM, JTAG, SD card, EEPROM/SDMMC1_D0: IC4.121, J1.7, R26.2
/SDRAM, JTAG, SD card, EEPROM/SD_DETECT: IC4.24, J1.SW1
/SDRAM, JTAG, SD card, EEPROM/SYS_JTCK-SWCLK: IC4.137, R21.1
/SDRAM, JTAG, SD card, EEPROM/SYS_JTDI: IC4.138, IC6.5, X4.5
/SDRAM, JTAG, SD card, EEPROM/SYS_JTDO-SWO: IC4.161, IC7.5, X4.13
/SDRAM, JTAG, SD card, EEPROM/SYS_JTMS-SWDIO: IC4.128, R20.1
/SDRAM, JTAG, SD card, EEPROM/SYS_JTRST: IC4.162, JP3.1, R19.2
/SDRAM, JTAG, SD card, EEPROM/TCK: IC7.1, R21.2, X4.9
/SDRAM, JTAG, SD card, EEPROM/TMS: IC6.4, R20.2, X4.7
/STM32F7 MCU/BOOT0: IC4.166, JP1.COM
/STM32F7 MCU/BYPASS_REG: IC4.48, R12.2
/STM32F7 MCU/DAC_OUT1: C52.2, IC4.50
/STM32F7 MCU/IRQ_TOUCH: IC4.151, IC15.9
/STM32F7 MCU/LTDC_B2: IC4.150, LCD1.23
/STM32F7 MCU/LTDC_B3: IC4.154, LCD1.24
/STM32F7 MCU/LTDC_B4: IC4.155, LCD1.25
/STM32F7 MCU/LTDC_B5: IC4.174, LCD1.26
/STM32F7 MCU/LTDC_B6: IC4.175, LCD1.27
/STM32F7 MCU/LTDC_B7: IC4.176, LCD1.28
/STM32F7 MCU/LTDC_CLK: IC4.115, LCD1.30
/STM32F7 MCU/LTDC_DE: IC4.28, LCD1.34
/STM32F7 MCU/LTDC_G2: IC4.52, LCD1.15
/STM32F7 MCU/LTDC_G3: IC4.153, LCD1.16
/STM32F7 MCU/LTDC_G4: IC4.45, LCD1.17
/STM32F7 MCU/LTDC_G5: IC4.132, LCD1.18
/STM32F7 MCU/LTDC_G6: IC4.13, LCD1.19
/STM32F7 MCU/LTDC_G7: IC4.145, LCD1.20
/STM32F7 MCU/LTDC_HSYNC: IC4.12, LCD1.32
/STM32F7 MCU/LTDC_R2: IC4.139, LCD1.7
/STM32F7 MCU/LTDC_R3: IC4.56, LCD1.8
/STM32F7 MCU/LTDC_R4: IC4.51, LCD1.9
/STM32F7 MCU/LTDC_R5: IC4.32, LCD1.10
/STM32F7 MCU/LTDC_R6: IC4.57, LCD1.11
/STM32F7 MCU/LTDC_R7: IC4.114, LCD1.12
/STM32F7 MCU/LTDC_VSYNC: IC4.11, LCD1.33
/STM32F7 MCU/RCC_OSC_IN: C8.2, IC4.29, R14.2, Y1.2
/STM32F7 MCU/RCC_OSC_OUT: C9.2, IC4.30, R14.1, Y1.1
/STM32F7 MCU/TFT_BRIGHTNESS: IC4.88, IC11.4
/STM32F7 MCU/USB_OTG_FS_D_N: IC4.126, R33.2
/STM32F7 MCU/USB_OTG_FS_D_P: IC4.127, R34.2
/STM32F7 MCU/USB_OTG_FS_ID: IC4.125, IC12.4, J2.4
/STM32F7 MCU/USB_OTG_FS_PSO: IC4.147, IC10.4
/STM32F7 MCU/USB_OTG_FS_VBUS: C47.+, C49.2, IC4.124, IC10.1, IC12.6, J2.1, R32.1
/STM32F7 MCU/VBAT: IC4.6, JP2.COM
/STM32F7 MCU/VCAP1: C34.1, IC4.81
/STM32F7 MCU/VCAP2: C33.1, IC4.129
/STM32F7 MCU/VDDA: C31.1, C32.1, FB1.P$2, IC4.39, R18.2
/STM32F7 MCU/VREF+: IC4.38, R18.1
/STM32F7 MCU/~USB_OTG_FS_OC: IC4.146, IC10.3, R31.1
/TFT, Audio, USB/LCD_DISP: LCD1.31, R35.1
/TFT, Audio, USB/LTDC_RESET: JP4.COM, LCD1.36
/TFT, Audio, USB/SPKR+: IC13.5, R41.1, SP1.-
/TFT, Audio, USB/SPKR-: IC13.8, R36.1, SP1.+
/TFT, Audio, USB/Touch_XL: C57.1, IC14.4, IC15.19, LCD1.39, R39.2
/TFT, Audio, USB/Touch_XR: IC14.1, IC15.18, LCD1.37
/TFT, Audio, USB/Touch_YD: C58.1, IC14.2, IC15.16, LCD1.38
/TFT, Audio, USB/Touch_YU: IC14.5, IC15.15, LCD1.40
/TFT, Audio, USB/USB_D_N: IC12.1, J2.2, R33.1
/TFT, Audio, USB/USB_D_P: IC12.2, J2.3, R34.1
/TFT, Audio, USB/VLED+: C46.1, D2.C, LCD1.2, ZD3.C
/TFT, Audio, USB/VLED-: IC11.3, LCD1.1, R30.1, ZD3.A
/TFT, Audio, USB/VLED_SW: D2.A, IC11.1, L1.2
/TFT, Audio, USB/~AUDIO_SHDN: IC13.1, R40.1
DIN1: IC4.7, R4.2
DIN2: IC4.8, R8.2
DOUT1: IC3.2, IC4.9
DOUT2: IC3.3, IC4.10
GND: B1.1, B1.3, C1.2, C2.1, C3.1, C4.2, C5.1, C6.2, C7.1, C8.1, C9.1, C10.2, C11.2, C12.-, C13.2, C14.2, C15.2, C16.2, C17.2, C18.2, C19.-, C20.2, C21.2, C22.2, C23.2, C24.2, C25.2, C26.2, C27.2, C28.2, C29.2, C30.2, C31.2, C32.2, C33.2, C34.2, C35.2, C36.2, C37.2, C38.1, C39.2, C40.2, C41.2, C42.2, C43.2, C44.2, C45.2, C46.2, C47.-, C48.2, C49.1, C50.1, C51.2, C53.1, C54.1, C55.1, C56.1, C57.2, C58.2, C59.2, C60.2, C61.1, C62.2, C63.1, C64.2, C65.2, C66.-, C67.2, C68.2, C69.2, C70.2, D1.A, IC1.3, IC2.2, IC3.6, IC4.14, IC4.22, IC4.37, IC4.61, IC4.71, IC4.95, IC4.103, IC4.109, IC4.117, IC4.130, IC4.135, IC4.148, IC4.158, IC5.1, IC6.3, IC7.3, IC8.6, IC8.12, IC8.28, IC8.41, IC8.46, IC8.52, IC8.54, IC9.4, IC10.2, IC11.2, IC12.3, IC13.7, IC13.TP, IC14.3, IC15.2, IC15.3, IC15.4, IC15.7, IC15.14, IC15.17, IC15.20, IC16.3, IC17.15, IC17.19, IC17.35, IC17.36, IC17.47, J1.6, J1.S, J1.SW2, J2.5, JP1.NC, JP4.NO, LCD1.3, LCD1.5, LCD1.6, LCD1.13, LCD1.14, LCD1.21, LCD1.22, LCD1.29, Q1.E, R12.1, R22.2, R23.2, R24.2, R30.2, R46.1, R49.1, R59.1, SW1.C, SW1.D, SW1.GND1, SW1.GND2, SW2.2, TOUCH1.C, TP1.1, X1.1, X1.2, X1.7, X1.8, X1.21, X1.22, X1.35, X1.36, X1.40, X2.7, X2.8, X2.9, X3.3, X4.4, X4.6, X4.8, X4.10, X4.12, X4.14, X4.16, X4.18, X4.20, X5.4, X5.5, ZD1.A, ZD2.A
I2C1_SCL: IC4.164, IC9.5, IC15.11, R15.2, X1.28, X2.13
I2C1_SDA: IC4.165, IC9.6, IC15.13, R16.2, X1.30, X2.14
unnamed: B1.2, JP2.NC
unnamed: C51.1, R37.2
unnamed: C52.1, R38.2
unnamed: C56.2, IC13.2
unnamed: C60.1, R44.1, R45.2
unnamed: C62.1, R48.1, R53.2
unnamed: C64.1, C65.1, C66.+, C67.1, IC17.18, IC17.23, IC17.37
unnamed: F1.1, X3.4
unnamed: F1.2, IC1.4, IC3.7, ZD1.C
unnamed: F2.1, X3.5
unnamed: F2.2, IC1.5, IC3.5, ZD2.C
unnamed: IC1.1, IC2.1, R3.2
unnamed: IC1.2, IC2.3, R7.2
unnamed: IC2.4, R8.1
unnamed: IC2.6, R4.1
unnamed: IC4.100, IC4.106
unnamed: IC6.1, JP3.2, X4.3
unnamed: IC11.5, R28.2
unnamed: IC13.3, R36.2, R37.1
unnamed: IC13.4, R38.1, R41.2
unnamed: IC15.5, R39.1
unnamed: IC15.6, R42.2
unnamed: IC17.1, RN3.6
unnamed: IC17.2, RN3.5
unnamed: IC17.3, RN4.8
unnamed: IC17.4, RN4.7
unnamed: IC17.5, RN4.6
unnamed: IC17.6, RN4.5
unnamed: IC17.7, JP9.2
unnamed: IC17.20, R58.2
unnamed: IC17.21, R57.2
unnamed: IC17.24, R59.2
unnamed: IC17.34, RN1.8
unnamed: IC17.38, RN1.7
unnamed: IC17.39, JP7.2, RN1.6
unnamed: IC17.40, RN1.5
unnamed: IC17.41, RN2.8
unnamed: IC17.42, RN2.7
unnamed: IC17.43, RN2.6
unnamed: IC17.44, RN2.5
unnamed: IC17.45, RN3.8
unnamed: IC17.46, RN3.7
unnamed: JP5.2, R49.2
unnamed: JP6.1, JP8.1, RN2.1
unnamed: JP6.2, R46.2
unnamed: JP7.1, R51.2
unnamed: JP9.1, R60.2
unnamed: Q1.B, R32.2
unnamed: Q1.C, R29.1
unnamed: R1.2, R5.2, SW1.B
unnamed: R2.1, X3.1
unnamed: R2.2, R3.1
unnamed: R6.1, X3.2
unnamed: R6.2, R7.1
unnamed: R9.2, R10.2, SW1.A
unnamed: R29.2, VBUS1.C
unnamed: R42.1, TOUCH1.A
unnamed: R50.2, SPEED1.A
unnamed: R55.1, X5.11
unnamed: R56.1, X5.10
OE_SYNC: IC4.94, X1.39
OUT_PAR: IC4.140, X1.38
OUT_SER: IC4.152, X1.37
PE: J2.SH1, J2.SH1.1, J2.SH2, J2.SH2.2, X2.1, X2.2, X5.SH, X5.SH2
PWR_DIRECT: IC4.110, X2.12
PWR_SSTART: IC4.111, X2.11
SPI2_CLK: IC4.133, X1.9
SPI2_CSA: IC4.93, X1.15
SPI2_CSB: IC4.92, X1.17
SPI2_IRQ: IC4.123, X1.19
SPI2_MISO: IC4.87, X1.11
SPI2_MOSI: IC4.134, X1.13
SPI4_CLK: IC4.1, X1.10
SPI4_CSA: IC4.2, X1.16
SPI4_CSB: IC4.3, X1.18
SPI4_IRQ: IC4.168, X1.20
SPI4_MISO: IC4.4, X1.12
SPI4_MOSI: IC4.5, X1.14
SPI5_CLK: IC4.25, X1.23
SPI5_CSA: IC4.157, X1.29
SPI5_CSB: IC4.156, X1.31
SPI5_IRQ: IC4.79, JP8.2, X1.33
SPI5_MISO: IC4.26, X1.25
SPI5_MOSI: IC4.27, X1.27
VDD: C13.1, C14.1, C15.1, C16.1, C17.1, C18.1, C19.+, C20.1, C21.1, C22.1, C23.1, C24.1, C25.1, C26.1, C27.1, C28.1, C29.1, C30.1, FB1.P$1, IC4.15, IC4.23, IC4.36, IC4.49, IC4.62, IC4.72, IC4.82, IC4.96, IC4.99, IC4.118, IC4.131, IC4.136, IC4.149, IC4.159, IC4.171, IC4.172, JP1.NO, JP2.NO, R11.1, R17.2
~FAULT: IC3.1, IC4.58, R13.2, X1.26, X2.15
~RESET: IC3.4, IC4.31, IC7.4, IC17.29, JP4.NC, R11.2, X1.24, X4.15

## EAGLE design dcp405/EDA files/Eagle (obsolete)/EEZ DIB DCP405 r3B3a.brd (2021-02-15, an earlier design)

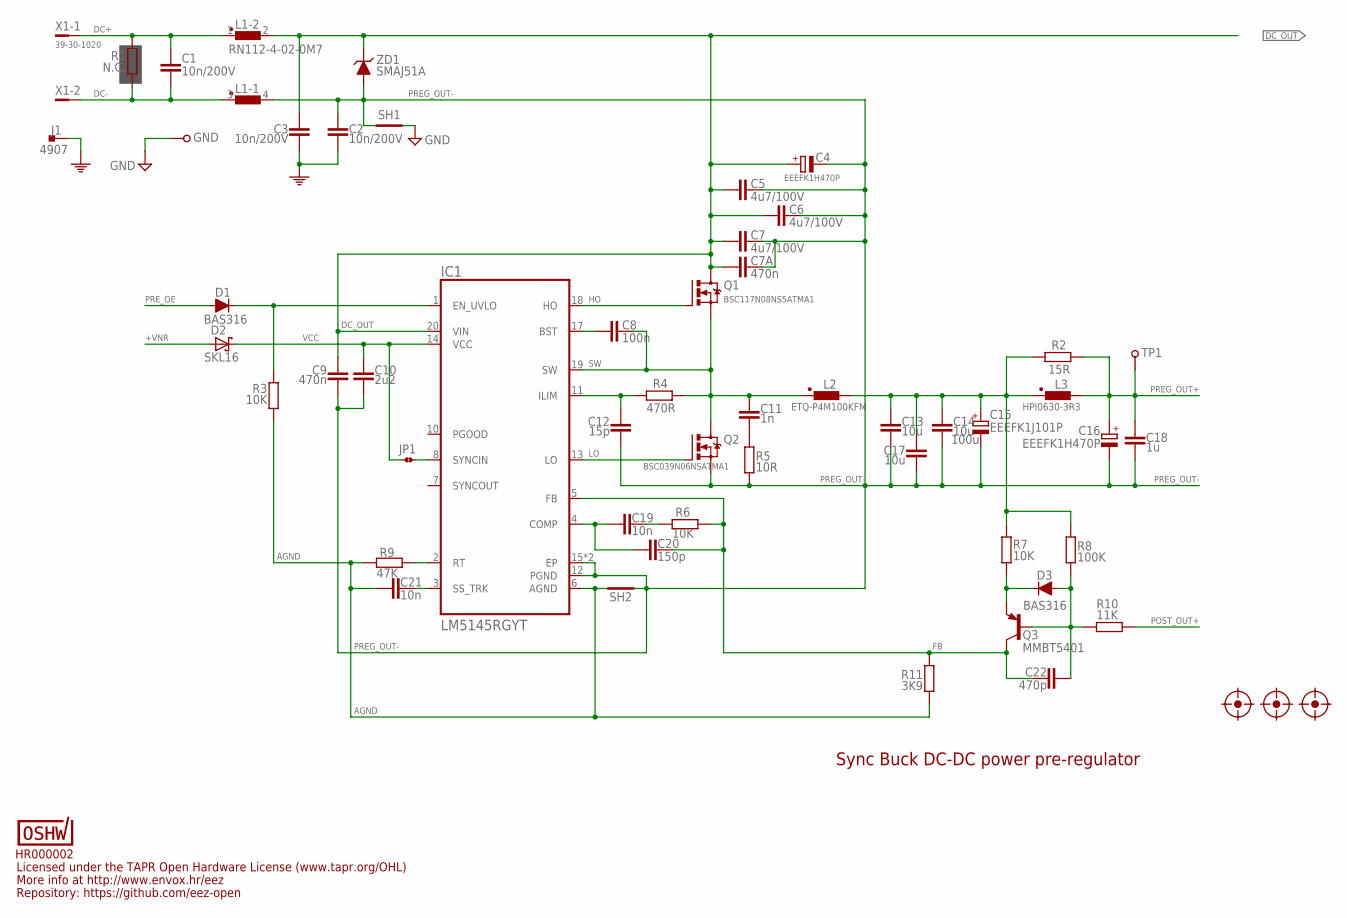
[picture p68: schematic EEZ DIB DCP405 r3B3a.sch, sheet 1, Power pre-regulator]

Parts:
C1, C2, C3: 10n/200V; C1206
C4, C16: EEEFK1H470P; CAPAE830X1050N
C5, C6, C7: 4u7/100V; C1210
C7A, C9: 470n; C0805
C8: 100n; C0603
C10: 2u2; C1206
C11: 1n; C0805
C12: 15p; C0805
C13, C14, C17: 10u; C1210
C15: EEEFK1J101P; CAPAE1030X1050N
C18: 1u; C0805
C19, C21: 10n; C0805
C20: 150p; C0805
C22: 470p; C0805
D1, D3: BAS316; SOD323-R
D2: SKL16; SOD123
FM1, FM2, FM3: FIDUCIAL_2; FIDUCIAL_DUAL
GND: PCB_TEST_TABSHIELD; PCB_SHIELD_TAB
IC1: LM5145RGYT; RGY0020B
J1: 4907; PCB_TAB-4907
JP1: JP2-CUT-0805; R_0805
L1: RN112-4-02-0M7; RN112
L2: ETQ-P4M100KFM; PANASONIC_ETQ-P4_KFM
L3: HPI0630-3R3; COILCRAFT_HPI0630
OSHWA: HR000002; CERT-SMALL-SILK
Q1: BSC117N08NS5ATMA1; TDSON-8
Q2: BSC039N06NSATMA1; TDSON-8
Q3: MMBT5401; SOT23-BEC
R1: N.C.; R2512
R2: 15R; R2010
R3, R6, R7: 10K; R0805
R4: 470R; R0805
R5: 10R; R1206
R8: 100K; R0805
R9: 47K; R0805
R10: 11K; R0805
R11: 3K9; R0805
SH1, SH2: SHORTNOHOLE; SHORT_NOHOLE
TP1: TEST-PIN_0.9MM
X1: 39-30-1020; MINIFIT_39301020
ZD1: SMAJ51A; DO214AA

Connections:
+VNR: D2.A; also elsewhere on the board
AGND: C21.2, IC1.6 (AGND), R3.1, R9.1, R11.2, SH2.1 (GND_A)
DC+: C1.2, L1.1, R1.2, X1.1
DC-: C1.1, L1.3 (1), R1.1, X1.2
DC_OUT: C3.2, C4.+, C5.1, C6.1, C7.1, C7A.2, C9.2, IC1.20 (VIN), L1.2, Q1.5 (D), Q1.6 (D), Q1.7 (D), Q1.8 (D), ZD1.C; also elsewhere on the board
FB: C20.1, C22.1, IC1.5 (FB), Q3.C, R6.2, R11.1
GND: GND.1, SH1.2 (GND_B); also elsewhere on the board
HO: IC1.18 (HO), Q1.4 (G)
LO: IC1.13 (LO), Q2.4 (G)
L_OUT: C13.1, C14.1, C15.+, C17.1, L2.2, L3.1, R2.2, R7.1, R8.1
unnamed: IC1.8 (SYNCIN), JP1.2
unnamed: D1.C, IC1.1 (EN_UVLO), R3.2
unnamed: D3.C, Q3.E, R7.2
unnamed: C19.1, R6.1
unnamed: C8.1, IC1.17 (BST)
unnamed: IC1.2 (RT), R9.2
unnamed: C19.2, C20.2, IC1.4 (COMP)
unnamed: C12.1, IC1.11 (ILIM), R4.1
unnamed: C21.1, IC1.3 (SS_TRK)
unnamed: C11.2, R5.2
unnamed: C22.2, D3.A, Q3.B, R8.2, R10.1
PE: C2.2, C3.1, J1.1, J1.2; also elsewhere on the board
POST_OUT+: R10.2; also elsewhere on the board
PREG_OUT+: C16.+, C18.2, L3.2, R2.1, TP1.1; also elsewhere on the board
PREG_OUT-: C2.1, C4.-, C5.2, C6.2, C7.2, C7A.1, C9.1, C10.1, C12.2, C13.2, C14.2, C15.-, C16.-, C17.2, C18.1, IC1.12 (PGND), IC1.15 (EP), IC1.21 (EP), L1.4 (2), Q2.1 (S), Q2.2 (S), Q2.3 (S), R5.1, SH1.1 (GND_A), SH2.2 (GND_B), ZD1.A; also elsewhere on the board
PRE_OE: D1.A; also elsewhere on the board
SW: C8.2, C11.1, IC1.19 (SW), L2.1, Q1.1 (S), Q1.2 (S), Q1.3 (S), Q2.5 (D), Q2.6 (D), Q2.7 (D), Q2.8 (D), R4.2
VCC: C10.2, D2.C, IC1.14 (VCC), JP1.1

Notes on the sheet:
Licensed under the TAPR Open Hardware License (www.tapr.org/OHL)
Repository: https://github.com/eez-open
More info at http://www.envox.hr/eez
Sync Buck DC-DC power pre-regulator
100u

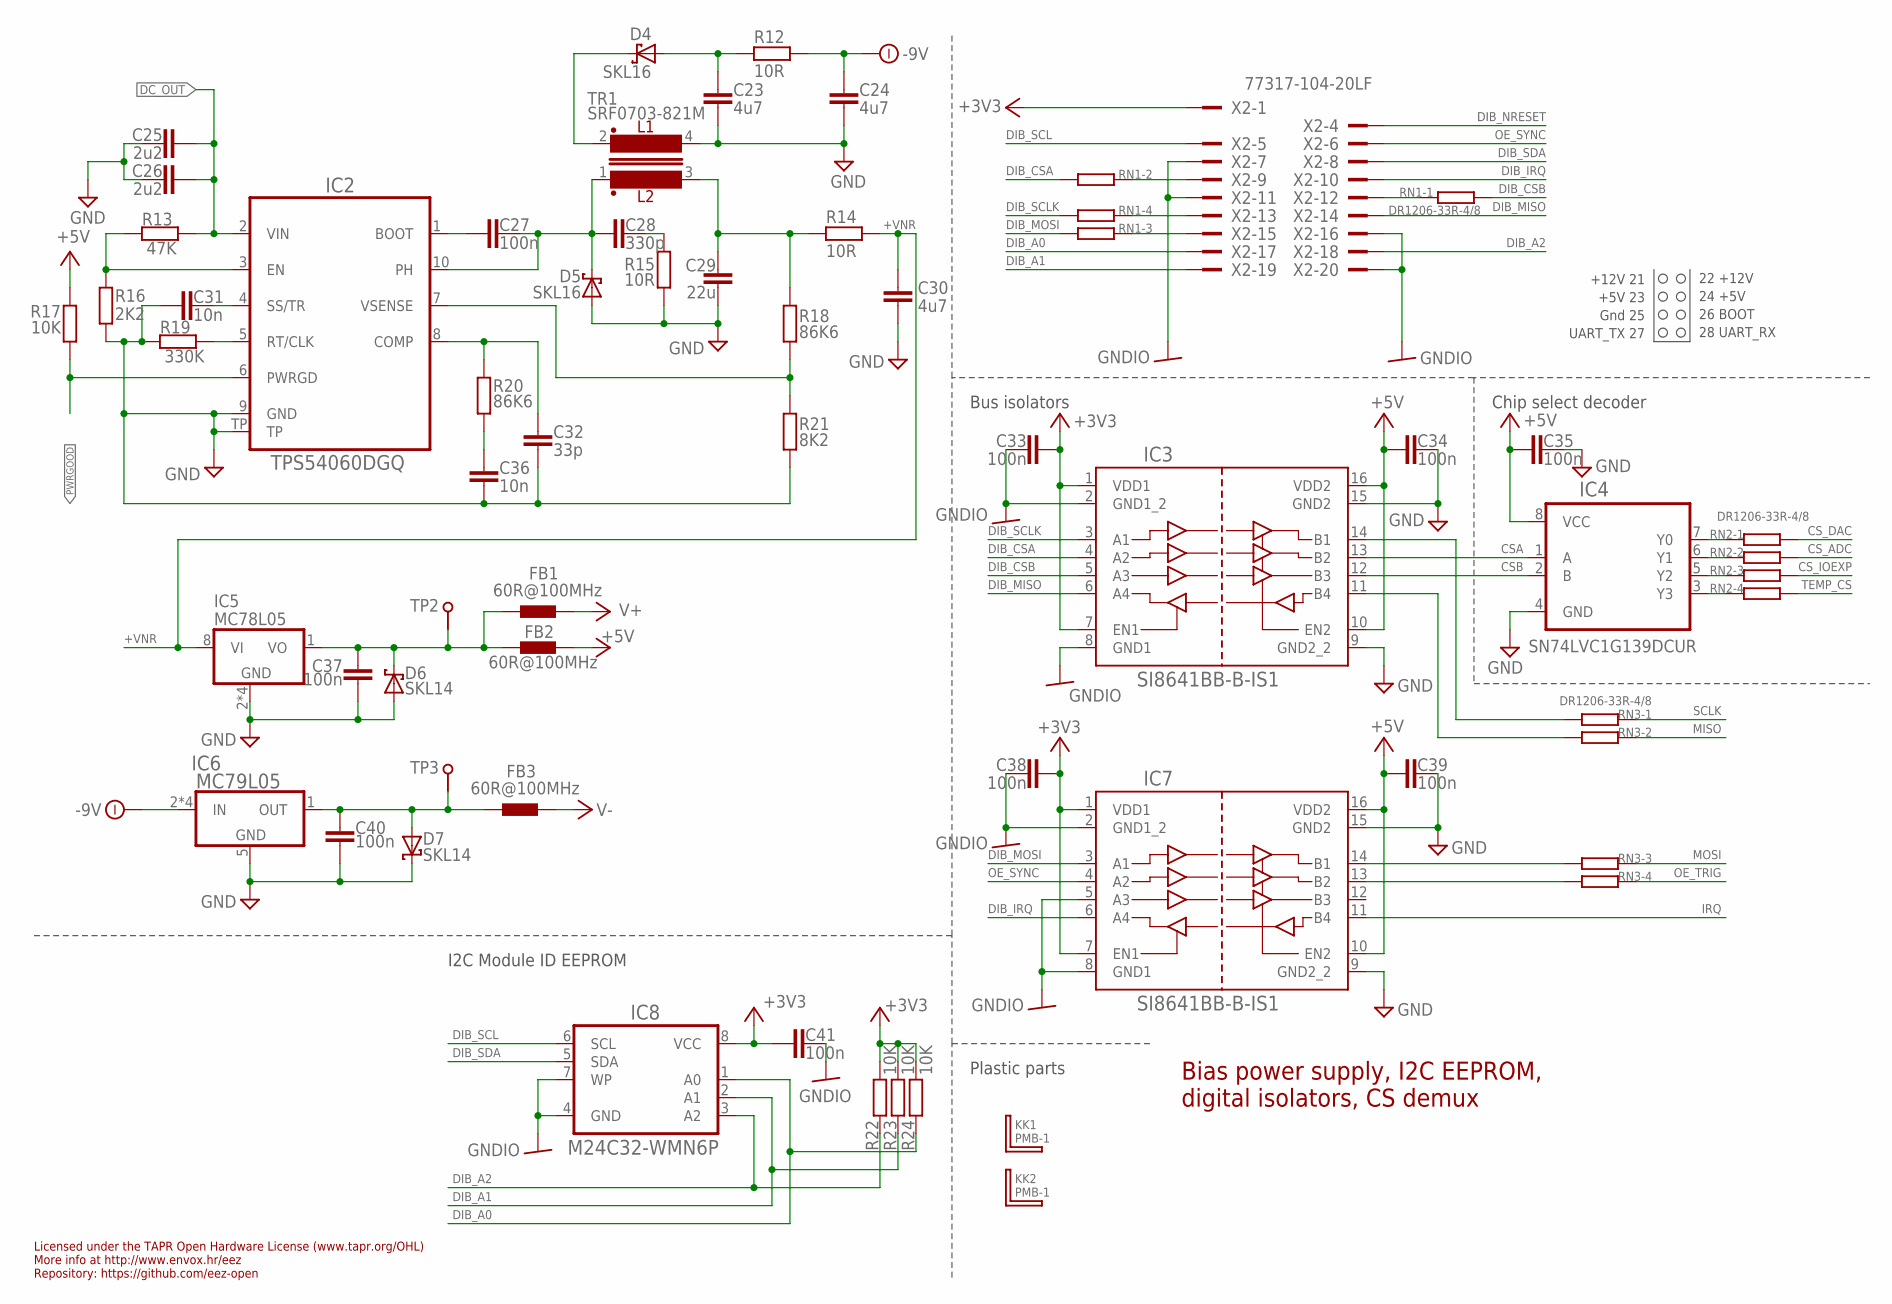
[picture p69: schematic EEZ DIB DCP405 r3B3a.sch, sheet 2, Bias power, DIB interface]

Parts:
C23, C24, C30: 4u7; C1206
C25, C26: 2u2; C1206
C27, C33, C34, C35, C37, C38, C39, C40, C41: 100n; C0603
C28: 330p; C0805
C29: 22u; C1210
C31, C36: 10n; C0805
C32: 33p; C0805
D4, D5: SKL16; SOD123
D6, D7: SKL14; SOD123
FB1, FB2, FB3: 60R@100MHz; BEAD0603
IC2: TPS54060DGQ; SOP50P490X110-11N
IC3, IC7: SI8641BB-B-IS1; SOIC-16
IC4: SN74LVC1G139DCUR; DCU8
IC5: MC78L05; SOIC127P600X173-8N
IC6: MC79L05; SOIC127P600X173-8N
IC8: M24C32-WMN6P; SOIC127P600X173-8N
KK1, KK2: PMB-1; PCB-MB
R12, R14, R15: 10R; R1206
R13: 47K; R0805
R16: 2K2; R0805
R17, R22, R23, R24: 10K; R0805
R18, R20: 86K6; R0805
R19: 330K; R0805
R21: 8K2; R0805
RN1, RN2, RN3: DR1206-33R-4/8; CAY16
TP2, TP3: TEST-PIN_0.9MM
TR1: SRF0703-821M; SRF0703
X2: 77317-104-20LF

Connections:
+3V3: C33.1, C38.1, C41.2, IC3.1 (VDD1), IC3.7 (EN1), IC7.1 (VDD1), IC7.7 (EN1), IC8.8 (VCC), R22.1, R23.1, R24.1, X2.1
+5V: C34.2, C35.1, C39.2, FB2.P$2 (2), IC3.10 (EN2), IC3.16 (VDD2), IC4.8 (VCC), IC7.10 (EN2), IC7.16 (VDD2), R17.1; also elsewhere on the board
+5VOUT: C37.1, D6.C, FB1.P$1 (1), FB2.P$1 (1), IC5.1 (VO), TP2.1
+VNR: C30.1, IC5.8 (VI), R14.1; also elsewhere on the board
-9V: C24.1, IC6.2 (IN), IC6.3 (IN), IC6.6 (IN), IC6.7 (IN), R12.1; also elsewhere on the board
CSA: IC3.13 (B2), IC4.1 (A)
CSB: IC3.12 (B3), IC4.2 (B)
CS_ADC: RN2.7 (2); also elsewhere on the board
CS_DAC: RN2.8 (2); also elsewhere on the board
CS_IOEXP: RN2.6 (2); also elsewhere on the board
DC_OUT: C25.1, C26.1, IC2.2 (VIN), R13.2; also elsewhere on the board
DIB_A0: IC8.1 (A0), R24.2, X2.17
DIB_A1: IC8.2 (A1), R23.2, X2.19
DIB_A2: IC8.3 (A2), R22.2, X2.18
DIB_CSA: IC3.4 (A2), RN1.2 (1)
DIB_CSB: IC3.5 (A3), RN1.1
DIB_IRQ: IC7.6 (A4), X2.10
DIB_MISO: IC3.6 (A4), X2.14
DIB_MOSI: IC7.3 (A1), RN1.3 (1)
DIB_NRESET: X2.4
DIB_SCL: IC8.6 (SCL), X2.5
DIB_SCLK: IC3.3 (A1), RN1.4 (1)
DIB_SDA: IC8.5 (SDA), X2.8
GND: C23.2, C24.2, C25.2, C26.2, C29.2, C30.2, C31.2, C32.1, C34.1, C35.2, C36.1, C37.2, C39.1, C40.1, D5.A, D6.A, D7.C, IC2.9 (GND), IC2.TP, IC3.9 (GND2_2), IC3.15 (GND2), IC4.4 (GND), IC5.2 (GND), IC5.3 (GND), IC5.6 (GND), IC5.7 (GND), IC6.5 (GND), IC7.9 (GND2_2), IC7.15 (GND2), R15.1, R16.1, R19.1, R21.1, TR1.4; also elsewhere on the board
GNDIO: C33.2, C38.2, C41.1, IC3.2 (GND1_2), IC3.8 (GND1), IC7.2 (GND1_2), IC7.5 (A3), IC7.8 (GND1), IC8.4 (GND), IC8.7 (WP), X2.7, X2.11, X2.16, X2.20
IRQ: IC7.11 (B4); also elsewhere on the board
MISO: RN3.7 (2); also elsewhere on the board
MOSI: RN3.6 (2); also elsewhere on the board
unnamed: IC7.13 (B2), RN3.4 (1)
unnamed: IC4.5 (Y2), RN2.3 (1)
unnamed: IC4.7 (Y0), RN2.1
unnamed: IC3.11 (B4), RN3.2 (1)
unnamed: RN1.7 (2), X2.9
unnamed: IC4.6 (Y1), RN2.2 (1)
unnamed: RN1.5 (2), X2.13
unnamed: C28.2, R15.2
unnamed: RN1.6 (2), X2.15
unnamed: C40.2, D7.A, FB3.P$1 (1), IC6.1 (OUT), TP3.1
unnamed: RN1.8 (2), X2.12
unnamed: IC2.3 (EN), R13.1, R16.2
unnamed: C31.1, IC2.4 (SS/TR)
unnamed: IC2.5 (RT/CLK), R19.2
unnamed: C32.2, IC2.8 (COMP), R20.2
unnamed: C36.2, R20.1
unnamed: IC4.3 (Y3), RN2.4 (1)
unnamed: C27.2, IC2.1 (BOOT)
unnamed: IC7.14 (B1), RN3.3 (1)
unnamed: IC2.7 (VSENSE), R18.1, R21.2
unnamed: IC3.14 (B1), RN3.1
unnamed: C23.1, D4.A, R12.2
OE_SYNC: IC7.4 (A2), X2.6
OE_TRIG: RN3.5 (2); also elsewhere on the board
PH: C27.1, C28.1, D5.C, IC2.10 (PH), TR1.1
PWRGOOD: IC2.6 (PWRGD), R17.2; also elsewhere on the board
SCLK: RN3.8 (2); also elsewhere on the board
TEMP_CS: RN2.5 (2); also elsewhere on the board
V+: FB1.P$2 (2); also elsewhere on the board
V-: FB3.P$2 (2); also elsewhere on the board
VOUT+: C29.1, R14.2, R18.2, TR1.3
VOUT-: D4.C, TR1.2

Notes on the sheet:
Licensed under the TAPR Open Hardware License (www.tapr.org/OHL)
Repository: https://github.com/eez-open
More info at http://www.envox.hr/eez
I2C Module ID EEPROM
Bus isolators
Bias power supply, I2C EEPROM, digital isolators, CS demux
Plastic parts
Chip select decoder
22 +12V
24 +5V
+5V 23
Gnd 25
+12V 21
26 BOOT
UART_TX 27
28 UART_RX


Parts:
C42, C44, C48, C50, C51, C52, C57, C58, C59, C60: 100n; C0603
C43, C47: 100p; C0805
C45, C61: 33p; C0805
C46: N.C.; C0805
C49, C54: 10n; C0805
C53, C56: 1u; C0805
C55: 4n7; C0805
C62: 6n8; C0805
D8: N.C.; SOD123
D9: SKL14; SOD123
D10, D11, D12, D13: BAS316; SOD323-R
D14: SK55; SMB
IC9, IC10: TL072D; SOIC127P600X173-8N
IC11: LTC2050HVCS8#PBF; SOIC127P600X173-8N
IC12: SN74LVC1G3157DCKR; SOT65P210X110-6N
KK3: SK96/84
Q4, Q5: D45H11FP; TO220FP-V
Q6: FQPF11P06 or FQPF27P06; TO220FP-V
Q7: BCP56-16.115; SOT230P700X180-4N
Q8: MMBT5401; SOT23-BEC
Q9: NZT605; SOT230P700X180-4N
Q10: 2N7002; SOT103P240X110-3N
Q11: BSS205NH6327XTSA1; SOT103P240X110-3N; MPN 2N7002-7-F
Q12, Q13: PSMN0R9-25YLC; SOT669
R25, R29: 0R1/2-3W; R2512
R26: 2R2/2W; R2512
R27, R28, R30, R35: 4K7; R0805
R31, R41, R44, R52, R53: 10K; R0805
R32, R40, R45, R56, R57: 2K2; R0805
R33, R34: 10R; R1206
R36, R43, R69: 1K; R0805
R37, R38, R54: 220R; R0805
R39, R46, R62: 22K; R0805
R42, R49: 7K5 0.1%; R0805
R47, R48: 124K 0.1%; R0805
R50: 15R; R2010
R51: N.C.; R0805
R55: 100K; R0805
R58, R65: 39K 0.1%; R0805
R59, R68: 820R 0.1%; R0805
R60, R66: 47K; R0805
R61: 1R; R1206
R63: 8K2; R0805
R64: 470R; R0805
R67: 0R010 (low TCR); R_2512-4WIRE
ZD2: MM3Z9V1T1G; SOD323-R

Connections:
5A_S: Q13.1 (S), Q13.2 (S), Q13.3 (S), R67.2
50MA_S: Q12.1 (S), Q12.2 (S), Q12.3 (S), R59.1, R61.1
!DP_DRIVE: D9.A, Q8.E; also elsewhere on the board
+VREF: R31.1; also elsewhere on the board
-9V: R36.2, R37.2; also elsewhere on the board
CC_ACTIVE: Q10.1 (G); also elsewhere on the board
CURR_5A: IC12.6 (CTRL), Q13.4 (G), R66.2; also elsewhere on the board
CURR_50MA: Q12.4 (G), R60.2; also elsewhere on the board
DARL_C1: Q9.2 (C), Q9.4 (C), R32.1, R33.1, R34.1
DP_S: Q6.3 (S), R26.1
GCOM: IC10.6 (-IN), IC10.7 (OUT), R42.1, R58.1
GND: C42.2, C44.2, C48.2, C49.1, C50.2, C51.1, C52.1, C53.1, C54.1, C56.1, C57.2, C58.1, C59.1, C60.2, D9.C, D10.C, IC12.2 (GND), Q10.2 (S), Q11.2 (S), R38.2, R55.1, R60.1, R66.1; also elsewhere on the board
ISENSE+: IC11.3 (+IN), R58.2, R59.2
ISENSE-: IC11.2 (-IN), R65.1, R68.2
I_MON: IC11.6 (OUT), IC12.4 (COM), R62.1, R65.2; also elsewhere on the board
I_SERVO: C55.2, C61.2, D13.C, IC10.1 (OUT); also elsewhere on the board
I_SET: R57.1; also elsewhere on the board
LOOP_CTRL: D11.A, D13.A, R40.1, R43.1; also elsewhere on the board
unnamed: Q10.3 (D), R46.1
unnamed: C48.1, R56.1, R57.2
unnamed: R61.2, R67.2S
unnamed: C46.1, R51.2
unnamed: C55.1, R63.1
unnamed: Q5.1 (B), R34.2
unnamed: IC12.1 (NO), R64.1
unnamed: IC10.3 (+IN), R56.2
unnamed: IC9.3 (+IN), R41.2, R44.2
unnamed: C45.1, IC9.2 (-IN), R51.1, R52.2, R53.2
unnamed: Q4.1 (B), R33.2
unnamed: D12.A, Q9.3 (E), R50.2
unnamed: Q11.3 (D), R50.1
unnamed: C62.2, R69.1
unnamed: C61.1, IC10.2 (-IN), R62.2, R63.2, R64.2, R69.2
unnamed: C43.2, R41.1
unnamed: C47.2, R53.1
unnamed: R28.1, R30.2
unnamed: Q7.1 (B), R35.1, R36.1
unnamed: Q8.C, R35.2
unnamed: D10.A, Q8.B, R39.2
unnamed: Q11.1 (G), R54.1, R55.2
unnamed: Q7.3 (E), R37.1
unnamed: D12.C, Q9.1 (B), R43.2
unnamed: C42.1, IC10.5 (+IN), R31.2, R38.1
unnamed: IC9.5 (+IN), R42.2, R47.1
unnamed: IC9.6 (-IN), R48.1, R49.2
unnamed: R67.1S, R68.1
PASS_E1: Q4.3 (E), R25.2
PASS_E2: Q5.3 (E), R29.2
POST_OE: R54.2; also elsewhere on the board
POST_OUT+: C47.1, C62.1, D8.A, Q4.2 (C), Q5.2 (C), R26.2, R27.1, R28.2, ZD2.C; also elsewhere on the board
POST_OUT-: C43.1, D14.A, Q12.MB (D), Q13.MB (D); also elsewhere on the board
PREG_OUT+: D8.C, R25.1, R29.1, R32.2; also elsewhere on the board
PREG_OUT-: D14.C, Q6.2 (D), R30.1, R67.1; also elsewhere on the board
Q7C: Q6.1 (G), Q7.2 (C), Q7.4 (C), R27.2, ZD2.A
SENSE+: R47.2; also elsewhere on the board
SENSE-: R48.2; also elsewhere on the board
U_MON: IC9.7 (OUT), R49.1, R52.1; also elsewhere on the board
U_SERVO: C45.2, C46.2, D11.C, IC9.1 (OUT), R39.1; also elsewhere on the board
U_SET_OUT: R45.1; also elsewhere on the board
U_SET_OVP: C44.1, R44.1, R45.2, R46.2
V+: C49.2, C50.1, C51.2, C52.2, C53.2, C60.1, IC9.8 (V+), IC10.8 (V+), IC11.7 (V+), IC12.5 (VDD), R40.2; also elsewhere on the board
V-: C54.2, C56.2, C57.1, C58.2, C59.2, IC9.4 (V-), IC10.4 (V-), IC11.4 (V-); also elsewhere on the board

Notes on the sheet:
Voltage control loop
Licensed under the TAPR Open Hardware License (www.tapr.org/OHL)
Repository: https://github.com/eez-open
More info at http://www.envox.hr/eez
Zero level offset
CV/CC linear post-regulator, Output enable and "down-programmer"
- Sheet:
- Date:
Current control loop


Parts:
C64, C65, C67, C71, C72, C73, C78, C80, C82: 100n; C0603
C66: 4u7; C1206
C68: 4u7 tant.; EC1206
C69, C70, C79, C81: 1u; C0805
C74, C75, C76, C77: 4n7; C0805
D15: BAS316; SOD323-R
D16: N.C.; SOD323-R
IC13: 74AUP1G74DC.125; DCU8
IC14: MCP23S17-E/SS; SOP65P780X200-28N
IC15: REF5025AIDR; SOIC127P600X175-8N
IC16: TC77-5.0MCTTR; SOT23-5
IC17: DAC8552IDGKR; DGK8-M
IC18: SN74LVC1G3157DCKR; SOT65P210X110-6N
IC19: ADS1120IPWR; PW(R-PDSO-G16)
LED1: WP42WUM/EGW; L-42WUM-1EGWT
LED2: WP934MD/2LID; WP934MD
OE: JP2-NOCUT
Q14: BSS84P; SOT95P237X112-3N
R70: 1K; R0805
R71: 10K; R0805
R72: 100K; R0805
R73: 270R; R0805
R74, R77, R78, R80, R81: 2K2; R0805
R75, R76, R79: 470R; R0805
R82: 10R; R1206
X3: 691322110005; MC1,5/5-G-3,5
ZD3: SLVU2.8-TP; SOT23

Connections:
!ADC_DRDY: IC14.25 (GPA4), IC19.14 (!DRDY)
!DP_DRIVE: R74.1; also elsewhere on the board
!IOEXP_RST: IC14.18 (!RESET), R70.2
!OVP_FAULT: D16.C, IC14.26 (GPA5); also elsewhere on the board
!SET_DP: IC14.1 (GPB0), Q14.1 (G), R72.2
+5V: C64.2, C65.1, C67.1, C78.2, C79.2, IC13.7 (!PRE), IC13.8 (VDD), IC14.9 (VDD), IC16.5 (VDD), IC19.13 (DVDD), Q14.2 (S), R70.1, R71.1, R72.1; also elsewhere on the board
+VREF: C68.+, C72.2, C82.2, IC15.6 (VOUT), IC17.2 (VREF), IC19.9 (REFP0); also elsewhere on the board
AUX_IN: IC18.1 (NO), R75.1, ZD3.3 (C)
AUX_USET_SW: IC14.4 (GPB3), IC18.6 (CTRL), LED2.BA (A)
CC_ACTIVE: IC14.22 (GPA1); also elsewhere on the board
CS_ADC: IC19.2 (!CS); also elsewhere on the board
CS_DAC: IC17.5 (!SYNC); also elsewhere on the board
CS_IOEXP: IC14.11 (!CS); also elsewhere on the board
CURR_5A: IC14.28 (GPA7); also elsewhere on the board
CURR_50MA: IC14.27 (GPA6); also elsewhere on the board
CV_ACTIVE: IC14.23 (GPA2); also elsewhere on the board
GND: C64.1, C65.2, C66.2, C67.2, C68.-, C69.2, C70.2, C71.1, C72.1, C73.2, C74.1, C75.1, C76.2, C77.1, C78.1, C79.1, C80.1, C81.1, C82.1, IC13.4 (VSS), IC14.10 (VSS), IC14.15 (A0), IC14.16 (A1), IC14.17 (A2), IC15.4 (GND), IC16.2 (GND), IC17.8 (GND), IC18.2 (GND), IC19.3 (CLK), IC19.4 (DGND), IC19.5 (AVSS), IC19.8 (REFN0), R73.2, R79.1, X3.2, ZD3.1 (A), ZD3.2 (A); also elsewhere on the board
IRQ: IC14.20 (INTA); also elsewhere on the board
I_MON: R81.1; also elsewhere on the board
I_SET: IC17.4 (VOUTA), R77.1; also elsewhere on the board
MISO: IC14.14 (SO), IC16.4 (SI/O), IC19.15 (DOUT/!DRDY); also elsewhere on the board
MOSI: IC14.13 (SI), IC17.7 (DIN), IC19.16 (DIN); also elsewhere on the board
unnamed: LED1.CC (C), R73.1
unnamed: R75.2, R76.1
unnamed: R76.2, X3.1
unnamed: Q14.3 (D), R74.2
unnamed: D15.A, D16.A, IC13.6 (!CLR), R71.2
unnamed: C80.2, C81.2, IC19.12 (AVDD), R82.2
unnamed: C70.1, IC15.5 (TRIM/NR)
unnamed: C74.2, IC19.10 (AIN1), R77.2
unnamed: C77.2, IC19.11 (AIN0/REFP1), R80.2
unnamed: C75.2, IC19.7 (AIN2), R78.2
unnamed: C76.1, IC19.6 (AIN3/REFN1), R81.2
unnamed: LED2.BC (C), R79.2
OE: IC14.2 (GPB1), OE.1
OE_GREEN: IC14.7 (GPB6), LED1.GREEN (AG)
OE_RED: IC14.8 (GPB7), LED1.RED (AR)
OE_TRIG: IC13.1 (CLK); also elsewhere on the board
OVP_EN: IC14.5 (GPB4); also elsewhere on the board
POST_OE: IC13.5 (Q); also elsewhere on the board
PRE_OE: IC13.2 (D), OE.2; also elsewhere on the board
PWRGOOD: D15.C, IC14.24 (GPA3); also elsewhere on the board
RSENSE: IC14.3 (GPB2); also elsewhere on the board
SCLK: IC14.12 (SCK), IC16.3 (SCLK), IC17.6 (SCLK), IC19.1 (SCLK); also elsewhere on the board
SENSE_ERR: IC14.21 (GPA0); also elsewhere on the board
TEMP_CS: IC16.1 (!CS); also elsewhere on the board
U_MON: R80.1; also elsewhere on the board
U_SET: IC17.3 (VOUTB), IC18.3 (NC), R78.1
U_SET_OUT: IC18.4 (COM); also elsewhere on the board
V+: C66.1, C69.1, C71.2, C73.1, IC15.2 (VIN), IC17.1 (VDD), IC18.5 (VDD), R82.1; also elsewhere on the board

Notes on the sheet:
Digital control (SPI)
Voltage reference
Licensed under the TAPR Open Hardware License (www.tapr.org/OHL)
Repository: https://github.com/eez-open
More info at http://www.envox.hr/eez
SPI I/O expander, temp sensor, DAC, ADC, Voltage reference, Remote programming
Voltage programming selection (DAC / Ext.)
Down-programmer


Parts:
C83, C85, C87: 100n; C0603
C84, C86: 4n7; C0805
D17, D18: BAS316; SOD323-R
IC20: LM293D; SOIC127P600X173-8N
IC21: MAX9141ESA; SOIC127P600X173-8N
JP3: JP2-NOCUT-0805; JP2-0805-NOCUT
LED3: WP934MD/LYLID; WP934MD
Q15: BT139B-600E; D2PAK
Q16, Q18, Q21: 2N7002; SOT103P240X110-3N
Q17: FMMT493TA; SOT23-BEC
Q19: PSMN013-60YL; SOT669
Q20: MMBT5551; SOT23-BEC
R83, R85, R92, R93, R95, R99: 10K; R0805
R84, R86, R96, R100, R102: 4K7; R0805
R87, R88, R91: 330R; R0805
R89, R90, R94, R101: 1K; R0805
R97: 100K; R0805
R98: 6R2; R0805
R103, R104: 22K; R0805
ZD4: MMSZ5230BT1G; SOD123

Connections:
!OVP_FAULT: C86.2, Q21.3 (D), R102.2; also elsewhere on the board
+5V: C86.1, LED3.BA (A), LED3.TA (A), R84.2, R96.2, R102.1; also elsewhere on the board
CC_ACTIVE: Q18.1 (G), R96.1, R100.2; also elsewhere on the board
CC_LED: LED3.BC (C), R91.2
CV_ACTIVE: Q16.1 (G), R84.1, R86.2; also elsewhere on the board
CV_LED: LED3.TC (C), R87.1
D_CC: Q18.3 (D), R91.1
D_CV: Q16.3 (D), R87.2
GND: C83.1, C85.1, C87.1, D18.C, IC21.4 (GND), Q16.2 (S), Q18.2 (S), Q20.E, Q21.2 (S), R83.1, R92.2, R97.1, R98.1, R104.1; also elsewhere on the board
I_SERVO: R99.1; also elsewhere on the board
LOOP_CTRL: R93.2; also elsewhere on the board
unnamed: IC21.6 (!SHDN), JP3.2
unnamed: IC21.7 (OUT), Q21.1 (G), R94.2, R101.2
unnamed: Q15.3 (G), Q17.C, R89.1, R90.1
unnamed: Q17.E, R98.2
unnamed: D17.C, D18.A
unnamed: D17.A, Q17.B, R94.1, R97.2
unnamed: R103.2, ZD4.A
unnamed: Q20.B, R103.1, R104.2
unnamed: Q19.4 (G), Q20.C, R101.1
unnamed: IC20.1 (OUT), R86.1
unnamed: IC20.7 (OUT), R100.1
unnamed: IC20.2 (-IN), R85.2
unnamed: IC20.6 (-IN), R99.2
unnamed: IC20.3 (+IN), IC20.5 (+IN), R93.1
OVP_EN: JP3.1, R83.2; also elsewhere on the board
OVP_IN+: C84.1, IC21.2 (+IN), R88.2, R92.1
OVP_IN-: C84.2, IC21.3 (-IN), R95.2
POST_OUT-: Q15.2 (A2), Q19.1 (S), Q19.2 (S), Q19.3 (S); also elsewhere on the board
POST_OUTF+: Q15.1 (A1), Q19.MB (D), R89.2, R90.2, ZD4.C; also elsewhere on the board
U_MON: R88.1; also elsewhere on the board
U_SERVO: R85.1; also elsewhere on the board
U_SET_OUT: R95.1; also elsewhere on the board
V+: C83.2, C85.2, IC20.8 (V+), IC21.1 (+VCC), IC21.5 (!LE); also elsewhere on the board
V-: C87.2, IC20.4 (V-); also elsewhere on the board

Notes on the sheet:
Licensed under the TAPR Open Hardware License (www.tapr.org/OHL)
Repository: https://github.com/eez-open
More info at http://www.envox.hr/eez
CC/CV mode detection and indication, HW OVP
Constant Voltage (CV) and Constant Current (CC) mode detection and indication
Over-voltage protection (OVP)


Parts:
C88, C93: 10n; C0805
C89: 470n; C0805
C90: HHXC630A330MHA0; CAPAE830X1050N
C91, C92: 10n/200V; C1206
D19: BAS316; SOD323-R
F1, F2: ZH32
J2: FCR7350R; S16N-PC
J3: FCR7350B; S16N-PC
K1: FTR-C1GA005G-B05; FTR-C1
LED2: WP934MD/2LID; WP934MD
Q22: MMBT5401; SOT23-BEC
Q23, Q24: MMBT5551; SOT23-BEC
Q25: 2N7002; SOT103P240X110-3N
R105, R113: 330R; R0805
R106, R111: 750R; R0805
R107: 3K3; R0805
R108, R109: 10K; R0805
R110: 1R; R1206
R112: 47K; R0805
R114: 470R; R0805
R115: 100K; R0805
X3: 691322110005; MC1,5/5-G-3,5
X4: DS1024-2*10R0; SSW-110-02-T-D-RA
ZD5: SMAJ51A; DO214AA

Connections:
+5V: D19.C, K1.1 (C1), LED2.TA (A), R108.2; also elsewhere on the board
GND: Q23.E, Q25.2 (S), R112.1, R115.1; also elsewhere on the board
unnamed: C88.2, Q22.B, R105.1, R106.2, R107.2
unnamed: Q22.C, R109.2
unnamed: Q24.C, R107.1
unnamed: C93.1, Q24.B, R111.1, R113.2
unnamed: Q23.B, R109.1, R112.2
unnamed: C89.2, R110.2
unnamed: D19.A, K1.12 (C2), Q25.3 (D), R114.1
unnamed: K1.5 (NO), X3.4
unnamed: K1.8 (NO), X3.5
unnamed: LED2.TC (C), R114.2
OUTC+: C91.1, J2.1, X4.1, X4.2, X4.3, X4.4, X4.5
OUTC-: C92.2, J3.1, X4.16, X4.17, X4.18, X4.19, X4.20
OUTF+: F2.2, X4.6, X4.7, X4.8, X4.9, X4.10
PE: C91.2, C92.1, X3.3; also elsewhere on the board
POST_OUT+: F1.1, K1.3 (NC); also elsewhere on the board
POST_OUT-: C90.-, C93.2, K1.10 (NC), Q24.E, R110.1, R113.1, X4.11, X4.12, X4.13, X4.14, X4.15, ZD5.A; also elsewhere on the board
POST_OUTF+: C88.1, C89.1, C90.+, F1.2, F2.1, Q22.E, R105.2, ZD5.C; also elsewhere on the board
RSENSE: Q25.1 (G), R115.2; also elsewhere on the board
SENSE+: K1.4 (COM), R106.1; also elsewhere on the board
SENSE-: K1.9 (COM), R111.2; also elsewhere on the board
SENSE_ERR: Q23.C, R108.1; also elsewhere on the board

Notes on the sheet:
Rsense polarity protection Output coupling, Rsense relay
Licensed under the TAPR Open Hardware License (www.tapr.org/OHL)
Repository: https://github.com/eez-open
More info at http://www.envox.hr/eez
Remote sense reverse polarity detection
Remote sense selection
Output coupling connector (via Backplane PCB)
Power output section

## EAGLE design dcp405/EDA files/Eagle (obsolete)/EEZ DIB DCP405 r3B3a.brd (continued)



Board: 4 copper layers, 180.0 x 95.0 mm, 322 parts (2 on the bottom side), 199 nets.

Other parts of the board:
EEZ_SIGNATURE: SIGNATURESMALL; SIGNATURE_5MM
U$1: RECYCLE_BIN1/8
U$2: CE_5MM
U$6: ESD_SYMBOL
U$7: PB_SMALL

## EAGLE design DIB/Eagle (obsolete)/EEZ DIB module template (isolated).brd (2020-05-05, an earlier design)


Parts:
C1, C2, C3, C4, C5: 100n; C0603
FM1, FM2: FIDUCIAL_2; FIDUCIAL_DUAL
IC1: Si8662AB-B-IS1; SOIC-16
IC2: Si8641AB-B-IS1; SOIC-16
IC3: M24C32-WMN6P; SOIC127P600X173-8N
J1: 4907; PCB_TAB-4907
KK1, KK2: PMB-1; PCB-MB
R1, R2, R3, R4: 10K; R0805
X1: 77317-104-28LF
X2: 39-30-1020; MINIFIT_39301020
X3: ZL263-20DG; SSW-110-02-T-D-RA

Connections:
!RESET: IC1.15 (B1)
+3V3: C2.2, C4.2, IC1.16 (VDD2), IC2.10 (EN2), IC2.16 (VDD2), R1.2
+VAUX: X1.2
BOOT0: IC2.13 (B2)
DIB_A0: IC3.1 (A0), R4.2, X1.17
DIB_A1: IC3.2 (A1), R3.2, X1.19
DIB_A2: IC3.3 (A2), R2.2, X1.18
DIB_BOOT0: IC2.4 (A2), IC2.7 (EN1), X1.26
DIB_CSA: IC1.5 (A4), X1.9
DIB_CSB: X1.12
DIB_IRQ: IC1.7 (A6), X1.10
DIB_MISO: IC1.6 (A5), X1.14
DIB_MOSI: IC2.3 (A1), X1.15
DIB_NFAULT: X1.3
DIB_NRESET: IC1.2 (A1), X1.4
DIB_SCL: IC3.6 (SCL), X1.5
DIB_SCLK: IC1.4 (A3), X1.13
DIB_SDA: IC3.5 (SDA), X1.8
DIB_SYNC: IC1.3 (A2), X1.6
DIB_UART_RX: IC2.6 (A4), X1.27
DIB_UART_TX: IC2.5 (A3), X1.28
GND: C2.1, C4.1, IC1.9 (GND2), IC2.9 (GND2_2), IC2.15 (GND2)
GNDIO: C1.2, C3.2, C5.1, IC1.8 (GND1), IC2.2 (GND1_2), IC2.8 (GND1), IC3.4 (GND), IC3.7 (WP), X1.7, X1.11, X1.16, X1.20, X1.25
IRQ: IC1.10 (B6)
MISO: IC1.11 (B5)
MOSI: IC2.14 (B1)
NSS: IC1.12 (B4)
OE_SYNC: IC1.14 (B2)
PE: J1.1, J1.2
SCLK: IC1.13 (B3)
UART_RX: IC2.12 (B3)
UART_TX: IC2.11 (B4), R1.1
V+: C1.1, C3.1, C5.2, IC1.1 (VDD1), IC2.1 (VDD1), IC3.8 (VCC), R2.1, R3.1, R4.1, X1.1

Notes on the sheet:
Licensed under the TAPR Open Hardware License (www.tapr.org/OHL)
Repository: https://github.com/eez-open
More info at http://www.envox.hr/eez
I2C Module ID EEPROM
Bias power supply, I2C EEPROM, digital isolators
Plastic parts
Bus isolator
DIB v1.0 connector
DC power input
Optional power sourcing module connector


Board: 4 copper layers, 160.0 x 95.0 mm, 20 parts (0 on the bottom side), 21 nets.

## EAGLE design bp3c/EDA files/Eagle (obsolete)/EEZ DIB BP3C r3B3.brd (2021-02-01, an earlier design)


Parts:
C1: 100n; C0603
D1, D2, D5, D6: BAS316; SOD323-R
D3, D4: N.C.; SOD323-R
FM1, FM2, FM3: FIDUCIAL
IC1: TCA9534PWR; PW(R-PDSO-G16)
JP1: JP3-CUT
K1, K2, K3, K4: RT424005; RT-C/016A5_ROUND
LABEL1: HR000002; CERT-SMALL-SILK
LED1, LED2, LED3, LED4: N.C.; LED_0805
Q1, Q2, Q3, Q4: 2N7002; SOT103P240X110-3N; MPN 2N7002-7-F
R1, R3, R5, R7: N.C.; R0805
R2, R4, R6, R8: 100K; R0805
X1, X2, X3: ZL202-20G; DS1021-2*10SF11
ZD1: MM3Z18VT1G; SOD323-R

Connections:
+3V3: C1.1, IC1.16 (VCC), JP1.NO; also elsewhere on the board
+5V: K1.A2 (C1), K2.A2 (C1), K3.A2 (C1), K4.A2 (C1), LED1.A, LED2.A, LED3.A, LED4.A, ZD1.A; also elsewhere on the board
BOOT1: IC1.9 (P4); also elsewhere on the board
BOOT2: IC1.10 (P5); also elsewhere on the board
BOOT3: IC1.11 (P6); also elsewhere on the board
CH1_IN+: K4.11A, X1.6, X1.7, X1.8, X1.9, X1.10
CH1_OUT+: K3.14A (O), K4.12A (S), K4.14B (O), X1.1, X1.2, X1.3, X1.4, X1.5
CH1_OUT-: K1.14A (O), K2.14A (O), K3.14B (O), X1.11, X1.12, X1.13, X1.14, X1.15, X1.16, X1.17, X1.18, X1.19, X1.20
CH2_IN+: K4.11B, X2.6, X2.7, X2.8, X2.9, X2.10
CH2_IN-: K3.11B, K4.14A (O), X2.11, X2.12, X2.13, X2.14, X2.15
CH2_OUT+: K2.11A, K3.12A (S), X2.1, X2.2, X2.3, X2.4, X2.5
CH2_OUT-: K1.11A, K1.11B, K3.12B (S), X2.16, X2.17, X2.18, X2.19, X2.20
CH3+: X3.1, X3.2, X3.3, X3.4, X3.5, X3.6, X3.7, X3.8, X3.9, X3.10
CH3-: K1.14B (O), X3.11, X3.12, X3.13, X3.14, X3.15, X3.16, X3.17, X3.18, X3.19, X3.20
GND: C1.2, IC1.2 (A1), IC1.3 (A2), IC1.8 (GND), JP1.NC, Q1.2 (S), Q2.2 (S), Q3.2 (S), Q4.2 (S), R2.1, R4.1, R6.1, R8.1; also elsewhere on the board
I2C1_SCL: IC1.14 (SCL); also elsewhere on the board
I2C1_SDA: IC1.15 (SDA); also elsewhere on the board
unnamed: LED3.C, R5.1
unnamed: LED2.C, R3.1
unnamed: IC1.1 (A0), JP1.COM
unnamed: D1.C, D2.C, D5.C, D6.C, ZD1.C
unnamed: D1.A, K1.A1 (C2), Q1.3 (D), R1.2
unnamed: LED1.C, R1.1
unnamed: D6.A, K2.A1 (C2), Q4.3 (D), R7.2
unnamed: LED4.C, R7.1
unnamed: D5.A, K4.A1 (C2), Q3.3 (D), R5.2
unnamed: D2.A, K3.A1 (C2), Q2.3 (D), R3.2
OUT_CGND: D3.C, IC1.4 (P0), Q1.1 (G), R2.2
OUT_PAR: D4.A, IC1.5 (P1), Q2.1 (G), R4.2
OUT_SER: D3.A, D4.C, IC1.6 (P2), Q3.1 (G), R6.2
OUT_SRA: IC1.7 (P3), Q4.1 (G), R8.2
PROG_RST: IC1.12 (P7); also elsewhere on the board
SER_PAR: K3.11A, K4.12B (S)

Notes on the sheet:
Licensed under the TAPR Open Hardware License (www.tapr.org/OHL)
Repository: https://github.com/eez-open
More info at http://www.envox.hr/eez
Power output coupling, bootloader selection
Power module inputs
Power module outputs


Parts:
C2: 1n; C0805
D7, D8: BAS316; SOD323-R
D9: N.C.; DO214AA
JP2, JP6, JP9, JP10: JP2-CUT
JP3, JP4, JP5, JP7, JP8: JP2-NOCUT
LED5, LED6: N.C.; LED_0805
R9: 10K; R0805
R10, R11: N.C.; R0805
X4: DS1022-2*20RF11; ZL212-40KG
X5, X6, X7: DS1023-2*14S21; TSW-114-07-F-D

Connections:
!FAULT: X4.8, X5.3, X6.3, X7.3
!MRESET: D8.C, X4.6
!RESET: C2.1, D7.A, D8.A, R9.2, X5.4, X6.4, X7.4
+3V3: C2.2, R9.1, X4.7, X5.1, X6.1, X7.1; also elsewhere on the board
+5V: R10.1, X4.35, X4.36, X5.23, X5.24, X6.23, X6.24, X7.23, X7.24; also elsewhere on the board
+12V: D9.C, R11.1, X4.37, X4.38, X5.21, X5.22, X6.21, X6.22, X7.21, X7.22
+VAUX: X4.5, X5.2, X6.2, X7.2
BOOT1: X5.26; also elsewhere on the board
BOOT2: X6.26; also elsewhere on the board
BOOT3: X7.26; also elsewhere on the board
GND: D9.A, JP2.1, JP3.2, JP4.1, JP5.2, JP6.1, JP7.2, JP8.1, JP9.1, JP10.1, LED5.C, LED6.C, X4.1, X4.2, X4.15, X4.16, X4.29, X4.39, X4.40, X5.7, X5.11, X5.16, X5.25, X6.7, X6.11, X6.16, X6.25, X7.7, X7.11, X7.16, X7.25; also elsewhere on the board
I2C1_SCL: X4.12, X5.5, X6.5, X7.5; also elsewhere on the board
I2C1_SDA: X4.14, X5.8, X6.8, X7.8; also elsewhere on the board
unnamed: JP3.1, X5.18
unnamed: LED5.A, R10.2
unnamed: LED6.A, R11.2
unnamed: JP2.2, X5.17
unnamed: JP8.2, X5.19
unnamed: JP5.1, X6.18
unnamed: JP4.2, X6.17
unnamed: JP9.2, X6.19
unnamed: JP7.1, X7.18
unnamed: JP6.2, X7.17
unnamed: JP10.2, X7.19
OE_SYNC: X4.10, X5.6, X6.6, X7.6
PROG_RST: D7.C; also elsewhere on the board
SPI2_CLK: X4.32, X5.13
SPI2_CSA: X4.28, X5.9
SPI2_CSB: X4.27, X5.12
SPI2_IRQ: X4.25, X5.10
SPI2_MISO: X4.31, X5.14
SPI2_MOSI: X4.33, X5.15
SPI4_CLK: X4.23, X6.13
SPI4_CSA: X4.22, X6.9
SPI4_CSB: X4.21, X6.12
SPI4_CSC: X4.30
SPI4_IRQ: X4.19, X6.10
SPI4_MISO: X4.24, X6.14
SPI4_MOSI: X4.26, X6.15
SPI5_CLK: X4.17, X7.13
SPI5_CSA: X4.11, X7.9
SPI5_CSB: X4.13, X7.12
SPI5_CSC: X4.34
SPI5_IRQ: X4.9, X7.10
SPI5_MISO: X4.18, X7.14
SPI5_MOSI: X4.20, X7.15
UART_RX: X4.3, X5.27, X6.27, X7.27
UART_TX: X4.4, X5.28, X6.28, X7.28

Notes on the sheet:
Licensed under the TAPR Open Hardware License (www.tapr.org/OHL)
Repository: https://github.com/eez-open
More info at http://www.envox.hr/eez
Backplane
Output connector (3 x SPI modules)
Power indicators (optional)
Peripheral modules RESET


Board: 2 copper layers, 110.0 x 90.0 mm, 63 parts (0 on the bottom side), 70 nets.

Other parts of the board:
EEZ_SIGNATURE: SIGNATURESMALL; SIGNATURE_5MM
U$2: RECYCLE_BIN1/8
U$4: ESD_SYMBOL
U$5: PB_SMALL

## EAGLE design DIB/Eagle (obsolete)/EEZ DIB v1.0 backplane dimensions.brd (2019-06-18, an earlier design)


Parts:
X1, X2, X3: ZL202-20G; DS1021-2*10SF11
X4: ZL212-40KG
X5, X6, X7: TSW-114-07-F-D

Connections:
CH1_IN+: X1.6, X1.7, X1.8, X1.9, X1.10
CH1_OUT+: X1.1, X1.2, X1.3, X1.4, X1.5
CH2_OUT+: X2.1, X2.2, X2.3, X2.4, X2.5
CH3+: X3.1, X3.2, X3.3, X3.4, X3.5
CH3-: X3.16, X3.17, X3.18, X3.19, X3.20
unnamed: X2.16, X2.17, X2.18, X2.19, X2.20
unnamed: X3.6, X3.7, X3.8, X3.9, X3.10
unnamed: X3.11, X3.12, X3.13, X3.14, X3.15
unnamed: X1.16, X1.17, X1.18, X1.19, X1.20
unnamed: X1.11, X1.12, X1.13, X1.14, X1.15
unnamed: X2.11, X2.12, X2.13, X2.14, X2.15
unnamed: X2.6, X2.7, X2.8, X2.9, X2.10

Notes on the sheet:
Licensed under the TAPR Open Hardware License (www.tapr.org/OHL)
Repository: https://github.com/eez-open
More info at http://www.envox.hr/eez
Power sourcing module connector

Board: 2 copper layers, 7 parts (0 on the bottom side), 12 nets, no tracks yet.

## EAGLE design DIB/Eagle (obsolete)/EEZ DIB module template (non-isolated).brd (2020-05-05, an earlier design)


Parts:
C1, C5: 100n; C0603
C2: 2u2; C0805
C3: 4u7; C0805
C4: 10n; C0805
FM1, FM2: FIDUCIAL_2; FIDUCIAL_DUAL
IC1: 74HC1G126GW,125; SOT65P210X110-5N
IC2: LP2985-33DBVR; SOT95P270X145-5N
IC3: M24C32-WMN6P; SOIC127P600X173-8N
J1: 4907; PCB_TAB-4907
KK1, KK2: PMB-1; PCB-MB
RN1: DR1206-10K-4/8; CAY16
X1: 77317-104-28LF
X2: 39-30-1020; MINIFIT_39301020
X3: ZL263-20DG; SSW-110-02-T-D-RA

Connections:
+3V3: C1.1, C2.1, C5.2, IC1.5 (V+), IC2.5 (OUT), IC3.8 (VCC), RN1.8 (2)
+5V: C3.2, IC2.1 (IN), IC2.3 (ON/!OFF), X1.23, X1.24
+VAUX: X1.2
DIB_A0: IC3.1 (A0), RN1.4 (1), X1.17
DIB_A1: IC3.2 (A1), RN1.3 (1), X1.19
DIB_A2: IC3.3 (A2), RN1.2 (1), X1.18
DIB_BOOT0: IC1.1 (EN), X1.26
DIB_CSA: X1.9
DIB_CSB: X1.12
DIB_IRQ: X1.10
DIB_MISO: X1.14
DIB_MOSI: X1.15
DIB_NFAULT: X1.3
DIB_NRESET: X1.4
DIB_SCL: IC3.6 (SCL), X1.5
DIB_SCLK: X1.13
DIB_SDA: IC3.5 (SDA), X1.8
DIB_SYNC: X1.6
DIB_UART_RX: IC1.4 (O), X1.27
DIB_UART_TX: X1.28
GND: C1.2, C2.2, C3.1, C4.1, C5.1, IC1.3 (V-), IC2.2 (GND), IC3.4 (GND), IC3.7 (WP), X1.7, X1.11, X1.16, X1.20, X1.25
unnamed: C4.2, IC2.4 (BYPASS)
PE: J1.1, J1.2
UART_TX: IC1.2 (I), RN1.1
V+: RN1.5 (2), RN1.6 (2), RN1.7 (2)

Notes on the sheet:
Licensed under the TAPR Open Hardware License (www.tapr.org/OHL)
Repository: https://github.com/eez-open
More info at http://www.envox.hr/eez
I2C Module ID EEPROM
Bias power supply, I2C EEPROM, digital isolators
Plastic parts
DIB v1.0 connector
DC power input
Optional power sourcing module connector
+3V3 LDO


Board: 4 copper layers, 160.0 x 95.0 mm, 17 parts (0 on the bottom side), 14 nets.

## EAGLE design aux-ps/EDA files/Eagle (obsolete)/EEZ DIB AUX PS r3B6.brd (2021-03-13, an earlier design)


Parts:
C1, C6: 2n2/Y2; C075-042X103
C2, C3, C4: 100n/X2; C150-054X183
C5: 47n/400V (X2); C102-054X133
C7, C10: 1u; C0805
C8, C9: EEEFK1V470P; CAPAE660X610N
D1, D4: N.C.; DO214AA
D2, D3: BAS316; SOD323-R
FM1, FM2, FM3: FIDUCIAL
J1: PF0030/PC
J2, J3: 1-726388-2; PCB_TAB-4.8MM
J4: SWEB 8094 AU/GN; S16N-PC
K1, K2: RT424005; RT-C/016A5_ROUND
L1: 2200HT-221-V-RC; BOURNS_2200
L2: RN222-4-02-3M3; BOURNS_7100_COMBO
L3, L4: VLS6045AF-3R3N; COILCRAFT_HPI0630
LABEL1: HR000002; CERT-SMALL-SILK
NTC1: B57236S0200M; NTC_11.5X6_RM5
Q1, Q2: MMBT5551; SOT23-BEC
R1, R2: 470K; R1206
R3, R4: 1K; R0805
SAR1: 2051-47-SM-RPLF; SAR_4.5MM
SW1: DF62J12S2AHQA; DF62J12S2
TP1, TP2, TP3: PCB_TEST_TABSHIELD; PCB_SHIELD_TAB
TR1: IRM-10-5 (optional IRM-20-5); IRM-10/20_COMBO
TR2: IRM-10-12; IRM-10
VAR1, VAR2, VAR3: ERZE14A431; VARISTOR_16MM
X1: 39-28-1063; MINIFIT_5566-06A_CRE
X2: 39-30-1039; MINIFIT_39301039_CRE
X3: DS1013-16SSIB1; IDC-16PIN
ZD1: MM3Z18VT1G; SOD323-R

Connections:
+5V: C8.1 (+), K1.A2 (C1), K2.A1 (C2), L3.2, TP1.1, X3.5, X3.6, ZD1.A; also elsewhere on the board
+12V: C9.1 (+), L4.2, TP2.1, X3.3, X3.4; also elsewhere on the board
AC_L_IN: C3.1, J1.L, L1.1, R1.2, VAR1.2, VAR2.1
AC_L_OUT: C5.2, K2.11A, K2.11B, NTC1.1, SW1.2A (S1), TR1.AC1 (AC/N), TR2.ACL (AC/L); also elsewhere on the board
AC_L_RTC: C1.1, C4.2, L2.2, L2.2A (2), L2.2B (2), SW1.2 (P1)
AC_L_SS: K1.14A (O), K1.14B (O), K2.14A (O), K2.14B (O), X1.1, X1.4, X2.1
AC_N_IN: C2.2, C3.2, J1.N, L2.3 (1), L2.3A (1), L2.3B (1), R2.1, VAR2.2, VAR3.1
AC_N_OUT: C5.1, SW1.1A (S), TR1.AC2.1 (AC/L), TR1.AC2.2 (AC/L), TR2.ACN (AC/N), X1.2, X1.5, X2.2; also elsewhere on the board
AC_N_RTC: C4.1, C6.2, L2.4 (2), L2.4A (2), L2.4B (2), SW1.1
GND: C7.2, C8.2 (-), C9.2 (-), C10.2, D1.A, D4.A, Q1.E, Q2.E, TP3.1, TR1.V- (-), TR1.V-1 (-), TR2.V- (-), X3.7, X3.8, X3.9; also elsewhere on the board
unnamed: R1.1, R2.2
unnamed: C2.1, L1.2, L2.1, L2.1A (1), L2.1B (1)
unnamed: SAR1.1, VAR1.1, VAR3.2
unnamed: K1.11A, K1.11B, NTC1.2
unnamed: C10.1, D4.C, L4.1, TR2.V+ (+)
unnamed: D2.C, D3.C, ZD1.C
unnamed: Q2.B, R4.1
unnamed: C7.1, D1.C, L3.1, TR1.V+ (+), TR1.V+1 (+)
unnamed: D2.A, K1.A1 (C2), Q2.C
unnamed: Q1.B, R3.1
PE: C1.2, C6.1, J1.PE, J2.1, J2.2, J3.1, J3.2, J4.1, J4.NC1, J4.NC2, J4.NC3, J4.NC4, SAR1.2, SW1.PE1 (PE), SW1.PE2 (PE), X1.3, X1.6, X2.3, X3.1
PWR_DIRECT: R3.2, X3.12
PWR_DIR_OUT: D3.A, K2.A2 (C1), Q1.C; also elsewhere on the board
PWR_SSTART: R4.2, X3.11

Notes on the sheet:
Licensed under the TAPR Open Hardware License (www.tapr.org/OHL)
Repository: https://github.com/eez-open
More info at http://www.envox.hr/eez
AC input protection, soft-start/standby, Mean Well +5 V and +12 V AC/DC modules
Bias power supply


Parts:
C11, C15, C16: 1u; C0805
C12, C13: N.C.; C0805
C14: EEEFK1V470P; CAPAE660X610N
C17, C18: 100n; C0603
C19: N.C.; C0603
C20: N.C.; C102-054X133
D5: SKL14; SOD123
D6: N.C.; SOD323-R
IC1: BD00FC0WFP-E2; TO-252-5
IC2: MAX31760AEE+; DBQ16
JP1, JP3, JP4: JP3-CUT-0805-ROTATED; JP3-0805-CUT2
JP2: JP2-NOCUT-0805; JP2-0805-NOCUT
LED1: WP934CB/YD
OK1: N.C.; SO4
Q3: 2N7002; SOT103P240X110-3N; MPN 2N7002-7-F
R5, R7: 39K; R0805
R6: 470R; R0805
R8, R9: 3K3; R0805
R10, R11, R14: 1K; R0805
R12, R15: 4K7; R0805
R13: 10R; R0805
R16, R17, R18, R19: N.C.; R0805
X3: DS1013-16SSIB1; IDC-16PIN
X4: 47053-1000
X5: N.C.; 47053-1000
ZD2, ZD3: N.C.; SOD123
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

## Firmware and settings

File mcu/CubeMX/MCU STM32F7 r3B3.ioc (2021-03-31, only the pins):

PD12.GPIO_Label=LCD_BRIGHTNESS
PG8.Signal=FMC_SDCLK
PG0.Signal=FMC_A10
PF7.Signal=SPI5_SCK
PB6.Signal=I2C1_SCL
PC7.Signal=GPXTI7
PD0.Signal=FMC_D2_DA2
PD8.Signal=FMC_D13_DA13
PE1.Signal=FMC_NBL1
PI4.GPIO_Label=ENC_SW
PE9.Signal=FMC_D6_DA6
PE4.GPIO_Label=SPI4_NSS
PA8.Signal=GPXTI8
PB9.Signal=GPXTI9
PB1.Signal=LTDC_R6
PD12.Signal=S_TIM4_CH1
PA10.Signal=GPIO_Input
PD15.Signal=FMC_D1_DA1
PG12.Signal=LTDC_B4
PG5.Signal=FMC_A15_BA1
PC13.Signal=GPIO_Input
PD3.Signal=LTDC_G7
PC2.Signal=ETH_TXD2
PD10.Signal=FMC_D15_DA15
PI8.GPIO_Label=WDG
PA8.GPIO_Label=SPI2_IRQ
PB14.Signal=SPI2_MISO
PA5.Signal=LTDC_R4
PI7.Signal=LTDC_B7
PE14.Signal=FMC_D11_DA11
PB4.GPIO_Label=SPI2_NSS
PF13.Signal=FMC_A7
PC7.GPIO_Label=ENC_B
PH6.Signal=ETH_RXD2
PE3.Signal=GPIO_Output
PC15/OSC32_OUT.Signal=RCC_OSC32_OUT
PF4.Signal=FMC_A4
PD2.Signal=SDMMC1_CMD
PB15.Signal=RTC_REFIN
PG11.Signal=LTDC_B3
PG15.Signal=FMC_SDNCAS
PD13.Signal=GPIO_Output
PA15.GPIO_Label=SPI5_IRQ
PF11.Signal=FMC_SDNRAS
PC11.GPIO_Label=UART_RX/DIN1
PB7.Signal=I2C1_SDA
PD13.GPIO_Label=OE_SYNC
PA6.Signal=LTDC_G2
PD5.GPIO_Label=USB_OTG_FS_PSO
PA15.Signal=GPXTI15
PF8.Signal=SPI5_MISO
PB5.GPIO_Label=DOUT2
PC5.Signal=ETH_RXD1
PE7.Signal=FMC_D4_DA4
PD6.Signal=GPIO_Output
PB4.Signal=GPIO_Output
PA3.Signal=ETH_COL
PG7.Signal=LTDC_CLK
PC9.GPIO_Label=MCLK_25
PC11.Signal=UART4_RX
PC8.Signal=SDMMC1_D0
PD9.Signal=FMC_D14_DA14
PA13.Signal=SYS_JTMS-SWDIO
PF6.Signal=GPIO_Output
PA1.Signal=ETH_RX_CLK
PI9.Signal=LTDC_VSYNC
PI4.Signal=GPIO_Input
PF1.Signal=FMC_A1
PE0.Signal=FMC_NBL0
PE12.Signal=FMC_D9_DA9
PB2.GPIO_Label=NFAULT
PH3.Signal=FMC_SDNE0
PB12.Signal=ETH_TXD0
PG4.Signal=FMC_A14_BA0
PC12.Signal=SDMMC1_CK
PC6.GPIO_Label=ENC_A
PB13.Signal=ETH_TXD1
PD6.GPIO_Label=PWR_DIRECT
PG13.Signal=GPIO_Output
PF6.GPIO_Label=SPI5_NSS
PH5.Signal=FMC_SDNWE
PD4.Signal=GPIO_Input
PH1/OSC_OUT.Signal=RCC_OSC_OUT
PC3.Signal=ETH_TX_CLK
PE5.Signal=SPI4_MISO
PB2.Signal=GPIO_Input
PI6.Signal=LTDC_B6
PI3.Signal=SPI2_MOSI
PE2.Signal=SPI4_SCK
PF3.Signal=FMC_A3
PE10.Signal=FMC_D7_DA7
PH2.Signal=FMC_SDCKE0
PF14.Signal=FMC_A8
PI11.Signal=LTDC_G6
PG9.Signal=GPIO_Input
PC6.Signal=GPXTI6
PD7.Signal=GPIO_Input
PD1.Signal=FMC_D3_DA3
PC0.Signal=LTDC_R5
PG13.GPIO_Label=SPI5_CSB
PG10.Signal=LTDC_G3
PA9.Signal=USB_OTG_FS_VBUS
PB10.Signal=ETH_RX_ER
PE15.Signal=FMC_D12_DA12
PE8.Signal=FMC_D5_DA5
PI1.Signal=SPI2_SCK
PG14.GPIO_Label=SD_DETECT
PA4.Signal=COMP_DAC1_group
PB5.Signal=S_TIM3_CH2
PD11.Signal=GPIO_Output
PA11.Signal=USB_OTG_FS_DM
PF9.Signal=SPI5_MOSI
PG3.GPIO_Label=PWR_SSTART
PB0.Signal=LTDC_R3
PC1.Signal=ETH_MDC
PG6.Signal=LTDC_R7
Mcu.UserName=STM32F769IGTx
PC10.Signal=UART4_TX
PA0/WKUP.Signal=ETH_CRS
PC13.GPIO_Label=DIN2
PB11.Signal=ETH_TX_EN
PA12.Signal=USB_OTG_FS_DP
PD11.GPIO_Label=SPI2_CSB
PF12.Signal=FMC_A6
PI8.Signal=GPIO_Output
PE13.Signal=FMC_D10_DA10
PI5.Signal=LTDC_B5
PI0.Signal=LTDC_G5
PA10.GPIO_Label=USB_OTG_FS_ID
PE4.Signal=GPIO_Output
PD7.GPIO_Label=IRQ_TOUCH
PC14/OSC32_IN.Signal=RCC_OSC32_IN
PF5.Signal=FMC_A5
PH7.Signal=ETH_RXD3
PF0.Signal=FMC_A0
PB9.GPIO_Label=SPI4_IRQ
PC10.GPIO_Label=UART_TX/DOUT1
PG3.Signal=GPIO_Output
PG1.Signal=FMC_A11
PC4.Signal=ETH_RXD0
PI10.Signal=LTDC_HSYNC
PD5.Signal=GPIO_Output
PH4.Signal=LTDC_G4
PF2.Signal=FMC_A2
PE11.Signal=FMC_D8_DA8
PG9.GPIO_Label=USER_SW
PG14.Signal=GPIO_Input
PH0/OSC_IN.Signal=RCC_OSC_IN
PD4.GPIO_Label=USB_OTG_FS_OC
PF10.Signal=LTDC_DE
PF15.Signal=FMC_A9
PE6.Signal=SPI4_MOSI
PA2.Signal=ETH_MDIO
PD14.Signal=FMC_D0_DA0
PB3.Signal=SYS_JTDO-SWO
PA14.Signal=SYS_JTCK-SWCLK
PB8.Signal=ETH_TXD3
PE3.GPIO_Label=SPI4_CSB
PC9.Signal=RCC_MCO_2
PA7.Signal=ETH_RX_DV

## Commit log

2018-08-29 Fixed Airwire in Eagle
    Fixed some existing Airwires in de Eagle Board
2018-08-29 Fixed Wire Stubs
    Fixed some Wire Stubs in the Eagle Design
    [EEZ DIB MCU r1B1.brd, EEZ DIB MCU r1B1.sch]
2018-08-29 Converted Eagle Project to KiCad
    I importet the Eagle files to KiCad, so everybody can join and work on the pcb design with free open source software.
    [EEZ DIB MCU r1B1.kicad_pcb, EEZ DIB MCU r1B1.sch, Ethernet_PHY.sch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]
2018-08-29 Rename of the sheets
    Fixed the nameing of the sheets from the import into KiCad
2018-09-06 first version of AUX PS board
    [EEZ DIB AUX PS r1B1 BOM.ods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]
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2018-09-07 aux-ps BOM update, PE terminals added
    [EEZ DIB AUX PS r1B1 BOM.ods, EEZ DIB AUX PS r1B1.brd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]
2018-09-08 PCB parts images added
    [EEZ DIB AUX PS r1B1.brd, EEZ DIB AUX PS r1B1.sch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]
2018-09-08 minor changes in BOMs
    [EEZ DIB AUX PS r1B1 BOM.ods, EEZ DIB AUX PS r1B1.brd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]
2018-09-08 changed AC capacitors to X2 class
    [EEZ DIB AUX PS r1B1 BOM.ods]
2018-09-08 Kicad-ised schematic, fixed import errors
    Basic stuff like pin functions not assigned, and moving to heirarchial labels instead of global,
    [EEZ DIB MCU r1B1.sch, Ethernet_PHY.sch, I%2fO_connectors,_encoders,_user_SW.sch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]
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2018-09-09 Updating Kicad Files to r1B2
    Some component Values and connections had changed since r1B1 when kicad file was last converted, brought sch and pcb up to current eagle file.
    [EEZ DIB MCU r1B2.kicad_pcb, EEZ DIB MCU r1B2.sch, Ethernet_PHY.sch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]
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2018-09-09 Left PE Ground trace dangling on USB connector
    Connected PE Trace, and 5V to L1,
    [EEZ DIB MCU r1B2.kicad_pcb]
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2018-09-12 mcu board prototype picture
    [EEZ DIB AUX PS r1B1 BOM.ods]
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2018-09-14 mcu board C3 relocated
    [EEZ DIB MCU r1B2.brd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]
2018-09-15 Updating Kicad Files To Reflect Latest Commits
    [EEZ DIB MCU r1B2.kicad_pcb, Ethernet_PHY.sch, I%2fO_connectors,_encoders,_user_SW.sch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]
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2018-10-06 PS AUX updated values for R30, C23
    [EEZ DIB AUX PS r1B2 BOM.ods, EEZ DIB AUX PS r1B2.brd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]
2018-10-18 MCU fixes: #10, #13, #15, #16, #17, #18
    [EEZ DIB MCU r1B2 BOM.ods, EEZ DIB MCU r1B2.brd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]
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2018-12-30 first commit of DCP505 power board
    [EEZ DIB AUX PS r1B2 BOM.ods, EEZ DIB AUX PS r1B2.brd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]
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2019-01-02 BP3C module addressing fix
    [EEZ DIB BP3C r1B4.brd, EEZ DIB BP3C r1B4.sch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]
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2019-01-03 DCP505: replaced temperature sensor (IC7)
    [EEZ DIB DCP505 r1B2.brd, EEZ DIB DCP505 r1B2.sch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]
2019-01-03 fix PCB inductor dimensions
    [EEZ DIB DCP505 r1B2.brd, EEZ DIB DCP505 r1B2.sch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]
2019-01-03 removed hole on THT MOSFETs packages
    [EEZ DIB DCP505 r1B2.brd, EEZ DIB DCP505 r1B2.sch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]
2019-01-07 parts values and types corrections
    [EEZ DIB DCP505 r1B2.brd, EEZ DIB DCP505 r1B2.sch, EEZ DIB MCU r1B2 BOM.ods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]
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2019-01-23 DCP505 fault indication fix
    [EEZ DIB DCP505 r1B3.brd, EEZ DIB DCP505 r1B3.sch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]
2019-01-24 MCU board minor changes
    [EEZ DIB MCU r1B2 BOM.ods, EEZ DIB MCU r1B2.brd, EEZ DIB MCU r1B2.sch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]
2019-01-24 AUX PS C2 moved away on the PCB from X1
    [EEZ DIB AUX PS r1B2.brd, EEZ DIB AUX PS r1B2.sch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]
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2019-02-02 enclosure fan holes corrected
    [DIB chassis r1B1.dxf]
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2019-02-07 enclosure holes fix for AUX PS
    [DIB chassis r1B1.dxf]
2019-02-07 pullup on fan controller SHDN pin, enclosure silkscreens updated
    [EEZ DIB AUX PS r2B1.brd, EEZ DIB AUX PS r2B1.sch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]
2019-03-09 temp. sensor C9 added
    [EEZ DIB AUX PS r2B1 BOM.ods, EEZ DIB AUX PS r2B1.brd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]
2019-03-15 #33, optional 3V3 LDO
    [EEZ DIB AUX PS r2B1 BOM.ods, EEZ DIB AUX PS r2B2 BOM.ods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]
2019-03-16 X3 changed to vertical
    [EEZ DIB AUX PS r2B2 BOM.ods, EEZ DIB AUX PS r2B2.brd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]
2019-03-27 PE to Gnd caps added
    [EEZ DIB MCU r1B2 BOM.ods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]
2019-04-14 DCP405 module first commit
    [EEZ DIB DCP405 r1B1.brd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]
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2019-05-19 DCP405 BOM update, JP2 added
    [EEZ DIB DCP405 r1B1 BOM.ods, EEZ DIB DCP405 r1B1.brd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]
2019-05-19 DCP405 JP3, JP4 added
    [EEZ DIB DCP405 r1B1.brd, EEZ DIB DCP405 r1B1.sch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]
2019-05-23 MCU, AUX PS BOM update
    [EEZ DIB AUX PS r2B2 BOM.ods, EEZ DIB DCP405 r1B1 BOM.ods, EEZ DIB MCU r1B3 BOM.ods]
2019-05-27 improved routing related to #40
    [EEZ DIB MCU r1B3.GBL, EEZ DIB MCU r1B3.GBS, EEZ DIB MCU r1B3.GTL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]
2019-06-02 BP3C minor fixes
    [EEZ DIB BP3C r2B2 BOM.ods, EEZ DIB BP3C r2B3 BOM.ods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]
2019-06-08 add buydisplay.com TFT into MCU BOM
    [EEZ DIB MCU r1B3 BOM.ods]
2019-06-08 #37, jumper replaced with micro switch
    [EEZ DIB MCU r1B3 BOM.ods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]
2019-06-08 #37, micro switch moved left
    [EEZ BB3 chasis r1B2.brd, EEZ BB3 chasis r1B2.dxf, EEZ DIB DCP405 r1B1 BOM.ods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]
2019-06-14 MCU board chages for #37, #42
    [EEZ DIB MCU r1B3 BOM.ods, EEZ DIB MCU r1B4 BOM.ods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]
2019-06-14 MCU board Vdd trace fixed
    [EEZ DIB MCU r1B4.brd, EEZ DIB MCU r1B4.sch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]
2019-06-15 DIB specification corrections
    [EEZ DIB v1.0 pin mappings DRAFT2.ods]
2019-06-16 #37, place for optional jumper added
    [EEZ DIB MCU r1B4.brd, EEZ DIB MCU r1B4.sch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]
2019-06-18 major reorganization, introduced new PS AUX and BP3C that covers #37, #41
    [EEZ DIB AUX PS r2B2 BOM.ods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]
2019-06-18 enclosure front panel and DCP405 heatsink changes
    [DCP405 heatsink v2.brd, DCP405 heatsink v2.dxf, DCP405_DCP505 heatsink.dxf]
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2019-06-19 enclosure dimensions corrected in readme.md
2019-06-19 BP3C module connectors moved up 0.5mm
    [EEZ DIB BP3C r3B1.brd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]
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2019-06-29 DCM220, C36 value update
    [EEZ DIB DCM220 r1B2 BOM.ods, EEZ DIB DCM220 r1B2.brd, EEZ DIB DCM220 r1B2.sch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]
2019-06-29 #44, #45 Eagle files
    [EEZ DIB MCU r1B5.brd, EEZ DIB MCU r1B5.sch]
2019-07-01 MCU board BOM update
    [EEZ DIB DCM220 r1B2 BOM.ods, EEZ DIB MCU r1B5 BOM.ods, EEZ DIB MCU r1B5.brd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]
2019-07-01 AUX PS BOM update
    [EEZ DIB AUX PS r3B2 BOM.ods]
2019-07-01 BP3C BOM update, optional X8
    [EEZ DIB BP3C r3B1 BOM.ods, EEZ DIB BP3C r3B1.brd, EEZ DIB BP3C r3B1.sch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]
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2019-07-02 MCU optional I/O protection
    [EEZ DIB MCU r1B5 BOM.ods, EEZ DIB MCU r1B5.brd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]
2019-07-04 DCM220 R8 value fixed
    [EEZ DIB DCM220 r1B2 BOM.ods, EEZ DIB DCM220 r1B2.brd, EEZ DIB DCM220 r1B2.sch]
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2019-07-10 BP3C ADXL module CS fixed
    [EEZ DIB BP3C r3B1.brd, EEZ DIB BP3C r3B1.sch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]
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2019-07-13 AUX-PS PCB redesign
    [EEZ DIB AUX PS r3B2 BOM.ods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]
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2019-07-21 DCM220 name on PCB fixed
    [EEZ DIB DCM220 r1B2.brd, EEZ DIB DCM220 r1B2.sch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]
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2019-08-09 Fan LDO control fixed
    [EEZ DIB AUX PS r3B2 BOM.ods, EEZ DIB AUX PS r3B2.brd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]
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2019-08-17 DCM220 front panel corrections
    [EEZ BB3 chassis module panels.dxf, EEZ DIB v1.0 module dimensions.brd]
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2019-08-26 power modules mounting frame moved to top plate
    [EEZ BB3 chassis bottom plate.dxf, EEZ BB3 chassis module panels.dxf, EEZ BB3 chassis top plate.dxf]
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2019-08-30 DCP405 CC comp correction
    [EEZ DIB DCP405 r2B6.brd, EEZ DIB DCP405 r2B6.sch, EEZ DIB DCP405(B) r2B6 BOM.ods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]
2019-08-30 DCP405 reverse sense clean up
    [EEZ DIB DCP405 r2B6.brd, EEZ DIB DCP405 r2B6.sch, EEZ DIB DCP405(B) r2B6 BOM.ods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]
2019-09-03 MCU reset issue, encoder moved
    [EEZ DIB MCU r1B5 BOM.ods, EEZ DIB MCU r1B6 BOM.ods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]
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2019-09-18 BP3C reset fix
    [EEZ DIB BP3C r3B1 BOM.ods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]
2019-09-18 #48, replaced DAC with PWM
    [DCM220 front panel.brd, DCM220 front panel.dxf, DIB chassis DCM220 panel.dxf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]
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2019-09-18 AUX-PS SW2 replaced with tactile switch
    [EEZ DIB AUX PS r3B2 BOM.ods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]
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2019-09-26 DCP405 OVP U_SET fixed
    [EEZ DIB DCP405 r2B7.brd, EEZ DIB DCP405 r2B7.sch]
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2019-10-03 DCM220 IC2 bottom stop mask correction
    [EEZ DIB DCM220 r2B3.brd]
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2019-10-08 DCM220 diff. opamps gain correction
    [EEZ DIB DCM220 r2B4 BOM.ods]
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2019-10-12 Enclosure BOM update (M3x8 countersink for AC inlet)
    [EEZ BB3 r1B1 BOM.ods]
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2019-10-31 DCM220 PCB corrections
    [EEZ DIB DCM220 r2B5.brd]
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2019-11-18 front panel Tx/Rx swap, BOM updates
    [EEZ DIB DCP405(B) r2B7 BOM.ods, EEZ DIB MCU r1B6 BOM.ods]
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2019-12-02 a couple of very minor changes https://github.com/eez-open/modular-psu/pull/58#issuecomment-560120879 and https://github.com/eez-open/modular-psu/pull/55#issuecomment-560120683
2019-12-02 a couple of minor corrections
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2019-12-19 AUX PS PCB improvements, DCM220 ZD2, ZD4 correction
    [EEZ DIB AUX PS r3B2.brd, EEZ DIB DCM220 r2B6 BOM.ods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]
2019-12-20 DCP405 BOM corrections
    [EEZ DIB DCP405 r2B8.brd, EEZ DIB DCP405 r2B8.sch, EEZ DIB DCP405(B) r2B8 BOM.ods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]
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2020-01-05 DCP405 CC compensation correction, split BOMs
    [EEZ DIB DCP405 r2B8 BOM.ods, EEZ DIB DCP405(B) r2B8 BOM.ods, EEZ DIB DCP405B r2B8 BOM.ods]
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2020-01-13 DCP405 CC correction for DP
    [EEZ DIB DCP405 r2B8 BOM.ods, EEZ DIB DCP405 r2B8.brd, EEZ DIB DCP405 r2B8.sch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]
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2020-01-13 DCP405 D17 set to N.C., DIB v1.0 update
    [EEZ DIB DCP405 r2B8 BOM.ods, EEZ DIB v1.0 module dimensions.brd, EEZ DIB v1.0 pin mappings DRAFT2.ods]
2020-01-14 MCU PCB small correction
    [EEZ DIB MCU r2B3.brd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]
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2020-01-16 rear panel Ethernet holes correction
    [EEZ BB3 chassis rear panel.dxf]
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2020-01-21 MCU r2B4, battery holder moved to opposite side
    [EEZ DIB MCU r2B3 BOM.ods, EEZ DIB MCU r2B4 BOM.ods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]
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2020-02-21 Removing dash - fix RS part
    [1-click-bom.csv]
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2020-03-06 MCU BOM R28, R29 correction
    [EEZ DIB MCU r2B4 BOM.ods]
2020-03-11 AUX-PS SW1 value fixed
    [EEZ DIB AUX PS r3B3 BOM.ods]
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2020-03-23 DCP405 swap LED1 and LED2 in BOM
    [1-click-bom.csv, EEZ DIB DCP405 r2B11 BOM.ods]
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2020-04-07 Small BOM fixes, first German user manual commit
    [EEZ DIB BP3C r3B2 BOM.ods, EEZ DIB DCP405 r2B11 BOM.ods, EEZ DIB MCU r2B4 BOM.ods]
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2020-04-23 kit assembly instructions corrections
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2020-05-22 BP3C description fixed
    [EEZ DIB BP3C r3B2.brd, EEZ DIB BP3C r3B2.sch]
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2020-06-02 MCU ZD1 value correction
    [EEZ DIB MCU r2B4 BOM.ods, EEZ DIB MCU r2B4.brd, EEZ DIB MCU r2B4.sch]
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2020-12-25 enclosure bottom plate corrections
    [BB3 chassis bottom plate r2B1.dxf, EEZ BB3 chassis bottom plate.dxf]
2020-12-25 enclosure front panel corrections
    [EEZ BB3 chassis bottom plate r2B1.dxf, EEZ BB3 chassis front panel r2B1.dxf]
2020-12-25 enclosure front panel corrections (2)
    [EEZ BB3 chassis front panel r2B1.dxf]
2020-12-25 enclosure bottom plate corrections (2)
    [EEZ BB3 chassis bottom plate r2B1.dxf]
2020-12-25 enclosure top plate corrections
    [EEZ BB3 chassis top plate r2B1.dxf, EEZ BB3 chassis top plate.dxf]
2020-12-25 enclosure front panel corrections (3)
    [EEZ BB3 chassis front panel r2B1.dxf]
2020-12-25 enclosure display support corrections
    [EEZ BB3 chassis display support r2B1.dxf, EEZ BB3 chassis display support.dxf, EEZ BB3 chassis front panel.dxf]
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2021-02-15 New MCU, #70, #73, #75, #84, #85, #86, #90
    [1-click-bom.csv, EEZ DIB MCU r2B4 BOM.ods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]
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2021-06-27 PGND replaced with GND on few places
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2024-01-03 BP3C and DIB module template migration to KiCad
    [1-click-bom (obsolete).csv, 1-click-bom.csv, 1-click-bom.ods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]
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

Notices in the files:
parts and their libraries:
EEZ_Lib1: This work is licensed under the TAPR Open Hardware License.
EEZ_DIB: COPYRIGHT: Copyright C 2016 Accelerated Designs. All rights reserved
